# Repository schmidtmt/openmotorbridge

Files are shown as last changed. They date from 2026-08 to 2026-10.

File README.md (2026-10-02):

# OpenMotorBridge (v8.0) - Universal Motorcycle Intercom & Telemetry Bridge

<p align="center">
  OpenMotorBridge Logo
  &nbsp;&nbsp;&nbsp;&nbsp;&nbsp;&nbsp;&nbsp;&nbsp;
  OpenMotorMesh Logo
</p>

<p align="center">
  
  
  
  
  
</p>

**OpenMotorBridge (OMB)** is an open-source, cross-vendor communication and telemetry bridge for motorcycles. It seamlessly interconnects proprietary wireless intercom systems (**Sena Mesh 3.0** and **Cardo DMC Gen2**) with an open **2.4 GHz / 868 MHz OpenMotorMesh (OMM)**, high-precision **GNSS Tour Logging (Automotive Dead Reckoning)**, and a **wireless WebBLE PWA cockpit dashboard**.

---

## 📚 Technical Documentation

The comprehensive technical specification is split into 18 logically organized chapters:

1. [**01 - System Architecture & Satellite Topology**](docs/en/01_system_architecture.md)  
   *The 5 standardized functional nodes, de-sensing philosophy, RF diversity, whitepaper engineering decisions, and cockpit integration.*

2. [**02 - Intercom Matrix, Hardware Profiles & Routing**](docs/en/02_intercom_matrix_profiles.md)  
   *The 5 OEM adapter classes A-E, LittleFS profile engine, zero-latency PTT (< 1.8 ms), and audio cross-matrix.*

3. [**03 - Audio DSP, Acoustics & Knowles MEMS Wind Tracking**](docs/en/03_audio_dsp_acoustics.md)  
   *1500V Bourns isolation, ES8388 Codec, Knowles MEMS acoustic wind sampling, and Raised-Cosine Ducking.*

4. [**04 - Mesh Network, LoRa & GNSS Navigation**](docs/en/04_mesh_lora_navigation.md)  
   *OpenMotorMesh (OMM), Dynamic Leader Election (DLE), 868 MHz LoRa fallback, and 10 Hz Multi-GNSS.*

5. [**05 - Power Management, UPS Battery & Power Gate**](docs/en/05_power_management_ups.md)  
   *LM5164-Q1 72V buck, BQ24075 UPS, Front Node LMR36015 / TPS2051B power gate & 1-click CarPlay hard reboot.*

6. [**06 - Telemetry Blackbox, SDIO Ringbuffer & WebDAV Sync**](docs/en/06_telemetry_blackbox_webdav.md)  
   *4-bit high-speed SDIO, GDPR/court-compliant ringbuffer, ECDSA SHA-256, and automated private cloud sync.*

7. [**07 - Hardware Architecture & Board Pinouts (All 8 PCBAs)**](docs/en/07_pcba_hardware_pinouts.md)  
   *All 8 circuit boards: layer stackup, controlled impedance, net classes, functional zoning, and pinout tables (PCBA 01 to 08 including ESP32-C5 V2X Radar Sub-MCU).*

8. [**08 - Mechanical Enclosures, CAD & Reference Mounting Kits**](docs/en/08_enclosures_mechanics_cad.md)  
   *Universal pods & cartridges, 4-in-1 Front Node, Radar 2.0 Winged Housing with Garmin Bayonet, Through-Fairing 15W Qi Cam Dock, Car Sun Visor Clip for convoys, and zero-drill side-wall MagSafe saddlebag integration.*

9. [**09 - Firmware Architecture, FreeRTOS & Rollback-OTA**](docs/en/09_firmware_architecture.md)  
   *Multi-core ESP32-S3 (Main & Front), Rear Co-Processor, ESP-NOW low-latency protocol (< 1.8 ms), and dual-bank rollback OTA.*

10. [**10 - WebApp PWA & Dashboard Operation**](docs/en/10_webapp_pwa_dashboard.md)  
    *Zero-cloud PWA web app, Web Bluetooth API (WebBLE), vehicle dynamics HUD, Front Node controls, Support-Van / Convoy profile modes, and 4-tier GPX export.*

11. [**11 - Smart-Managed CarPlay & Android Auto Bridge Architecture (PCBA 05)**](docs/en/11_carplay_android_auto_bridge_architecture.md)  
    *Harley Skyline OS / Boom! Box integration, CP2AA protocol bridge, Virtual WHIM bypass, source-gated handlebar controls & headless dongle management.*

12. [**12 - Vehicle CAN-Bus Profiles, DBC JSON Schema & Universal Telemetry Engine**](docs/en/12_can_bus_vehicle_profiles.md)  
    *Data-driven LittleFS profiles for Harley-Davidson, BMW Motorrad, KTM, and OBD2, passive listen-only protection, and EKF tunnel dead reckoning.*

13. [**13 - Digital Simulation & Multi-Physics Master Testbench**](docs/en/13_simulation_testbench.md)  
    *9 modular Python testbenches and 10 HIL scenarios verifying SPICE, thermal, transients, RF, and acoustics.*

14. [**14 - EMC Hardening, RF Shielding & Environmental Protection**](docs/en/14_emv_rf_hardening.md)  
    *Automotive transient immunity (ISO 7637-2), 2.4 GHz vs 868 MHz isolation, IPC-CC-830B coating, and shock damping.*

15. [**15 - Bill of Materials (BOM) & SMT Manufacturing (All 8 PCBAs)**](docs/en/15_bom_manufacturing.md)  
    *Complete 8-board BOM for JLCPCB SMT production, ordering checklist, wiring harness pigtail, and COTS items.*

16. [**16 - Build Instructions, Wiring & Vehicle Installation**](docs/en/16_build_instructions_assembly.md)  
    *Step-by-step assembly guide, 3D printing parameters (FDM vs. MJF), Front Node mounting, Harley side-wall pass-through (puddle-proof floor), Support-Van visor mounting, Smart-Keyfob build, and commissioning.*

17. [**17 - Automotive Standards & Technical References**](docs/en/17_standards_references.md)  
    *Index for ISO 7637-2, ISO 16750, ECE R10, RED 2014/53/EU, IEC 61672-1 Class 1, and Bluetooth SIG.*

18. [**18 - Legal Compliance, Privacy (GDPR) & Licensing**](docs/en/18_legal_compliance_dsgvo.md)  
    *Open-source licenses (GPL-3.0, CERN-OHL-S v2, CC BY-SA 4.0), GDPR compliance, and liability disclaimer.*

---

## 🛠️ Repository Layout

* **`docs/de/`**: Complete technical specifications in German.
* **`docs/en/`**: Complete technical specifications in English.
* **`firmware/main_controller/`**: ESP-IDF / C++ source code for the central main box (ESP32-S3, PCBA 01).
* **`firmware/front_node/`**: ESP-IDF / C++ source code for the Universal Front Node (ESP32-S3, PCBA 05).
* **`firmware/smart_cartridge/`**: ESP-IDF / C++ source code for Smart Cartridges Bay 1 & 2 (ESP32-C6, PCBA 03).
* **`firmware/radar_submcu/`**: ESP-IDF / C++ source code for Heck-Radar 2.0 Sub-MCU & Wings (ESP32-C5/C6, PCBA 08).
* **`webapp_pwa/`**: Zero-cloud offline WebBLE dashboard (HTML5, Vanilla JS, CSS3, Service Worker, i18n).
* **`hardware/`**: KiCad schematics, Gerber files, and 3D enclosure CAD models.
* **`tools/audio_testbench/`**: **Interactive Live Audio DSP Studio & Real-Time Testbench** (`python3 tools/audio_testbench/server.py` $\rightarrow$ Web Audio testbench with live mic, Spacebar PTT, speedometer & ducking).
* **`tools/simulators/`**: 9 modular Python simulation testbenches (`python3 tools/run_all_simulations.py`).

---

## 📜 Licenses

* **Hardware & PCB Layouts:** [CERN-OHL-S v2](https://ohwr.org/project/cernohl/wikis/Documents/CERN-OHL-version-2) (Strongly Reciprocal)
* **Firmware & Web Dashboard:** [GNU General Public License v3.0 (GPL-3.0)](https://www.gnu.org/licenses/gpl-3.0.html)
* **Documentation & 3D Models:** [Creative Commons Attribution-ShareAlike 4.0 International (CC BY-SA 4.0)](https://creativecommons.org/licenses/by-sa/4.0/)

---

## ⚠️ Liability Disclaimer

All information, schematics, board layouts, 3D printing files, and software published in this project are provided free of charge on an "AS IS" basis. Assembly, installation, and operation occur entirely at the user's own risk. All mentioned brand names (Harley-Davidson®, BMW®, Garmin®, Sena®, Cardo®, Apple CarPlay®) are registered trademarks of their respective owners.

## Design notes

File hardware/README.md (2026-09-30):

# OpenMotorBridge v8.5 / v9.0 - KiCad Hardware-Baukasten (Clean All-UWB Architecture)

Dieses Verzeichnis enthält die vollständigen **KiCad 10 Schaltplan-, PCB- und Produktionsdateien** für die drahtlose **All-UWB & Pure-DC Architektur** von OpenMotorBridge.

---

## 📂 Das bereinigte 6-Platinen-Lineup

Durch den konsequenten Einsatz von Ultra-Wideband (Qorvo DW3110 6.5 GHz Ch. 5, $< 0{,}4\,\text{ms}$) und Bluetooth entfällt jegliche Signal- und NF-Audioverdrahtung über den Rahmen. Der Kabelbaum besteht ausschließlich aus robusten **2-Draht-DC-Power-Peitschen** (+5V/GND bzw. +12V/GND). 

Die Pod-Platine (`PCBA 02`) und der Heck-Pod (`PCBA 04`) sind ersatzlos entfallen - der Baukasten besteht aus **exakt 6 aktiven PCBAs**:

| PCBA | Baugruppe & Funktion | Maße / Lagen | Kern-Komponenten / RF |
| :--- | :--- | :--- | :--- |
| **PCBA 01** | **Zentralbox Main Controller**<br>*(Unter Sitzbank, Audio-DSP, USV)* | 85 x 55 mm<br>4 Lagen (ENIG) | ESP32-S3, ES8388 24-Bit Codec, TCAN334G CAN-FD, LM5164-Q1, SX1262 LoRa (Top), DW3110 UWB (Bottom), SW1 Taster |
| **PCBA 03** | **Universal Smart Cartridge Rev 3.0**<br>*(Autarker UWB-Funkschlitten)* | 35 x 25 mm<br>2 Lagen (ENIG, 2-seitig SMT) | Qorvo DW3110 UWB, SPI Host-MCU, 4x AO3400A MOSFETs, 2P Frontkontakt (+5V/GND), DNP-Codec |
| **PCBA 05** | **Universal Front-Knoten**<br>*(Cockpit Hub, Sensorik, Audio, USB-PD)* | 82 x 50 mm<br>4 Lagen (ENIG) | ESP32-S3, DW3110 UWB, SAM-M10Q, USB2514B Hub, Dual SW3526 PD20W, Qi 12V, BSD LEDs |
| **PCBA 06** | **MagSafe Frame Dock Adapter**<br>*(Rahmendock M8 auf 2-Pin MagSafe)* | 28 x 11.5 mm<br>2 Lagen (1 oz) | 2 Pogo-Pins (+5V / GND), TVS Diode, 16V PPTC Polyfuse |
| **PCBA 07** | **2-in-1 LoRa Smart-Keyfob & Pager**<br>*(Taschen-Pager, N52 Key & Qi)* | 38 x 19 mm<br>2 Lagen (ENIG) | Nordic nRF52840 SoC, Semtech SX1262 LoRa, DRV2605L Haptik, BQ51003 Qi RX |
| **PCBA 08** | **Radar 2.0 Sub-MCU & Wings**<br>*(Wheeltec 77GHz MR20 + Halo LED)* | 115 x 65 mm<br>2 Lagen (ENIG) | ESP32 Sub-MCU (UWB DW3110), 36x WS2812B LEDs, 2-Pin 12V Power |

---

## 🔌 Zentraler Bordnetz-Stecker (Deutsch DTM-12 Automotive)

Die Zentralbox nutzt einen robusten, wasserdichten **Deutsch DTM-12 Industriestecker** (11 aktive Kontakte):

| Pin | Signalname | Funktion | Querschnitt / Ziel |
| :---: | :--- | :--- | :--- |
| **1** | `KL30_IN` | 12V Dauerplus | AWG20 (0.50 mm²) / Bordnetz |
| **2** | `KL15_IGN` | 12V Zündungsplus | AWG22 (0.34 mm²) / Zündung |
| **3** | `VEHICLE_GND`| Hauptmasse (KL31) | AWG20 (0.50 mm²) / Rahmen |
| **4** | `CAN_H` | Fahrzeug-CAN High | AWG24 (0.22 mm²) / Twisted Pair |
| **5** | `CAN_L` | Fahrzeug-CAN Low | AWG24 (0.22 mm²) / Twisted Pair |
| **6** | `POD1_VCC` | 5V Switched Power Bucht 1 (Links) | AWG22 (0.34 mm²) / JWPF 2P |
| **7** | `POD1_GND` | Masse Bucht 1 (Links) | AWG22 (0.34 mm²) / JWPF 2P |
| **8** | `POD2_VCC` | 5V Switched Power Bucht 2 (Rechts) | AWG22 (0.34 mm²) / JWPF 2P |
| **9** | `POD2_GND` | Masse Bucht 2 (Rechts) | AWG22 (0.34 mm²) / JWPF 2P |
| **10**| `RADAR_PWR` | 12V Switched Power Radar Heck | AWG22 (0.34 mm²) / JWPF 2P |
| **11**| `RADAR_GND` | Masse Radar | AWG22 (0.34 mm²) / JWPF 2P |
| **12**| `CHASSIS_EARTH` | Gehäuseschirm / Rahmenerde | AWG20 (0.50 mm²) |

---

## 🛠️ Fertigung & Validierung (JLCPCB / Eurocircuits)

* **Produktionspakete generieren:**
  ```bash
  python3 hardware/scripts/export_manufacturing_packages.py
  ```
* **JLCPCB DFM & Netlist-Verifikation:**
  ```bash
  /Applications/KiCad/KiCad.app/Contents/Frameworks/Python.framework/Versions/3.9/bin/python3 hardware/scripts/verify_pcb_designs_jlcpcb.py
  ```

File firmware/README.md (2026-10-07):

# OpenMotorBridge - Firmware Developer & Build Guide (ESP-IDF v5.2 / v5.3)

Dieses Dokument ist die verbindliche Schritt-für-Schritt-Anleitung für Software-Entwickler und Nachbauer zum Einrichten der Build-Umgebung, Kompilieren, Partitionieren und Flashen der drei Firmware-Ziele von OpenMotorBridge.

---

## 1. Übersicht der Firmware-Ziele (Targets)

Das OpenMotorBridge-Gesamtsystem verteilt die Aufgaben auf drei dedizierte Mikrocontroller-Baugruppen:

```
+---------------------------------------------------------------------------------------------------+
| OPENMOTORBRIDGE FIRMWARE TARGET MATRIX                                                            |
+-------------------+---------+-----------------------+-------------+-------------------------------+
| Target-Verzeichnis| MCU     | Hardware-Baugruppe    | Takt / RAM  | Hauptaufgaben                 |
+-------------------+---------+-----------------------+-------------+-------------------------------+
| `main_controller` | ESP32-S3| Zentralbox (PCBA 01)  | 240 MHz     | * Audio-DSP Matrix & EKF      |
|                   | N16R8   | Batteriefach          | 8 MB OPI RAM| * CAN-Bus & Fahrzeugprofile   |
|                   |         |                       | 16 MB Flash | * UWB Backbone Hub & LoRa SX  |
+-------------------+---------+-----------------------+-------------+-------------------------------+
| `front_node`      | ESP32-S3| Front-Knoten (PCBA 05)| 240 MHz     | * GNSS SAM-M10Q & Sensorik    |
|                   | N16R8   | Cockpit / Verkleidung | 8 MB OPI RAM| * Knowles I2S Wind-AGC        |
|                   |         |                       | 16 MB Flash | * USB-PD / Ottocast Steuerung |
+-------------------+---------+-----------------------+-------------+-------------------------------+
| `smart_cartridge` | ESP32-C6| Smart Cartridge (03)  | 160 MHz     | * 4x AO3400A Mechatronik Gate |
|                   | RISC-V  | Bucht 1 & Bucht 2     | 512 KB SRAM | * ES8388 I2S Codec Streaming  |
|                   |         |                       | 4 MB Flash  | * All-UWB Backbone Node       |
+-------------------+---------+-----------------------+-------------+-------------------------------+
| `radar_submcu`    | ESP32-C5| Heck-Radar (PCBA 08)  | 160 MHz     | * Wheeltec MR20 mmWave Parser |
|                   | / C6    | Kennzeichenträger     | 512 KB SRAM | * 36x Halo RGB LED Animation  |
|                   |         |                       | 4 MB Flash  | * UWB Ziel-Telemetrie Stream  |
+-------------------+---------+-----------------------+-------------+-------------------------------+
| `omm_module`      | ESP32-C6| OMM 2.4 GHz (PCBA 09) | 160 MHz     | * ESP-NOW Mesh Intercom       |
|                   | RISC-V  | Helm / UCS Cartridge  | 512 KB SRAM | * Opus / ES8388 48 kHz Audio  |
|                   |         |                       | 4 MB Flash  | * BLE CarPlay & Keypad State  |
+-------------------+---------+-----------------------+-------------+-------------------------------+
| `omm446_module`   | ESP32-C6| OMM 446 MHz (PCBA 10) | 160 MHz     | * NiceRF SA818-DMR UART/DSP   |
|                   | RISC-V  | PMR446 / DMR Tier I/II| 512 KB SRAM | * ES8388 16 kHz Voice Stream  |
|                   |         | Helm / UCS Cartridge  | 4 MB Flash  | * 0.2W/0.5W ERP & CTCSS Engine|
+-------------------+---------+-----------------------+-------------+-------------------------------+
```

---

## 2. Voraussetzungen & Toolchain-Installation

### 2.1 Systemanforderungen
* **Betriebssystem:** Linux (Ubuntu 22.04 / 24.04), macOS (Apple Silicon / Intel) oder Windows 11 (WSL2 empfohlen).
* **Python:** Python 3.10 oder neuer mit `pip` und `virtualenv`.
* **Build-Tools:** CMake >= 3.16, Ninja-Build, Git.

### 2.2 ESP-IDF v5.2 / v5.3 installieren

```bash
# 1. Arbeitsverzeichnis für ESP-IDF anlegen
mkdir -p ~/esp && cd ~/esp

# 2. ESP-IDF Repository klonen (Release v5.2 oder v5.3 LTS)
git clone -b v5.2.2 --recursive https://github.com/espressif/esp-idf.git esp-idf-v5.2

# 3. Toolchains für ESP32-S3 und ESP32-C6 / ESP32-C5 installieren
cd ~/esp/esp-idf-v5.2
./install.sh esp32s3,esp32c6,esp32c5

# 4. Umgebungsvariablen in die aktuelle Shell laden
. ./export.sh
```

> [!TIP]
> Um ESP-IDF dauerhaft bequem verfügbar zu machen, empfiehlt sich ein Alias in `~/.zshrc` oder `~/.bashrc`:
> ```bash
> alias get_idf='. $HOME/esp/esp-idf-v5.2/export.sh'
> ```

---

## 3. Kompilieren der 3 Targets

Klonen Sie das OpenMotorBridge-Repository oder wechseln Sie in das Hauptverzeichnis:

```bash
cd /path/to/openMotorBridge/firmware
```

### 3.1 Target 1: Hauptcontroller (`main_controller`)

```bash
cd main_controller

# Ziel-Architektur festlegen
idf.py set-target esp32s3

# (Optional) Menü-Konfiguration inspizieren
idf.py menuconfig

# Kompilieren
idf.py build
```

Das erzeugt:
* `build/bootloader/bootloader.bin`
* `build/partition_table/partition-table.bin`
* `build/openmotorbridge_main.bin`

### 3.2 Target 2: Front-Knoten (`front_node`)

```bash
cd ../front_node

# Ziel-Architektur festlegen
idf.py set-target esp32s3

# Kompilieren
idf.py build
```

Das erzeugt:
* `build/bootloader/bootloader.bin`
* `build/partition_table/partition-table.bin`
* `build/openmotorbridge_front_node.bin`

### 3.3 Target 3: Smart Cartridge (`smart_cartridge`)

```bash
cd ../smart_cartridge

# Ziel-Architektur festlegen (ESP32-C6 RISC-V)
idf.py set-target esp32c6

# Kompilieren
idf.py build
```

Das erzeugt:
* `build/openmotorbridge_smart_cartridge.bin`

### 3.4 Target 4: Radar Sub-MCU (`radar_submcu`)

```bash
cd ../radar_submcu

# Ziel-Architektur festlegen (ESP32-C6 oder ESP32-C5)
idf.py set-target esp32c6

# Kompilieren
idf.py build
```

Das erzeugt:
* `build/openmotorbridge_radar2_submcu.bin`

### 3.5 Target 5: OMM 2.4 GHz Intercom-Modul (`omm_module`)

```bash
cd ../omm_module

# Ziel-Architektur festlegen (ESP32-C6 RISC-V)
idf.py set-target esp32c6

# Kompilieren
idf.py build
```

Das erzeugt:
* `build/openmotorbridge_omm_module.bin`

### 3.6 Target 6: OMM 446 MHz PMR/DMR Transceiver (`omm446_module`)

```bash
cd ../omm446_module

# Ziel-Architektur festlegen (ESP32-C6 RISC-V)
idf.py set-target esp32c6

# Kompilieren
idf.py build
```

Das erzeugt:
* `build/openmotorbridge_omm446_module.bin`

---

## 4. Partition Table & Storage-Architektur

Alle Targets nutzen eine fehlertolerante Dual-Bank A/B OTA-Partitionierung mit automatischem Rollback-Schutz.

### 4.1 Partitions-Layout (`partitions.csv`)

```csv
# Name,   Type, SubType, Offset,   Size,     Flags
nvs,      data, nvs,     0x9000,   0x4000,
otadata,  data, ota,     0xd000,   0x2000,
phy_init, data, phy,     0xf000,   0x1000,
ota_0,    app,  ota_0,   0x10000,  0x300000,
ota_1,    app,  ota_1,   0x310000, 0x300000,
storage,  data, spiffs,  0x610000, 0x1E0000,
```

* **`nvs` (16 KB):** Speichert kryptografische Schlüssel (AES-128-GCM Gruppen-Session-Keys), Kalibrierdaten der IMU und das zuletzt aktive CAN-Fahrzeugprofil.
* **`otadata` (8 KB):** Verwaltet die aktive Boot-Partition und Rollback-Zähler (anti-bricking).
* **`ota_0` / `ota_1` (je 3 MB):** Dual-Bank Firmware-Partitionen. Updates werden in die inaktive Bank geflasht; bootet diese nicht erfolgreich innerhalb von 30 s, schlägt der Bootloader automatisch auf die vorherige Version zurück.
* **`storage` (LittleFS / SPIFFS):** Enthält CAN-Bus DBC/JSON-Fahrzeugprofile (`/can_profiles/bmw_k24.json`, `/can_profiles/harley_hdcan.json`) sowie Offline-Assets des PWA-Dashboards.

### 4.2 Dateisystem-Image erstellen und flashen

```bash
# LittleFS / SPIFFS Partition für Fahrzeugprofile erzeugen und flashen:
esptool.py --chip esp32s3 -p /dev/tty.usbmodem* write_flash 0x610000 data_image.bin
```

---

## 5. Flashen & Serieller Monitor

### 5.1 Direktes Flashen via USB-C

1. Verbinden Sie den USB-C Service-Port der Baugruppe mit dem PC.
2. Identifizieren Sie den seriellen Port:
   * **macOS:** `/dev/tty.usbmodem*`
   * **Linux:** `/dev/ttyACM0` oder `/dev/ttyUSB0`
   * **Windows:** `COM3`, `COM4`, etc.

```bash
# Flash und automatischer Start des seriellen Monitors
idf.py -p /dev/tty.usbmodem1101 flash monitor
```

### 5.2 Manuelles Bootstrapping (Bootloader-Recovery)
Sollte ein Modul nicht automatisch in den Bootloader wechseln:
1. Taste `BOOT` (oder `SW_PAIR_RESET`) gedrückt halten.
2. Taste `RESET` kurz drücken (oder Versorgungsspannung kurz trennen).
3. Taste `BOOT` loslassen.
4. Das Modul meldet sich im ROM-Bootloader-Modus (`waiting for download`).

### 5.3 Monitor beenden & Filter
* **Monitor beenden:** Tastenkombination `Ctrl + ]`.
* **Logging-Level zur Laufzeit filtern:**
  ```bash
  idf.py monitor --print-filter="*:I UWB:D CAN:D"
  ```

---

## 6. Häufige Fehler & Troubleshooting

1. **`PSRAM not detected` / Boot-Loop:**
   * Ursache: Falscher Octal-/Quad-SPI Modus in `sdkconfig`.
   * Lösung: `CONFIG_SPIRAM_MODE_OCT=y` für WROOM-1-N16R8 sicherstellen.
2. **`Flash size mismatch` (16 MB vs. 4 MB / 8 MB):**
   * Lösung: In `idf.py menuconfig` unter `Serial flasher config` -> `Flash size` exakt auf `16 MB` stellen.
3. **UWB SPI Transceiver Timeout:**
   * Prüfen, ob der SPI-Bus auf 20 MHz konfiguriert ist und der DW3110 Interrupt-Pin (`DW_IRQ`) GPIO-Konflikte aufweist.

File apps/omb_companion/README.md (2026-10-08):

# OpenMotorBridge Companion App (`bar.f0o.omb`)

Offizielle plattformübergreifende Begleit-App für das OpenMotorBridge Motorrad-Ökosystem, entwickelt mit **Flutter (Dart)** und nativen **Android-Plattform-Services (Kotlin)**.

---

## 🚀 Kernfunktionen

### 1. In-App OTA Self-Updater (Homesphere-Prinzip)
* **Keine Wartezeiten im Google Play Store:** Aktualisiert sich direkt in der App.
* **Flexible Update-Quellen:**
  * **Lokaler Homeserver:** URL zu `version.json` oder direktem APK-Link (z. B. `http://192.168.1.100:8080/omb-update.apk`).
  * **GitHub Releases:** Automatischer Abruf des neuesten APKs aus den Releases von `schmidtmt/openmotorbridge`.
* **Download-Fortschritt & 1-Klick Installation:** Lädt die APK in den App-Cache und startet über Androids `FileProvider` (`ACTION_VIEW`) den nativen Installationsdialog.

### 2. Layer-5 SOCKS5 & HTTP Mobilfunk-Proxy (`TRANSPORT_CELLULAR`)
* **Zero Wi-Fi Konflikt:** Bypasst das 5 GHz WLAN des Smartphones, das exklusiv durch Wireless CarPlay / Android Auto belegt ist.
* **Zero VPN Konflikt:** Läuft rein im User-Space als L5-Stream-Relay auf `127.0.0.1:8080` und belegt **keinen** Android `VpnService`-Slot. Dauerhaft aktive VPNs wie **Tailscale** oder WireGuard (für Home Assistant / Homesphere) bleiben 100 % ungestört parallel aktiv!
* **Automatisches Mobilfunk-Binding:** Nutzt Androids `ConnectivityManager.requestNetwork()` mit `TRANSPORT_CELLULAR`, um alle ausgehenden Proxy-Sockets fest an 4G/5G zu binden.

### 3. Cross-Platform BLE-Brücke (Native CoreBluetooth auf iOS)
* Basiert auf `flutter_blue_plus` und spricht auf iOS direkt mit Apples nativem `CoreBluetooth` C-Stack (keine WebBLE-/Bluefy-Einschränkungen!).
* Automatischer Reconnect zum ESP32-S3 (`OMB-CENTRAL-*`).
* Live-Telemetrie im Glassmorphism Dashboard: Bordnetzspannung, IMU-Schräglage, Zündungsstatus (KL15) und 77-GHz-Heckradar-Warnungen.

### 4. u-blox AssistNow Online A-GPS Injection
* Lädt beim Start der Zündung ein kompaktes MGA-Ephemeridenpaket (~3–8 kB) über die Mobilfunkverbindung herunter.
* Speist die Binärframes via BLE in den SAM-M10Q GNSS-Chip auf Front-Node PCBA 05 ein.
* **Ergebnis:** Kaltstart-TTFF sinkt von ~30 s auf unter **1.5 Sekunden** (Instant-3D-Fix)!

### 5. Nativer Smart Firmware & Node-OTA Hub
* **Keine WebBLE-Abbrüche:** Im Gegensatz zur PWA kein Verbindungsabriss bei gesperrtem Bildschirm oder Ruhezustand (Foreground-Service mit WakeLock).
* **Multi-Node Unterstützung:**
  * **Central Controller (ESP32-S3):** `openmotorbridge_central.bin`
  * **OMM UCS Intercom (PCBA 09 / ESP32-C3):** High-Speed UART Push (460.800 Baud SLIP)
  * **Front-Node Cockpit (PCBA 05):** ESP-NOW & Ottocast Flasher
  * **Radar Sub-MCU (PCBA 02):** 77 GHz Transceiver-Coprozessor
* **Offline-Caching für die Garage:** Binärdateien können vorab im heimischen WLAN auf das Smartphone geladen werden – das Motorrad kann draußen in der Tiefgarage völlig offline geflasht werden.
* **Eigene Test-Firmware:** Beliebige `.bin`-Dateien können direkt über den nativen Dateimanager ausgewählt und geflasht werden.
* **Live-Diagnoselog:** Scrollbare Terminalkonsole mit detailliertem Übertragungsprotokoll und Fehlerüberwachung.

---

## 🛠️ Entwicklung & Build

### App lokal starten
```bash
cd apps/omb_companion
flutter run
```

### Automatisiertes Build- & Deployment-Skript (Homesphere-Pattern)

Vor jedem Build wird automatisch die Versionsnummer und der Build-Code in `pubspec.yaml` erhöht, das Release-APK gebaut, die Metadaten (`version.json`, `apps.json`) generiert und auf alle konfigurierten Ziele (lokales Staging, Google Drive, Homeserver/Pi) verteilt:

```bash
# Aus dem Repository-Root:
./tools/build_and_deploy_companion.sh

# Oder aus apps/omb_companion/:
./scripts/build_and_deploy.sh
```

#### Nützliche CLI-Optionen:
* `--no-bump` – Behält die aktuelle Version bei ohne sie zu erhöhen.
* `--patch` – Erhöht explizit den SemVer-Patch (z. B. `1.0.1` ➔ `1.0.2`).
* `--minor` – Erhöht die Minor-Version (z. B. `1.0.x` ➔ `1.1.0`).
* `--major` – Erhöht die Major-Version (z. B. `1.x.x` ➔ `2.0.0`).
* `--ios` – Kompiliert zusätzlich auf macOS die iOS-App und schnürt eine unsignierte IPA für SideStore / AltStore.
* `--remote` – Erzwingt den SCP-Upload auf den lokalen Server / Raspberry Pi (`homesphere.f0o.bar`).
* `--tag` – Erstellt automatisch ein signiertes Git-Release-Tag `vX.Y.Z-B` und pusht es zu GitHub.

#### Bereitstellungs-Ziele (Automatisch erkannt):
1. **Lokales Staging (`apps/omb_companion/dist/`):**
   * `openmotorbridge-release.apk` & `openmotorbridge-X.Y.Z-B.apk`
   * `version.json` (für In-App OTA Self-Update)
   * `apps.json` (für SideStore / AltStore)
   * `logo.jpg`
2. **Google Drive Sync:**
   * Wird automatisch in `/Meine Ablage/OpenMotorBridge/app/` abgelegt, sofern Google Drive auf dem Mac eingebunden ist.
3. **Lokaler Homeserver / Raspberry Pi:**
   * Übertragung per `scp` auf `homesphere.f0o.bar` nach `/home/schmidtm/homesphere/api-service/data/static/` für sofortige Verfügbarkeit im lokalen Netzwerk.

### Eigene Update-Konfiguration (`version.json` auf deinem lokalen Server)
```json
{
  "version": "1.0.1",
  "url": "http://192.168.1.100:8080/app-release.apk",
  "notes": "Neu: Optimierte SOCKS5-Verbindungsüberwachung und Radar-Alarmfilter."
}
```
In der App unter **Self-Update** einfach `http://192.168.1.100:8080/version.json` eintragen – die App erkennt neue Versionen sofort und installiert sie per Fingertipp!

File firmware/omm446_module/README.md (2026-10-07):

# OpenMotorMesh (OMM) 446 MHz PMR/DMR Transceiver Module Firmware

Dieses Verzeichnis enthält die native ESP-IDF C++ Firmware für das **OMM 446 MHz Analog & Digital PMR/DMR Transceiver Modul (`PCBA 10`)**.

---

## 1. Systemübersicht & Hardware-Architektur

* **Host-MCU:** Espressif ESP32-C6-MINI-1U (RISC-V 32-Bit @ 160 MHz)
* **Funk-Transceiver:** NiceRF SA818-DMR (CMX7141 DSP + 0.2W/0.5W PA)
* **Audio-Codec:** Everest Semi ES8388 (24-Bit / 16 kHz Schmalband-optimiert)
* **Lade- & Power-Management:** Texas Instruments BQ24075 PMIC
* **Formfaktor:** ECE 22.06 UCS ($60{,}0 \times 30{,}0 \times 1{,}0\,\text{mm}$ PCBA)

---

## 2. Vollständiges Hardware-Pinout (`PCBA 10`)

| GPIO / Pin | Signalname | Richtung | Funktion |
| :---: | :--- | :---: | :--- |
| **`GPIO 2`** | `BTN_PTT` | Input | SW1: Push-To-Talk / MFB (Low-aktiv) |
| **`GPIO 3`** | `BTN_MODE` | Input | SW2: Mode Switch (Analog PMR446 <-> Digital DMR Tier I) |
| **`GPIO 4`** | `BTN_CH_UP` | Input | SW3: Kanalwahl Aufwärts (CH 1–16) |
| **`GPIO 5`** | `BTN_CH_DOWN` | Input | SW4: Kanalwahl Abwärts (CH 16–1) |
| **`GPIO 6`** | `WS2812_DATA` | Output | D1: WS2812B-2020 RGB Statusanzeige |
| **`GPIO 7`** | `CHG_STAT` | Input | BQ24075 /STAT Ladeanzeige |
| **`GPIO 8`** | `I2C_SDA` | I/O | ES8388 Audio-Codec I2C Control SDA |
| **`GPIO 9`** | `I2C_SCL` | Output | ES8388 Audio-Codec I2C Control SCL |
| **`GPIO 12`** | `USB_DN` | I/O | USB-C D- Datenleitung (DFU Flashing) |
| **`GPIO 13`** | `USB_DP` | I/O | USB-C D+ Datenleitung (DFU Flashing) |
| **`GPIO 14`** | `SA818_TXD` | Output | UART TX -> SA818 RXD (AT-Befehle, 9600 Baud) |
| **`GPIO 15`** | `SA818_RXD` | Input | UART RX <- SA818 TXD (Telemetrie/Status) |
| **`GPIO 16`** | `SA818_PTT` | Output | SA818 Sende-Aktivierung (**Low = Senden**, High = Empfang) |
| **`GPIO 17`** | `SA818_SQL` | Input | SA818 Rauschsperren-Status (**Low = Träger erkannt**) |
| **`GPIO 18`** | `SA818_PWR_HL` | Output | SA818 Power Umschaltung (**Low = 0.2W Helm**, High = 0.5W Bike) |
| **`GPIO 19`** | `I2S_MCLK` | Output | ES8388 Master Clock |
| **`GPIO 20`** | `I2S_BCLK` | Output | ES8388 Bit Clock |
| **`GPIO 21`** | `I2S_WS` | Output | ES8388 Word Select |
| **`GPIO 22`** | `I2S_DOUT` | Output | ES8388 DAC Audio Stream (Sprachausgabe) |
| **`GPIO 23`** | `I2S_DIN` | Input | ES8388 ADC Audio Stream (Mikrofonaufnahme) |

---

## 3. Betriebsmodi & LED-Farbkodierung

| Zustand | LED-Modus | Farbe / Animation | Bedeutung |
| :--- | :--- | :--- | :--- |
| **Analog Standby** | `LED_MODE_RX_STANDBY_ANALOG` | Grün atmend | Analog PMR446 aktiv, Rauschsperre geschlossen |
| **Digital Standby** | `LED_MODE_RX_STANDBY_DMR` | Cyan atmend | Digital DMR Tier I aktiv, Standby |
| **Analog RX** | `LED_MODE_RX_ACTIVE_ANALOG` | Grün dauerhaft | Funkspruch auf analogem Kanal wird empfangen |
| **Digital RX** | `LED_MODE_RX_ACTIVE_DMR` | Cyan dauerhaft | Glasklarer digitaler DMR-Sprachstrom aktiv |
| **Analog TX** | `LED_MODE_TX_ANALOG` | Rot dauerhaft | Sendet analog mit PTT |
| **Digital TX** | `LED_MODE_TX_DMR` | Blau dauerhaft | Sendet DMR 4FSK digital mit PTT |
| **Kanalwechsel** | `LED_MODE_CHANNEL_CHANGE` | Bernstein aufblitzend | Neuer Kanal eingestellt |
| **Moduswechsel** | `LED_MODE_MODE_SWITCH` | Lila aufblitzend | Wechsel zwischen Analog und Digital |
| **Akku schwach** | `LED_MODE_BATTERY_LOW` | Rot blinkend schnell | Akkuspannung $< 3{,}4\,\text{V}$ |

---

## 4. BLE GATT Fernsteuerung (Cockpit / CarPlay / PWA Dashboard)

* **Service UUID:** `0xFE46` (`OMM-446-Radio`)
* **Char `0x0001` (PTT):** `1` = Senden starten, `0` = Senden beenden.
* **Char `0x0002` (Mode):** `0` = Analog PMR446, `1` = Digital DMR Tier I.
* **Char `0x0003` (Channel):** Kanal `1` bis `16`.
* **Char `0x0004` (CTCSS):** Subton-Index `0` bis `38`.
* **Char `0x0005` (Color Code):** DMR Color Code `1` bis `16`.
* **Char `0x0006` (Squelch):** Rauschsperren-Empfindlichkeit `1` bis `8`.
* **Char `0x0007` (Power):** `0` = 0.2W (Helm), `1` = 0.5W (Bike).
* **Char `0x0008` (Telemetrie):** Akkustand, S-Meter (RSSI in dBm), RX/TX Status.

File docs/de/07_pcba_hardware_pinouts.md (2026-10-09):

# 07 - Hardware-Architektur & Platinen-Pinouts (Das bereinigte 7-PCBA-Lineup)

Dieses Dokument bildet die **zentrale, autoritative Hardware-Spezifikation aller 7 aktiven Platinen-Baugruppen (`PCBA 01`, `03`, `05`, `07`, `08`, `09`, `10`)** des OpenMotorBridge Gesamtsystems (v9.6 Clean All-UWB Architecture), einschließlich Lagenaufbau, Impedanzkontrolle, Net-Klassen, Funktionszonen und vollständigen Pinout-Tabellen.

---

## 1. Systemübersicht des 5-Platinen-Lineups

Das Hardwaredesign von OpenMotorBridge folgt dem Grundsatz der radikalen Entflechtung: Daten- und Audioströme werden zu 100 % drahtlos über ein synchrones Ultra-Wideband-Backbone (UWB 6.5 GHz) geführt, während der fahrzeuggebundene Kabelbaum auf reine 2-Draht-Gleichspannung (12V DC) und CAN-Bus reduziert ist.

```
+----------------------------------------------------------------------------------------+
|                   DAS 7-PLATINEN-LINEUP DER OPENMOTORBRIDGE v9.6                       |
+-------+-------------------------------+---------------+---------+----------------------+
| Baugruppe | Name & Funktion           | Platinenmaße  | Lagen   | Kern-ICs / Bauteile  |
+-------+-------------------------------+---------------+---------+----------------------+
| **PCBA 01**| **Zentralbox Main Controller** | 85 x 55 mm    | 4 Lagen | ESP32-S3, QCC3084 BT,|
|       | (Unter der Sitzbank, Audio/USV)| (77x47 mm M3) | (ENIG)  | LM5164, BQ24075,     |
|       |                                |               |         | ES8388, SX1262 LoRa, |
|       |                                |               |         | DW3110 UWB, DTM-12   |
+-------+-------------------------------+---------------+---------+----------------------+
| **PCBA 03**| **Universal Smart Cartridge** | 35 x 25 mm    | 2 Lagen | Qorvo DW3110 UWB,    |
|       | (Kassettenträger Bucht 1 & 2) | (29x19 mm M2) | (ENIG)  | ESP32-C6, ES8388,    |
|       |                                | 2-seitig SMT  |         | 4x AO3400A, J_ACT    |
+-------+-------------------------------+---------------+---------+----------------------+
| **PCBA 05**| **Universal Front-Knoten**    | 82 x 50 mm    | 4 Lagen | ESP32-S3, DW3110 UWB,|
|       | (Cockpit, GNSS, Sensoren, UWB)| (4x M2.5)     | (ENIG)  | SAM-M10Q, USB2514B,  |
|       |                               |               |         | SC8102 PD20W, TPS2051|
+-------+-------------------------------+---------------+---------+----------------------+
| **PCBA 07**| **2-in-1 LoRa Smart-Keyfob**  | 38 x 19 mm    | 2 Lagen | Nordic nRF52840 SoC, |
|       | (Silent Pager, N52 Key & Qi)  | (Tasche M2)   | (ENIG)  | SX1262 LoRa, DRV2605L|
|       |                               |               |         | BQ51003 Qi, JST-ACH  |
+-------+-------------------------------+---------------+---------+----------------------+
| **PCBA 08**| **Radar 2.0 Sub-MCU & Wings** | 115 x 65 mm   | 2 Lagen | ESP32-C5, DW3110 UWB,|
|       | (Wheeltec 77GHz & V2X Patch)  | (Flügel M2.5) | (ENIG)  | Wheeltec MR20 (AoP),  |
|       |                               |               |         | 36x WS2812B, JWPF 12V |
+-------+-------------------------------+---------------+---------+----------------------+
| **PCBA 09**| **OMM 2.4 GHz UCS Intercom**  | 60 x 30 mm    | 2 Lagen | ESP32-C6 RISC-V,     |
|       | (ECE 22.06 Autonom & Pod)     | (UCS M2)      | (ENIG)  | TI BQ24075, ES8388,  |
|       |                               |               |         | 600mAh LiPo, FXP73   |
+-------+-------------------------------+---------------+---------+----------------------+
| **PCBA 10**| **OMM 446 MHz UCS Intercom**  | 60 x 30 mm    | 4 Lagen | NiceRF SA818-DMR,    |
|       | (DMR Tier I & Analog PMR446)  | (UCS M2)      | (ENIG)  | ESP32-C6, BQ24075,   |
|       |                               |               |         | ES8388, Helix-Antenne|
+-------+-------------------------------+---------------+---------+----------------------+
```

### 1.1 Gliederung nach Systemkomponenten
1. **Kern-Baugruppen (Standard-Ausstattung jedes Bikes):**
   * **`PCBA 01` (Zentralbox Main Controller):** Zentrale Recheneinheit unter der Sitzbank für Energie-Management, USV, DSP-Mischung, Dual-Bluetooth-Headsets, LoRa-Schwarm und UWB-Koordination.
   * **`PCBA 03` (Universal Smart Cartridge):** Universelle Trägerplatine für Bucht 1 und Bucht 2. Beherbergt wahlweise Sena SPIDER X Slim, Cardo Packtalk Edge, das OMM 2.4 GHz Modul (`PCBA 09`) oder das OMM 446 MHz Funkmodul (`PCBA 10`).
   * **`PCBA 05` (Universal Front-Knoten):** Cockpit-Einheit für Multi-GNSS (SAM-M10Q), Kaltluft-Sensorik, Ambient-Mikrofon, USB-Hub und Headless CarPlay/Android Auto Bridge.
2. **Empfohlene Erweiterungen & Peripherie:**
   * **`PCBA 07` (2-in-1 LoRa Smart-Keyfob & Silent Pager):** Tragbarer Schlüsselanhänger für 4,5 km Weitbereichs-Alarmierung, N52-Magnetschlüssel und induktive Qi-Ladung.
   * **`PCBA 08` (Radar 2.0 Sub-MCU & Warnflügel):** Heckmodul mit 77-GHz-mmWave-Sensorik (AoP), autonomem Brems- und Kollisionsstrobe sowie 5.9 GHz V2X-Uplink.
   * **`PCBA 09` (OMM 2.4 GHz Autonomes Intercom-Modul):** Quelloffenes, autarkes ECE 22.06 UCS-Intercom-Modul für den Helm und als High-Speed Mesh-Einsatz im Kassetten-Schlitten (`PCBA 03`).
   * **`PCBA 10` (OMM 446 MHz Autonomes Funkmodul):** Quelloffenes ECE 22.06 UCS-Funkmodul (Dual-Mode: Analog PMR446 + Digital DMR Tier I), voll kompatibel zu Midland G-Serie und D-10, mit Power-Path USV-Laden und 0.2W/0.5W Umschaltung.
3. **Ersatzlos entfallene Baugruppen (Architektur-Bereinigung v9.6):**
   * **`PCBA 02` (Pod-Basisplatine):** Ersatzlos gestrichen. Die Zuleitung führt direkt auf zwei vergoldete Federkontakte im Schachtboden.
   * **`PCBA 04` (Heck-Pod 3):** Ersatzlos gestrichen. Heck-Pod 3 entfällt vollständig; LoRa sitzt auf `PCBA 01`, GNSS auf `PCBA 05`.
   * **`PCBA 06` (MagSafe Frame Dock Platine):** Ersatzlos gestrichen. Die elektrische Verbindung bei Koffer-Pods erfolgt über einen handelsüblichen industriellen 2-Pin Magnet-Pogo-Steckverbinder (IP68 COTS).

---

## 2. Fertigungsstandard & JLCPCB 4-Lagen Stackup (JLC04161H-7628)

Für alle 4-Lagen-Platinen (`PCBA 01` und `PCBA 05`) wird der identische, streng impedanzkontrollierte Lagenaufbau verwendet:

```
+-------------------------------------------------------------+
| Layer 1 (F.Cu - Top): High-Speed Signale, USB-Diff, Bauteile|  (35 µm / 1 oz Cu)
+-------------------------------------------------------------+
| -- Prepreg 7628 (Dielektrikum, Er = 4.4, Dicke 0.2 mm) --   |
+-------------------------------------------------------------+
| Layer 2 (In1.Cu): Durchgängige Massefläche (GND_PWR / AGND) |  (17.5 µm Standard)
+-------------------------------------------------------------+
| -- FR4 Core (Isolationskern, Dicke 1.0 mm) --------------   |
+-------------------------------------------------------------+
| Layer 3 (In2.Cu): Power-Planes (VCC_3V3, VCC_5V Polygone)   |  (17.5 µm Standard)
+-------------------------------------------------------------+
| -- Prepreg 7628 (Dielektrikum, Er = 4.4, Dicke 0.2 mm) --   |
+-------------------------------------------------------------+
| Layer 4 (B.Cu - Bottom): Sekundär-Routing, DW3110 UWB       |  (35 µm / 1 oz Cu)
+-------------------------------------------------------------+
```

### 2.1 Standardisierte Net-Klassen & Leiterbahn-Geometrien
* **`Default`:** Leiterbahnbreite $0{,}20\,\text{mm}$, Mindestabstand $0{,}20\,\text{mm}$ (Logiksignale, GPIOs).
* **`Power_5V_12V`:** Leiterbahnbreite $0{,}60\,\text{mm}$ (Stromtragfähigkeit bis $2{,}2\,\text{A}$ bei $\Delta T < 10\,^\circ\text{C}$).
* **`RF_50R`:** Leiterbahnbreite $0{,}35\,\text{mm}$, Koplanarabstand $0{,}20\,\text{mm}$ zur Massefläche (50 Ohm Wellenwiderstand für 868 MHz LoRa und DW3110 UWB 6.5 GHz).
* **`USB_90R_DIFF`:** Leiterbahnbreite $0{,}20\,\text{mm}$, differentieller Leiterbahnabstand $0{,}15\,\text{mm}$ ($90\,\Omega \pm 10\,\%$ Differenzimpedanz für USB 2.0 High-Speed 480 Mbps).
* **`Audio_Sensitive`:** Leiterbahnbreite $0{,}25\,\text{mm}$, Abstand $0{,}30\,\text{mm}$ (abgeschirmt durch flankierende GND-Leiterbahnen).

---

## 3. PCBA 01: Zentralbox Main Controller (`openmotorbridge_central_box`)

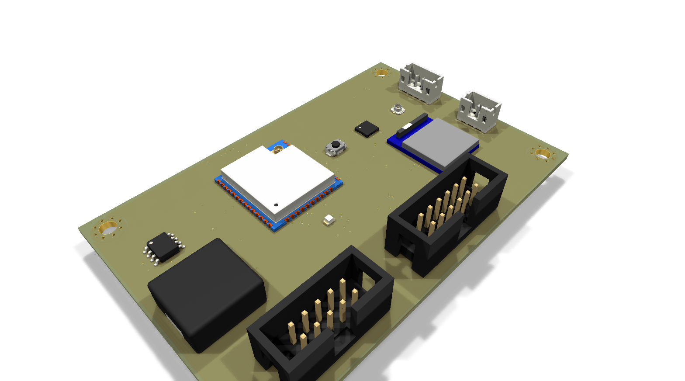
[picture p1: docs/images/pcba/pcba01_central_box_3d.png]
PCBA 01 Zentralbox Main Controller Top 3D

*Abbildung 7.1a: KiCad 3D-Render der Zentralbox-Hauptplatine Top (PCBA 01, 85 x 55 mm, 4 Lagen) mit ESP32-S3 WROOM-1, Qualcomm QCC3084 BT 5.4 Audio SoC, LM5164-Q1 72V Buck, BQ24075 USV, ES8388 DSP-Codec, Semtech SX1262 LoRa und Deutsch DTM-12 Header.*

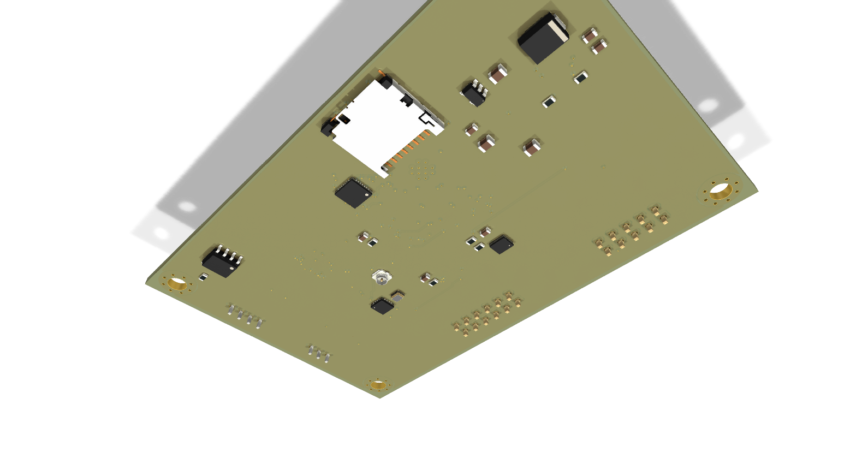
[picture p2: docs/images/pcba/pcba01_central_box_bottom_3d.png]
PCBA 01 Zentralbox Main Controller Bottom 3D

*Abbildung 7.1b: KiCad 3D-Render der Zentralbox-Hauptplatine Bottom mit DM3D MicroSD-Push-Pull-Slot, Qorvo DW3110 UWB Transceiver, BMI270 6-Achs-IMU und TCAN334G CAN-Transceiver.*

### 3.1 Technische Platinen-Kenndaten & Top/Bottom-Aufteilung
* **Abmessungen:** $85{,}0 \times 55{,}0\,\text{mm}$ (Außenkontur mit 4x M2.5 Montagebohrungen, $77{,}0 \times 47{,}0\,\text{mm}$ Lochabstand).
* **Lagenaufbau:** 4 Lagen FR-4 High-TG150 ($1{,}6\,\text{mm}$ Gesamtdicke, ENIG-Goldfinish).
* **Bestückung Top-Layer (F.Cu):**
  * **Hauptcontroller (`U2`):** Espressif `ESP32-S3-WROOM-1U` (Dual-Core @ 240 MHz, 16 MB Flash, 8 MB Octal-PSRAM) für Systemsteuerung, CAN-Bus, FreeRTOS DSP-Pipeline und PWA-Webserver.
  * **Dedizierter Helm-Audio-SoC (`U9`):** **Qualcomm QCC3084** Bluetooth 5.4 Audio-SoC ($13 \times 18\,\text{mm}$) für Dual-A2DP (aptX HD, Low Latency), LE Audio Auracast Broadcast und kristallklare Hands-Free Telefonie (HFP 1.8 mit Wideband Speech) mit integrierter Keramik-Chipantenne.  
    *(Wichtige Entkopplung: Der interne BLE-Stack des ESP32-S3 dient rein dem WebApp-Dashboard und Sensordaten, während der QCC3084 das Helm-Audio völlig unbeeinflusst von CPU-Spitzen abwickelt).*
  * **Weitbereichsfunk (`U10`):** Semtech `SX1262` LoRa Transceiver (+22 dBm PA) mit U.FL-Buchse `ANT1` zur Taoglas FXP895 Antenne in der Gehäusedeckeltasche.
  * **Bordnetz-Speisung (`U1`):** Texas Instruments `LM5164-Q1` synchroner 72V-Buck-Converter und TI `BQ24075` Power-Path-Controller mit Ladeschaltung für die interne 2.200-mAh-USV-Zelle.
  * **Status-Anzeige (`D1`):** WS2812B RGB Smart-LED zur optischen Status- und Pairing-Signalisierung.
  * **Bedienelemente & Interface:** Hardware-Taster `SW1` (Pairing / Werkseinstellung / ESP32 Bootloader) und automotiver Deutsch DTM-12 Shrouded Header `J1` sowie Box-Header `J3` und JST-Header `J4`/`J5`.
* **Bestückung Bottom-Layer (B.Cu):**
  * **MicroSD-Kartenslot (`J2`):** Hirose `DM3D-SF` Push-Pull MicroSD-Kartenhalter, montiert an der oberen Platinenkante ($X=146{,}0, Y=79{,}0$, $180^\circ$ gedreht) mit Karteneinschub bündig zur Gehäusekante für werkzeugfreie Zugänglichkeit (0 mm Überlappung, >2.4 mm Sicherheitsabstand zu allen Nachbarbauteilen).
  * **UWB-Funkknoten (`U8`):** Qorvo `DW3110` Ultra-Wideband IEEE 802.15.4z Transceiver (Kanal 5 @ 6.489 GHz) mit $38{,}4\,\text{MHz}$ Quarz `Y1_UWB` und U.FL-Buchse `ANT2` zur Taoglas FXUWB10 Antenne in der Gehäusebodentasche.
  * **Audio-Codec (`U3`):** Everest Semi `ES8388` 24-Bit / 48 kHz Low-Power Stereo-Audio-Codec.
  * **Sensoren (`U5`):** Bosch `BMI270` 6-Achs-IMU (I2C) zur Wake-on-Motion Diebstahlüberwachung und Sturzerkennung.
  * **CAN-Transceiver (`U6`):** Texas Instruments `TCAN334G` / `TCAN1042V` 5 Mbps CAN-FD Bus-Transceiver.
  * **Low-Noise LDO (`U11`):** Texas Instruments `TPS7A0533` 3.3V Ultra-Low-Noise LDO für saubere Analog- und Sensor-Spannungsversorgung.
  * Durchgehende thermische Massevias zur Wärmeabfuhr des LM5164 und der eFuses.

### 3.2 Pinbelegung des 12-poligen Deutsch DTM-12 Steckverbinders (`J1`)

```
+---------------------------------------------------------------------------------------------------------------+
| DEUTSCH DTM-12 PINBELEGUNG (ZENTRALBOX POWER, CAN & DC-PEITSCHEN 1 BIS 4)                                     |
+-----+----------------+--------------------------+-------------+---------------------+-------------------------+
| Pin | Signalname     | Signalart / Pegel        | Querschnitt | Kabelbaum-Zweig     | Funktion & Schutz       |
+-----+----------------+--------------------------+-------------+---------------------+-------------------------+
|  1  | KL30_IN        | +9V...+72V DC Dauerplus  | AWG20 0.50² | Peitsche 4 (Bordnetz)| Bordnetz Dauerplus     |
|  2  | KL15_IGN       | +9V...+72V DC Zündungspl.| AWG22 0.34² | Peitsche 4 (Bordnetz)| Zündungssignal (KL15)   |
|  3  | VEHICLE_GND    | Power-Masse (0V)         | AWG20 0.50² | Peitsche 4 (Bordnetz)| Zentrale Bordnetzmasse  |
|  4  | CAN_H          | CAN-FD High (ISO 11898-2)| AWG24 0.22² | Peitsche 4 (Bordnetz)| Fahrzeug-CAN Bus High   |
|  5  | CAN_L          | CAN-FD Low (ISO 11898-2) | AWG24 0.22² | Peitsche 4 (Bordnetz)| Fahrzeug-CAN Bus Low    |
|  6  | POD1_VCC       | +12V geschaltet (0,5A)   | AWG22 0.34² | Peitsche 1 (Pod 1)  | DC-Power Bucht 1 (eFuse)|
|  7  | POD1_GND       | Power-Masse (0V)         | AWG22 0.34² | Peitsche 1 (Pod 1)  | Masse Bucht 1 (Links)   |
|  8  | POD2_VCC       | +12V geschaltet (0,5A)   | AWG22 0.34² | Peitsche 2 (Pod 2)  | DC-Power Bucht 2 (eFuse)|
|  9  | POD2_GND       | Power-Masse (0V)         | AWG22 0.34² | Peitsche 2 (Pod 2)  | Masse Bucht 2 (Rechts)  |
| 10  | RADAR_PWR_12V  | +12V geschaltet (1,0A)   | AWG22 0.34² | Peitsche 3 (Radar)  | DC-Power Heck-Radar     |
| 11  | RADAR_GND      | Power-Masse (0V)         | AWG22 0.34² | Peitsche 3 (Radar)  | Masse Heck-Radar        |
| 12  | CHASSIS_EARTH  | Schirmmasse              | AWG20 0.50² | Peitsche 4 (Bordnetz)| Gehäuse- & Schirmschutz |
+-----+----------------+--------------------------+-------------+---------------------+-------------------------+
```

### 3.3 Pinbelegung & Systemanbindung: Qualcomm QCC3084 BT 5.4 Audio SoC (`U9`)

Der auf der Oberseite (`F.Cu` bei $X=175{,}0, Y=106{,}0$) platzierte **Qualcomm QCC3084** ($13 \times 18\,\text{mm}$ Modul mit integrierter Keramik-Chipantenne) verbindet die Helme drahtlos über hardware-beschleunigtes Dual-A2DP (aptX HD / Adaptive) und HFP 1.8:

```
+----------------------------------------------------------------------------------------+
| QUALCOMM QCC3084 PINBELEGUNG & SCHNITTSTELLEN ZUM ESP32-S3 / ES8388                    |
+-----+----------------+--------------------+-------------------+------------------------+
| Pin | Signalname     | Signalart          | Verbunden mit     | Funktion & Protokoll   |
+-----+----------------+--------------------+-------------------+------------------------+
|  1  | VCC_3V3        | Power In (+3.3V)   | LM5164 3.3V Bus   | Modul-Betriebsspannung |
|  2  | GND            | Masse (0V)         | GND_PWR Plane     | HF- und Systemmasse    |
|  3  | I2S_MCLK       | Digital In (Clock) | ESP32-S3 (GPIO 9) | Master-Clock (12.288M) |
|  4  | I2S_BCLK       | Digital In (BitClk)| ESP32-S3 (GPIO 10)| Bit-Clock (3.072 MHz)  |
|  5  | I2S_WS         | Digital In (LRCK)  | ESP32-S3 (GPIO 11)| Word-Select (48 kHz)   |
|  6  | I2S_DOUT       | Digital In (Audio) | ESP32-S3 (GPIO 12)| Stereo-PCM zum QCC3084 |
|  7  | I2S_DIN        | Digital Out (Mic)  | ESP32-S3 (GPIO 13)| HFP-Mikrofon zum DSP   |
|  8  | GND            | Masse (0V)         | GND_PWR Plane     | HF-Schirmmasse         |
|  9  | BT_UART_TX     | Digital Out (UART) | ESP32-S3 (GPIO 18)| QCC3084 Telemetrie/AT  |
| 10  | BT_UART_RX     | Digital In (UART)  | ESP32-S3 (GPIO 17)| ESP32 AT-Steuerbefehle |
| 11  | BT_EN          | Digital In (Reset) | ESP32-S3 (GPIO 16)| Kaltstart & Power-Down |
| 12  | GND            | Masse (0V)         | GND_PWR Plane     | HF-Schirmmasse         |
+-----+----------------+--------------------+-------------------+------------------------+
```

* **Integrierte Keramik-Chipantenne:** 2.402–2.480 GHz, Gewinn $+2{,}0\,\text{dBi}$, omnidirektionale Charakteristik nach oben/vorn zum Cockpit und Fahrer-/Sozius-Helm.
* **Keine Koax-Zuleitung:** Durch die direkte Abstrahlung vom Modulsubstrat bleibt das Innere der Zentralbox aufgeräumt und störungsarm.

---

## 4. Satelliten Pod-Gehäuse & Entfall von PCBA 02 (Monolithisches Gehäuse)

Die frühere Pod-Basisplatine (`PCBA 02`) ist in v9.6 **vollständig und ersatzlos entfallen**:
1. **Monolithischer Gehäusekörper:** Das Pod-Gehäuse (`pod_base_housing.stl`) ist ein 100 % passives 3D-Druck-Präzisionsteil (MJF PA12).
2. **Direkte 2-Draht DC-Federkontaktierung:** Die 2-adrige DC-Leitung vom Deutsch DTM-12 Stecker führt über eine rückseitige Formdichtung direkt in den Schacht und endet an zwei massiven, vergoldeten Federkontakten (Mill-Max).
3. **Null Ausfallrisiko:** Keine Schalter, keine aktiven ICs und keine empfindlichen Buchsen im Spritzwasserbereich der Kofferträger.

---

## 5. PCBA 03: Universal Smart Cartridge (`openmotorbridge_pod_cartridge` Rev 3.0)

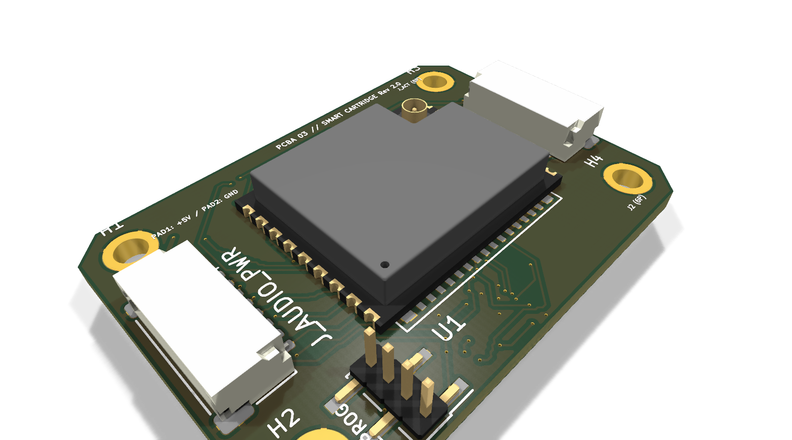
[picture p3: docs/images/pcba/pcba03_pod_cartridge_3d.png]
PCBA 03 Universalschlitten Cartridge Top 3D

*Abbildung 7.3a: KiCad 3D-Render der Universal Smart Cartridge Top (PCBA 03 Rev 3.0, 35 x 25 mm) mit ESP32-C6 Host-MCU, 4x AO3400A MOSFETs und J_ACT Mechatronik-Header.*

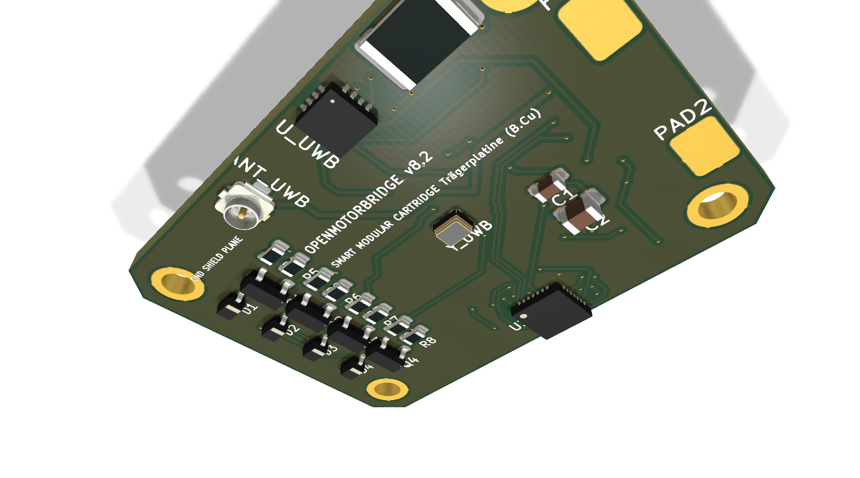
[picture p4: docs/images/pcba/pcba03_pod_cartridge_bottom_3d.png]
PCBA 03 Universalschlitten Cartridge Bottom 3D

*Abbildung 7.3b: KiCad 3D-Render der Universal Smart Cartridge Bottom mit Qorvo DW3110 UWB Transceiver, ES8388 Stereo-Codec und Audio-Power-Header J_AUDIO_PWR.*

### 5.1 Technische Platinen-Kenndaten & Funktionale Lagen-Aufteilung
* **Abmessungen:** $35{,}0 \times 25{,}0\,\text{mm}$ (Raster $29{,}0 \times 19{,}0\,\text{mm}$ mit 4x M2 Befestigungsbohrungen).
* **Lagenaufbau:** 2 Lagen FR-4 High-TG150 ($1{,}2\,\text{mm}$ Dicke, $35\,\mu\text{m}$ Cu beidseitig, ENIG-Goldfinish).
* **Bestückung Top-Layer (F.Cu - Mechatronik & Steuerung):**
  * `U2`: Espressif `ESP32-C6` RISC-V Host-MCU (verwaltet Kassetten-Profile, UWB-Kommunikation und Aktuator-Timings).
  * `Q1` - `Q4`: 4x N-Kanal MOSFETs (`AO3400A`, SOT-23, $30\,\text{V} / 5{,}7\,\text{A}$) samt Freilaufdioden `D1`-`D4`. Platziert unmittelbar neben dem Header `J_ACT` für kürzeste Leiterbahnwege zu den Taster-Aktuatoren.
  * `J_ACT`: 8-poliger $1{,}0\,\text{mm}$ JST-SH Header zur Ansteuerung der 4 Miniatur-Hubmagnete.
  * `J_AUDIO_PWR`: **8-poliger $1{,}0\,\text{mm}$ JST-SH Header** (baugleich zu `J_ACT`) zur galvanisch getrennten Stern-Masseanbindung des Adapterkabelstrangs an das jeweilige OEM-Headset.
* **Bestückung Bottom-Layer (B.Cu - HF, Audio-Codec & Stromaufnahme):**
  * `U1`: Qorvo `DW3110` Ultra-Wideband Transceiver (6.489 GHz Ch. 5) mit integrierter PCB-Antenne. Strahlungsrichtung zeigt nach unten durch den Kunststoffboden der Kassette für optimale Funkverbindung zur Zentralbox.
  * `U3`: Everest Semi `ES8388` 24-Bit / 48 kHz Low-Noise Audio-Codec. Bewusst auf der **Unterseite (`B.Cu`)** platziert: Dadurch sind die empfindlichen analogen Mikrofon- und Kopfhörerleitungen durch die interne Kupfer-Massefläche hermetisch von den steilen Schaltflanken der Top-Layer-MOSFETs (`Q1`–`Q4`) und Aktuatorströmen entkoppelt. Wandelt das analoge Mikrofon- und Lautsprechersignal von Sena, Cardo oder Midland direkt auf der Kassette und streamt es jitterfrei digital via I2S/UWB.
  * `PAD1` & `PAD2`: Stirnseitige, massive vergoldete Kontaktflächen (ENIG) für die 2-Draht DC-Federkontakte des Pods.
  * `F1`: Selbstrückstellende 500mA PPTC-Sicherung.

### 5.2 Pinbelegung des Audio-Power-Headers (`J_AUDIO_PWR` / 8-Pin JST-SH 1.0mm)

Um das gefürchtete **Übersprechen von Lade- und Sendeströmen in das Audiosignal (Common-Impedance Coupling)** physikalisch auszuschließen, ist der Header `J_AUDIO_PWR` als **8-Pin JST-SH** mit strikter Trennung von Leistungs- und Audio-Massen ausgelegt:

| Pin | Signalname | Richtung | Funktion & OEM-Verbindung |
| :---: | :--- | :---: | :--- |
| **1** | **`PGND`** | Power Return | **Leistungs-Masse:** Führt den gesamten Rückstrom des Laders / DC-DC-Wandlers ($0{,}2\dots 0{,}6\,\text{A}$) |
| **2** | **`VCC_HEADSET`** | Power Out (+5V / +3.85V) | Geregelte Betriebsspannung für das Intercom-Modul (Lade- oder Dauerstrom) |
| **3** | **`AGND_SPK`** | Audio-Massebezug | **Saubere Kopfhörermasse:** Führt zum 3,5-mm-Klinkenhülsen-Kontakt (Sleeve) – **stromlos ($I = 0\,\text{mA}$)!** |
| **4** | **`AUDIO_L_IN`** | Audio In $\leftarrow$ OEM | Line-Out Lautsprecher Links vom Headset zum ES8388 ADC (Kanal 1) |
| **5** | **`AUDIO_R_IN`** | Audio In $\leftarrow$ OEM | Line-Out Lautsprecher Rechts vom Headset zum ES8388 ADC (Kanal 2) |
| **6** | **`AGND_MIC`** | Audio-Massebezug | **Saubere Mikrofonmasse:** Eigener Rückleiter für den Mikrofoneingang – **stromlos ($I = 0\,\text{mA}$)!** |
| **7** | **`MIC_OUT`** | Audio Out $\rightarrow$ OEM | Mikrofonsignal vom ES8388 DAC in das Headset ($< 1\,\text{ms}$ Latenz) |
| **8** | **`PTT_IO`** | Bidir / Open-Drain | PTT-Tastung gegen Masse (Midland PMR446) oder DMR/Mode-Select |

> [!IMPORTANT]
> **Warum 8 Pins die Strombrumm-Problematik („Lade- & Mesh-Surren“) zu 100 % lösen:**
> 1. **Das Problem geteilter Massen:** Zieht ein Headset z. B. $300\,\text{mA}$ Lade- oder HF-Sendestrom über eine gemeinsame Masseleitung mit $80\,\text{m}\Omega$ Gesamtwiderstand (Steckkontakt + Litze), schwankt das Massepotential um $\Delta V = 300\,\text{mA} \times 0{,}08\,\Omega = 24\,\text{mV}$. Da Mikrofon-Signale typisch nur $5\dots 15\,\text{mV}$ betragen, würde der Mikrofoneingang des Headsets dieses $24\,\text{mV}$ Spannungsbrummen (Mesh-TDMA-Knattern, Schaltregler-Pfeifen) um $+30\,\text{dB}$ vorverstärken!
> 2. **Die OpenMotorBridge-Lösung (Kelvin-Grounding):** Durch die getrennten Pins `AGND_SPK` (Pin 3) und `AGND_MIC` (Pin 6) fließt **kein einziger Milliampere Betriebsstrom** ($I_{\text{Audio}} = 0\,\text{A}$). Der ohmsche Spannungsabfall ist physikalisch **exakt $\Delta V = 0\,\text{mV}$**. Der hohe Laststrom fließt isoliert über Pin 1 (`PGND`) direkt zum DC-DC-Filter auf `PCBA 03` ab.
> 3. **BOM-Vorteil:** Durch den Wechsel auf 8 Pins nutzt `J_AUDIO_PWR` exakt dieselbe LCSC-Teilenummer (`JST_SH_SM08B-SRSS-TB`) wie der Mechatronik-Header `J_ACT`. Das spart einen Feeder-Slot bei JLCPCB und eliminiert Bestückungsfehler.

### 5.3 Pinbelegung des Aktuator-Headers (`J_ACT` / 8-Pin JST-SH 1.0mm)
| Pin | Signalname | Ansteuerung | Mapping: Sena SPIDER X Slim | Mapping: Cardo Packtalk Edge |
| :---: | :--- | :---: | :--- | :--- |
| **1 & 2** | `VCC_5V` | Dauer-5V | Gemeinsame Versorgungs-Schiene für alle 4 Aktuatoren |
| **3** | `ACT1_OUT` | MOSFET `Q1` | **Plus (+)** (Lauter / Menü vor) | **Media Button** (Front/Top) |
| **4** | `ACT2_OUT` | MOSFET `Q2` | **Minus (-)** (Leiser / Menü zurück)| **Mobile Button** (Phone/Pairing) |
| **5** | `ACT3_OUT` | MOSFET `Q3` | **Center / Phone** (Bestätigen) | **Intercom Button** (DMC Grouping) |
| **6** | `ACT4_OUT` | MOSFET `Q4` | **Mesh Button** (45° seitlich) | **Control Wheel Center-Press** |
| **7 & 8** | `GND` | Power-Masse | Massebezug für Rückstrom | Massebezug für Rückstrom |

---

## 6. PCBA 04: Heck-Pod 3 (Ersatzlos entfallen)

Die Heckplatine `PCBA 04` und das zugehörige Heckgehäuse Pod 3 sind **vollständig gestrichen**:
* Der Semtech SX1262 LoRa-Transceiver arbeitet direkt auf der Zentralbox (`PCBA 01`).
* Das u-blox SAM-M10Q GNSS-Modul arbeitet im Fahrtwindeinlass des Front-Knotens (`PCBA 05`).

---

## 7. PCBA 05: Universal Front-Knoten (`openmotorbridge_front_node`)

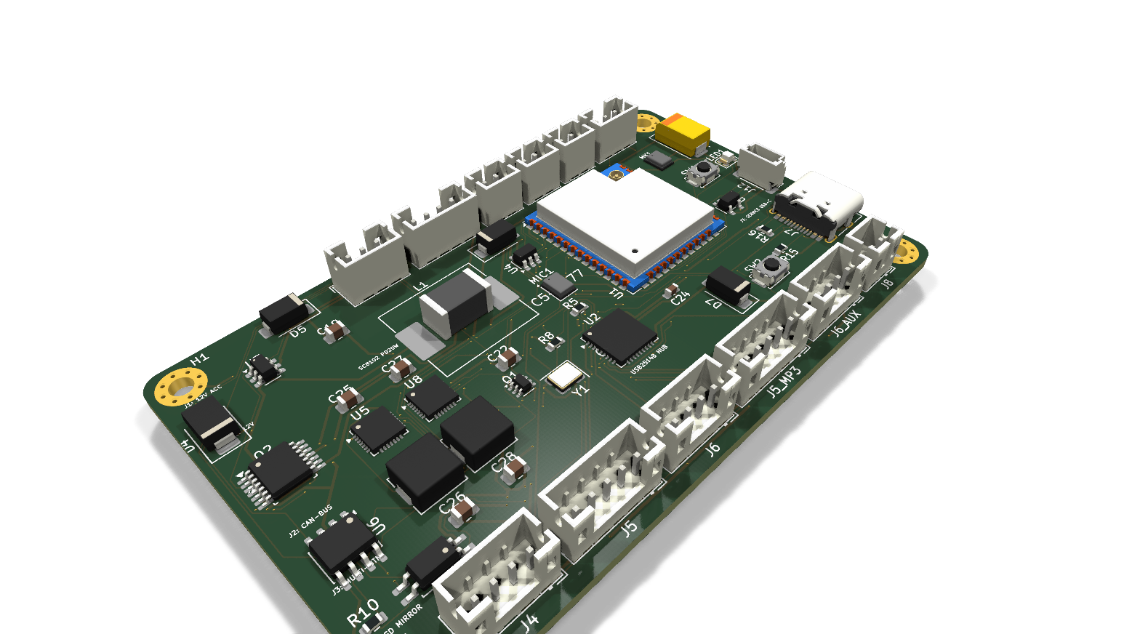
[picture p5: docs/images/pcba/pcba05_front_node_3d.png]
PCBA 05 Universal Front-Knoten Top 3D

*Abbildung 7.5a: KiCad 3D-Render des Universal Front-Knotens Top (PCBA 05, 82 x 50 mm) mit ESP32-S3-WROOM-1U, u-blox SAM-M10Q GNSS, Microchip USB2514B Hub und Southchip SC8102 USB-PD 20W Fast-Charge.*

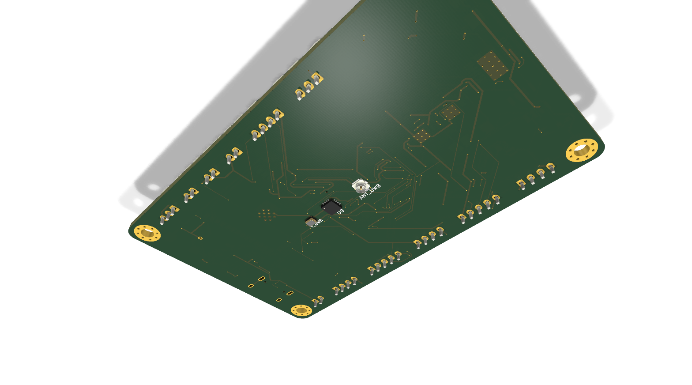
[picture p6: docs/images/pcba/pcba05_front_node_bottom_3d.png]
PCBA 05 Universal Front-Knoten Bottom 3D

*Abbildung 7.5b: KiCad 3D-Render des Universal Front-Knotens Bottom mit Qorvo DW3110 UWB Transceiver und U.FL-HF-Verbindung.*

### 7.1 Technische Platinen-Kenndaten
* **Abmessungen:** $82{,}0 \times 50{,}0\,\text{mm}$ (Gehäuseaußenmaß $98 \times 68 \times 25\,\text{mm}$ mit 4-in-1 Halterung).
* **Lagenaufbau:** 4 Lagen FR-4 High-TG150 ($1{,}6\,\text{mm}$, ENIG-Goldfinish).
* **Top-Layer:** ESP32-S3 Controller, USB2514B USB-Hub, u-blox SAM-M10Q Multi-GNSS mit integrierter Patchantenne, Knowles SPH0645LM4H I2S MEMS Akustiksensor, WS2812B-2020 RGB-LED und 5 GHz Wi-Fi Anbindung für Headless CarPlay / Android Auto.
* **Bottom-Layer:** Qorvo DW3110 UWB Transceiver (6.489 GHz Ch. 5), TI LMR36015 Buck, SC8102 USB-PD 20W Fast-Charger, TI TPS2051B Lastschalter für automatischen Dongle-Kaltstart und Auto-Café-Modus.

### 7.2 Vollständige Pinbelegung der Front-Node Steckverbinder (`J1` bis `J12`)

Alle internen Cockpit-, Lade- und Sensoranschlüsse sind auf vibrationsfeste **JST-PH Steckverbinder (2,0 mm Raster)** sowie **JST-SH / Qwiic (1,0 mm Raster)** geführt. Handelsübliche, vorkonfektionierte COTS-Pigtail-Kabel werden werkzeuglos angesteckt:

| Header | Typ / Raster | Pin | Signalname | Signalpegel / Richtung | Funktion & angeschlossene Cockpit-Peripherie |
| :--- | :--- | :---: | :--- | :--- | :--- |
| **`J1`** | **JST-PH 2-Pin**<br>(2.0 mm) | 1<br>2 | `KL15_12V_SW`<br>`GND` | +9V...+16V In<br>Power-Masse | **12V Bordnetzspeisung:** Zündungsplus (Standlicht / Cartool-Stecker / Y-Kabel Abzweig A) |
| **`J2`** | **JST-PH 3-Pin**<br>(2.0 mm) | 1<br>2<br>3 | `CAN_H`<br>`CAN_L`<br>`GND` | CAN-FD High<br>CAN-FD Low<br>Massebezug | **Fahrzeug-CAN-Bus:** Direkter Abgriff im Cockpit / Diagnosestecker mit TCAN334G & CPC1017N Busabschluss |
| **`J3`** | **JST-PH 4-Pin**<br>(2.0 mm) | 1<br>2<br>3<br>4 | `GND`<br>`PTT_IN1_N`<br>`PTT_IN2_N`<br>`PTT_IN3_N` | Masse (0V)<br>Digital In (Pull-Up)<br>Digital In (Pull-Up)<br>Digital In (Pull-Up) | **Lenkerarmatur / Multifunktionstaster:**<br>Taste 1: PTT Intercom Funk / Voice<br>Taste 2: Action-Cam Bookmark / Highlight<br>Taste 3: Quick-Action / Navigationsmenü |
| **`J4`** | **JST-PH 4-Pin**<br>(2.0 mm) | 1<br>2<br>3<br>4 | `USB_UP_VBUS`<br>`USB_UP_DM`<br>`USB_UP_DP`<br>`GND` | +5V VBUS In<br>USB 2.0 D-<br>USB 2.0 D+<br>Masse (0V) | **USB Upstream Host:** Verbindung zum OEM-Motorrad-Infotainment (Harley Boom! Box / Skyline OS) |
| **`J5`** | **JST-PH 5-Pin**<br>(2.0 mm) | 1<br>2<br>3<br>4<br>5 | `VBUS_PD1_OUT`<br>`USB_DN1_DM`<br>`USB_DN1_DP`<br>`USB_DN1_CC`<br>`GND` | +5V / +9V / +12V Out<br>USB 2.0 D-<br>USB 2.0 D+<br>Configuration Channel<br>Power-Masse | **Smartphone Fast-Charge PD 20W:** Pigtail auf wetterfeste USB-C Buchse am Lenker (SW3526 Regler `U5`, USB-PD 3.0, QC4+) |
| **`J5_MP3`** | **JST-PH 5-Pin**<br>(2.0 mm) | 1<br>2<br>3<br>4<br>5 | `VBUS_PD3_OUT`<br>`USB_DN3_DM`<br>`USB_DN3_DP`<br>`USB_DN3_CC`<br>`GND` | +5V / +9V / +12V Out<br>USB 2.0 D-<br>USB 2.0 D+<br>Configuration Channel<br>Power-Masse | **Glovebox / Media-Bay PD 20W + MP3:** Pigtail ins Handschuhfach für Musik-USB-Sticks, Powerbanks und Zweithandy (SW3526 `U8`) |
| **`J6`** | **JST-PH 4-Pin**<br>(2.0 mm) | 1<br>2<br>3<br>4 | `VCC_5V_OTTOCAST`<br>`USB_DN2_DM`<br>`USB_DN2_DP`<br>`GND` | +5V geschaltet (1.5A)<br>USB 2.0 D-<br>USB 2.0 D+<br>Masse (0V) | **CP2AA Wireless Dongle Pigtail:** USB-A Buchsenkabel für Ottocast / Carlinkit Adapter mit automatischem Kaltstart via TPS2051B |
| **`J6_AUX`** | **JST-PH 4-Pin**<br>(2.0 mm) | 1<br>2<br>3<br>4 | `VCC_5V`<br>`USB_DN4_DM`<br>`USB_DN4_DP`<br>`GND` | +5V Out (1.0A)<br>USB 2.0 D-<br>USB 2.0 D+<br>Masse (0V) | **Cockpit Aux USB:** Freier Port für Dashcam, Chigee AIO-5 Display, Garmin Zūmo oder Reifendruck-Empfänger |
| **`J7`** | **USB-C SMD**<br>(16-Pin) | All | `USB-C Standard` | USB 2.0 + VBUS | **Wasserdichter Service-Port:** Bündig in der rechten Gehäuseflanke mit TPU-Stopfen (Flashen & WebSerial Diagnose) |
| **`J8`** | **JST-PH 2-Pin**<br>(2.0 mm) | 1<br>2 | `VCC_5V`<br>`GND` | +5V geschaltet (1.5A)<br>Power-Masse | **Action-Cam Power:** 5V-Speisung für Helm- oder Verkleidungskamera (GoPro / Insta360), schaltet mit Zündung |
| **`J9`** | **JST-PH 3-Pin**<br>(2.0 mm) | 1<br>2<br>3 | `+12V_PROT`<br>`BSD_LEFT_N`<br>`BSD_RIGHT_N` | +12V Daueranode<br>Kathode Links (Low-Side)<br>Kathode Rechts (Low-Side) | **Spiegel-Warn-LEDs (Totwinkel-Radar):** Y-Kabel zu den Rückspiegel-LEDs, geschaltet via Dual-MOSFET `Q1` |
| **`J10`** | **JST-PH 2-Pin**<br>(2.0 mm) | 1<br>2 | `+12V_PROT`<br>`GND` | +12V geschaltet (1.5A)<br>Power-Masse | **Qi Wireless Charging Head:** Speist SP Connect / Quad Lock Induktivlader (0.0 µA Ruhestrom bei Zündung AUS) |
| **`J11`** | **JST-PH 2-Pin**<br>(2.0 mm) | 1<br>2 | `+12V_AUX`<br>`GND` | +12V geschaltet (2.0A)<br>Power-Masse | **Zusatzscheinwerfer / Strobe:** Schaltstufe für Nebelscheinwerfer oder High-Beam Signal |
| **`J12`** | **JST-SH 4-Pin**<br>(1.0 mm) | 1<br>2<br>3<br>4 | `GND`<br>`VCC_3V3`<br>`I2C_SDA`<br>`I2C_SCL` | Masse (0V)<br>+3.3V Power Out<br>I2C Datenleitung<br>I2C Taktleitung | **Qwiic / STEMMA QT Sensor-Bus:** Steckverbindung zum SAM-M10Q GNSS-Modul sowie TMP117 / OPT3001 Sensoren |
| **`ANT_UWB`**| **U.FL Hirose** | 1<br>2 | `UWB_RF_CH5`<br>`GND` | 6.5 GHz RF (50 Ohm)<br>Schirmmasse | **UWB Flex-Antenne:** 20 mm U.FL Kabel zur Taoglas FXUWB10 Antenne in der Gehäuseboden-Bucht |

---

## 8. PCBA 06: MagSafe Frame Dock (Ersatzlos entfallen)

Die separate Platine `PCBA 06` ist in v9.6 **vollständig und ersatzlos entfallen**:
* Da über die fahrzeugseitige Koffer-Trennstelle ausschließlich 2-Draht DC-Gleichspannung geführt wird, kommt anstelle einer proprietären Leiterplatte ein **industrieller 2-Pin Magnet-Pogo-Steckverbinder (IP68 COTS)** zum Einsatz.
* Kurzschlussschutz und Überlastbegrenzung erfolgen zentral auf `PCBA 01` durch die jeweiligen **TI TPS25921 eFuses**.

---

## 9. PCBA 07: 2-in-1 LoRa Smart-Keyfob (`openmotorbridge_smart_keyfob`)

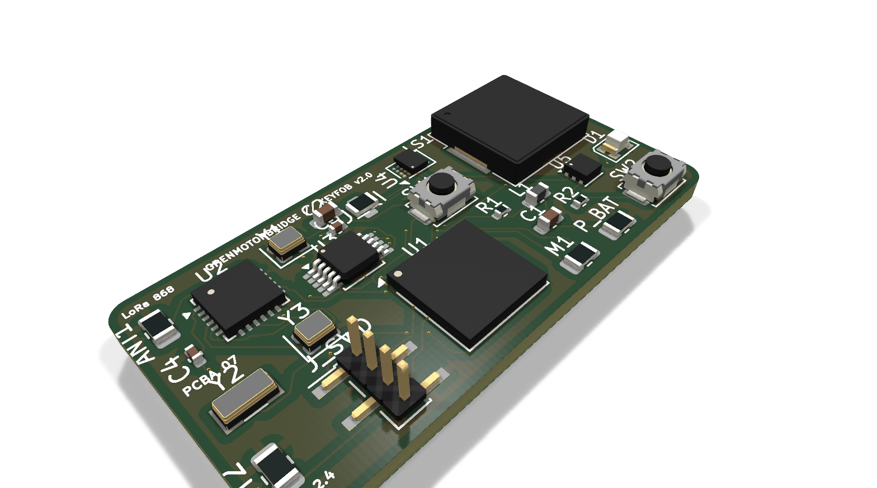
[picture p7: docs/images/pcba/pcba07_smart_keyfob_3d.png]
PCBA 07 2-in-1 LoRa Smart-Keyfob


*Abbildung 7.7: 3D-Render der ultrakompakten PCBA 07 Trägerplatine (38,0 x 19,0 mm, 2 Lagen) mit Nordic nRF52840 SoC, Semtech SX1262 LoRa Transceiver, TI DRV2605L Haptik-Treiber, BQ51003 Qi-Ladecontroller und 2-Pin JST-ACH Induktions-Spulenanschluss.*

### 9.1 Technische Platinen-Kenndaten & Lötfreie Qi-Montage
* **Abmessungen:** $38{,}0 \times 19{,}0 \times 1{,}0\,\text{mm}$ (2-Lagen FR-4, ENIG-Goldfinish).
* **Kern-Chips:**
  * Nordic `nRF52840` SoC (Bluetooth Low Energy 5.4, ARM Cortex-M4F @ 64 MHz, Hardware-Crypto).  
    *(BLE gewährleistet einen extrem sparsamen Ruhestrom von $< 25\,\mu\text{A}$, sodass die 200-mAh-Zelle monatelang betriebsbereit bleibt).*
  * Semtech `SX1262` LoRa Transceiver (868.5 MHz Kanal 3, empfängt Alarme bis zu 4,5 km Reichweite).
  * Texas Instruments `DRV2605L` Haptiktreiber für Vybronics 10x3.6mm LRA Linearmotor.
  * Texas Instruments `BQ51003` Qi Wireless Power Receiver Controller.
* **100 % Lötfreie Induktionsspulen-Montage (`J_QI`):**
  * Die 28-mm-Qi-Empfängerspule wird über einen ultrakompakten **2-poligen JST-ACH SMD-Header (`J_QI`)** vibrationsfest angesteckt.
  * Beim Zusammenbau sind keinerlei manuelle Lötarbeiten erforderlich.

---

## 10. PCBA 08: 77 GHz mmWave Radar Sub-MCU & Warnflügel (`openmotorbridge_radar_submcu`)

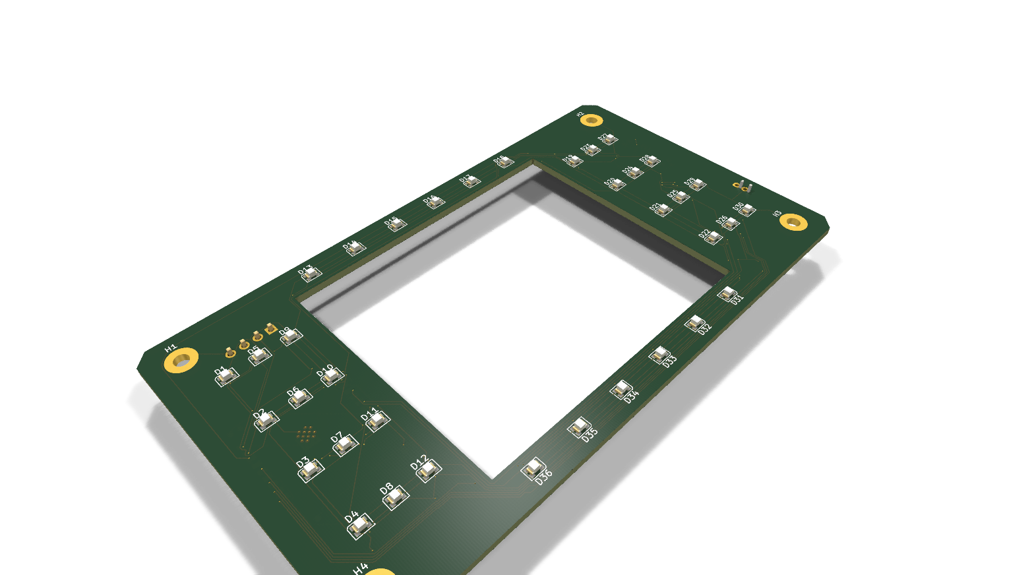
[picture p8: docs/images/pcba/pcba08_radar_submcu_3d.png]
PCBA 08 Radar 2.0 Sub-MCU & Warnflügel 3D


*Abbildung 7.8: 3D-CAD-Ansicht der PCBA 08 mit symmetrischem 115 x 65 mm Flügelkörper, zentralem 61 x 51 mm Radardurchbruch für das Wheeltec MR20 mmWave Radar, 36x WS2812B-2020 LEDs, ESP32-C5 Sub-MCU und integriertem Qorvo DW3110 UWB Transceiver.*

### 10.1 Technische Platinen-Kenndaten & All-UWB Backbone
* **Abmessungen:** $115{,}0 \times 65{,}0 \times 1{,}6\,\text{mm}$ (2 Lagen FR-4 High-TG150, ENIG-Goldfinish).
* **Zentraler Radardurchbruch:** $61{,}0 \times 51{,}0\,\text{mm}$ rechteckiges Sichtfenster für das Wheeltec MR20 77-GHz-Sensormodul.
* **Bestückung & HF-Architektur (Strikt 2x U.FL, kein 2.4 GHz am Heck):**
  * Espressif `ESP32-C5` Dual-Band RISC-V SoC: Dient als Sub-MCU und 5.9 GHz V2X-Uplink (C-V2X / ITS-G5 802.11p) über dedizierte U.FL-Buchse `U.FL_5G9_V2X` an Taoglas FXP524 Flexantenne.
  * **WICHTIGER HF-GRUNDSATZ:** Das 2.4-GHz-HF-Frontend des ESP32-C5 (Wi-Fi/BLE) ist am Heck **strikt deaktiviert bzw. unbeschaltet**. Am Heck existiert **keine 2.4 GHz Antenne**, um HF-Kollisionen und Intermodulationsprodukte mit OMM 2.4 GHz und Cardo/Sena-Pods am Bike vollständig zu eliminieren.
  * Qorvo `DW3110` Ultra-Wideband Transceiver (`U3`) mit U.FL-Buchse `J4` für eine Taoglas FXUWB10 Flexantenne (6.5 GHz UWB Kanal 5/9). Sämtliche Radar-Rohdatenvektoren werden drahtlos über UWB an die Zentralbox gestreamt (**Null Kupfer-Datenleitungen zum Fahrzeug**).
  * **HF-Gesamtübersicht PCBA 08:** Genau **2x U.FL HF-Buchsen** (`J4` für 6.5 GHz UWB, `U.FL_5G9_V2X` für 5.9 GHz V2X). Das Wheeltec MR20 77-GHz-Radar verfügt über integrierte Antenna-on-Package (AoP) Patch-Antennen auf der Sensor-Frontseite und benötigt keine externen HF-Koaxialleitungen.
  * 36x SMD `WS2812B-2020` RGB-LEDs auf den symmetrischen Warnflügeln (18 links / 18 rechts).
* **Steckverbinder & Wartung:**
  * `J1`: Wasserdichter 2-poliger 12V Automotive-Stecker (JST JWPF) für Zuleitung (`RADAR_PWR_12V` / `RADAR_GND`). Der frühere Binder M5 Stecker entfällt ersatzlos.
  * `J2`: 4-Pin JST-SH Header zum Wheeltec MR20 mmWave Radar (UART1 @ 115.200 Baud).
  * `J3`: **90° gewinkelte 4-Pin Stiftleiste (`3V3`, `TX`, `RX`, `GND`)** bündig an der seitlichen Gehäusekante für bequemes Flashen und Firmware-Debugging des ESP32-C5 ohne Ausbau der Platine.
* **Autonome Notfall-Strobe-Steuerung:**
  * Erkennt der lokale ESP32-C5 einen herannahenden Auffahrunfall (Time-to-Collision $\text{TTC} < 1{,}5\,\text{s}$), löst er den hochfrequenten Notfall-Strobe der 36 LEDs **lokal in $< 1\,\text{ms}$** aus - völlig unabhängig vom Funkverkehr zur Zentralbox.

---

## 11. PCBA 09: OMM 2.4 GHz Autonomes Intercom-Modul (`openmotorbridge_omm_ucs`)

Die Platine **`PCBA 09`** ist die universelle Open-Source-Hardware für das OpenMotorMesh (OMM) 2.4 GHz Intercom-System. Sie erfüllt die mechanischen und elektrischen Spezifikationen für den autonomen Betrieb in standardisierten ECE 22.06 UCS-Helmmulden sowie als HF-Einsatz im Kassetten-Schlitten (`PCBA 03`).

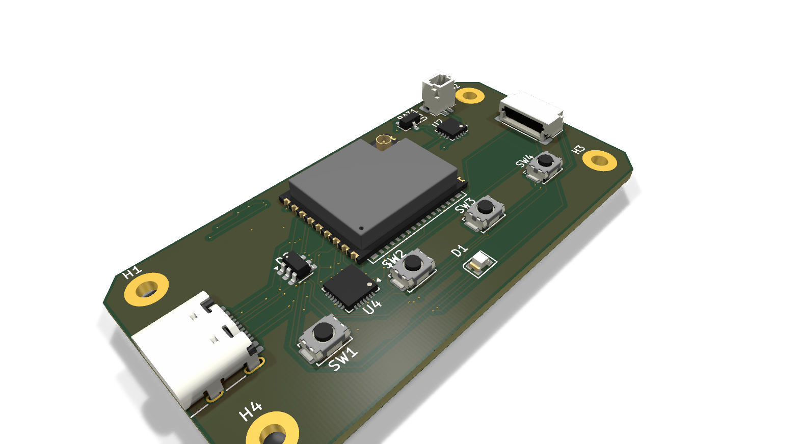
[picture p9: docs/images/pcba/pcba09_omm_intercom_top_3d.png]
PCBA 09 OMM 2.4 GHz Intercom & UCS Modul Top 3D

*Abbildung 7.9a: PCBA 09 Top 3D (Aktuelles Routing & Placement) – ESP32-C6 Host-MCU (U1), ES8388 Audio-Codec (U4), BQ24075 PMIC (U2), ME6211 3.3V LDO (U3), IP67 USB-C (J1) und 4-Tasten-Reihe.*

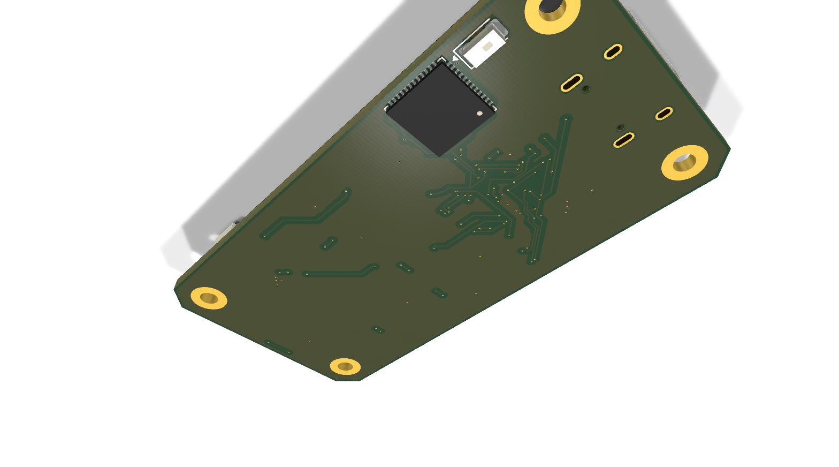
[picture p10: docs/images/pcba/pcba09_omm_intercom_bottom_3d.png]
PCBA 09 OMM 2.4 GHz Intercom & UCS Modul Bottom 3D (Dual-Engine)

*Abbildung 7.9b: PCBA 09 Bottom 3D (Dual-Engine OMB Lite) – Dedizierter ESP32-PICO-V3-02 Bluetooth Classic/BLE Co-Prozessor (U5) und Johanson 2450AT Chipantenne (ANT1) zur CoEx-freien Funkentkopplung.*

### 11.1 Technische Platinen-Kenndaten & Lagenaufbau
* **Abmessungen:** $60{,}0 \times 30{,}0 \times 1{,}0\,\text{mm}$ ($R = 2{,}5\,\text{mm}$ Kantenradius).
* **Lagenaufbau:** 2-Lagen FR-4 High-TG150, $1{,}0\,\text{mm}$ Materialstärke, $35\,\mu\text{m}$ Cu (1 oz), ENIG-Goldfinish (Electroless Nickel Immersion Gold).
* **Befestigung:** 4x M2-Montagelöcher ($\varnothing 2{,}2\,\text{mm}$) mit $52{,}0 \times 22{,}0\,\text{mm}$ Rastermaß für formschlüssige DIN 934 M2 Mutterntaschen im Gehäuse.

### 11.2 Bestückung & Schaltkreis-Architektur

1. **Host-Mikrocontroller (`U1`):**
   * **Espressif ESP32-C6-MINI-1U** (32-Bit RISC-V Single-Core @ 160 MHz, 512 kB SRAM, 4 MB Quad-SPI Flash, integrierte U.FL-Goldbuchse).
   * Unterstützt 2.4 GHz Wi-Fi 6 ($802.11\text{ax}$), IEEE 802.15.4 (deterministischer TDMA Mesh-Stack) und Bluetooth 5.3 LE / LE Audio LC3.
2. **Power-Management & Lade-IC (`U2`):**
   * **Texas Instruments BQ24075RGTR** (QFN-16 3x3mm) mit Dynamic Power Path Management (DPPM).
   * Unterbrechungsfreie Umschaltung zwischen USB-C 5V-Speisung (Bordnetz über Kassetten-Schlitten oder Powerbank) und dem internen 600-mAh-LiPo-Akku in $< 10\,\mu\text{s}$ ohne MCU-Reboot. Der interne Akku dient im Kassettenbetrieb als unterbrechungsfreie Stromversorgung (USV).
   * Einstellbarer Ladestrom ($500\,\text{mA}$), JEITA-konforme Temperaturüberwachung über NTC-Thermistor ($10\,\text{k}\Omega$).
3. **Audio-Frontend Stereo Codec (`U4`):**
   * **Everest Semi ES8388** (QFN-28 4x4mm): Ultra-Low-Power Stereo Audio Codec mit 24-Bit / 96 kHz I2S-Interface.
   * Getrennte linke und rechte Kopfhörer-Treiber ($2\times 45\,\text{mW}$ @ $16\,\Omega$ / $25\,\text{mW}$ @ $32\,\Omega$) für echten Stereo-Klang (A2DP-Musik, räumliche Navigationshinweise, LE Audio).
   * Rauscharmer Differenz-Mikrofon-Vorverstärker ($+0\dots +30\,\text{dB}$ Gain) mit programmierbarer interner `MICBIAS`-Erzeugung ($2{,}0\dots 2{,}8\,\text{V}$) für Schwanenhals- und Klebemikrofone.
4. **2.4-GHz-HF-Antennensystem & Dual-Engine:**
   * **Host MCU (`U1`):** Nutzt direkt den werkseitig integrierten U.FL-Goldport auf dem `ESP32-C6-MINI-1U` Modul. Über ein kurzes $50\,\text{mm}$ RG-178/1.13mm Mikro-Koaxialpigtail wird das Signal zur wasserdichten IP67 SMA-Bulkhead-Durchführung an der Gehäusestirnseite geführt. (Die frühere redundante Zweitbuchse auf der Leiterplatte wurde ersatzlos gelöscht).
   * **Helm-Default:** Im Helmbetrieb wird direkt die ultrakompakte $38\,\text{mm}$ kurze 2.4 GHz Rubber-Duck Stummelantenne aufgeschraubt (Rundstrahl-Helix, $+2{,}0\dots +2{,}5\,\text{dBi}$, null Helmbüffeln). Im Kassetten-Betrieb am Motorrad verbindet ein Koaxialkabel die SMA-Buchse mit einer fahrzeugfesten Außenantenne.
   * **Bluetooth Co-Prozessor (`U5`):** Der `ESP32-PICO-V3-02` arbeitet auf eine eigene Johanson 2450AT Keramik-Chipantenne (`ANT1`, SMD 3216) für Nahfeld-Kopplungen zum Smartphone oder Cockpit-Display.
5. **Bedienung & Sensorik:**
   * 4x taktile IP67-Mikrotaster (`SW1` bis `SW4`, C&K KMT0 / Alps SKRK) auf `F.Cu`.
   * 1x RGB Status-LED (`D1`, WS2812B-2020) zur Einkopplung in den Gehäuse-Lichtleiter.
6. **Schnittstellen & Steckverbinder:**
   * `J1`: Wasserdichte IP67 USB-C Buchse (16-Pin) bündig an der Stirnkante mit USBLC6-2SC6 TVS-ESD-Schutzarray (Laden unterwegs via Powerbank/Front-Node, WebUSB DFU Flashing, Kassetten-Einschubkontakt).
   * `J_HELMET`: 6-Pin JST-SH 1.0mm SMD Horizontal-Header (`SM06B-SRSS-TB`) auf `B.Cu` ($X=126{,}5, Y=99{,}75\,\text{mm}$ in KiCad bzw. $X_{\text{mod}} = 60{,}5\,\text{mm}$, Stecköffnung nach innen / $-X$) im hinteren Gehäuseabteil gegenüber USB-C. Führt reines, brummfreies Audio ins Helminnere.
   * `BAT1`: 2-polige JST-SH Micro-Buchse (`BM02B-SRSS-TB`) zum 1S LiPo Pouch-Akku (600 mAh mit integriertem PCM).

### 11.3 Vollständige GPIO-Pinbelegung (ESP32-C6-MINI-1U)

| Modul-Pad | ESP32-C6 GPIO | Netzname | Signal-Typ | Funktion / Hardware-Verbindung |
| :---: | :---: | :--- | :--- | :--- |
| **Pad 8** | **`GPIO 2`** | `BTN_PWR` | Digital In (Pullup) | SW1 (Power / MFB Taster, Low-aktiv, Boot-Pin) |
| **Pad 9** | **`GPIO 3`** | `BTN_MESH` | Digital In (Pullup) | SW2 (Mesh / Group Umschaltung, Low-aktiv) |
| **Pad 4** | **`GPIO 4`** | `BTN_VOL_UP` | Digital In (Pullup) | SW3 (Lautstärke +, Kanalwahl +, Low-aktiv) |
| **Pad 5** | **`GPIO 5`** | `BTN_VOL_DOWN` | Digital In (Pullup) | SW4 (Lautstärke -, Kanalwahl -, Low-aktiv) |
| **Pad 6** | **`GPIO 6`** | `WS2812_DATA` | Digital Out | D1 (WS2812B-2020 RGB Statusanzeige & Lichtleiter) |
| **Pad 7** | **`GPIO 7`** | `CHG_STAT` | Digital In (Pullup) | BQ24075 /STAT Ladezustandsanzeige (Low-aktiv) |
| **Pad 10** | **`GPIO 8`** | `I2C_SDA` | Open-Drain | ES8388 Register Control SDA (4.7k Pullup) |
| **Pad 11** | **`GPIO 9`** | `I2C_SCL` | Open-Drain | ES8388 Register Control SCL (4.7k Pullup) |
| **Pad 3** | **`GPIO 2 / PTT`**| `PTT_IO` | Digital In (Pullup) | Hardware-PTT-Eingang von J_HELMET Pin 6 / Lenkertaster |
| **Pad 21** | **`GPIO 19`** | `I2S_MCLK` | Digital Out | ES8388 Master Clock (12.288 MHz) |
| **Pad 22** | **`GPIO 20`** | `I2S_BCLK` | Digital Out | ES8388 Bit Clock (1.536 MHz) |
| **Pad 23** | **`GPIO 21`** | `I2S_WS` | Digital Out | ES8388 Frame Sync / Word Select (48 kHz) |
| **Pad 24** | **`GPIO 22`** | `I2S_DOUT` | Digital Out | ES8388 DAC Data Out (Stereo-Lautsprecher L/R) |
| **Pad 25** | **`GPIO 23`** | `I2S_DIN` | Digital In | ES8388 ADC Data In (Mikrofon) |
| **U.FL** | **RF 2.4G** | `RF_ANT` | 50 Ohm Koaxial | ESP32-C6 integrierte U.FL-Buchse -> Koax-Pigtail -> SMA-Durchführung |

### 11.4 Belegung des 16-Pin Multi-Use USB-C Steckverbinders (`J1`)

Der stirnseitige USB-C Port `J1` (`TYPE-C-31-M-12_IP67`) dient als universelle Schnittstelle für **Laden**, **WebUSB/DFU-Flashing** und den **Kassetten-Einschubkontakt**:

| USB-C Pins | Netzname | Signal-Typ | Funktion / Adapter-Verbindung |
| :---: | :--- | :--- | :--- |
| **A1, B12, A12, B1, SH** | `GND` / `PGND` | Power Ground | Pin 1 Kassetten-Header `J_AUDIO_PWR` & Schirmung: Führt Lade- & Betriebs-Rückstrom |
| **A4, B9, A9, B4** | `VBUS_5V` | Power In (+5V) | Pin 2 Kassetten-Header & USB-Ladekabel: 5V Speisung & BQ24075 USV-Akkuladung |
| **A6, B6 (`DP1`, `DP2`)** | `USB_DP` | USB 2.0 PHY | ESP32-C6 GPIO 13 (via TVS `D2`): **Nativer USB D+ für WebUSB / DFU Firmware-Flashing** |
| **A7, B7 (`DN1`, `DN2`)** | `USB_DN` | USB 2.0 PHY | ESP32-C6 GPIO 12 (via TVS `D2`): **Nativer USB D- für WebUSB / DFU Firmware-Flashing** |
| **A5 (`CC1`)** | `HP_OUT_L` | Audio Out | Pin 4 Kassetten-Header: Stereo Audio Links vom ES8388 `LOUT1` im Kassetten-Betrieb |
| **B5 (`CC2`)** | `HP_OUT_R` | Audio Out | Pin 5 Kassetten-Header: Stereo Audio Rechts vom ES8388 `ROUT1` im Kassetten-Betrieb |
| **A8 (`SBU1`)** | `MIC_IN+` | Audio In | Pin 7 Kassetten-Header: Mikrofonsignal zum ES8388 `MIC1P` im Kassetten-Betrieb |
| **B8 (`SBU2`)** | `AGND_SPK` | Analog Ground | Pin 3 & 6 Kassetten-Header: Stromloser Audio-Massebezug ($I = 0\,\text{mA}$) |

### 11.5 Belegung des 6-Pin Internen Helm-Audio & PTT Steckverbinders (`J_HELMET`)

Der auf der Platinenunterseite (`B.Cu`) platzierte 6-polige Header `J_HELMET` (JST-SH 1.0 mm, LCSC `C136657`) führt alle analogen Audio- und Steuersignale für den Helmeinsatz heraus. Durch die strikte Trennung von 5V Ladespannung (verbleibt ausschließlich auf USB-C `J1`) ist die Verbindung zu 100 % brumm- und störungsfrei:

| Pin # | Netzname | Signal-Typ | Ziel / Helm-Headset Peripherie | Elektrische Spezifikation |
| :---: | :--- | :--- | :--- | :--- |
| **1** | `HP_OUT_L` | Audio Out | Linker Helmlautsprecher (Tip 3.5mm Klinke) | ES8388 `LOUT1`, $45\,\text{mW}$ @ $16\,\Omega$, AC-gekoppelt |
| **2** | `HP_OUT_R` | Audio Out | Rechter Helmlautsprecher (Ring 3.5mm Klinke) | ES8388 `ROUT1`, $45\,\text{mW}$ @ $16\,\Omega$, AC-gekoppelt |
| **3** | `AGND_SPK` | Audio Ground | Lautsprecher-Masse (Sleeve 3.5mm Klinke) | Stromlose Analogmasse ($I = 0\,\text{mA}$), kein Ladestrom |
| **4** | `MIC_IN+` | Audio In | Mikrofon-Kapsel (2-Pin Micro-JST Pin 1) | ES8388 `MIC1P` mit programmierbarem `MICBIAS` (2.2V) |
| **5** | `AGND_MIC` | Mic Ground | Mikrofon-Rückleitung (2-Pin Micro-JST Pin 2) | Getrennte, rauscharme Vorverstärker-Masse |
| **6** | `BTN_PTT` | Digital In | Helm-PTT-Taster / Kinn-Klicker | ESP32-C6 GPIO 2, interner $45\,\text{k}\Omega$ Pullup, schaltet gegen GND |

---

## 12. PCBA 10: OMM 446 Analog & Digital PMR446 Intercom-Modul (`openmotorbridge_omm446_ucs`)

Die Platine **`PCBA 10`** ist das universelle Open-Source-Hardwaremodul für den lizenzfreien Jedermannfunk im 446-MHz-Band. Es löst das Dilemma unhandlicher Handfunkgeräte (Midland G9 Pro etc. passen physisch in keine $100 \times 50 \times 30\,\text{mm}$ Kassette) und teurer, unwirtschaftlicher Teardowns (z. B. Midland D-10 DMR) vollständig:
* **Formfaktor-Gleichheit:** Exakt identische Außenmaße ($60{,}0 \times 30{,}0 \times 1{,}0\,\text{mm}$) und Montagepunkte wie das 2.4-GHz-Modul `PCBA 09`.
* **Universal-Einsatz:** Passt mechanisch und elektrisch sowohl in standardisierte ECE 22.06 UCS-Helmmulden als auch in den Kassetten-Schlitten (`PCBA 03`) am Motorrad.
* **Dual-Mode HF-Funk:** Vollwertiges Analog-FM (16 PMR446 Kanäle, CTCSS/DCS) und Digital-DMR Tier I (16 digitale Kanäle, TDMA 4FSK, glasklare Sprache ohne Rauschen).

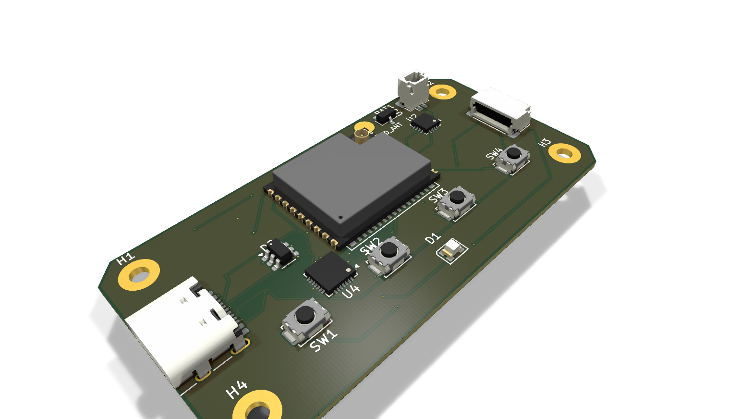
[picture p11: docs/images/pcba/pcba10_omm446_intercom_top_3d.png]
PCBA 10 OMM 446 PMR446 Intercom Modul Top 3D

*Abbildung 7.10a: PCBA 10 Top 3D (Aktuelles Routing & Placement) – ESP32-C6 Host-MCU (U1), ES8388 Audio-Codec (U4), BQ24075 PMIC (U2), ME6211 3.3V LDO (U5), IP67 USB-C (J1) und 4-Tasten-Reihe.*

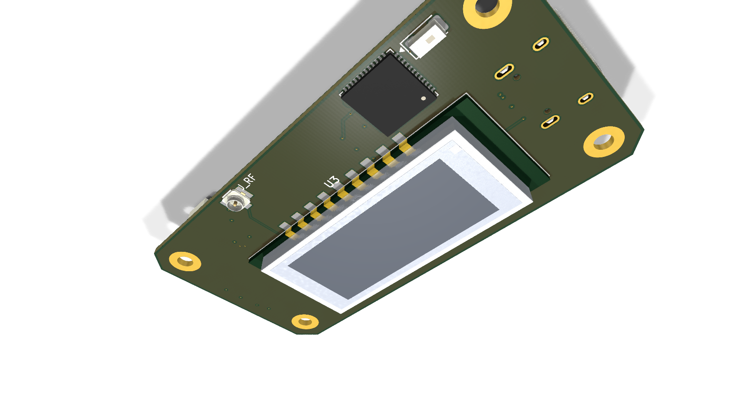
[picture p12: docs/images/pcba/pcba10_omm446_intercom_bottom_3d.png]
PCBA 10 OMM 446 PMR446 Intercom Modul Bottom 3D

*Abbildung 7.10b: PCBA 10 Bottom 3D (NiceRF SA818 & Dual-Engine) – NiceRF SA818-DMR Transceiver (U3), ESP32-PICO-V3-02 Bluetooth Co-Prozessor (U6) und Johanson 2450AT Chipantenne (ANT1).*

### 12.1 Technische Platinen-Kenndaten & Lagenaufbau
* **Abmessungen:** $60{,}0 \times 30{,}0 \times 1{,}0\,\text{mm}$ ($R = 2{,}5\,\text{mm}$ Kantenradius).
* **Lagenaufbau:** 4-Lagen FR-4 High-TG150, $1{,}0\,\text{mm}$ Materialstärke, $35\,\mu\text{m}$ Cu (Außenlagen) / $17{,}5\,\mu\text{m}$ Cu (Innenlagen für GND-Shielding und Power-Planes), ENIG-Goldfinish.
* **Befestigung:** 4x M2-Montagelöcher ($\varnothing 2{,}2\,\text{mm}$) mit $52{,}0 \times 22{,}0\,\text{mm}$ Rastermaß für formschlüssige DIN 934 M2 Mutterntaschen im 3D-Druck-Gehäuse.

### 12.2 Bestückung & Schaltkreis-Architektur

1. **Dual-Mode Funktransceiver-Modul (`U3`):**
   * **NiceRF SA818-DMR** (Ultrakompaktes $446\,\text{MHz}$ Transceiver-Modul mit integriertem DSP, CMX7141 Baseband und PA):
     * **Analog PMR446:** 16 Kanäle ($446{,}00625\dots 446{,}19375\,\text{MHz}$), $12{,}5\,\text{kHz}$ Kanalraster, 38 CTCSS-Subtöne und 83 DCS-Digitalcodes.
     * **Digital DMR Tier I:** ETSI TS 102 361-1 konform, 2-Slot TDMA 4FSK Modulation, Color Code 1–16, Direktmodus (DMO) ohne Repeater.
   * **Dual-Power Umschaltung (Software- & Hardware-gesteuert):**
     * **0,2 W ERP (Helm-Modus / SAR-Safe):** Aktiv bei Standalone-Betrieb in der Helmmulde. Minimiert HF-Absorption am Kopf und thermische Verlustleistung (Reichweite ca. 1,5–2,5 km).
     * **0,5 W ERP (Bike-Modus / High-Power):** Aktiv bei Erkennung des Kassetten-Schlittens via I2C/GPIO. Schöpft das gesetzliche PMR446-Limit voll aus (Reichweite ca. 3–6 km im Freifeld).
2. **Host-Mikrocontroller & Steuer-MCU (`U1`):**
   * **Espressif ESP32-C6-MINI-1U** (32-Bit RISC-V Single-Core @ 160 MHz):
     * Steuert das SA818-DMR per High-Speed UART über AT-Kommandos (Frequenz, CTCSS, DMR Color Code, Squelch, RF Power).
     * Stellt Bluetooth 5.3 LE zur Verfügung für drahtlose Konfiguration via Smartphone-App und WebBluetooth.
     * Unterstützt WebUSB DFU Flashing über den USB-C Port.
3. **Power-Management mit unterbrechungsfreier USV (`U2`):**
   * **Texas Instruments BQ24075RGTR** mit Dynamic Power Path Management (DPPM).
   * Ermöglicht das **Laden während des Betriebs** über USB-C (5V Bordnetz / Powerbank) bei gleichzeitig stabiler 3.3V- und PA-Speisung.
   * Fällt die externe 5V-Versorgung ab (z. B. Zündung aus oder Kassettenwechsel), übernimmt der interne 600-mAh-LiPo-Akku unterbrechungsfrei in $< 10\,\mu\text{s}$ als USV (Pufferzeit ca. 6–8 Stunden reiner Funkempfang).
4. **Audio-Frontend Stereo Codec (`U4`):**
   * **Everest Semi ES8388**: Verarbeitet das Audio-Signal des SA818-DMR analog und digital.
   * Stereo Headphone-Verstärker für Helm-Lautsprecher.
   * Differenzieller Mikrofon-Eingang mit zuschaltbarem Windgeräuschfilter und integriertem Noise-Gate.
5. **Antennensystem (Kompakte Wendel-Stummelantenne & externer Koax):**
   * **Dual-Engine HF-Entkopplung:**
     - **PMR/DMR HF-Pfad:** Der HF-Ausgang des NiceRF SA818-DMR speist über ein Tiefpass-/Bandpassfilter die U.FL-Buchse `J_RF` (`B.Cu`) sowie das parallele Lötpad `PAD_ANT` (`F.Cu`) am oberen Platinenrand ($X = 110{,}5, Y = 87{,}0\,\text{mm}$).
     - Ein kurzes $50\,\text{mm}$ Mikro-Koaxialpigtail (RG-178 / 1.13mm) führt von `J_RF` zur wasserdichten SMA-Bulkhead-Buchse (IP67 mit EPDM O-Ring) an der Gehäusestirnseite.
     - **Helm-Default:** Im Helmbetrieb wird die $48\,\text{mm}$ kurze 446 MHz Wendel-Stummelantenne aufgeschraubt (ca. $0\dots +1{,}5\,\text{dBi}$, $1{,}5\dots 2{,}5\,\text{km}$ Reichweite). Im Kassettenbetrieb im Pod führt ein Koaxialkabel zur Außenantenne am Motorrad ($3\dots 6\,\text{km}$).
     - **Bluetooth Co-Prozessor (`U6`):** Der `ESP32-PICO-V3-02` arbeitet auf seine eigene Johanson 2450AT Keramik-Chipantenne (`ANT1`) für Nahfeld-Kopplungen.
6. **Bedienelemente & Steckverbinder:**
   * 4x taktile Mikrotaster (`SW1` bis `SW4`): PTT (Push-to-Talk / MFB), Mode (Analog/DMR Toggle), Ch+, Ch-.
   * 1x WS2812B-2020 RGB Status-LED (`D1`, RX Grün, TX Rot, DMR Blau, Chg Gelb).
   * `J1`: Wasserdichte IP67 USB-C Buchse (16-Pin) für 5V Laden, WebUSB DFU und Kassetten-Einschub.
   * `J_HELMET`: 6-Pin JST-SH 1.0mm SMD Horizontal-Header (`SM06B-SRSS-TB`) auf `B.Cu` ($X=126{,}5, Y=99{,}75\,\text{mm}$ in KiCad, Stecköffnung nach innen / $-X$) – identische Belegung und Platzierung wie PCBA 09.
   * `BAT1`: 2-polige JST-SH Micro-Buchse (`BM02B-SRSS-TB`) zum 1S LiPo Pouch-Akku (600 mAh mit integriertem PCM).

### 12.3 Vollständige GPIO-Pinbelegung (ESP32-C6 zu SA818-DMR & Peripherie)

| Modul-Pad | ESP32-C6 GPIO | Netzname | Signal-Typ | Funktion / Hardware-Verbindung |
| :---: | :---: | :--- | :--- | :--- |
| **Pad 8** | **`GPIO 2`** | `BTN_PTT` | Digital In (Pullup) | Taster SW1: Push-To-Talk / MFB (Low-aktiv, Boot-Pin) |
| **Pad 9** | **`GPIO 3`** | `BTN_MODE` | Digital In (Pullup) | Taster SW2: Analog FM / Digital DMR Toggle |
| **Pad 4** | **`GPIO 4`** | `BTN_CH_UP` | Digital In (Pullup) | Taster SW3: Kanalwahl Aufwärts (CH 1–16) |
| **Pad 5** | **`GPIO 5`** | `BTN_CH_DOWN` | Digital In (Pullup) | Taster SW4: Kanalwahl Abwärts (CH 16–1) |
| **Pad 6** | **`GPIO 6`** | `WS2812_DATA` | Digital Out | D1 (WS2812B RGB Statusanzeige RX/TX/DMR) |
| **Pad 7** | **`GPIO 7`** | `CHG_STAT` | Digital In (Pullup) | BQ24075 /STAT Ladezustand (Low-aktiv) |
| **Pad 10** | **`GPIO 8`** | `I2C_SDA` | Open-Drain | ES8388 Register SDA (4.7k Pullup) |
| **Pad 11** | **`GPIO 9`** | `I2C_SCL` | Open-Drain | ES8388 Register SCL (4.7k Pullup) |
| **Pad 14** | **`GPIO 12`** | `USB_DN` | USB 2.0 PHY | USB-C D- (WebUSB Firmware-Flashing & DFU via D2) |
| **Pad 15** | **`GPIO 13`** | `USB_DP` | USB 2.0 PHY | USB-C D+ (WebUSB Firmware-Flashing & DFU via D2) |
| **Pad 16** | **`GPIO 14`** | `SA818_TXD` | Digital Out (UART) | ESP32 TX -> SA818-DMR RXD (AT-Steuerbefehle @ 9600 Bd) |
| **Pad 17** | **`GPIO 15`** | `SA818_RXD` | Digital In (UART) | ESP32 RX <- SA818-DMR TXD (Status & Telemetrie) |
| **Pad 18** | **`GPIO 16`** | `SA818_PTT` | Digital Out | SA818 PTT Steuerung (Low = Sendebetrieb aktiv) |
| **Pad 19** | **`GPIO 17`** | `SA818_SQL` | Digital In | SA818 Squelch-Ausgang (Low = Träger erkannt / Empfang) |
| **Pad 20** | **`GPIO 18`** | `SA818_PWR_HL` | Digital Out | SA818 RF Power Select: Low = 0.2W (Helm), High = 0.5W (Bike) |
| **Pad 21** | **`GPIO 19`** | `I2S_MCLK` | Digital Out | ES8388 Master Clock (12.288 MHz) |
| **Pad 22** | **`GPIO 20`** | `I2S_BCLK` | Digital Out | ES8388 Bit Clock (1.536 MHz) |
| **Pad 23** | **`GPIO 21`** | `I2S_WS` | Digital Out | ES8388 Frame Sync (48 kHz) |
| **Pad 24** | **`GPIO 22`** | `I2S_DOUT` | Digital Out | ES8388 DAC Out (Lautsprecher / Audio zu Zentralbox) |
| **Pad 25** | **`GPIO 23`** | `I2S_DIN` | Digital In | ES8388 ADC In (Mikrofon von Helm / Central DSP) |
| **J_RF** | **RF 446M** | `RF_ANT` | 50 Ohm Koaxial | U.FL Buchse (`B.Cu`) -> Koax-Pigtail -> IP67 SMA-Durchführung |

### 12.4 Belegung des 16-Pin Multi-Use USB-C Steckverbinders (`J1`)

Identisch beschaltet wie bei PCBA 09: Dient als universelle Schnittstelle für **Laden (5V Bordnetz / Powerbank)**, **WebUSB/DFU-Flashing** und den **Kassetten-Einschubkontakt** im Smart Cartridge (`PCBA 03`).

### 12.5 Belegung des 6-Pin Internen Helm-Audio & PTT Steckverbinders (`J_HELMET`)

Der Header `J_HELMET` auf `B.Cu` ist **100 % anschlusskompatibel zu PCBA 09**:

| Pin # | Netzname | Signal-Typ | Ziel / Helm-Headset Peripherie | Elektrische Spezifikation |
| :---: | :--- | :--- | :--- | :--- |
| **1** | `HP_OUT_L` | Audio Out | Linker Helmlautsprecher (Tip 3.5mm Klinke) | ES8388 `LOUT1`, $45\,\text{mW}$ @ $16\,\Omega$, AC-gekoppelt |
| **2** | `HP_OUT_R` | Audio Out | Rechter Helmlautsprecher (Ring 3.5mm Klinke) | ES8388 `ROUT1`, $45\,\text{mW}$ @ $16\,\Omega$, AC-gekoppelt |
| **3** | `AGND_SPK` | Audio Ground | Lautsprecher-Masse (Sleeve 3.5mm Klinke) | Stromlose Analogmasse ($I = 0\,\text{mA}$), kein Ladestrom |
| **4** | `MIC_IN+` | Audio In | Mikrofon-Kapsel (2-Pin Micro-JST Pin 1) | ES8388 `MIC1P` mit programmierbarem `MICBIAS` (2.2V) |
| **5** | `AGND_MIC` | Mic Ground | Mikrofon-Rückleitung (2-Pin Micro-JST Pin 2) | Getrennte, rauscharme Vorverstärker-Masse |
| **6** | `BTN_PTT` | Digital In | Helm-PTT-Taster / Kinn-Klicker | ESP32-C6 GPIO 2, interner $45\,\text{k}\Omega$ Pullup, schaltet gegen GND |

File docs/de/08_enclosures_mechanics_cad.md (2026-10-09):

# 08 - Mechanische Gehäuse, CAD-Konstruktion & Dichtungssystem (Alle Baugruppen)

*(Hinweis: Sämtliche CAD- und 3D-Baugruppenansichten werden im Zuge der finalen Render-Phase aktualisiert).*

Dieses Dokument spezifiziert die mechanische Konstruktion, das Thermomanagement, das IP67/IP69K-Gehäusedesign, die Kinematik des Auto-Eject-Schnellwechselsystems sowie alle CAD- und STL-Modelle aller Gehäuse-Baugruppen der OpenMotorBridge v9.6:
1. **Zentrale Steuerbox (Typ A):** 3-teiliges Sandwich-Gehäuse mit Zwischenboden, integrierter Akku-Wanne, stirnseitiger Schnittstellenleiste (Deutsch DTM-12 Flansch, Taster SW1, USB-C, RGB-LED), integrierter Deckeltasche ($85{,}0 \times 18{,}0 \times 1{,}2\,\text{mm}$) für LoRa-868-Flexantenne (Taoglas FXP895), Unterwannen-Bodenkammer ($12{,}0 \times 12{,}0 \times 0{,}8\,\text{mm}$) für UWB-Flexantenne (Taoglas FXUWB10), optionalem rückseitigen SMA-Antennendurchgang und planarem 4-Layer Kupfer-Wärmespreader.
2. **Modulares Satelliten-Pod- & Wechselsystem (Typ B):** Baugleiches 5-seitiges Monocoque-Schachtgehäuse für beide Satelliten-Pods (Pod 1 & 2 Audio/Intercom, 2x symmetrisch) mit modularen Wechselkassetten (Sena SPIDER X Slim, Cardo Packtalk Edge, OMM 2.4 GHz Swap Cartridge, Midland, Dry Box), glatter geschlossener IP67-Außenhaut (ohne störende Antennen-Radomlöcher), $120^\circ$-V-Nut Rohrbett, Dual-Port M8/USB-C, Poka-Yoke Nut-und-Feder-Führung, federbelastetem Auto-Eject und unsichtbarem Neodym-Magnet-Diebstahlschutz.
3. **Universal Front-Knoten (Typ C):** Ultrakompakter Cockpit- & Sensor-Hub ($98{,}0 \times 68{,}0 \times 25{,}0\,\text{mm}$) für die vergrößerte $82 \times 50\,\text{mm}$ 4-Lagen PCBA 05 mit **4-in-1 Universal-Befestigungssystem** (AMPS, Rohrbügel-Prisma, Silentblöcke, 3M Dual-Lock), integrierter Bodenkammer für UWB-Backbone (FXUWB10), J12 Qwiic Sensor-Hub (u-blox SAM-M10Q GNSS-Patch, TI TMP117 Präzisionsthermometer, TI OPT3001 Lichtsensor) im Fahrtwindeinlass, getrennten EPDM-Kabelkämmen für USB (Süd) und Fahrzeugleitungen (Nord), Dual-SW3526 20W USB-PD und Knowles MEMS Akustikkanal.
4. **2-in-1 LoRa Smart-Keyfob & Pager (Typ D):** Ultrakompakter Taschenbegleiter ($58{,}0 \times 34{,}0 \times 13{,}0\,\text{mm}$) aus PA12-MJF mit umlaufendem TPU-Kantenschutz, integriertem N52-Neodym-Auswerferschlüssel, $0{,}5\,\text{mm}$ Mu-Metall-Flussschirmung, MagSafe/Qi-Induktionsladeaufnahme, LRA-Haptikmotor und drahtlosem SX1262 LoRa/BLE Alarm-Pager.
5. **Fahrzeugspezifische Referenz-Montagekits (Zero-Drill):** Vollständig konstruierte, zerstörungsfreie Bolt-On Montagekits für CVO Road Glide ST (Kit 1), Road King Special (Kit 2), Classic Bagger & Cruiser (Kit 3) sowie Adventure & Touring Enduros (BMW GS, KTM Adventure, Africa Twin - Kit 4 mit minimalem Unterbrücken-Radarträger).

---

## 1. Gehäuse Typ A: Zentrale Steuerbox (3-Teiliges Sandwich-Design)

Das Basisgehäuse der Zentralbox ist als modulares, 3-teiliges IP67/IP69K-Sandwichgehäuse aus **PA12 (MJF-Verfahren)** oder **Aluminium-Druckguss** konzipiert, das speziell für raue Motorrad-Bedingungen (Vibrationen bis $20\,\text{g}$, Spritzwasser, Hitzestau unter der Sitzbank) ausgelegt ist:

- **Außenabmessungen:** $110{,}0 \times 74{,}0 \times 38{,}0\,\text{mm}$ (L x B x H; Unterwanne $17{,}0\,\text{mm}$, Oberwanne $15{,}0\,\text{mm}$, Deckel $6{,}0\,\text{mm}$).
- **Befestigung:** 4x integrierte Ecklaschen an der Unterwanne mit **Lochabstand $128{,}0 \times 56{,}0\,\text{mm}$** für schwingungsdämpfende **M4 Silentblöcke (Shore 50A EPDM)** zur Entkopplung hochfrequenter Motorvibrationen.
- **Lichte Innenmaße:** $105{,}0 \times 69{,}0 \times 32{,}0\,\text{mm}$ (optimiert für die $85{,}0 \times 55{,}0\,\text{mm}$ 4-Layer Hauptplatine PCBA 01 mit symmetrischem Randabstand von $10{,}0\,\text{mm}$ in X und $7{,}0\,\text{mm}$ in Y).
- **Material & Fertigung:** PA12 im HP Multi Jet Fusion (MJF) 3D-Druck (min. $2{,}5\dots 3{,}0\,\text{mm}$ Wandstärke), kugelgestrahlt, im Heißbad chemisch geglättet und hydrophob versiegelt.
- **Schutzart:** IP67 / IP69K (strahlwasser- und tauchdicht bis $1\,\text{m}$ Wassertiefe sowie dampfstrahlbeständig).
- **100% Lötkolben-Freie Montage & Beliebig Oft Verschraubbar:** Alle Schraubverbindungen nutzen ausnahmslos formschlüssig ins PA12 eingedruckte **DIN 934 Sechskantmutter-Taschen** (M2, M2.5, M3, M4, M5). Selbstschneidende Gewinde in Kunststoff sind vollständig eliminiert: Gehäuse können beliebig oft geöffnet und wieder verschraubt werden, ohne dass Gewinde ausleiern oder Gehäuseteile nach einmaliger Demontage unbrauchbar werden. Messing-Gewindeeinsätze sind vollständig eliminiert.

### 1.1 3D-CAD-Modell & 3-Schichten-Sandwichaufbau

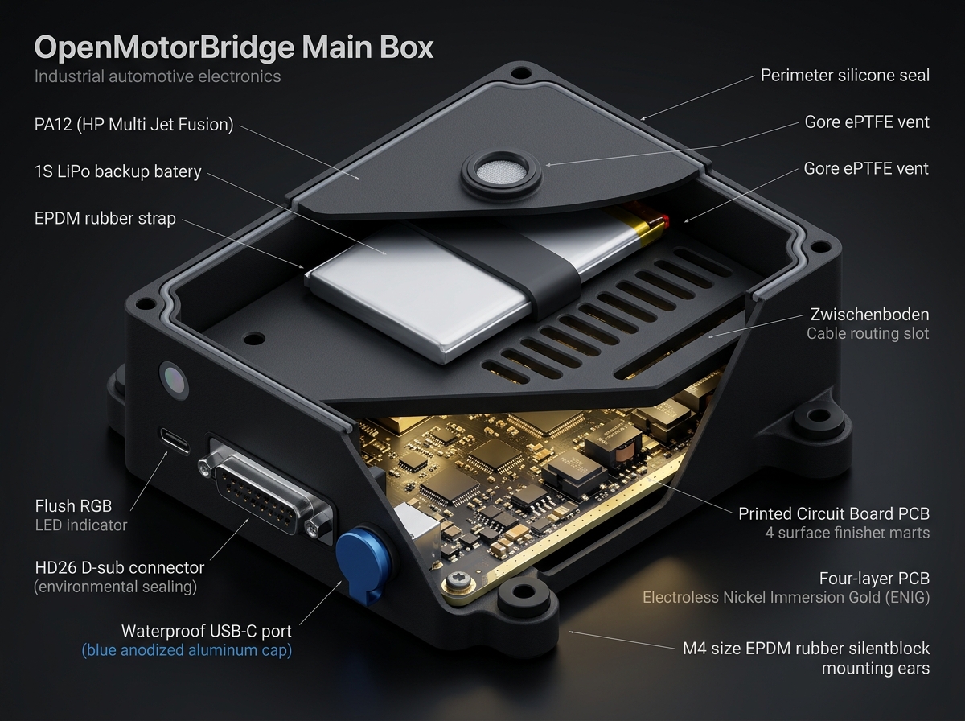
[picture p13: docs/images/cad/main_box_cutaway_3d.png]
OpenMotorBridge Zentralbox 3D Anschnitt CAD


*Abbildung 8.1: Photorealistischer 3D-CAD-Schräganschnitt der zentralen Steuerbox. Sichtbar sind die 3 Schichten im geschlossenen Verbund: Unterwanne mit 4-Layer-Platine (ENIG) auf M2.5 Dämpfern, Zwischenboden mit 11 Konvektionsschlitzen, oberes Akku-Fach mit 1S LiPo-USV-Batterie und EPDM-Spannband, Deutsch DTM-12 Flansch, Taster SW1, USB-C Servicekappe sowie Deckel mit Gore-Membran.*

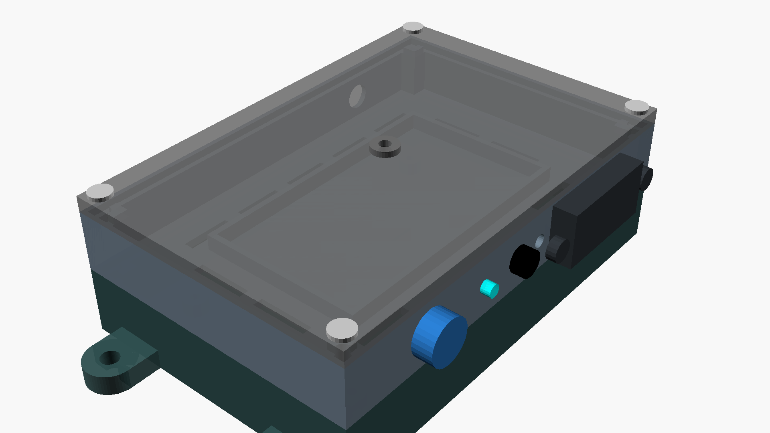
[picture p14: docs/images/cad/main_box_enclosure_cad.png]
OpenMotorBridge Zentralbox 3-Teiliges Sandwich-Gehäuse IP67


*Abbildung 8.2: 3D-CAD-Konstruktionsübersicht der zentralen Steuerbox (Typ A).*

```
+------------------------------------------------------------+  ^
| 1. GEHÄUSEDECKEL (6,0 mm Höhe / 3,0 mm Wandstärke)         |  |
|    * Gore ePTFE Druckausgleichsmembran (Ø 7,0 mm)          |  | 38,0 mm
|    * Umlaufende Nut mit Shore 40A Silikon-Profildichtung   |  | Gesamt-
|    * Integrierte Deckeltasche (85 x 18 x 1,2 mm) für       |  | höhe
|      Taoglas FXP895 LoRa 868 MHz Flexantenne & U.FL-Nut   |  |
|    * 100% geschlossener Deckel (>1,8 mm Wandung zum Äußern)|  |
+------------------------------------------------------------+  |
| 2. OBERWANNE MIT ZWISCHENBODEN (15,0 mm Höhe)              |  |
|    * Vordere Stirnwand (Alle Anschlüsse & Anzeige):        |  |
|      - Deutsch DTM-12 Flansch (Automotive Haupt-Kabelbaum) |  |
|      - Taster SW1 (Silikon-Dichtkappe, Pairing & Reset)    |  |
|      - Wasserdichter USB-C Service-Port (Alu-Schraubkappe) |  |
|      - Diffuser PMMA-Lichtleiter (Ø 3,2 mm) für WS2812B RGB|  |
|    * Hintere Stirnwand:                                    |  |
|      - Optionaler SMA-Antennenport (Ø 6,5 mm, Ø 9,5 mm Nut)|  |
|    * Oberes Fach (auf dem Zwischenboden):                  |  |
|      - 1S LiPo-Pufferakku (68x39x5.0mm, 2.200 mAh)         |  |
|      - EPDM-Gummispannband zur vibrationsfesten Fixierung  |  |
|    * Zwischenboden (Optimierte Zirkulationsebene):         |  |
|      - 25,0 x 4,0 mm Kabeldurchbruchsschlitz               |  |
|      - 11x Konvektions- & Druckausgleichsschlitze          |  |
+------------------------------------------------------------+  |
| 3. UNTERWANNE (17,0 mm Höhe - Geschlossene Monocoque-Wanne)|  |
|    * 4-Layer Hauptplatine (85 x 55 mm) auf M2.5 Standdomen |  |
|      (77 x 47 mm Lochabstand, DIN 934 M2.5 Mutterntaschen) |  |
|    * Integrierte Antennentasche (12 x 12 x 0,8 mm) im Boden|  |
|      mit U.FL-Kabelführung für Taoglas FXUWB10 UWB Ch. 5   |  |
|    * Formschlüssige DIN 934 M3 Sechskant-Nut-Pockets       |  |
|    * 4x M4 Silentblock-Befestigungsohren (vibrationsfest)  |  |
|    * 100% geschlossener PA12-Wannenboden (>2,2 mm Wandung) |  |
+------------------------------------------------------------+  v
```

### 1.2 3D-Explosionsdarstellung & Schichtaufbau (1:1:1 CAD Fitting)

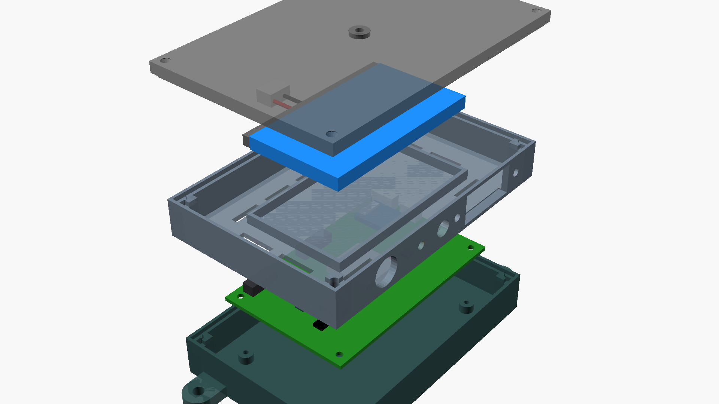
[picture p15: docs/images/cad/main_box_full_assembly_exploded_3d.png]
OpenMotorBridge Zentralbox Exploded 3D CAD Fitting


*Abbildung 8.3: 1:1:1 euklidische CAD-Explosionsdarstellung der Zentralbox entlang der vertikalen Z-Achse.*

### 1.3 3D-Röntgenansicht & Zusammenbau-Fitting

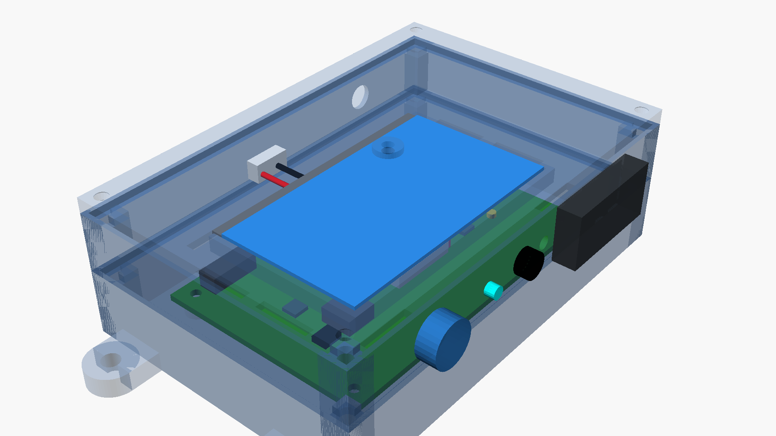
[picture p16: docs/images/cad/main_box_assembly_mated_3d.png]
OpenMotorBridge Zentralbox Mated 3D X-Ray CAD Fitting


*Abbildung 8.4: Transparente 3D-Röntgenansicht der vollständig geschlossenen Zentralbox. Erkennbar sind die spielfreien Bauteilfreiräume, die geschützte Akku-Lagerung auf dem Zwischenboden, die durchgängige Konvektion über die 11 Zwischenbodenschlitze und der scheuerfreie Kabelverlauf zum Deutsch DTM-12 Flansch.*

### 1.4 Maßstabsgetreuer Längs- & Querschnitt (X-Z Thermik & Y-Z Kabelführung)

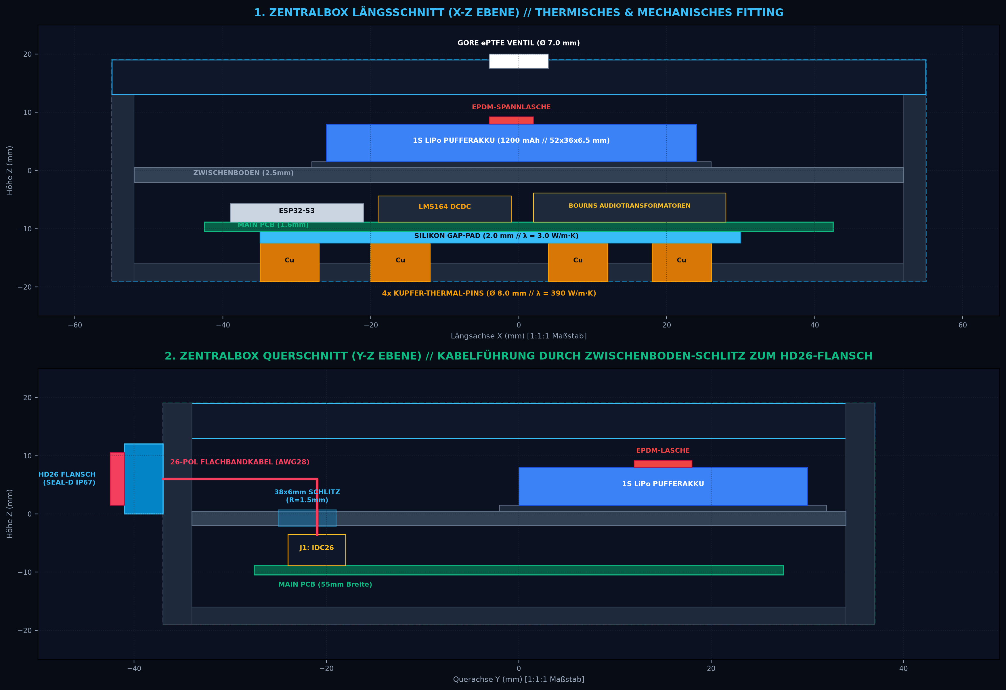
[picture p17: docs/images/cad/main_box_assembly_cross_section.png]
OpenMotorBridge Zentralbox Cross Sections


*Abbildung 8.5: Exakte 2D-Schnittansichten der Zentralbox (X-Z und Y-Z Ebenen).*

---

## 2. Thermomanagement & Planare PCB-Entwärmung (Kupferbolzenfrei)

Die Gesamtabwärme der Zentralbox liegt im normalen Fahrbetrieb bei lediglich **$\approx 1{,}5\,\text{W}$** (Peak bei maximaler Schnellladung: $2{,}45\,\text{W}$).

```
       4-LAYER LEITERPLATTE (PLANARER KUPFER-WÄRMESPREADER)
+--------------------------------------------------------+
| [ LM5164 Buck ]     [ BQ24075 UPS ]     [ ESP32-S3 ]   | <-- Bauelemente (SMD)
|   (100V DCDC)       (Power-Path)        (Dual-Core)    |
+--------------------------------------------------------+
| ####################################################### | <-- Layer 2: Durchgehende Solid GND Plane
+--------------------------------------------------------+
| ####################################################### | <-- Layer 3: Split Power / GND Planes
+--------------------------+-----------------------------+     (JLC04161H-7628 Standard, 93.5 cm² Fläche)
                           |
 +-------------------------v-----------------------------+
 | 11x ZWISCHENBODEN-KONVEKTIONSSCHLITZE & INNENLUFT     | <-- Freie Zirkulation in 210 cm³
 | (Wärme verteilt sich homogen im gesamten Gehäuse)     |     Luftvolumen & Gore ePTFE-Vent
 +-------------------------+-----------------------------+
                           v
          Abgabe über PA12-Gehäuseoberfläche (300 cm²) an Fahrtwind
```

1. **Planare 4-Layer PCB-Entwärmung ($85 \times 55\,\text{mm}$):** Die durchgehenden Kupfer-Innenlagen der FR4-Platine (JLC04161H-7628 Standard mit $17{,}5\,\mu\text{m}$ bzw. optional $35\,\mu\text{m}$) leiten die geringe Abwärme von $\approx 1{,}5\,\text{W}$ blitzschnell ab ($\lambda = 390\,\text{W/(m}\cdot\text{K)}$) und verteilen sie homogen über die gesamte Platinenfläche - ganz ohne mechanische Kühlkörper oder Kupferbolzen.
2. **11x Optimierte Konvektionsschlitze im Zwischenboden:** 5 Schlitze an der Rückkante ($Y = 58\,\text{mm}$), 4 an den Flanken und 2 an der Front lassen die Luft ungehindert in die Deckelkammer aufsteigen.
3. **Thermische Sicherheitsmargen im Extrem-Stresstest (Stau bei $45\,^\circ\text{C}$ Hitze + $13\,^\circ\text{C}$ Motorwärme = $58\,^\circ\text{C}$ unter Sitz):**
   * **LM5164-Q1:** $T_j = 93{,}8\,^\circ\text{C}$ (Zulässig bis $+150\,^\circ\text{C}$ $\rightarrow$ $+56{,}2\,^\circ\text{C}$ Reserve).
   * **ESP32-S3:** $T_j = 90{,}2\,^\circ\text{C}$ (Zulässig bis $+105\,^\circ\text{C}$ $\rightarrow$ $+14{,}8\,^\circ\text{C}$ Reserve).
   * **3.3V LDO:** $T_j = 110{,}4\,^\circ\text{C}$ (Zulässig bis $+125\,^\circ\text{C}$).
   * **1S LiPo Akku:** Verbleibt in der oberen Kammer sicher unter $60\,^\circ\text{C}$ (JEITA-NTC pausiert Ladevorgang bei $> 45\,^\circ\text{C}$).

### 2.2 Oberwanne: 1S LiPo-Akkuaufnahme & Zwischenboden-Durchführungen
* **Integrierte LiPo-Akkutasche:** Auf der Oberseite des Zwischenbodens sitzt eine formschlüssige Aussparung ($68{,}0 \times 39{,}0 \times 5{,}0\,\text{mm}$) für eine ultra-flache **2.200 mAh 1S LiPo-Pufferzelle** (Typ 504068 oder 503870). Durch die gezielte Vergrößerung der horizontalen Grundfläche statt der Bauhöhe bleibt die gesamte Gehäusehöhe der Zentralbox strikt bei **$38{,}0\,\text{mm}$**, sodass unter der Motorradsitzbank kein einziger Millimeter Freigang verloren geht.
* **100 % freier Querschnitt aller 11 Konvektionsschlitze:** Das Akkubett ist zentral bei $X = 17{,}0\dots 88{,}0\,\text{mm}$ und $Y = 13{,}0\dots 55{,}0\,\text{mm}$ platziert. Dadurch halten alle 11 Lüftungsschlitze (5 an der Rückwand, 4 an den Flanken, 2 an der Front) mindestens $2{,}5\dots 4{,}5\,\text{mm}$ Randabstand ein. Die Kaminwirkung und Innenluft-Zirkulation für die Abwärme von LM5164-Q1 und BQ24075 im Unterdeck bleibt uneingeschränkt erhalten.
* **Vibrationssicherung:** Eine $1{,}0\,\text{mm}$ dämpfende EPDM-Schaumstoffmatte an der Unterseite und ein quer verlaufendes EPDM-Gummispannband ($40 \times 12\,\text{mm}$) über seitliche Einhängenocken halten die Zelle auch bei $20\,\text{g}$ Stößen absolut spielfrei.
* **Molex Micro-Fit 3.0 Akkuanschluss (`J_BAT`):**
  * Pin 1: `VBAT+` ($+3{,}7\,\text{V}$ LiPo Pluspol über BQ24075)
  * Pin 2: `GND` (LiPo Masse mit integriertem Murata 10k NTC Temperaturfühler für JEITA-Ladeüberwachung)
* **Kabeldurchbruch & Zwischenboden-Führung:**
  * Großzügiger Front-Kabeldurchbruch ($25{,}0 \times 4{,}0\,\text{mm}$ bei $Y = 4\dots 8\,\text{mm}$) mit beidseitig verrundeten Kanten ($R = 1{,}5\,\text{mm}$) liegt $5{,}0\,\text{mm}$ vor der Akkutasche.
  * Führt die Akku-Silikonleitungen knickfrei nach unten auf den `J_BAT`-Header sowie die Leitungen von der Hauptplatine zum DTM-12-Flansch und Taster SW1 in der Stirnwand.

---

## 3. Stirnseitige Anschlüsse, Antennen-Aufnahmen & Rückwand-Option

```
                  VORDERE STIRNWAND DER OBERWANNE
+-------------------------------------------------------------+
| +------------+  +--------+  +----------+  +---------------+ |
| | 1. USB-C   |  | 2. RGB |  | 3. SW1   |  | 4. Deutsch    | |
| |    Service |  |    LED |  |    Pair/ |  |    DTM-12     | |
| |    Alukappe|  |  Ø3.2mm|  |    Reset |  |    Flansch    | |
| +------------+  +--------+  +----------+  +---------------+ |
+-------------------------------------------------------------+
```

1. **Deutsch DTM-12 Flansch (Haupt-Kabelbaum):** Automotive-Flansch (Deutsch DTM13-12PA) mit integrierter Silikondichtung und 2x M3-Verschraubung ($28{,}0\,\text{mm}$ Lochabstand). Verbindet intern über `J1` (2x06 Box-Header, 2,54 mm Raster) die 12 zentralen Fahrzeugadern für die Peitschen 1 bis 4: Peitsche 1 (Pod 1: +12V geschaltet, GND), Peitsche 2 (Pod 2: +12V geschaltet, GND), Peitsche 3 (Heck-Radar: +12V geschaltet, GND; Telemetrie 100% drahtlos via UWB) und Peitsche 4 (Bordnetz & CAN: KL30, KL15, GND, CAN-H, CAN-L, CHASSIS_EARTH).
2. **Taster SW1 (`SW_PAIR_RESET`):** Wasserdichter IP67-Minitaster mit Silikon-Dichtkappe und M7-Gewindehülse. Dient dem drahtlosen UWB-Pairing neuer Wechselkassetten (3s Betätigung) sowie dem vollständigen Werksreset & NVS Key Purge (10s Betätigung).
3. **USB-C Service-Port:** Wasserdichte Rundflansch-Buchse mit unverlierbarer blau eloxierter Aluminium-Schraubkappe und EPDM-O-Ring für Firmware-Updates, ESP-IDF Telemetrie und Notfall-Diagnose.
4. **RGB-Status-LED Sichtfenster:** Diffuser PMMA-Linsenkörper ($\varnothing\,3{,}2\,\text{mm}$) mit umlaufendem O-Ring, der das Licht der onboard WS2812B RGB-LED direkt auf die Frontblende spiegelt (Zustandsanzeige: Grün = Betrieb/Mesh OK, Blau = BT Audio Stream, Orange = Warnung/Radar aktiv, Rot = Sabotage/Alarm).

### 3.1 Integrierte Antennen-Aufnahmen & HF-Transparenz

OpenMotorBridge nutzt ein duales, vollständig gehäuseintegriertes Antennenkonzept ohne störende äußere Antennenstummel bei maximaler Reichweite:
1. **LoRa 868 MHz Primärantenne (Taoglas FXP895):**
   * Formschlüssig in die Unterseite des Gehäusedeckels (`020_lid_plate.scad`) eingelassene Antennentasche ($85{,}0 \times 18{,}0 \times 1{,}2\,\text{mm}$) mit integrierter $2{,}5\,\text{mm}$ Kabelführungsnut für das U.FL-Koaxialkabel zu `ANT1`.
   * Die Antenne strahlt horizontal polarisiert nach oben durch den $1{,}8\,\text{mm}$ dünnen, HF-neutralen PA12-Deckel ($\varepsilon_r \approx 2{,}3\dots 2{,}7$, $\tan\delta \approx 0{,}015$). Dies garantiert eine maximale Rundum-Reichweite von bis zu $15\,\text{km}$ im OMM-Mesh.
2. **LoRa 868 MHz Sekundäroption (SMA-Bulkhead für Carbon-Bikes & Rallye):**
   * In der hinteren Stirnwand der Oberwanne ist ein Durchbruch ($\varnothing\,6{,}5\,\text{mm}$) mit einer $\varnothing\,9{,}5 \times 1{,}2\,\text{mm}$ O-Ring-Senkung für eine IP67-SMA-Einbaubuchse vorgesehen.
   * Ermöglicht das Anschließen externer Whip-Antennen, falls die Zentralbox in voll geschirmten Carbon-Heckbürzeln montiert wird.
3. **UWB 6.5 GHz Kanal 5 Flexantenne (Taoglas FXUWB10):**
   * Im Boden der Unterwanne (`00_lower_deck.scad`) exakt bei $X=66{,}5\,\text{mm}, Y=37{,}4\,\text{mm}$ eingelassene Tasche ($12{,}0 \times 12{,}0 \times 0{,}8\,\text{mm}$) mit $2{,}0\,\text{mm}$ Koaxialkabel-Führungsnut.
   * Liegt unmittelbar senkrecht unter dem DW3110 / `ANT2` U.FL-Connector der Platinen-Unterseite (`B.Cu`), wodurch die HF-Kabellänge auf ultrakurze $25\,\text{mm}$ minimiert wird (Einfügedämpfung $< 0{,}15\,\text{dB}$).
   * Der Wannenboden bleibt nach unten mit $>2{,}2\,\text{mm}$ PA12-Wandung 100% hermetisch geschlossen und spritzwasserdicht.
4. **Bluetooth 5.4 / LE Audio (Qualcomm QCC3084):**
   * Nutzt die onboard 2.4-GHz-Keramik-Chipantenne mit optimiertem Keepout-Bereich auf `PCBA 01`. Die Abstrahlung erfolgt verlustfrei durch die PA12-Wandungen und den Zwischenboden zu den Helm-Headsets und Smartphone-Docks.

---

## 4. Gehäusesystem Typ B: Universeller Satelliten-Pod & Modulare Wechselkassetten

OpenMotorBridge trennt das mechanische Gehäuse der Satelliten in zwei untrennbar aufeinander abgestimmte Systemkomponenten:
1. **Typ B (Pod-Basisschacht):** Ein zu 100 % baugleiches 5-seitiges Monocoque-Gehäuse ($135{,}0 \times 70{,}0 \times 38{,}0\,\text{mm}$), das dauerhaft am Motorrad verbleibt (an Rahmenrohren, im Kofferdeckel oder am Heckbürzel).
2. **Typ C (Modulare Wechselkassette):** Ein universeller 2-teiliger Basisschlitten ($116{,}0 \times 58{,}0 \times 28{,}0\,\text{mm}$), der systemspezifische OEM-Funkgeräte (Sena 50S/60S, Cardo Packtalk Edge, Midland, PMR446) oder eine wasserdichte Dry Box aufnimmt und werkzeuglos eingeschoben wird.

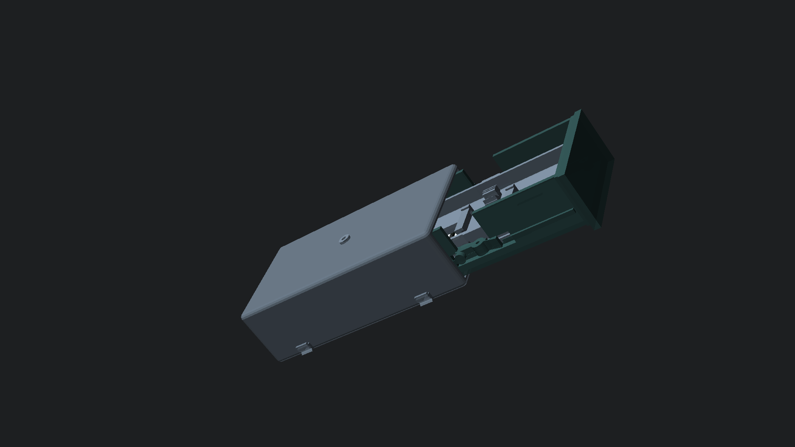
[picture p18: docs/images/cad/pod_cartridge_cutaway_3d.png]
OpenMotorBridge Satelliten-Pod & Kassetten 3D Anschnitt CAD


*Abbildung 8.6: Photorealistischer 3D-CAD-Schräganschnitt des Satelliten-Pods mit eingeschobener Wechselkassette. Gut zu erkennen sind die 120°-V-Nut mit EPDM-Spannringen um das Motorrad-Rahmenrohr, die monolithisch im 1-Teil-Monocoque integrierte Schottwand mit den beiden V4A-Auswerferfedern, die asymmetrischen Poka-Yoke Gleitschienen mit 8 mm Höhenversatz, die 2 massiven Mill-Max DC-Federkontakte (10 mm Raster) auf die ENIG-Pads von PCBA 03 und die formbündige Dichtung an der Frontblende.*

#### Verdeckte Innenverschraubung & Sabotageschutz des Pod-Gehäuses
Da die frühere äußere M8-Verschraubung durch das All-UWB-Backbone und die direkte 2-Draht DC-Zuleitung entfallen ist, erfolgt die mechanische Befestigung des Pod-Basisschachts am Motorradrahmen, Sturzbügel oder Kofferhalter über **verdeckte M4/M5-Edelstahlschrauben**:
* **Zugangssperre durch Kassettenverriegelung:** Die Montagebohrungen im Gehäuseboden sind **ausschließlich aus dem inneren Kassetten-Schachtraum zugänglich**, wenn die Wechselkassette herausgezogen wurde.
* Solange die Wechselkassette eingeschoben und durch die interne N52-Magnetwippe formschlüssig verriegelt ist, sind die Befestigungsschrauben mechanisch vollständig verdeckt und gegen Werkzeugeangriffe von außen geschützt.
* Das Entriegeln der Kassette erfordert das Vorhalten des codierten 2-in-1 Smart-Keyfobs (`PCBA 07`). Ein unbefugtes Abschrauben des Pod-Gehäuses im abgestellten Zustand ist somit physisch blockiert.
* **Aktive Sabotage-Erkennung:** Jeder Versuch, das Gehäuse mit einem Hebelwerkzeug gewaltsam aufzubiegen oder abzureißen, wird von der hochempfindlichen 6-Achs-IMU der Zentralbox registriert und löst in $< 50\,\text{ms}$ einen Prioritäts-Diebstahlalarm (`0xFE`) über LoRa Kanal 3 direkt auf den Taschen-Pager des Fahrers aus.

---

### 4.1 Gesamtsystem-Kinematik: Poka-Yoke, Auto-Eject & Unsichtbarer Magnet-Diebstahlschutz

Das Zusammenspiel von Pod-Schacht (Typ B) und Wechselkassette (Typ C) wird durch ein vollkommen gekapseltes, werkzeugloses und diebstahlgeschütztes Führungs- und Verriegelungssystem bestimmt:

#### 4.1.1 Asymmetrisches Poka-Yoke Nut-und-Feder Führungskonzept

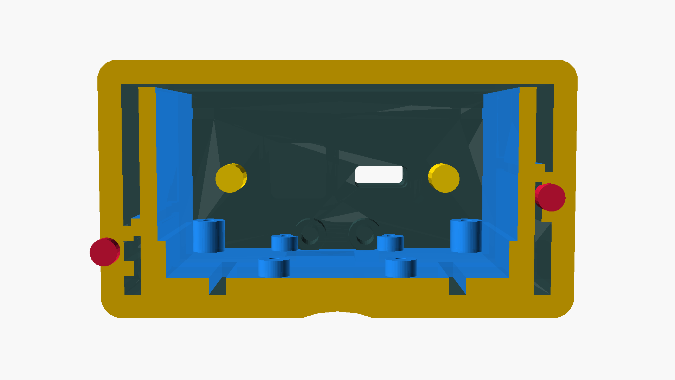
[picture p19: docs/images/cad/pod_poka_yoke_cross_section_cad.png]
OpenMotorBridge Pod Poka-Yoke Cross Section


*Abbildung 8.7: 3D-CAD-Querschnitt (Y-Z Ebene) durch das Satelliten-Pod-Gehäuse und den Kassetten-Grundschlitten. Sichtbar ist der $8{,}0\,\text{mm}$ Höhenversatz der Führungsnuten (Links: $Z=10{,}0\,\text{mm}$, Rechts: $Z=18{,}0\,\text{mm}$). Ein $180^\circ$-Falscheinbau ist mechanisch ausgeschlossen.*

* **Führungsgeometrie:** Die Führungsnuten an den Innenwänden des Pods und die Gegenfedern am Kassetten-Schlitten sind um $8{,}0\,\text{mm}$ vertikal versetzt. Ein versehentliches Einschieben auf dem Kopf ($180^\circ$-Verdrehung) ist physisch blockiert, bevor elektrische Kontakte berührt werden können.
* **Vorzentrierungs-Fase:** $30^\circ$-Einlaufschrägen verengen das seitliche Führungsspiel auf den ersten $80\,\text{mm}$ auf präzise $\pm 0{,}2\,\text{mm}$.
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

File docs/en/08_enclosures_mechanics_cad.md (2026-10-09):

# 08 - Mechanical Enclosures, CAD Models & Sealing System (All Units)

This document specifies the mechanical engineering, thermal dissipation, IP67/IP69K sealing concepts, kinematics of the quick-change auto-eject system, and all CAD and STL assets of OpenMotorBridge v8.0:
1. **Central Control Box (Type A):** 3-piece sandwich enclosure with intermediate tray, battery cradle, front interface panel (Deutsch DTM-12 flange, SW1 button, USB-C, RGB-LED), integrated lid pocket ($85.0 \times 18.0 \times 1.2\,\text{mm}$) for Taoglas FXP895 LoRa 868 MHz flex antenna, bottom tub pocket ($12.0 \times 12.0 \times 0.8\,\text{mm}$) for Taoglas FXUWB10 UWB flex antenna, optional rear SMA bulkhead port, and planar 4-layer copper heat spreader.
2. **Modular Satellite Pod & Cartridge System (Type B):** Mechanically identical 5-sided monocoque enclosure for both satellite pods (Pods 1 & 2 Audio/Intercom, 2x symmetric) with modular swap cartridges (Sena SPIDER X Slim, Cardo Packtalk Edge, OMM 2.4 GHz Swap Cartridge, Midland, Dry Box), smooth closed IP67 outer shell (zero antenna radome penetrations), $120^\circ$ V-groove pipe saddle, Dual-Port M8/USB-C, Poka-Yoke tongue-and-groove guidance, spring-loaded auto-eject, and invisible neodymium magnetic anti-theft locking.
3. **Universal Front Node (Type C):** Ultra-compact Cockpit & Sensor Hub ($98.0 \times 68.0 \times 25.0\,\text{mm}$) tailored for the enlarged $82 \times 50\,\text{mm}$ 4-layer PCBA 05, featuring a **4-in-1 universal mounting system** (AMPS, pipe saddle, silentblocks, 3M Dual-Lock), integrated bottom tub pocket for UWB backbone (FXUWB10), J12 Qwiic Sensor Hub (u-blox SAM-M10Q GNSS patch, TI TMP117 precision thermometer, TI OPT3001 light sensor) in laminar airflow scoop, dedicated EPDM cable combs for USB (South) and vehicle wiring (North), Dual SW3526 20W USB-PD, and Knowles MEMS acoustic channel.
4. **2-in-1 LoRa Smart-Keyfob & Pager (Type D):** Ultra-compact pocket companion ($58.0 \times 34.0 \times 13.0\,\text{mm}$) molded in PA12-MJF with perimeter TPU shock bumper, integrated N52 neodymium ejection key, $0.5\,\text{mm}$ Mu-metal magnetic flux shield, MagSafe/Qi inductive charging receiver, LRA haptic motor, and wireless SX1262 LoRa/BLE alert pager.
5. **Vehicle-Specific Reference Mounting Kits (Zero-Drill):** Fully engineered, non-destructive bolt-on mounting kits for CVO Road Glide ST (Kit 1), Road King Special (Kit 2), Classic Bagger & Cruiser (Kit 3), and Adventure & Touring Enduros (BMW GS, KTM Adventure, Africa Twin - Kit 4 with minimal under-rack radar bracket).

---

## 1. Type A: Central Control Box (3-Piece Sandwich Architecture)

The Central Box enclosure is engineered in **PA12 (HP Multi Jet Fusion)** for harsh motorcycle environments (up to 20 g vibration, direct spray, under-seat heat soak):

- **External Dimensions:** $110.0 \times 74.0 \times 38.0\,\text{mm}$ (L x W x H; lower case $17.0\,\text{mm}$, upper case $15.0\,\text{mm}$, lid $6.0\,\text{mm}$).
- **Mounting:** 4x corner ears on lower case with **hole spacing $128.0 \times 56.0\,\text{mm}$** for M4 EPDM silentblocks (Shore 50A).
- **Internal Clearance:** $105.0 \times 69.0 \times 32.0\,\text{mm}$ (optimized for the $85.0 \times 55.0\,\text{mm}$ 4-layer main PCBA 01 with symmetric margins of $10.0\,\text{mm}$ in X and $7.0\,\text{mm}$ in Y).
- **Ingress Protection:** IP67 / IP69K (dust-tight, submersible to 1 m, steam-jet resistant).
- **100% Soldering-Iron Free Assembly:** Direct PA12-molded pilot holes ($\varnothing\,2.1\,\text{mm}$ for M2.5 plastic-forming screws) and form-fitting DIN 934 M3 hex nut pockets eliminate all brass heat-set threaded inserts.

OpenMotorBridge Central Box 3D Cutaway CAD

*Figure 8.1: Photorealistic 3D CAD diagonal cutaway render of the Central Control Box. The 3-tier sandwich is exposed: bottom tub with 4-layer PCB (ENIG) on M2.5 standoffs, intermediate tray with 11 convection cooling slots, upper LiPo UPS battery cradle with EPDM strap, Deutsch DTM-12 automotive flange, SW1 button, USB-C service port, and lid with Gore ePTFE vent.*
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

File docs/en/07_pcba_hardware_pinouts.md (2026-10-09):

# 07 - Hardware Architecture & Board Pinouts (The Streamlined Lineup)

This document serves as the **authoritative hardware specification for all active board assemblies (`PCBA 01`, `03`, `05`, `07`, `08`, `09`, `10`)** of the OpenMotorBridge system (v9.6 Clean All-UWB Architecture), detailing layer stackups, controlled impedance classes, zoning concepts, and complete pinout tables.

---

## 1. Overview of the Hardware Assemblies

OpenMotorBridge hardware follows the principle of radical signal decoupling: Data and audio streams are routed 100% wirelessly over a synchronous Ultra-Wideband backbone (UWB 6.5 GHz), while the physical vehicle wiring harness is reduced to pure 2-wire DC power (12V) and CAN bus.
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

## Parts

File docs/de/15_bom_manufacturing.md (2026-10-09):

# 15 - Stücklisten (BOM), COTS-Kaufteile & SMT-Fertigungsdaten (Das bereinigte PCBA-Lineup v9.6)

Dieses Dokument ist die zentrale Referenz (Single Source of Truth) für die vollständige Bauteilliste (Bill of Materials), die Fertigungsspezifikationen aller Leiterplatten (`PCBA 01`, `03`, `05`, `07`, `08` sowie optionales Passiv-Dock `06`) bei JLCPCB / Eurocircuits (`PCBA 02` und `PCBA 04` sind durch die All-UWB-Architektur ersatzlos entfallen), alle mechanischen 3D-Druck-Komponenten (MJF PA12), die COTS-Einkaufslisten sowie eine detaillierte Kosten- und Bestellkalkulation (Solo-Aufbau vs. Sammelbestellung).

> [!NOTE]
> **v9.6 Stücklisten-Harmonisierung & Konsolidierung:**  
> Alle Bauteile, LCSC-Teilenummern und Steckverbinder wurden mit den finalen Schaltplänen und Layouts in [Spezifikation 07 (PCBA Hardware & Pinouts)](07_pcba_hardware_pinouts.md) abgeglichen. Die frühere Pod-Bodenplatine `PCBA 02` und das Lenker-Interface `PCBA 04` sind vollständig entfallen. Kassetten (`PCBA 03`) arbeiten 100 % drahtlos über Qorvo DW3110 UWB und werden über direkte 2-Draht-DC-Bodenfederkontakte versorgt. Die mechanischen Kassetten-Inlays unterstützen das standardisierte 4-Klassen-Portfolio inklusive UCS (Universal Communication Solution) und OMM 2.4 GHz.

---

## 1. PCBA 01: Zentralbox Hauptplatine (`openmotorbridge_central_box`, 4-Layer FR4 TG150)

| Designator | Bauteil / MPN | Hersteller | Gehäuse | LCSC / JLCPCB Part # | Funktion |
| :--- | :--- | :--- | :--- | :--- | :--- |
| **U1** | ESP32-S3-WROOM-1-N16R8 | Espressif Systems | SMD Modul | C2913200 | Haupt-MCU (Dual-Core, 16 MB Flash, 8 MB PSRAM) |
| **U2** | LM5164-Q1 | Texas Instruments | SOIC-8-EP | C2843477 | Automotive 65V Synchronous Buck Converter |
| **U3** | BQ24075RGTR | Texas Instruments | VQFN-16 | C15464 | Dynamisches Power-Path Management & LiPo-Lader mit TS |
| **U4** | BMI270 | Bosch Sensortec | LGA-14 | C2836813 | 6-Achsen IMU für Schräglagen- & Bewegungserkennung |
| **U5** | ES8388 | Everest Semi | QFN-28 | C365736 | 24-Bit Stereo Audio Codec (I2S ADC/DAC) |
| **U6** | TCAN334GDCNR | Texas Instruments | SOT-23-8 | C842340 | 3.3V Automotive CAN-FD Transceiver (±58V Fault) |
| **U7** | SX1262IMLTRT | Semtech | QFN-24 | C190184 | Onboard 868 MHz LoRa Transceiver (+22 dBm, 24/7 USV-gepuffert) |
| **U8** | DW3110 | Qorvo | QFN-16 (B.Cu) | C2934600 | IEEE 802.15.4z UWB Transceiver (6.5 GHz Ch. 5 Backbone) |
| **SW1** | TS-1187A-C-A-B | C&K / Omron | SMD Taster | C318884 | Hardware Pairing- & Reset-Taster (3s Pair, 10s Purge) |
| **D1** | SMBJ33CA | Littelfuse | DO-214AA (SMB) | C87848 | TVS-Diode (33 V Standoff, 53.3 V max Clamping) |
| **F1** | MF-MSMF050-2 | Bourns | 1812 SMD | C22668 | Rückstellbare PPTC-Sicherung (500 mA Hold / 1.0 A Trip) |
| **LED1** | WS2812B-B | Worldsemi | 5050 SMD | C114586 | RGB Status-LED für optische Betriebsmodusanzeige |
| **J1** | DTM13-12PA Header | TE Connectivity | Automotive 12P | Kundenteil | Automotive Deutsch DTM-12 Schnittstelle (11 Pins aktiv) |
| **J2** | MicroSD Slot Push-Push | Molex / Korean Hro | SMD Push-Push | C266624 | 4-Bit SDIO Speicherkarte für Tour-Logging |
| **J_BAT** | Molex Micro-Fit 3.0 2P | Molex | SMD Header | C289110 | Steckverbindung zum 2.200 mAh LiPo Pufferakku |
| **ANT1** | U.FL-R-SMT-1 | Hirose / Murata | SMD HF | C2834595 | LoRa 868 MHz U.FL Buchse zu Taoglas FXP895 im Deckel |
| **ANT2** | U.FL-R-SMT-1 | Hirose / Murata | SMD HF (B.Cu) | C2834595 | UWB 6.5 GHz U.FL Buchse zu Taoglas FXUWB10 im Boden |

*(Hinweis: Durch den Wechsel auf All-UWB entfallen die früheren Audio-Übertrager T1, T2 und Optokoppler OC1, OC2 ersatzlos).*

---

## 2. Satelliten Pod-Gehäuse (Entfall von PCBA 02)
> **Architektur-Hinweis (v8.5 / v9.0):**  
> Die frühere Pod-Bodenplatine `PCBA 02` ist **vollständig und ersatzlos entfallen**.  
> Das Pod-Gehäuse (`pod_base_housing.stl`) ist ein monolithisches 3D-Druckteil ohne interne Platine. Die 2-adrige Gleichstrompeitsche (+5V und GND) führt von hinten direkt in das Gehäuse und endet an zwei vergoldeten Federkontakten (Keystone / Mill-Max), die formschlüssig auf die Stirnflächen-Pads von `PCBA 03` greifen.

---

## 3. PCBA 03: Universal Smart Cartridge Rev 3.0 (`openmotorbridge_pod_cartridge`, 2-Layer FR4 TG150, 2-seitig SMT)
> **Hinweis zur Stückzahl:** Die Kassette ist universell und wird **2x pro Motorrad** verbaut (Bucht 1 links, Bucht 2 rechts).

| Designator | Bauteil / MPN | Hersteller | Gehäuse | LCSC / JLCPCB Part # | Funktion |
| :--- | :--- | :--- | :--- | :--- | :--- |
| **U1** | DW3110 | Qorvo | QFN-16 (Bottom) | C2934600 | IEEE 802.15.4z UWB Transceiver (6.5 GHz Ch. 5 All-UWB Link) |
| **U2** | ESP32-C6-MINI-1U | Espressif | SMD Modul (Top) | C5267233 | 32-Bit RISC-V Host-MCU (verwaltet Kassetten-Profile, UWB & Mechatronik) |
| **U3** | ES8388 | Everest Semi | QFN-28 (Bottom) | C2845349 | 24-Bit / 48 kHz Stereo Audio Codec (getrennte L/R ADC & DAC Kanäle) |
| **Q1 - Q4**| AO3400A | Alpha & Omega | SOT-23 (Top) | C20917 | 4x N-Kanal MOSFETs ($30\,\text{V} / 5{,}7\,\text{A}$) für Mechatronik-Aktuatoren |
| **D1 - D4**| 1N4148WS | Diodes Inc. | SOD-323 (Top) | C2128 | 4x Freilaufdioden für Miniatur-Hubmagnete |
| **F1** | MF-MSMF050-2 | Bourns | 1812 SMD | C22668 | PPTC 500mA Schutzsicherung |
| **J_ACT** | SM08B-SRSS-TB | JST | 8-Pin 1.0mm SMD | C160404 | Mechatronik-Header für 4 Hubmagnete (Top) |
| **J_AUDIO_PWR**| SM08B-SRSS-TB | JST | 8-Pin 1.0mm SMD | C160404 | Audio- & Power-Header (Top, getrennte PGND / AGND Sternmassen) |
| **ANT1** | U.FL-R-SMT-1 | Hirose | SMD Micro-Coax | C14894 | UWB-Antennenport (Taoglas FXUWB10 oder SMD-Patch) |

---

## 4. Baugruppe PCBA 04 (Heck-Pod 3): Ersatzlos entfallen (Clean Architecture v8.0)

> [!NOTE]
> **Architektur-Bereinigung v8.0:** Die Leiterplatte `PCBA 04` und das dritte Satellitengehäuse (Heck-Pod 3) wurden **vollständig und ersatzlos gestrichen**:
> 1. **LoRa 868 MHz (SX1262):** Sitzt nun direkt auf der Zentralbox (`PCBA 01`), gepuffert durch den USV-Akku (24/7 Diebstahl-Sentry).
> 2. **Multi-GNSS (SAM-M10Q):** Sitzt im kühlen Fahrtwindbereich am Front-Knoten (`PCBA 05`), angebunden über Qwiic I2C (`J12`).
> 3. **Fahrzeug-Backbone:** Erfolgt drahtlos über Ultra-Wideband (Qorvo DW3110 / 6.5 GHz Ch. 5, $< 0{,}4\,\text{ms}$ Latenz) zwischen Front-Knoten und Zentralbox.
> 4. **Heck-Radar:** Schließt direkt über Peitsche 3 des Deutsch DTM-12 Kabelbaums an die Zentralbox an (2-Draht 12V DC); Telemetrie läuft 100 % drahtlos via UWB.

---

## 5. PCBA 05: Universal Front-Knoten (`openmotorbridge_front_node`, 4-Layer FR4 TG150, 82 x 50 mm)

| Designator | Bauteil / MPN | Hersteller | Gehäuse | LCSC / JLCPCB Part # | Funktion |
| :--- | :--- | :--- | :--- | :--- | :--- |
| **U1** | ESP32-S3-WROOM-1U-N8R8 | Espressif Systems | SMD Modul | `C2913200` | Dual-Core 32-Bit Xtensa LX7 (240 MHz, Vektor-DSP, 8MB PSRAM, ext. U.FL) |
| **U2** | USB2514Bi-AEZG / USB2514B | Microchip | QFN-36 | `C16251` | Automotive/Industrial USB 2.0 High-Speed 480 Mbps 4-Port Hub Controller |
| **U3** | LMR36015FSCQRNXRQ1 | Texas Instruments | VQFN-12 | `C2843480` | Automotive 36V Synchronous Buck (5V / 2.0A, 91.8%) für Hub & Peripherie |
| **U4** | TPS2051BDBVR | Texas Instruments | SOT-23-5 | `C7818` | High-Side USB VBUS Power Switch (1.05A Clamp) für Port 2 Kaltstart-Reset |
| **U5** | SC8102QDER | Southchip | QFN-32 | `C2843510` | Automotive Synchronous Buck mit USB-PD 20W (9V/2.2A & QC3.0) für Smartphone Port 1 |
| **U6** | TCAN334GDCNT | Texas Instruments | SOT-23-8 | `C2843515` | 3.3V CAN-Transceiver (5 Mbps CAN-FD fähig, mit Pin 8 Silent-Listen-Only Mode) |
| **U7** | DW3110 | Qorvo | QFN-16 (B.Cu) | `C2934600` | IEEE 802.15.4z UWB Transceiver (6.5 GHz Ch. 5 Backbone) |
| **K1** | CPC1017NTR | IXYS / Littelfuse | SOP-4 | `C26789` | 60V / 100mA 1-Form-A Solid-State Relais für schaltbaren 120R CAN-Abschluss (Auto-Sensing) |
| **Q1** | DMN63D8LDW-7 | Diodes Incorporated| SOT-363 | `C283890` | Dual N-Kanal MOSFET (30V / 260mA) für richtungsgetrennte Spiegel-Totwinkel-LEDs (J9) |
| **Q2** | TPS1H100BQPWPRQ1 | Texas Instruments | HTSSOP-14 | `C2843520` | Automotive Smart High-Side Power Switch (bis 3.5A / 40W) für 12V Aux Light (J11) |
| **LED1**| WS2812B-2020 | Worldsemi | SMD 2020 | `C2843530` | Digital steuerbare RGB-Status-LED für Gehäusedeckel-Lichtleiter |
| **MIC1**| MSM261S4030H0R / SPH0645 | Sipeed / Knowles | 3.5x2.65 mm SMD | `C544577` | Digitales I2S-MEMS Akustik-Mikrofon (Standard-I2S, hohe Verfügbarkeit) |
| **L1** | 4.7 µH Automotive Inductor | Sunlord / Wurth | SMD 5x5 mm | `C2843490` | Speicherdrossel für LMR36015 5V-Hauptregler |
| **L2** | 10 µH Automotive Inductor | Coilcraft / Wurth | SMD 7x7 mm | `C2843525` | Speicherdrossel für SC8102 USB-PD Fast-Charge Buck (Port 1) |
| **J1** | JST-PH 2-Pin Header | JST | 2.00mm SMD | `C289115` | 12V Bordnetz-Einspeisung (KL15 & GND) |
| **J2** | JST-PH 3-Pin Header | JST | 2.00mm SMD | `C289116` | Cockpit CAN-Bus (CAN_H, CAN_L, GND mit Auto-Sensing Relais) |
| **J3** | JST-PH 4-Pin Header | JST | 2.00mm SMD | `C289117` | Lenker Multi-Button Interface (PTT, Cam-Action, Media-Voice, GND) |
| **J4** | JST-PH 4-Pin Header | JST | 2.00mm SMD | `C289117` | Upstream USB-Port zum Motorrad-Infotainment (Skyline OS / Boom! Box) |
| **J5** | JST-PH 4-Pin Header | JST | 2.00mm SMD | `C289117` | Port 1: Lenker-Smartphone (USB-PD 20W + High-Speed Data) |
| **J6** | JST-PH 4-Pin Header | JST | 2.00mm SMD | `C289117` | Port 2: Fairing Pigtail (geschirmt, 30 cm) zum CP2AA CarPlay/AA Dongle |
| **J5_MP3**| JST-PH 4-Pin Header | JST | 2.00mm SMD | `C289117` | Port 3: Handschuhfach-Kabel für USB-Sticks (MP3s & Firmware-Updates) |
| **J6_AUX**| JST-PH 4-Pin Header | JST | 2.00mm SMD | `C289117` | Port 4: Cockpit-Zubehör / Dashcam-Massenspeicher / Zūmo-Navi |
| **J7** | USB-C 16-Pin Receptacle IP67| GCT / Korean Hro | SMD Hybrid | `C2765186` | ESP32-S3 Service- & Flash-Port (Flanke) mit TPU-Dichtstopfen |
| **J8** | JST-PH 2-Pin Header | JST | 2.00mm SMD | `C289115` | Action-Cam 5V Charge-Only Power-Port (bis 2.0A) |
| **J9** | JST-PH 3-Pin Header | JST | 2.00mm SMD | `C289116` | Spiegel-Totwinkel-LEDs (12V_PROT, BSD_LEFT_N, BSD_RIGHT_N) |
| **J10** | JST-PH 2-Pin Header | JST | 2.00mm SMD | `C289115` | 12V Qi-Smartphone-Power (SP Connect / QuadLock Ladekopf) |
| **J11** | JST-PH 2-Pin Header | JST | 2.00mm SMD | `C289115` | 12V Aux Light (Adventure Zusatzscheinwerfer / Notbrems-Strobe) |
| **J12** | JST-SH 4-Pin Header | JST | 1.00mm SMD | `C289118` | Qwiic / STEMMA QT I2C Sensorport (SAM-M10Q GNSS, TMP117, OPT3001) |
| **ANT1**| U.FL-R-SMT-1 | Hirose / Murata | SMD HF (B.Cu) | `C2834595` | UWB 6.5 GHz U.FL Buchse zu Taoglas FXUWB10 im Boden |

---

## 6. PCBA 06: MagSafe Rahmendock-Adapter (`openmotorbridge_magsafe_dock`, 2-Layer FR4, 28 x 11.5 mm) [Optional / Legacy]

> [!NOTE]
> **Status:** In der aktuellen **All-UWB v9.6 Architektur** entfällt PCBA 06 im regulären Betrieb, da die Koffer-Trennstelle als reines 2-Draht DC-System ausgeführt wird und direkt über einen industriellen 2-Pin Magnet-Pogo-Steckverbinder (COTS) verbunden wird. Diese BOM dient als Referenz für Legacy-Aufbauten mit starrer Rahmenverschraubung.

| Ref | Bauteil / Typ | Gehäuse | Spezifikation & Funktion | LCSC Part |
| :--- | :--- | :--- | :--- | :--- |
| **`F1`** | 0ZCG0050FF2C | SMD 1206 | 500 mA Hold / 1000 mA Trip, 16V PPTC Selbstrückstellende Sicherung | `C207936` |
| **`D1`** | ESD5Z5.0T1G | SOD-323 | 5,0V Unidirektionale TVS-Diode (Transient-Schutz) | `C2834585` |
| **`U1`** | USBLC6-4SC6 | SOT-23-6 | 4-Kanal ESD-Schutzarray ($<0{,}8\,\text{pF}$, $\pm 15\,\text{kV}$ ESD) | `C7519` |
| **`C1`** | 100nF 50V X7R | SMD 0603 | Keramischer Entkoppelkondensator auf VCC_PROT | `C14663` |
| **`J1`** | M8 Wire Pads | SMD/THT 1x07 | 7-poliges Lötpad-Array mit 0,6mm Durchkontaktierung für M8-Kabeladern | Custom |
| **`J2`** | MagSafe 6P Pads | SMD 1x06 | 6-polige vergoldete Kontaktflächen für MagSafe Magnet-Pogo-Kupplung | `C224376` |
| **`H1`** | MountingHole_Pad | M2.5 (Ø 2.7 mm) | Bohrung Ø 2.7 mm, Pad Ø 4.5 mm, geerdet an System-GND | Hardware |

---

## 7. PCBA 07: 2-in-1 LoRa Smart-Keyfob (`openmotorbridge_smart_keyfob`, 2-Layer FR4, 38 x 19 mm)

| Ref | Bauteil / Typ | Gehäuse | Spezifikation & Funktion | LCSC Part |
| :--- | :--- | :--- | :--- | :--- |
| **`U1`** | nRF52840-QIAA-R | aQFN-73 | 32-Bit ARM Cortex-M4F SoC mit Bluetooth 5.4, NFC & Crypto | `C190767` |
| **`U2`** | SX1262IMLTRT | QFN-24 | Semtech 868 MHz LoRa Transceiver (+22 dBm, TCXO) | `C90039` |
| **`U3`** | DRV2605LDGSR | VSSOP-10 | TI ERM/LRA Haptic Driver mit integrierter Effekt-Bibliothek | `C61633` |
| **`U4`** | BQ51003YFPR | DSBGA-28 | TI 2.5W Qi Wireless Power Receiver Controller | `C144862` |
| **`U5`** | BQ25100YFPR | DSBGA-6 | TI Linearer LiPo-Ladecontroller mit 50 nA Ruhestrom | `C144857` |
| **`M1`** | VG1036001D | Coin 10x3.6mm | Vybronics LRA Linearmotor (235 Hz Resonanzfrequenz) | Custom / Distrelec |
| **`BZ1`**| PKLCS1212E4001 | SMD 12x12mm | Murata SMD-Piezo-Schallwandler (85 dB @ 10 cm, 4 kHz) | `C94511` |

---

## 8. PCBA 08: Radar 2.0 Sub-MCU & 36-LED Flügel-Träger (`openmotorbridge_radar_submcu`, 2-Lagen FR4 TG150, 115 x 65 mm)

| Ref | Bauteil / Typ | Gehäuse | Spezifikation & Funktion | LCSC Part |
| :--- | :--- | :--- | :--- | :--- |
| **`U1`** | ESP32-C5-WROOM-1-N8 | SMD Modul | 32-Bit RISC-V Dual-Band Sub-MCU (2.4 GHz + 5.9 GHz V2X, 4MB Flash) | `C2843550` |
| **`U2`** | LDO 3.3V 500mA | SOT-23-5 | TI TLV75533P / Richtek RT9013 LDO Spannungsregler | `C505293` |
| **`U3`** | Qorvo DW3110 | QFN-16 | Ultra-Wideband (UWB) Transceiver (6.5 GHz Ch. 5, All-UWB Backbone) | `C2934500` |
| **`Y1_UWB`**| 38.4 MHz Crystal | SMD 2016-4P | Präzisionsquarz für DW3110 UWB Transceiver | `C384351` |
| **`D1..36`**| WS2812B-2020 | SMD 2020 | 36x Digital RGB-LEDs in Doppel-Warnflügeln (18 links, 18 rechts) | `C2843530` |
| **`J1`** | JST-JWPF 2-Pin | THT/SMD 2.0mm | Wasserdichter 12V DC Kfz-Bordnetzeingang (`B02B-JWPF-SK-R`) | `C2843555` |
| **`J2`** | JST-SH 1.0mm 4-Pin | SMD Liegend | UART-Verbindung zum Wheeltec MR20 Transceiver (RX/TX/5V/GND) | `C136657` |
| **`J3`** | Hirose U.FL | SMT Vertical | 5.9 GHz V2X HF-Antennenanschluss | `C14894` |
| **`J4`** | Hirose U.FL | SMT Vertical | 6.5 GHz UWB HF-Antennenanschluss (Taoglas FXUWB10 Flexantenne) | `C14894` |
| **`SW1..2`**| Alps SKRK SMD | SMD 3.9x2.9mm | Lokale Boot- und Reset-Taster | `C115358` |

---

## 8b. PCBA 09: OMM 2.4 GHz Autonomes Intercom-Modul (`openmotorbridge_omm_ucs`, 2-Layer FR4 TG150, 60 x 30 mm)

| Designator | Bauteil / Wert | Hersteller / Typ | Gehäuse / Footprint | JLCPCB Part # | Funktion / Beschreibung |
| :--- | :--- | :--- | :--- | :---: | :--- |
| **`U1`** | ESP32-C6-MINI-1U | Espressif | SMD Modul (13.2x16.6mm) mit U.FL | `C5267233` | 32-Bit RISC-V 160MHz Host MCU, Wi-Fi 6, 802.15.4 TDMA, BLE 5.3, 4MB Flash, integrierter U.FL HF-Port für Koax-Pigtail / Stummelantenne |
| **`U2`** | BQ24075RGTR | Texas Instruments | QFN-16 (3x3mm) | `C96825` | 1.5A LiPo PMIC mit Dynamic Power Path Management (Zero-Reboot Umschaltung & USV) |
| **`U3`** | XC6206P332MR | Torex Semi | SOT-23-3 | `C5446` | 3.3V / 250mA Low-Iq LDO Spannungsregler |
| **`U4`** | ES8388 | Everest Semi | QFN-28 (4x4mm) | `C365736` | 24-Bit / 96kHz Stereo Audio Codec mit getrenntem L/R Kopfhörertreiber & Differenz-Mic-Preamp |
| **`U5`** | ESP32-PICO-V3-02 | Espressif | QFN-48 (7x7mm) | `C2686884` | Bluetooth Classic / BLE Co-Prozessor (Dual-Engine OMB Lite: HFP HD Voice, A2DP, Cardo/Sena Cross-Bridge, BLE GATT) |
| **`ANT1`** | 2450AT18x100 | Johanson Tech | SMD 3216 (1.2x3.2mm) | `C2909988` | 2.45 GHz Keramik-Chipantenne für ESP32-PICO-V3-02 Bluetooth Co-Prozessor (Nahfeld-Kopplung Smartphone/Display) |
| **`J1`** | TYPE-C-31-M-12 | Korean HRO | SMT/THT IP67 | `C2765186` | Wasserdichte 16-Pin USB-C Buchse (5V Unterwegs-Laden via Powerbank/Front-Node, WebUSB DFU Flashing, Kassetten-Einschubkontakt) |
| **`J_HELMET`**| SM06B-SRSS-TB | JST | 6-Pin JST-SH 1.0mm SMD Horiz. | `C136657` | Interner Helm-Audio & PTT-Port auf B.Cu (HP_OUT_L, HP_OUT_R, AGND_SPK, MIC_IN+, AGND_MIC, BTN_PTT; 0V DC) |
| **`BAT1`** | BM02B-SRSS-TB | JST | SMD 1.0mm pitch | `C2902341` | Steckverbindung zum internen 600-mAh-LiPo Pouch-Akku (mit PCM) |
| **`D1`** | WS2812B-2020 | Worldsemi | SMD 2020 | `C2843785` | RGB-Status-LED (Ladezustand, Mesh-Kanal, Pairing-Indikator) |
| **`D2`** | USBLC6-2SC6 | STMicroelectronics | SOT-23-6 | `C7519` | High-Speed TVS-Diodenarray für USB D+/D- und VBUS ESD-Schutz |
| **`SW1..4`** | EVQ-P2 / KMT0 | Panasonic / C&K | SMD 3.5x2.8mm | `C318884` | 4x taktile IP67 Mikrotaster (Power, Mesh, Vol+, Vol-) |
| **`R_NTC`** | 10k NTC 1% | Murata | 0402 | `C25804` | Akku-Temperaturüberwachung nach JEITA-Norm |

---

## 8c. PCBA 10: OMM 446 Analog & Digital PMR446 Intercom-Modul (`openmotorbridge_omm446_ucs`, 4-Layer FR4 TG150, 60 x 30 mm)

| Designator | Bauteil / Wert | Hersteller / Typ | Gehäuse / Footprint | JLCPCB Part # | Funktion / Beschreibung |
| :--- | :--- | :--- | :--- | :---: | :--- |
| **`U1`** | ESP32-C6-MINI-1U | Espressif | SMD Modul (13.2x16.6mm) mit U.FL | `C5267233` | 32-Bit RISC-V Host MCU, BLE 5.3 Smartphone-Setup, WebUSB DFU, AT-Command Control für SA818-DMR |
| **`U2`** | BQ24075RGTR | Texas Instruments | QFN-16 (3x3mm) | `C96825` | 1.5A LiPo PMIC mit DPPM (Laden im Betrieb via USB-C, Akku dient als USV) |
| **`U3`** | SA818-DMR | NiceRF | SMD Modul (16x38mm) | `C2839211` | 446 MHz Analog FM & Digital DMR Tier I Transceiver Modul (0.2W Helm / 0.5W Bike) |
| **`U4`** | ES8388 | Everest Semi | QFN-28 (4x4mm) | `C365736` | 24-Bit Stereo Audio Codec für Funk-Audio Ein-/Ausgabe und Helm-Lautsprecher |
| **`U5`** | ME6211C33M5G | MicrOne | SOT-23-5 | `C82942` | 3.3V / 500mA High-Speed Low-Dropout Spannungsregler |
| **`U6`** | ESP32-PICO-V3-02 | Espressif | QFN-48 (7x7mm) | `C2686884` | Bluetooth Classic / BLE Co-Prozessor (Dual-Engine OMB Lite: HFP HD Voice, A2DP, Cardo/Sena Cross-Bridge, BLE GATT) |
| **`ANT1`** | 2450AT18x100 | Johanson Tech | SMD 3216 (1.2x3.2mm) | `C2909988` | 2.45 GHz Keramik-Chipantenne für ESP32-PICO-V3-02 Bluetooth Co-Prozessor |
| **`J1`** | TYPE-C-31-M-12 | Korean HRO | SMT/THT IP67 | `C2765186` | Wasserdichte 16-Pin USB-C Buchse (5V Unterwegs-Laden, WebUSB DFU, Kassetten-Einschubkontakt) |
| **`J_HELMET`**| SM06B-SRSS-TB | JST | 6-Pin JST-SH 1.0mm SMD Horiz. | `C136657` | Interner Helm-Audio & PTT-Port auf B.Cu (HP_OUT_L, HP_OUT_R, AGND_SPK, MIC_IN+, AGND_MIC, BTN_PTT; 0V DC) |
| **`J_RF`** | U.FL-R-SMT-1 | Hirose | SMD U.FL Buchse (B.Cu) | `C14899` | 50 Ohm U.FL Buchse für Koax-Pigtail zur wasserdichten SMA-Durchführung oder Bike-Außenantenne |
| **`PAD_ANT`**| SMD Testpad D3.0mm| Custom | Kupfer-Pad (F.Cu) | - | Alternativer HF-Lötanschluss für interne Wendelantenne oder Direktverbindung |
| **`BAT1`** | BM02B-SRSS-TB | JST | SMD 1.0mm pitch | `C2902341` | Steckverbindung zum internen 600-mAh-LiPo Pouch-Akku (mit PCM) |
| **`D1`** | WS2812B-2020 | Worldsemi | SMD 2020 | `C2843785` | RGB-Status-LED (RX Grün, TX Rot, DMR Blau, Chg Gelb) |
| **`D2`** | USBLC6-2SC6 | STMicroelectronics | SOT-23-6 | `C7519` | High-Speed TVS-Diodenarray für USB D+/D- und VBUS ESD-Schutz |
| **`SW1..4`** | EVQ-P2 / KMT0 | Panasonic / C&K | SMD 3.5x2.8mm | `C318884` | 4x taktile IP67 Mikrotaster (PTT, Mode, Ch+, Ch-) |

---

## 9. 1-Click Bestellleitfaden für JLCPCB (Alle Leiterplatten fertig bestückt)

Alle Fertigungsdaten liegen im Repository unter `hardware/production_packages/` als fertige ZIP- und CSV-Pakete vor:

| Baugruppe / PCBA | Gerber-ZIP Datei | BOM CSV Datei | CPL (Pick & Place) CSV | Lagen | Fertigungs-Hinweis |
| :--- | :--- | :--- | :--- | :---: | :--- |
| **PCBA 01: Zentralbox** | `01_main_box_pcba_gerbers_jlcpcb.zip` | `01_main_box_pcba_bom_jlcpcb.csv` | `01_main_box_pcba_cpl_jlcpcb.csv` | **4 Lagen** | ENIG (Gold), 1.6 mm, TG150, SMT beidseitig (DW3110 auf B.Cu) |
| **PCBA 03: Universal-Kassette**| `03_pod_cartridge_pcba_gerbers_jlcpcb.zip` | `03_pod_cartridge_pcba_bom_jlcpcb.csv` | `03_pod_cartridge_pcba_cpl_jlcpcb.csv` | **2 Lagen** | ENIG (Gold), 1.2 mm, SMT beidseitig (2x pro Fahrzeug bestellen) |
| **PCBA 05: Front-Knoten** | `05_front_node_pcba_gerbers_jlcpcb.zip` | `05_front_node_pcba_bom_jlcpcb.csv` | `05_front_node_pcba_cpl_jlcpcb.csv` | **4 Lagen** | ENIG (Gold), 1.6 mm, TG150, SMT beidseitig (DW3110 auf B.Cu) |
| **PCBA 06: MagSafe Dock** | `06_magsafe_dock_pcba_gerbers_jlcpcb.zip` | `06_magsafe_dock_pcba_bom_jlcpcb.csv` | `06_magsafe_dock_pcba_cpl_jlcpcb.csv` | **2 Lagen** | *Optional / Legacy* (bei All-UWB durch COTS 2-Pin Magnetkupplung ersetzt) |
| **PCBA 07: Smart-Keyfob** | `07_smart_keyfob_pcba_gerbers_jlcpcb.zip` | `07_smart_keyfob_pcba_bom_jlcpcb.csv` | `07_smart_keyfob_pcba_cpl_jlcpcb.csv` | **2 Lagen** | ENIG (Gold), 1.0 mm, SMT beidseitig |
| **PCBA 08: Radar 2.0 Sub-MCU** | `08_radar_submcu_pcba_gerbers_jlcpcb.zip` | `08_radar_submcu_pcba_bom_jlcpcb.csv` | `08_radar_submcu_pcba_cpl_jlcpcb.csv` | **2 Lagen** | ENIG (Gold), 1.2 mm, TG150, SMT Top (2x U.FL, 90° Stiftleiste) |
| **PCBA 09: OMM UCS Modul** | `09_omm_ucs_pcba_gerbers_jlcpcb.zip` | `09_omm_ucs_pcba_bom_jlcpcb.csv` | `09_omm_ucs_pcba_cpl_jlcpcb.csv` | **2 Lagen** | ENIG (Gold), 1.0 mm, TG150, SMT beidseitig (ECE 22.06 & Pod) |
| **PCBA 10: OMM 446 UCS** | `10_omm446_ucs_pcba_gerbers_jlcpcb.zip` | `10_omm446_ucs_pcba_bom_jlcpcb.csv` | `10_omm446_ucs_pcba_cpl_jlcpcb.csv` | **4 Lagen** | ENIG (Gold), 1.0 mm, TG150, SMT beidseitig (ECE 22.06 & Pod) |

Alle Fertigungsdaten liegen im Repository unter `hardware/production_packages/` als fertige ZIP- und CSV-Pakete vor:

| Baugruppe / PCBA | Gerber-ZIP Datei | BOM CSV Datei | CPL (Pick & Place) CSV | Lagen | Fertigungs-Hinweis |
| :--- | :--- | :--- | :--- | :---: | :--- |
| **PCBA 01: Zentralbox** | `01_main_box_pcba_gerbers_jlcpcb.zip` | `01_main_box_pcba_bom_jlcpcb.csv` | `01_main_box_pcba_cpl_jlcpcb.csv` | **4 Lagen** | ENIG (Gold), 1.6 mm, TG150, SMT beidseitig (DW3110 auf B.Cu) |
| **PCBA 03: Universal-Kassette**| `03_pod_cartridge_pcba_gerbers_jlcpcb.zip` | `03_pod_cartridge_pcba_bom_jlcpcb.csv` | `03_pod_cartridge_pcba_cpl_jlcpcb.csv` | **2 Lagen** | ENIG (Gold), 1.2 mm, SMT beidseitig (2x pro Fahrzeug bestellen) |
| **PCBA 05: Front-Knoten** | `05_front_node_pcba_gerbers_jlcpcb.zip` | `05_front_node_pcba_bom_jlcpcb.csv` | `05_front_node_pcba_cpl_jlcpcb.csv` | **4 Lagen** | ENIG (Gold), 1.6 mm, TG150, SMT beidseitig (DW3110 auf B.Cu) |
| **PCBA 06: MagSafe Dock** | `06_magsafe_dock_pcba_gerbers_jlcpcb.zip` | `06_magsafe_dock_pcba_bom_jlcpcb.csv` | `06_magsafe_dock_pcba_cpl_jlcpcb.csv` | **2 Lagen** | *Optional / Legacy* (bei All-UWB durch COTS 2-Pin Magnetkupplung ersetzt) |
| **PCBA 07: Smart-Keyfob** | `07_smart_keyfob_pcba_gerbers_jlcpcb.zip` | `07_smart_keyfob_pcba_bom_jlcpcb.csv` | `07_smart_keyfob_pcba_cpl_jlcpcb.csv` | **2 Lagen** | ENIG (Gold), 1.0 mm, SMT beidseitig |
| **PCBA 08: Radar 2.0 Sub-MCU** | `08_radar_submcu_pcba_gerbers_jlcpcb.zip` | `08_radar_submcu_pcba_bom_jlcpcb.csv` | `08_radar_submcu_pcba_cpl_jlcpcb.csv` | **2 Lagen** | ENIG (Gold), 1.2 mm, TG150, SMT Top |

---

## 10. Mechanik- & Gehäuse-BOM (3D-Druck MJF PA12 & Normteile)

Alle Gehäuseteile sind konsequent für das **IKEA-Prinzip** konstruiert: **Kein Einschmelzen von Gewindeeinsätzen mit dem Lötkolben und absolut kein Gewindeschneiden in Kunststoff erforderlich!** Die Gehäuse verfügen ausnahmslos über formschlüssig integrierte Sechskant-Mutterntaschen (Nut Pockets für Standard DIN 934 V4A-Edelstahlmuttern M2, M2.5, M3, M4, M5). Sämtliche Schraubverbindungen sind unendlich oft zerstörungsfrei demontierbar und wieder verschraubbar.

### 10.1 Basis-System (Universal für jedes Motorrad)
| Baugruppe | STL-Dateiname | Stück | Material & Fertigung | Funktion & Beschreibung |
| :--- | :--- | :---: | :--- | :--- |
| **Main Box Unterteil** | [`main_box_lower_case.stl`](../../hardware/cad/stl/01_main_box/main_box_lower_case.stl) | **1** | MJF PA12 / ASA | Monocoque-Unterwanne mit UWB-Bodentasche ($11 \times 11 \times 0{,}6\,\text{mm}$), 4x M4 Silentblock-Ohren & Dichtnut |
| **Main Box Zwischenboden** | [`main_box_mid_tray.stl`](../../hardware/cad/stl/01_main_box/main_box_mid_tray.stl) | **1** | MJF PA12 / ASA | Akku-Wanne für 2.200 mAh Flat-LiPo ($68 \times 39 \times 5{,}0\,\text{mm}$), 11x Konvektionsschlitze & Dichtfeder |
| **Main Box Deckel** | [`main_box_lid.stl`](../../hardware/cad/stl/01_main_box/main_box_lid.stl) | **1** | MJF PA12 / ASA | Gehäusedeckel mit LoRa FXP895 Tasche ($110 \times 20 \times 0{,}8\,\text{mm}$), Gore ePTFE-Ventilsitz & Schraubensenkungen |
| **Pod-Basisgehäuse** | [`pod_base_housing.stl`](../../hardware/cad/stl/02_pod_base/pod_base_housing.stl) | **2** | MJF PA12 / ASA | Monolithisches 1-Teil-Schachtgehäuse mit integrierter Schottwand, Kontaktführungen & Federdomen |
| **Pod-Schottwand (integriert)** | [`03_pod_bulkhead_partition.stl`](../../hardware/cad/stl/02_pod_base/components/03_pod_bulkhead_partition.stl) | *(integr.)* | MJF PA12 / ASA | Zu 100 % nahtlos im Monocoque integriert (0 lose Teile, 0 Montageschrauben) |
| **Kassetten-Basisschlitten**| [`cartridge_base_sled.stl`](../../hardware/cad/stl/03_pod_cartridges/cartridge_base_sled.stl) | **2** | MJF PA12 / ASA | Universalschlitten für Gateway 1 (Pod 1) und Gateway 2 (Pod 2) |
| **Kassetten-Riegel / Wippe**| [`cartridge_magnetic_lock_latch.stl`](../../hardware/cad/stl/03_pod_cartridges/cartridge_magnetic_lock_latch.stl) | **2** | MJF PA12 / ASA | Magnetische Diebstahlschutz-Rastwippen für Kassetten-Slots 1 & 2 |
| **Front-Knoten Unterwanne** | [`front_node_lower_tub.stl`](../../hardware/cad/stl/04_front_node/front_node_lower_tub.stl) | **1** | MJF PA12 / ASA | Cockpit-Wanne mit UWB-Bodentasche ($11 \times 11 \times 0{,}6\,\text{mm}$), AMPS-Bohrbild & Rohrbett |
| **Front-Knoten Deckel** | [`front_node_upper_lid.stl`](../../hardware/cad/stl/04_front_node/front_node_upper_lid.stl) | **1** | MJF PA12 / ASA | Deckel mit Knowles MEMS Schalleintritt & O-Ring-Dichtnut |
| **Front-Knoten Dichtkämme** | [`front_node_cable_glands_tpu.stl`](../../hardware/cad/stl/04_front_node/front_node_cable_glands_tpu.stl) | **1 Paar**| TPU 95A / 85A | Elastische Dichtkämme für Front-USB & Signale |
| **Front-Knoten USB-C Kappe**| [`front_node_usbc_cap_tpu.stl`](../../hardware/cad/stl/04_front_node/front_node_usbc_cap_tpu.stl) | **1** | TPU 95A / 85A | Elastische Staubschutzkappe mit Haltekollier für Service-Port |
| **Verkleidungs-Rohrschelle**| [`front_node_fairing_tube_clamp.stl`](../../hardware/cad/stl/04_front_node/front_node_fairing_tube_clamp.stl) | *Opt. (1)* | MJF PA12 / ASA | 2-teilige Rohrschelle (Ø 12–22 mm) für Verkleidungsgeweih & Streben unterm Fairing |

### 10.2 Gateway-Kassetten-Inlays (Passend zur gewünschten Intercom-Ausstattung)
> **Hinweis zur Architektur:** Slot 1 und Slot 2 sind **Multi-Protokoll Gateway-Transceiver**, keine Fahrer/Beifahrer-Kopfhörer! Sie verbinden das Motorrad gleichzeitig mit Sena Mesh und Cardo DMC. Fahrer und Sozius funken drahtlos mit ihren normalen Helmen.

| Baugruppe | STL-Dateiname | Stück | Material | Funktion & Beschreibung |
| :--- | :--- | :---: | :--- | :--- |
| **Gateway-Inlay Sena** | [`cartridge_insert_sena.stl`](../../hardware/cad/stl/03_pod_cartridges/cartridge_insert_sena.stl) | *Opt. (1)* | MJF PA12 / ASA | Formschlüssiges Inlay für Sena SPIDER X Slim (Mesh 3.0 / 2.0, Direkt-Micro-Kabelpeitsche) |
| **Gateway-Inlay Cardo** | [`cartridge_insert_cardo.stl`](../../hardware/cad/stl/03_pod_cartridges/cartridge_insert_cardo.stl) | *Opt. (1)* | MJF PA12 / ASA | Inlay für Cardo Packtalk Edge / Pro (DMC Gen2) mit Air-Mount |
| **Gateway-Inlay OMM UCS**| [`cartridge_insert_omm_ucs.stl`](../../hardware/cad/stl/03_pod_cartridges/cartridge_insert_omm_ucs.stl) | *Opt. (1..2)*| MJF PA12 / ASA | Formschlüssiges Inlay & Ladebucht für OMM 2.4 GHz UCS Modul im Pod |
| **OMM UCS Gehäuse-Oberschale**| [`omm_ucs_top_shell.stl`](../../hardware/cad/stl/03_pod_cartridges/omm_ucs_top_shell.stl) | *Opt. (1..2)*| MJF PA12 / ABS | Autonome OMM UCS Oberschale mit 4x DIN 934 M2 Mutterntaschen & Dichtnut |
| **OMM UCS Gehäuse-Unterschale**| [`omm_ucs_bottom_shell.stl`](../../hardware/cad/stl/03_pod_cartridges/omm_ucs_bottom_shell.stl) | *Opt. (1..2)*| MJF PA12 / ABS | Autonome OMM UCS Unterschale mit ECE 22.06 Schnapprasten & M2 Senkungen |
| **OMM UCS Silikon-Tastmatte**| [`omm_ucs_silicone_keypad.stl`](../../hardware/cad/stl/03_pod_cartridges/omm_ucs_silicone_keypad.stl) | *Opt. (1..2)*| Shore 50A Silikon| Nahtlose, 100% wasserdichte 4-Tasten-Schaltmatte mit diffusem LED-Dom |
| **Blindkassette / Dry Box** | [`cartridge_insert_blindkassette.stl`](../../hardware/cad/stl/03_pod_cartridges/cartridge_insert_blindkassette.stl) | *Opt. (1)* | MJF PA12 / ASA | Hermetischer Schutzschlitten für ungenutzten Slot oder regendichte Dry Box |
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

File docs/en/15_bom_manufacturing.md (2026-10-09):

# 15 - Bill of Materials (BOM), COTS Sourcing & SMT Manufacturing (All 7 PCBAs)

This document serves as the master reference (Single Source of Truth) for the complete Bill of Materials (BOM), manufacturing specifications for all 7 printed circuit board assemblies (PCBA 01 to PCBA 03, PCBA 05 to PCBA 08 - PCBA 04 is retired without replacement in v8.0) at JLCPCB / Eurocircuits, all mechanical 3D printed components, COTS procurement lists, and a comprehensive cost and ordering strategy (Solo builder vs. Community group buy).

---

## 1. PCBA 01: Central Box Main Controller (`openmotorbridge_central_box`, 4-Layer FR4 TG150)

| Designator | Component / MPN | Manufacturer | Package | LCSC / JLCPCB Part # | Function |
| :--- | :--- | :--- | :--- | :--- | :--- |
| **U1** | ESP32-S3-WROOM-1-N16R8 | Espressif Systems | SMD Module | C2913200 | Host MCU (Dual-Core, 16 MB Flash, 8 MB PSRAM) |
| **U2** | LM5164-Q1 | Texas Instruments | SOIC-8-EP | C2843477 | Automotive 65V Synchronous Buck Converter |
| **U3** | BQ24075RGTR | Texas Instruments | VQFN-16 | C15464 | Dynamic Power-Path Controller & LiPo Charger with TS |
| **U4** | BMI270 | Bosch Sensortec | LGA-14 | C2836813 | 6-Axis IMU for Lean Angle & Dynamics |
| **U5** | ES8388 | Everest Semi | QFN-28 | C365736 | 24-Bit Stereo Audio Codec (I2S ADC/DAC) |
| **U6** | TCAN334GDCNR | Texas Instruments | SOT-23-8 | C842340 | 3.3V Automotive CAN-FD Transceiver (±58V Fault) |
| **U7** | SX1262IMLTRT | Semtech | QFN-24 | C190184 | Onboard 868 MHz LoRa Transceiver (+22 dBm, 24/7 UPS buffered) |
| **U8** | DW3110 | Qorvo | QFN-16 (B.Cu) | C2934600 | IEEE 802.15.4z UWB Transceiver (6.5 GHz Ch. 5 Backbone) |
| **SW1** | TS-1187A-C-A-B | C&K / Omron | SMD Push-Button | C318884 | Hardware Pairing & Reset Button (3s Pair, 10s Purge) |
| **D1** | SMBJ33CA | Littelfuse | DO-214AA (SMB) | C87848 | TVS Diode (33 V Standoff, 53.3 V max Clamping) |
| **F1** | MF-MSMF050-2 | Bourns | 1812 SMD | C22668 | Resettable PPTC Fuse (500 mA Hold / 1.0 A Trip) |
| **LED1** | WS2812B-B | Worldsemi | 5050 SMD | C114586 | RGB Status LED for Visual Mode Diagnostics |
| **J1** | DTM13-12PA Header | TE Connectivity | Automotive 12P | Custom Part | Automotive Deutsch DTM-12 Interface (11 active pins) |
| **J2** | MicroSD Slot Push-Push | Molex / Korean Hro | SMD Push-Push | C266624 | 4-Bit SDIO Flash Card for Tour Logging |
| **J_BAT** | Molex Micro-Fit 3.0 2P | Molex | SMD Header | C289110 | Header for 2,200 mAh LiPo Backup Battery |
| **ANT1** | U.FL-R-SMT-1 | Hirose / Murata | SMD RF | C2834595 | LoRa 868 MHz U.FL socket to Taoglas FXP895 in lid |
| **ANT2** | U.FL-R-SMT-1 | Hirose / Murata | SMD RF (B.Cu) | C2834595 | UWB 6.5 GHz U.FL socket to Taoglas FXUWB10 in tub floor |

*(Note: Migration to All-UWB completely eliminates previous audio transformers T1, T2 and optocouplers OC1, OC2).*

---

## 2. Satellite Pod Enclosure (Elimination of PCBA 02)
> **Architecture Note (v8.5 / v9.0 Clean Architecture):**  
> The previous pod base carrier PCB `PCBA 02` has been **completely eliminated without replacement**.  
> The pod enclosure (`pod_base_housing.stl`) is a seamless, monolithic 1-piece 3D printed monocoque with zero internal active electronics. The 2-wire DC harness (+12V/5V and GND) feeds directly through the rear gland/M8 port and terminates at two gold-plated Mill-Max heavy-duty spring contact sleeves, mating directly with the rear gold pads `PAD1` and `PAD2` on `B.Cu` of `PCBA 03`.

---

## 3. PCBA 03: Universal Smart Cartridge Rev 3.0 (`openmotorbridge_pod_cartridge`, 2-Layer FR4 TG150, 2-Sided SMT)
> **Quantity Note:** Fitted **2x per motorcycle** (Slot 1 for Sena SPIDER X Slim, Slot 2 for Cardo Packtalk Edge or optional OMM 2.4 GHz Swap Cartridge).

| Designator | Component / MPN | Manufacturer | Package | LCSC / JLCPCB Part # | Function |
| :--- | :--- | :--- | :--- | :--- | :--- |
| **U1** | DW3110 | Qorvo | QFN-16 (B.Cu) | C2934600 | IEEE 802.15.4z UWB Transceiver (6.5 GHz Ch. 5 All-UWB Link) |
| **U2** | ES8388 / MCU | Everest / WCH | QFN-28 (F.Cu) | C2943200 | Low-Power Stereo Audio Codec & Host Controller |
| **Q1 - Q4** | AO3400A | Alpha & Omega | SOT-23 (B.Cu) | C20917 | 4x N-Channel Power MOSFETs ($30\,\text{V} / 5.7\,\text{A}$) for Solenoid Actuators |
| **D1 - D4** | 1N4148WS | Diodes Inc. | SOD-323 (B.Cu)| C2128 | 4x Flyback Suppression Diodes for Solenoid Coils |
| **F1** | MF-MSMF050-2 | Bourns | 1812 SMD | C22668 | Resettable PPTC Fuse for 5V Cartridge Rail |
| **J_ACT** | SM08B-SRSS-TB | JST | 8-Pin 1.0mm SMD | C160404 | Mechatronics Header for 4 Miniature Solenoids |
| **J_AUDIO_PWR**| SM08B-SRSS-TB | JST | 8-Pin 1.0mm SMD | C160404 | Audio & Power Header (Top, Isolated PGND / AGND Kelvin Grounds) |
| **ANT_UWB** | U.FL-R-SMT-1 | Hirose / Murata | SMD RF (B.Cu) | C2834595 | UWB Antenna Port to Taoglas FXUWB10 in Sled Floor Pocket |
| **PAD1, PAD2**| Mill-Max Contact Pads | Mill-Max / PCB | Gold Pad (B.Cu)| ENIG Surface | Rear DC Power Contact Pads (+12V/5V and GND) |

---

## 4. Assembly PCBA 04 (Rear Pod 3): Retired Without Replacement (Clean Architecture v8.0)

> [!NOTE]
> **Architecture Streamlining v8.0:** Circuit board `PCBA 04` and the 3rd satellite enclosure (Rear Pod 3) have been **completely eliminated without replacement**:
> 1. **LoRa 868 MHz (SX1262):** Sits directly on the Central Box (`PCBA 01`), backed up 24/7 by the UPS battery for continuous anti-theft sentry.
> 2. **Multi-GNSS (SAM-M10Q):** Sits in the cool ram-air intake zone on Front Node (`PCBA 05`), interfaced via Qwiic I2C (`J12`).
> 3. **Vehicle Wireless Backbone:** Transmitted via Ultra-Wideband (Qorvo DW3110 / 6.5 GHz Ch. 5, $< 0.4\,\text{ms}$ latency) between Front Node and Central Box.
> 4. **Rear Radar:** Connects directly to the Central Box via Whip 5 of the Deutsch DTM-12 automotive harness.

---

## 5. PCBA 05: Universal Front Node (`openmotorbridge_front_node`, 4-Layer FR4 TG150, 82 x 50 mm)

| Designator | Component / MPN | Manufacturer | Package | LCSC / JLCPCB Part # | Function |
| :--- | :--- | :--- | :--- | :--- | :--- |
| **U1** | ESP32-S3-WROOM-1U-N8R8 | Espressif Systems | SMD Module | `C2913200` | Dual-Core 32-Bit Xtensa LX7 (240 MHz, Vector-DSP, 8MB PSRAM, ext. U.FL) |
| **U2** | USB2514Bi-AEZG / USB2514B | Microchip | QFN-36 | `C16251` | Automotive/Industrial USB 2.0 High-Speed 480 Mbps 4-Port Hub Controller |
| **U3** | LMR36015FSCQRNXRQ1 | Texas Instruments | VQFN-12 | `C2843480` | Automotive 36V Synchronous Buck (5V / 2.0A, 91.8%) for Hub & Peripherals |
| **U4** | TPS2051BDBVR | Texas Instruments | SOT-23-5 | `C7818` | High-Side USB VBUS Power Switch (1.05A Clamp) for Port 2 Cold-Reboot Reset |
| **U5** | SC8102QDER | Southchip | QFN-32 | `C2843510` | Automotive Synchronous Buck with USB-PD 20W (9V/2.2A & QC3.0) for Smartphone Port 1 |
| **U6** | TCAN334GDCNT | Texas Instruments | SOT-23-8 | `C2843515` | 3.3V CAN Transceiver (5 Mbps CAN-FD capable, with Pin 8 Silent-Listen-Only Mode) |
| **U7** | DW3110 | Qorvo | QFN-16 (B.Cu) | `C2934600` | IEEE 802.15.4z UWB Transceiver (6.5 GHz Ch. 5 Backbone) |
| **K1** | CPC1017NTR | IXYS / Littelfuse | SOP-4 | `C26789` | 60V / 100mA 1-Form-A Solid-State Relay for switchable 120R CAN Termination (Auto-Sensing) |
| **Q1** | DMN63D8LDW-7 | Diodes Incorporated| SOT-363 | `C283890` | Dual N-Channel MOSFET (30V / 260mA) for directional mirror blind-spot LEDs (J9) |
| **Q2** | TPS1H100BQPWPRQ1 | Texas Instruments | HTSSOP-14 | `C2843520` | Automotive Smart High-Side Power Switch (up to 3.5A / 40W) for 12V Aux Light (J11) |
| **LED1**| WS2812B-2020 | Worldsemi | SMD 2020 | `C2843530` | Digitally controllable RGB status LED for enclosure lid light pipe |
| **MIC1**| MSM261S4030H0R / SPH0645 | Sipeed / Knowles | 3.5x2.65 mm SMD | `C544577` | Digital I2S MEMS Acoustic Microphone (Standard I2S, high availability) |
| **L1** | 4.7 µH Automotive Inductor | Sunlord / Wurth | SMD 5x5 mm | `C2843490` | Storage Inductor for LMR36015 5V Main Regulator |
| **L2** | 10 µH Automotive Inductor | Coilcraft / Wurth | SMD 7x7 mm | `C2843525` | Storage Inductor for SC8102 USB-PD Fast-Charge Buck (Port 1) |
| **J1** | JST-PH 2-Pin Header | JST | 2.00mm SMD | `C289115` | 12V Vehicle Power Input (KL15 & GND) |
| **J2** | JST-PH 3-Pin Header | JST | 2.00mm SMD | `C289116` | Cockpit CAN-Bus (CAN_H, CAN_L, GND with Auto-Sensing Relay) |
| **J3** | JST-PH 4-Pin Header | JST | 2.00mm SMD | `C289117` | Handlebar Multi-Button Interface (PTT, Cam-Action, Media-Voice, GND) |
| **J4** | JST-PH 4-Pin Header | JST | 2.00mm SMD | `C289117` | Upstream USB Port to Motorcycle Infotainment (Skyline OS / Boom! Box) |
| **J5** | JST-PH 4-Pin Header | JST | 2.00mm SMD | `C289117` | Port 1: Handlebar Smartphone (USB-PD 20W + High-Speed Data) |
| **J6** | JST-PH 4-Pin Header | JST | 2.00mm SMD | `C289117` | Port 2: Fairing Pigtail (shielded, 30 cm) to CP2AA CarPlay/AA Dongle |
| **J5_MP3**| JST-PH 4-Pin Header | JST | 2.00mm SMD | `C289117` | Port 3: Glovebox Cable for USB Drives (MP3s & Firmware Updates) |
| **J6_AUX**| JST-PH 4-Pin Header | JST | 2.00mm SMD | `C289117` | Port 4: Cockpit Accessories / Dashcam Storage / Zūmo Navi |
| **J7** | USB-C 16-Pin Receptacle IP67| GCT / Korean Hro | SMD Hybrid | `C2765186` | ESP32-S3 Service & Flash Port (Flank) with TPU Sealing Plug |
| **J8** | JST-PH 2-Pin Header | JST | 2.00mm SMD | `C289115` | Action-Cam 5V Charge-Only Power Port (up to 2.0A) |
| **J9** | JST-PH 3-Pin Header | JST | 2.00mm SMD | `C289116` | Mirror Blind-Spot Warning LEDs (12V_PROT, BSD_LEFT_N, BSD_RIGHT_N) |
| **J10** | JST-PH 2-Pin Header | JST | 2.00mm SMD | `C289115` | 12V Qi Wireless Charger Power (SP Connect / QuadLock Head) |
| **J11** | JST-PH 2-Pin Header | JST | 2.00mm SMD | `C289115` | 12V Aux Light (Adventure Driving Lights / Brake Flash Strobe) |
| **J12** | JST-SH 4-Pin Header | JST | 1.00mm SMD | `C289118` | Qwiic / STEMMA QT I2C Sensor Port (SAM-M10Q GNSS, TMP117, OPT3001) |
| **ANT1**| U.FL-R-SMT-1 | Hirose / Murata | SMD RF (B.Cu) | `C2834595` | UWB 6.5 GHz U.FL socket to Taoglas FXUWB10 in tub floor |

---

## 6. PCBA 06: MagSafe Framework Dock Adapter (`openmotorbridge_magsafe_dock`, 2-Layer FR4, 28 x 11.5 mm)

| Ref | Component / Type | Package | Specification & Function | LCSC Part |
| :--- | :--- | :--- | :--- | :--- |
| **`F1`** | 0ZCG0050FF2C | SMD 1206 | 500 mA Hold / 1000 mA Trip, 16V PPTC Resettable Fuse | `C207936` |
| **`D1`** | ESD5Z5.0T1G | SOD-323 | 5.0V Unidirectional TVS Diode (Transient Protection) | `C2834585` |
| **`U1`** | USBLC6-4SC6 | SOT-23-6 | 4-Channel ESD Protection Array ($<0.8\,\text{pF}$, $\pm 15\,\text{kV}$ ESD) | `C7519` |
| **`C1`** | 100nF 50V X7R | SMD 0603 | Ceramic Decoupling Capacitor on VCC_PROT | `C14663` |
| **`J1`** | M8 Wire Pads | SMD/THT 1x07 | 7-Pin Solder Pad Array with 0.6 mm Vias for M8 Harness Conductors | Custom |
| **`J2`** | MagSafe 6P Pads | SMD 1x06 | 6-Pin Gold-Plated Landing Pads for MagSafe Magnetic Pogo Coupler | `C224376` |
| **`H1`** | MountingHole_Pad | M2.5 (Ø 2.7 mm) | Hole Ø 2.7 mm, Pad Ø 4.5 mm, tied to System GND | Hardware |

---

## 7. PCBA 07: 2-in-1 LoRa Smart-Keyfob (`openmotorbridge_smart_keyfob`, 2-Layer FR4, 38 x 19 mm)

| Ref | Component / Type | Package | Specification & Function | LCSC Part |
| :--- | :--- | :--- | :--- | :--- |
| **`U1`** | nRF52840-QIAA-R | aQFN-73 | 32-Bit ARM Cortex-M4F SoC with Bluetooth 5.4, NFC & Crypto | `C190767` |
| **`U2`** | SX1262IMLTRT | QFN-24 | Semtech 868 MHz LoRa Transceiver (+22 dBm, TCXO) | `C90039` |
| **`U3`** | DRV2605LDGSR | VSSOP-10 | TI ERM/LRA Haptic Driver with Integrated Effect Library | `C61633` |
| **`U4`** | BQ51003YFPR | DSBGA-28 | TI 2.5W Qi Wireless Power Receiver Controller | `C144862` |
| **`U5`** | BQ25100YFPR | DSBGA-6 | TI Linear LiPo Charge Controller with 50 nA Quiescent Current | `C144857` |
| **`M1`** | VG1036001D | Coin 10x3.6mm | Vybronics LRA Linear Resonant Actuator (235 Hz Resonant Frequency) | Custom / Distrelec |
| **`BZ1`**| PKLCS1212E4001 | SMD 12x12mm | Murata SMD Piezo Sounder (85 dB @ 10 cm, 4 kHz) | `C94511` |

---

## 8. PCBA 08: Radar 2.0 Sub-MCU & 36-LED Wing Carrier (`openmotorbridge_radar_submcu`, 2-Layer FR4 TG150, 115 x 65 mm)

| Ref | Component / Type | Package | Specification & Function | LCSC Part |
| :--- | :--- | :--- | :--- | :--- |
| **`U1`** | ESP32-C5-WROOM-1-N8 | SMD Module | 32-Bit RISC-V Sub-MCU & 5.9 GHz V2X Uplink (2.4 GHz strictly disabled at rear) | `C2843550` |
| **`U2`** | LDO 3.3V 500mA | SOT-23-5 | TI TPS7A0533 / Richtek RT9013 LDO Voltage Regulator | `C505293` |
| **`U3`** | DW3110 | QFN-24 (4x4mm) | Qorvo Ultra-Wideband Transceiver (6.5 GHz Ch. 5/9, All-UWB backbone) | `C2834570` |
| **`D1..36`**| WS2812B-2020 | SMD 2020 | 36x Digital RGB LEDs in Dual Warning Wings (18 left, 18 right, autonomous strobe) | `C2843530` |
| **`J1`** | JST-JWPF 2-Pin | Automotive IP67 | 12V Power Supply Input (`RADAR_PWR_12V` / `RADAR_GND`) | `C2834590` |
| **`J2`** | JST-SH 1.0mm 4-Pin | SMD Right-Angle| UART Interface to Wheeltec MR20 mmWave Radar (AoP patch array on front) | `C136657` |
| **`J3`** | 4-Pin 2.54mm Header| 90° Right-Angle | Flashing & Debug Header (`3V3`, `TX`, `RX`, `GND`) at housing edge | `C12437` |
| **`J4`** | Hirose U.FL | SMT Vertical | 6.5 GHz UWB Antenna Port to Taoglas FXUWB10 Flex Antenna | `C14894` |
| **`U.FL_5G9`**| Hirose U.FL | SMT Vertical | 5.9 GHz V2X Antenna Port to Taoglas FXP524 Flex Antenna | `C14894` |

---

## 8b. PCBA 09: OMM 2.4 GHz Autonomous Intercom Module (`openmotorbridge_omm_ucs`, 2-Layer FR4 TG150, 60 x 30 mm)

## 8b. PCBA 09: OMM 2.4 GHz Autonomous Intercom Module (`openmotorbridge_omm_ucs`, 2-Layer FR4 TG150, 60 x 30 mm)

| Ref | Component / Type | Package | Specification & Function | LCSC Part |
| :--- | :--- | :--- | :--- | :---: |
| **`U1`** | ESP32-C6-MINI-1U | SMD Module w/ U.FL| 32-Bit RISC-V 160MHz Host MCU, Wi-Fi 6, 802.15.4 TDMA, BLE 5.3, 4MB Flash, integrated U.FL port for coax pigtail / stubby antenna | `C5267233` |
| **`U2`** | BQ24075RGTR | QFN-16 (3x3mm) | 1.5A LiPo PMIC with Dynamic Power Path Management (Zero-reboot UPS operation) | `C96825` |
| **`U3`** | XC6206P332MR | SOT-23-3 | 3.3V / 250mA Low-Iq LDO Voltage Regulator | `C5446` |
| **`U4`** | ES8388 | QFN-28 (4x4mm) | 24-Bit / 96kHz Stereo Audio Codec with separate L/R HP amps & differential mic preamp | `C365736` |
| **`U5`** | ESP32-PICO-V3-02 | QFN-48 (7x7mm) | Bluetooth Classic / BLE Co-Processor (Dual-Engine OMB Lite: HFP HD Voice, A2DP, Cross-Bridge, BLE GATT) | `C2686884` |
| **`ANT1`** | 2450AT18x100 | SMD 3216 (1.2x3.2mm) | 2.45 GHz Ceramic Chip Antenna for ESP32-PICO-V3-02 Bluetooth Co-Processor (Phone / Display link) | `C2909988` |
| **`J1`** | TYPE-C-31-M-12 | SMT/THT IP67 | Waterproof 16-Pin USB-C Receptacle (5V charging on the go via powerbank/bike, WebUSB DFU, cartridge dock) | `C2765186` |
| **`J_HELMET`**| SM06B-SRSS-TB | 6-Pin JST-SH 1.0mm Horiz.| Internal Helmet Audio & PTT port on B.Cu (HP_OUT_L, HP_OUT_R, AGND_SPK, MIC_IN+, AGND_MIC, BTN_PTT; 0V DC) | `C136657` |
| **`BAT1`** | BM02B-SRSS-TB | SMD 1.0mm pitch | Connection to internal 600-mAh LiPo pouch cell (with PCM) | `C2902341` |
| **`D1`** | WS2812B-2020 | SMD 2020 | RGB Status LED (Charge, Mesh channel, pairing indicator) | `C2843785` |
| **`D2`** | USBLC6-2SC6 | SOT-23-6 | High-speed TVS diode array for USB D+/D- and VBUS ESD protection | `C7519` |
| **`SW1..4`** | EVQ-P2 / KMT0 | SMD 3.5x2.8mm | 4x Tactile IP67 micro-switches (Power, Mesh, Vol+, Vol-) | `C318884` |
| **`R_NTC`** | 10k NTC 1% | 0402 | Battery temperature monitoring according to JEITA standard | `C25804` |

---

## 8c. PCBA 10: OMM 446 Analog & Digital PMR446 Module (`openmotorbridge_omm446_ucs`, 4-Layer FR4 TG150, 60 x 30 mm)

| Ref | Component / Type | Package | Specification & Function | LCSC Part |
| :--- | :--- | :--- | :--- | :---: |
| **`U1`** | ESP32-C6-MINI-1U | SMD Module w/ U.FL| 32-Bit RISC-V Host MCU, BLE 5.3 Setup, WebUSB DFU, AT-Command Engine for SA818-DMR | `C5267233` |
| **`U2`** | BQ24075RGTR | QFN-16 (3x3mm) | 1.5A LiPo PMIC with DPPM (In-operation USB charging, internal battery as UPS) | `C96825` |
| **`U3`** | SA818-DMR | SMD Module (16x38mm)| 446 MHz Analog FM & Digital DMR Tier I Transceiver (0.2W Helmet / 0.5W Bike) | `C2839211` |
| **`U4`** | ES8388 | QFN-28 (4x4mm) | 24-Bit Stereo Audio Codec for radio audio processing & helmet speakers | `C365736` |
| **`U5`** | ME6211C33M5G | SOT-23-5 | 3.3V / 500mA High-Speed Low-Dropout Voltage Regulator | `C82942` |
| **`U6`** | ESP32-PICO-V3-02 | QFN-48 (7x7mm) | Bluetooth Classic / BLE Co-Processor (Dual-Engine OMB Lite: HFP HD Voice, A2DP, Cross-Bridge, BLE GATT) | `C2686884` |
| **`ANT1`** | 2450AT18x100 | SMD 3216 (1.2x3.2mm) | 2.45 GHz Ceramic Chip Antenna for ESP32-PICO-V3-02 Bluetooth Co-Processor | `C2909988` |
| **`J1`** | TYPE-C-31-M-12 | SMT/THT IP67 | Waterproof 16-Pin USB-C Receptacle (5V DC power, charging on the go, WebUSB DFU, cartridge dock) | `C2765186` |
| **`J_HELMET`**| SM06B-SRSS-TB | 6-Pin JST-SH 1.0mm Horiz.| Internal Helmet Audio & PTT port on B.Cu (HP_OUT_L, HP_OUT_R, AGND_SPK, MIC_IN+, AGND_MIC, BTN_PTT; 0V DC) | `C136657` |
| **`J_RF`** | U.FL-R-SMT-1 | SMD U.FL Socket (B.Cu)| 50 Ohm U.FL RF connector for coax pigtail to waterproof SMA bulkhead or bike antenna | `C14899` |
| **`PAD_ANT`**| SMD Testpad D3.0mm| Copper Pad (F.Cu) | Alternate RF solder connection for internal helical antenna | - |
| **`BAT1`** | BM02B-SRSS-TB | SMD 1.0mm pitch | Connection to internal 600-mAh LiPo pouch cell (with PCM) | `C2902341` |
| **`D1`** | WS2812B-2020 | SMD 2020 | RGB Status LED (RX Green, TX Red, DMR Blue, Charging Yellow) | `C2843785` |
| **`D2`** | USBLC6-2SC6 | SOT-23-6 | High-speed TVS diode array for USB D+/D- and VBUS ESD protection | `C7519` |
| **`SW1..4`** | EVQ-P2 / KMT0 | SMD 3.5x2.8mm | 4x Tactile IP67 micro-switches (PTT, Mode, Ch+, Ch-) | `C318884` |

---
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

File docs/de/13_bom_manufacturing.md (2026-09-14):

# 13 - Stücklisten (BOM) & SMT-Fertigungsdaten (Alle 5 PCBAs)

Dieses Dokument enthält die vollständige Bauteilliste (Bill of Materials) und Fertigungsspezifikation für alle 5 Leiterplatten (PCBA 01 bis PCBA 05) bei JLCPCB / Eurocircuits, alle mechanischen 3D-Druck-Komponenten, das Inbetriebnahmeprotokoll, den JLCPCB SMT-Bestellleitfaden sowie die COTS-Einkaufsliste.

---

## 1. PCBA 01: Zentralbox Hauptplatine (`kicad_main_box`, 4-Layer FR4 TG150)

| Designator | Bauteil / MPN | Hersteller | Gehäuse | LCSC / JLCPCB Part # | Funktion |
| :--- | :--- | :--- | :--- | :--- | :--- |
| **U1** | ESP32-S3-WROOM-1-N16R8 | Espressif Systems | SMD Modul | C2913200 | Haupt-MCU (Dual-Core, 16 MB Flash, 8 MB PSRAM) |
| **U2** | LM5164-Q1 | Texas Instruments | SOIC-8-EP | C2843477 | Automotive 65V Synchronous Buck Converter |
| **U3** | BQ24075RGTR | Texas Instruments | VQFN-16 | C128509 | Dynamisches Power-Path Management & LiPo-Lader mit TS |
| **U4** | BMI270 | Bosch Sensortec | LGA-14 | C2838380 | 6-Achsen IMU für Schräglagen- & Bewegungserkennung |
| **U5** | ES8388 | Everest Semi | QFN-28 | C144547 | 24-Bit Stereo Audio Codec (I2S ADC/DAC) |
| **U6** | TCAN334GDCNR | Texas Instruments | SOT-23-8 | C842340 | 3.3V Automotive CAN-FD Transceiver (±58V Fault) |
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

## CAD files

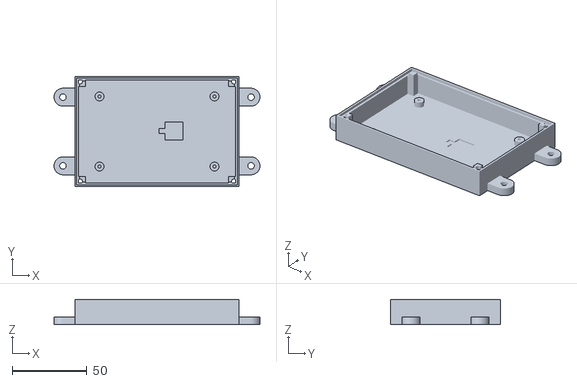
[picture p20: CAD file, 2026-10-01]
hardware/cad/stl/01_main_box/main_box_lower_case.stl
138.0 x 74.0 x 17.0

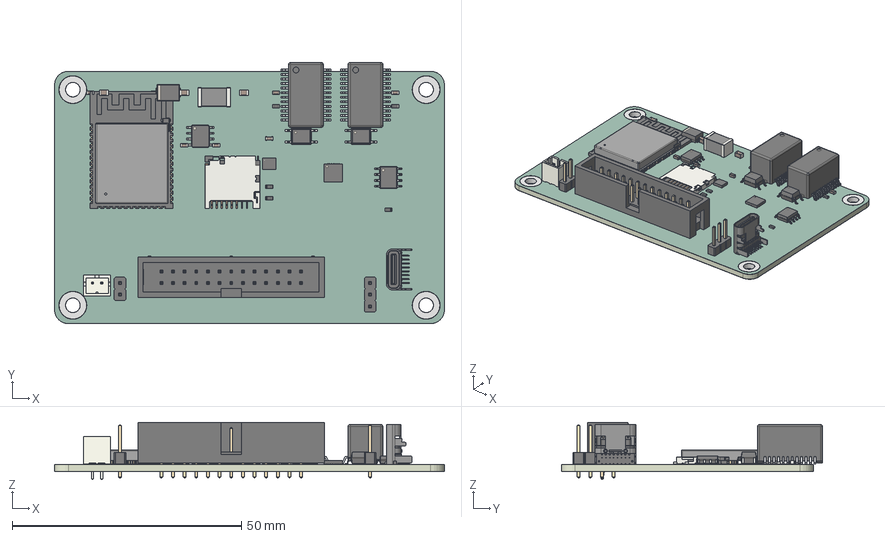
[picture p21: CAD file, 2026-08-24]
hardware/kicad_main_box/openmotorbridge_main_board.step
85.0 x 56.9 x 12.5 mm
C_0603_1608Metric x 6
R_0603_1608Metric x 7
PinHeader_1x02_P254mm_Vertical
D_SMB
SOIC-8_3.9x4.9mm_P1.27mm
ESP32-S3-WROOM-1
C_0805_2012Metric x 3
L_2816_7142Metric
USB_C_Receptacle_GCT_USB4085
Transformer_Ethernet_HALO_TG111-MSC13 x 2
Toshiba_SOIC-4-6_4.4x3.6mm_P1.27mm x 2
Bosch_LGA_14_3x25mm_P05mm
microSD_HC_Hirose_DM3D-SF
IDC_Header_2x13_P254mm_Vertical
PinHeader_1x03_P254mm_Vertical
SOIC-8-1EP_3.9x4.9mm_P1.27mm_EP2.41x3.81mm
JST_B2B_PH_K
SOT-23-5
QFN-28-1EP_4x4mm_Pitch0.4mm
openmotorbridge_main_pad
openmotorbridge_main_soldermask x 2
openmotorbridge_main_PCB

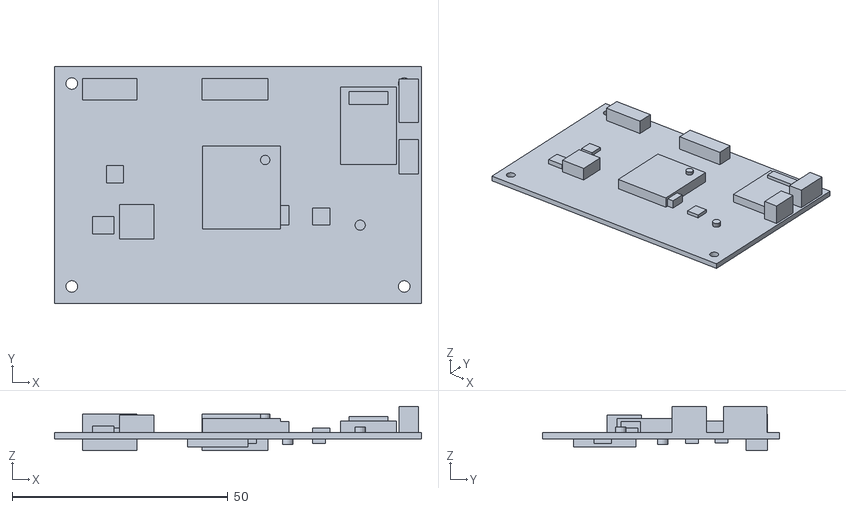
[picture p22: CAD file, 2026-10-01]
hardware/cad/stl/01_main_box/components/dummy_main_pcb.stl
85.0 x 55.0 x 10.2

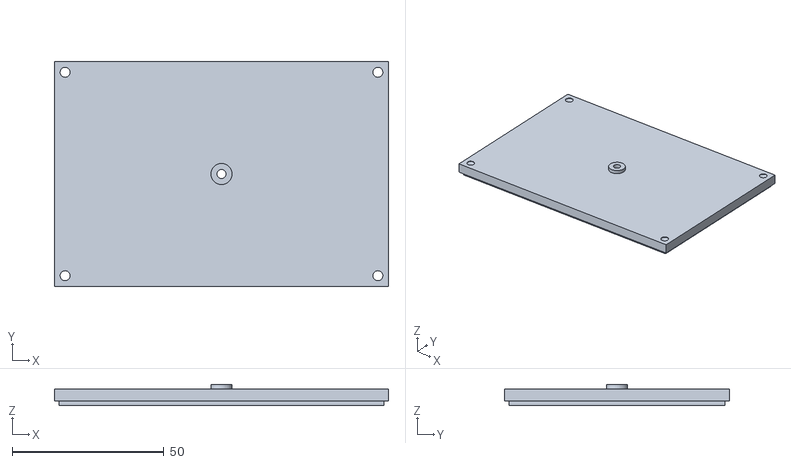
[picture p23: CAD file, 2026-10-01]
hardware/cad/stl/01_main_box/main_box_lid.stl
110.0 x 74.0 x 7.00

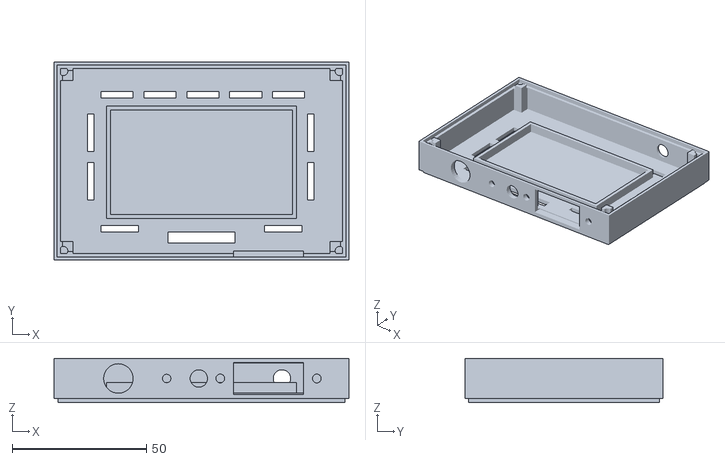
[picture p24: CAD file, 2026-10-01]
hardware/cad/stl/01_main_box/main_box_mid_tray.stl
110.0 x 74.0 x 16.5

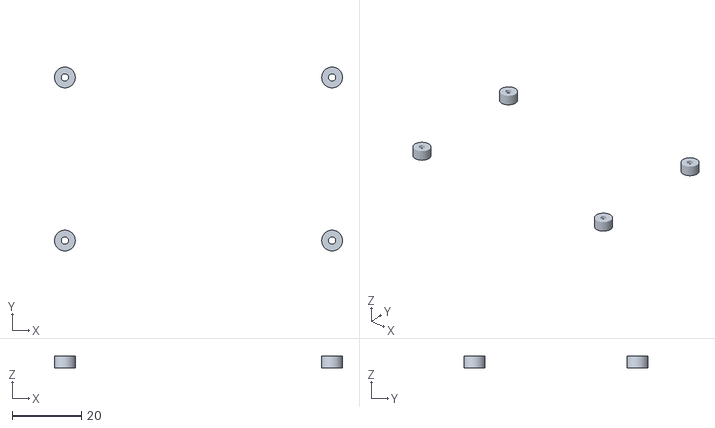
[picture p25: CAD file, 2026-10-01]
hardware/cad/stl/01_main_box/components/03_pcb_standoffs.stl
83.0 x 53.0 x 3.50

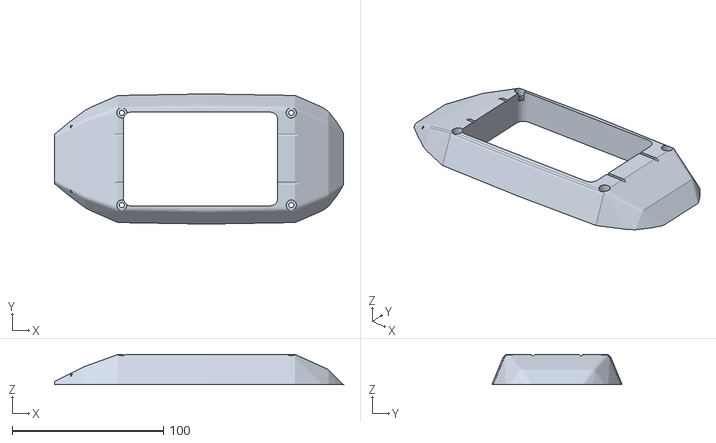
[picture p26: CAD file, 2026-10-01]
hardware/cad/stl/02_pod_base/adventure_transition_dock_lid.stl
191.0 x 86.0 x 20.0

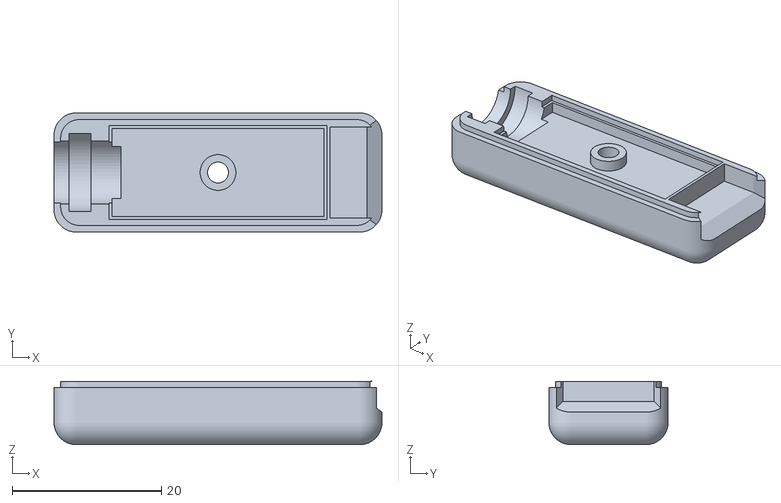
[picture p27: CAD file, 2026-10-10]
hardware/cad/stl/02_pod_base/components/009_magsafe_frame_lid.stl
44.0 x 16.0 x 8.50

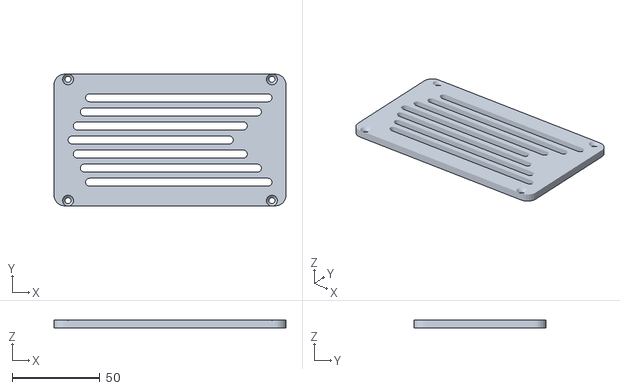
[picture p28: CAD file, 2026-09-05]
hardware/cad/stl/02_pod_base/design_studies/pod3_st_performance_hybrid_lid.stl
132.0 x 75.0 x 4.50

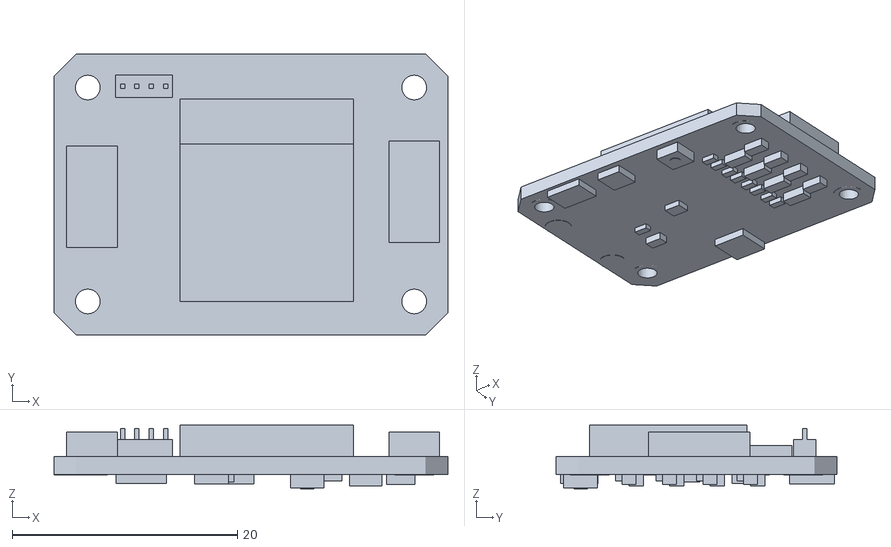
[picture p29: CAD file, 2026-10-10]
hardware/cad/stl/03_pod_cartridges/components/dummy_adapter_pcb.stl
35.0 x 25.0 x 5.67

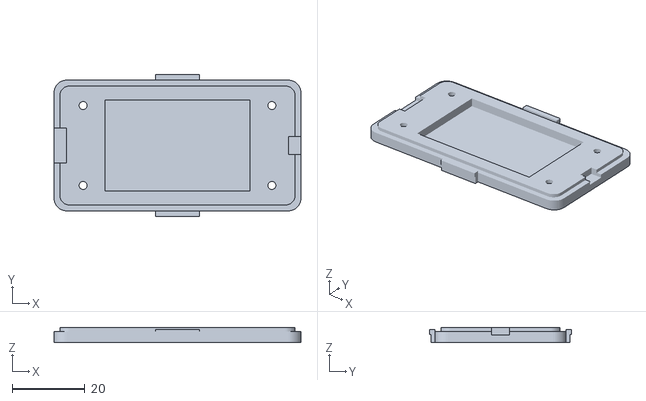
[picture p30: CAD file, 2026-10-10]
hardware/cad/stl/03_pod_cartridges/omm_ucs_bottom_shell.stl
68.0 x 39.2 x 4.00

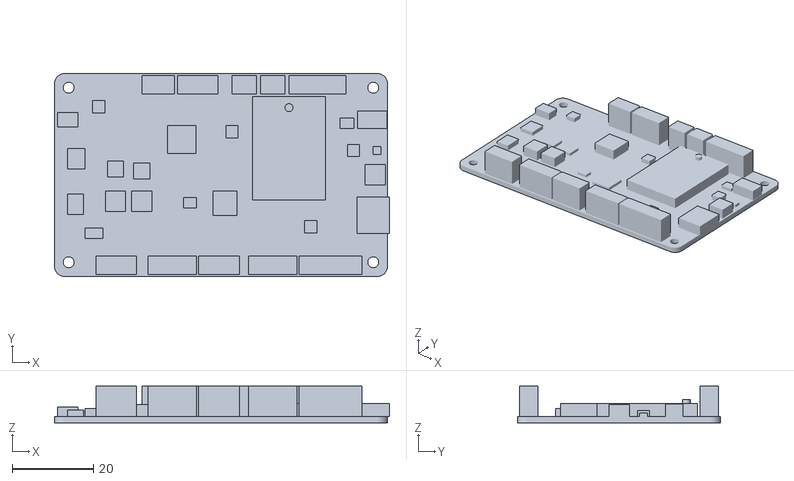
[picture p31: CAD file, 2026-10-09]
hardware/cad/stl/04_front_node/components/dummy_front_node_pcb.stl
82.5 x 50.0 x 9.10

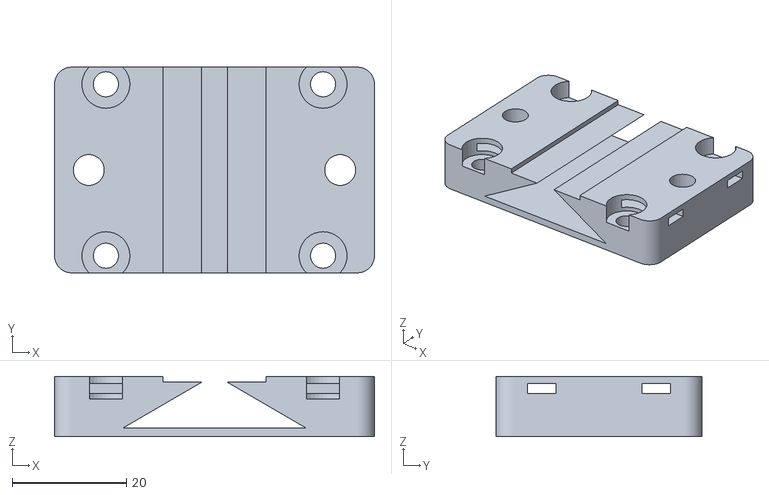
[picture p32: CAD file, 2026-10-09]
hardware/cad/stl/04_front_node/front_node_fairing_tube_clamp_base.stl
56.0 x 36.0 x 10.5

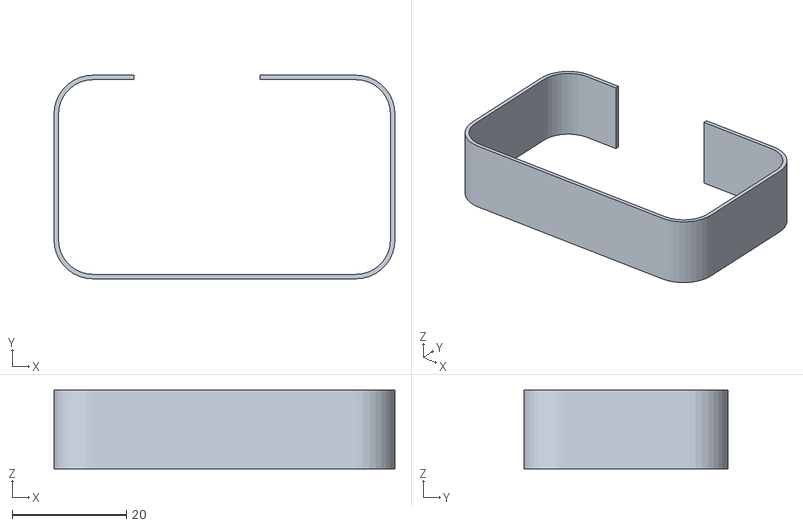
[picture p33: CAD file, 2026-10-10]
hardware/cad/stl/05_accessories/smart_keyfob_tpu_rim.stl
59.6 x 35.6 x 13.8

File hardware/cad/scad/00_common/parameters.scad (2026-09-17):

// =============================================================================
// OpenMotorBridge - Global CAD Parameters & Settings
// =============================================================================
// File: hardware/cad/scad/00_common/parameters.scad
// Description: Global dimensional constants, manufacturing clearances and
//              circle resolution ($fn) for all OpenSCAD modules.
// =============================================================================

// --- 1. Circle & Curve Resolution ---
$fn = 60; // Smooth cylinders and holes for high-quality MJF 3D printing

// --- 2. Central Main Box Dimensions (3-Tier Sandwich) ---
MAIN_BOX_OUTER_L      = 110.0; // Outer length in X (mm)
MAIN_BOX_OUTER_W      = 74.0;  // Outer width in Y (mm)
MAIN_BOX_LOWER_H      = 17.0;  // Lower case height in Z (mm)
MAIN_BOX_MID_H        = 15.0;  // Mid tray height in Z (mm)
MAIN_BOX_LID_H        = 4.0;   // Lid plate thickness in Z (mm)
MAIN_BOX_WALL         = 2.5;   // Nominal wall thickness (mm)
MAIN_BOX_CORNER_POST  = 7.0;   // Corner clamping screw post size (mm, for M3 hex nut pockets)

// --- 3. Satellite Pod Dimensions (Universal Enlarged Envelope) ---
POD_OUTER_L           = 135.0; // Outer length in X (mm)
POD_OUTER_W           = 70.0;  // Outer width in Y (mm)
POD_OUTER_H           = 38.0;  // Outer height in Z (mm)
POD_WALL              = 3.5;   // Nominal wall thickness (mm)
POD_BULKHEAD_X        = 18.0;  // Partition bulkhead position in X (mm)
POD_CHAMBER_L         = 117.0; // Sliding chamber length in X (mm)
POD_CHAMBER_W         = 63.0;  // Sliding chamber width in Y (mm)
POD_CHAMBER_H         = 31.0;  // Sliding chamber height in Z (mm)

// --- 4. Pod Linear Guide Rails (Poka-Yoke Tongue & Groove) ---
POD_GROOVE_W          = 3.0;   // Internal guide groove width in Z (mm)
POD_GROOVE_DEPTH      = 1.5;   // Internal guide groove depth in Y (mm)
POD_GROOVE_LEFT_Z     = 10.0;  // Center height of left groove (mm)
POD_GROOVE_RIGHT_Z    = 18.0;  // Center height of right groove (mm, asym offset)

CARTRIDGE_TONGUE_W    = 2.6;   // Cartridge tongue rail height in Z (mm, 0.2mm clearance)
CARTRIDGE_TONGUE_PROT = 1.4;   // Cartridge tongue protrusion in Y (mm, 0.1mm clearance)
CARTRIDGE_CHAMFER_L   = 4.0;   // 30° lead-in chamfer nose length (mm)

// --- 5. Cartridge Dimensions (Enlarged Universal Sled) ---
CARTRIDGE_BASE_L      = 116.0; // Sled length in X (mm)
CARTRIDGE_BASE_W      = 58.0;  // Sled width in Y (mm)
CARTRIDGE_BASE_H      = 28.0;  // Sled height in Z (mm)
CARTRIDGE_FACE_L      = 4.0;   // Front faceplate thickness in X (mm)
CARTRIDGE_FACE_W      = 64.0;  // Front faceplate width in Y (mm)
CARTRIDGE_FACE_H      = 34.0;  // Front faceplate height in Z (mm)

// --- 5a. RF Interface & Sealing Dimensions ---
SMA_BORE_R            = 3.25;  // Ø 6.5 mm through-hole for standard SMA bulkhead
SMA_ORECESS_R         = 4.75;  // Ø 9.5 mm recess for waterproof silicone O-ring
SMA_ORECESS_DEPTH     = 1.2;   // 1.2 mm deep O-ring compression pocket

// --- 5b. Magnetic Anti-Theft Lock System ---
LATCH_PIVOT_X         = 58.0;  // Center pivot position along sled X (mm)
LATCH_MAGNET_X        = 46.0;  // Ferromagnetic anchor position along sled X (mm)
LATCH_TOOTH_X         = 70.0;  // Locking sawtooth pawl position along sled X (mm)
LATCH_ARM_H           = 6.0;   // Rocker lever height in Z (mm)
LATCH_ARM_THICK       = 2.6;   // Rocker beam thickness in Y (mm)
LATCH_MAGNET_PIN_DIA  = 6.2;   // Bore for Ø 6.0 mm steel dowel pin (mm)
LATCH_SPRING_DIA      = 3.8;   // Bore for Ø 3.5 mm return compression spring (mm)

// --- 6. Standard Captive Hex Nut Pockets (DIN 934 / DIN 985 with +0.2 mm MJF/FDM clearance) ---
NUT_M2_SW             = 4.2;   // M2 across flats (nominal 4.0 mm)
NUT_M2_H              = 1.8;   // M2 thickness (nominal 1.6 mm)
NUT_M2_5_SW           = 5.2;   // M2.5 across flats (nominal 5.0 mm)
NUT_M2_5_H            = 2.2;   // M2.5 thickness (nominal 2.0 mm)
NUT_M3_SW             = 5.7;   // M3 across flats (nominal 5.5 mm)
NUT_M3_H              = 2.6;   // M3 thickness (nominal 2.4 mm)
NUT_M4_SW             = 7.2;   // M4 across flats (nominal 7.0 mm)
NUT_M4_H              = 3.4;   // M4 thickness (nominal 3.2 mm)
NUT_M5_SW             = 8.2;   // M5 across flats (nominal 8.0 mm)
NUT_M5_H              = 4.2;   // M5 thickness (nominal 4.0 mm)

// Direct Plastic Thread-Forming / Self-Tapping Pilot Holes in PA12 (100% Soldering-Iron Free)
M2_PILOT_HOLE_R       = 0.85;  // Core hole for M2 screws in PA12 (Ø 1.7 mm)
M2_5_PILOT_HOLE_R     = 1.05;  // Core hole for M2.5 screws in PA12 (Ø 2.1 mm)
M3_PILOT_HOLE_R       = 1.25;  // Core hole for M3 screws in PA12 (Ø 2.5 mm)

// --- 7. Screw & Clearance Dimensions ---
M2_SCREW_HOLE_R       = 1.1;   // M2 clearance hole (r = 1.1 mm -> Ø 2.2 mm)
M2_5_SCREW_HOLE_R     = 1.4;   // M2.5 clearance hole (r = 1.4 mm -> Ø 2.8 mm)
M3_SCREW_HOLE_R       = 1.65;  // M3 clearance hole (r = 1.65 mm -> Ø 3.3 mm)
M4_SCREW_HOLE_R       = 2.2;   // M4 clearance hole (r = 2.2 mm -> Ø 4.4 mm)
M8_BORE_R             = 4.0;   // M8 cable through-bore (r = 4.0 mm -> Ø 8.0 mm)
M8_STUDS_OUTER_R      = 6.0;   // M8 neck outer radius (Ø 12.0 mm)

// --- 8. Universal Front Node Enclosure Dimensions (Type E: 98 x 68 x 25 mm) ---
FRONT_NODE_PCB_L      = 82.0;  // PCB length in X (mm, PCBA 05)
FRONT_NODE_PCB_W      = 50.0;  // PCB width in Y (mm, PCBA 05)
FRONT_NODE_PCB_H      = 1.6;   // PCB thickness in Z (mm)
FRONT_NODE_PCB_R      = 2.5;   // PCB corner radius (mm)

FRONT_NODE_CHAMBER_L  = 86.0;  // Internal chamber length in X (mm, 2mm margin per side)
FRONT_NODE_CHAMBER_W  = 56.0;  // Internal chamber width in Y (mm, 3mm margin per side)
FRONT_NODE_TUB_H      = 17.5;  // Lower tub depth in Z (mm)
FRONT_NODE_LID_H      = 7.5;   // Upper lid height in Z (mm)
FRONT_NODE_WALL       = 2.5;   // Wall thickness in HP MJF PA12 (mm)
FRONT_NODE_CORNER_R   = 4.0;   // Outer enclosure corner radius (mm)

FRONT_NODE_OUTER_L    = FRONT_NODE_CHAMBER_L + 2 * FRONT_NODE_WALL + 7.0; // 98.0 mm
FRONT_NODE_OUTER_W    = FRONT_NODE_CHAMBER_W + 2 * FRONT_NODE_WALL + 7.0; // 68.0 mm
FRONT_NODE_OUTER_H    = FRONT_NODE_TUB_H + FRONT_NODE_LID_H;              // 25.0 mm

// PCB Standoff Heights & Radii (100% Soldering-Iron Free)
FRONT_NODE_STANDOFF_H = 3.0;   // Height of PCB standoffs from floor (mm)
FRONT_NODE_STANDOFF_R = 3.0;   // Outer radius of M2.5 screw bosses (mm)
FRONT_NODE_CORE_HOLE_R= M2_5_PILOT_HOLE_R; // Core hole for direct M2.5 screw engagement (Ø 2.1 mm)

// AMPS 4-Hole Mounting Pattern (38 x 30 mm with DIN 934 M4 Captive Nut Pockets)
AMPS_SPACING_X        = 38.0;  // AMPS hole distance in X (mm)
AMPS_SPACING_Y        = 30.0;  // AMPS hole distance in Y (mm)
AMPS_NUT_SW           = NUT_M4_SW; // Captive M4 hex nut pocket across flats (7.2 mm)
AMPS_NUT_H            = NUT_M4_H;  // Captive M4 hex nut pocket depth (3.4 mm)

// Acoustic Vent for Knowles SPH0645 MEMS
FRONT_NODE_MIC_HOLE_R = 1.25;  // Sound canal radius (Ø 2.5 mm)
FRONT_NODE_MIC_MEMB_R = 3.0;   // Gore ePTFE membrane pocket radius (Ø 6.0 mm)
FRONT_NODE_MIC_MEMB_D = 0.8;   // Membrane pocket depth (mm)

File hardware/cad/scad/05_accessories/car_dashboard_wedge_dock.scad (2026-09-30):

// =============================================================================
// OpenMotorBridge - Dual-Stack Dashboard Wedge Dock (Central Box + Front Node)
// =============================================================================
// File: hardware/cad/scad/05_accessories/car_dashboard_wedge_dock.scad
// Description: Two-tier vibration-damped automotive dashboard dock for support cars:
//              1. Lower Chamber (Tier 1, horizontal base):
//                 Slide-in pocket for the Front Node (PCBA 05, 98 x 68 x 25 mm).
//                 Front aperture provides direct sky/windshield view for the SAM-M10Q
//                 GNSS and Knowles MEMS microphone, with side access for Dual USB-PD.
//              2. Upper Deck (Tier 2, 15° forward tilt):
//                 Form-fit pocket for Central Control Box (PCBA 01, 110 x 74 x 32 mm).
//                 Ergonomically tilted at 15° for glare-free visibility of status LEDs.
//              3. Internal Vertical Passthrough Duct:
//                 Concealed cable channel connecting lower Front Node J1 (JWPF 2-pin)
//                 and upper Central Box J1 (Deutsch DTM-12) to the 12V Y-adapter harness.
//              4. Dual lateral finger release notches for 1-second insertion & removal.
//              5. 4x underside recesses for anti-slip silicone feet (Ø 12 x 1.5 mm).
// =============================================================================

include <../00_common/parameters.scad>;

// --- Parametric Dual-Stack Dock Dimensions ---
DOCK_TILT_ANGLE      = 15.0; // Ergonomic viewing angle for top deck (degrees)
DOCK_WALL            = 3.2;  // Wall thickness (mm)
DOCK_BASE_L          = MAIN_BOX_OUTER_L + 18.0; // 128.0 mm in X
DOCK_BASE_W          = MAIN_BOX_OUTER_W + 16.0; // 90.0 mm in Y

// Lower Tier (Front Node Chamber)
LOWER_POCKET_L       = FRONT_NODE_OUTER_L + 2.0; // 100.0 mm
LOWER_POCKET_W       = FRONT_NODE_OUTER_W + 2.0; // 70.0 mm
LOWER_POCKET_H       = FRONT_NODE_OUTER_H + 1.5; // 26.5 mm
LOWER_FLOOR_Z        = 2.5;                      // Floor thickness (mm)

// Upper Tier (Central Box Deck)
UPPER_POCKET_L       = MAIN_BOX_OUTER_L + 1.5;   // 111.5 mm
UPPER_POCKET_W       = MAIN_BOX_OUTER_W + 1.5;   // 75.5 mm
UPPER_POCKET_DEPTH   = 18.0;                     // Depth of upper pocket (mm)
UPPER_DECK_Z         = LOWER_FLOOR_Z + LOWER_POCKET_H + 3.0; // 32.0 mm base height of upper wedge

module car_dashboard_wedge_dock() {
    difference() {
        // --- 1. SOLID MULTI-TIER WEDGE BODY ---
        hull() {
            // Flat base footprint on dashboard
            translate([-DOCK_BASE_L/2.0, -DOCK_BASE_W/2.0, 0])
                cube([DOCK_BASE_L, DOCK_BASE_W, 2.0], center=false);

            // Intermediate body height for lower tier
            translate([-DOCK_BASE_L/2.0, -DOCK_BASE_W/2.0, UPPER_DECK_Z - 4.0])
                cube([DOCK_BASE_L, DOCK_BASE_W, 2.0], center=false);

            // Tilted upper rim
            translate([0, 0, UPPER_DECK_Z]) {
                rotate([0, -DOCK_TILT_ANGLE, 0]) {
                    translate([-DOCK_BASE_L/2.0, -DOCK_BASE_W/2.0, UPPER_POCKET_DEPTH + 2.0])
                        cube([DOCK_BASE_L, DOCK_BASE_W, 2.0], center=false);
                }
            }
        }

        // --- 2. LOWER TIER: FRONT NODE CAVITY (PCBA 05) ---
        translate([-LOWER_POCKET_L/2.0, -LOWER_POCKET_W/2.0, LOWER_FLOOR_Z]) {
            cube([LOWER_POCKET_L, LOWER_POCKET_W, LOWER_POCKET_H], center=false);
        }

        // Front Node front opening (slide-in & acoustic/GNSS aperture towards windshield)
        translate([-DOCK_BASE_L/2.0 - 5.0, -(LOWER_POCKET_W - 12.0)/2.0, LOWER_FLOOR_Z]) {
            cube([15.0, LOWER_POCKET_W - 12.0, LOWER_POCKET_H + 2.0], center=false);
        }

        // Lateral access cutouts for Front Node USB-PD ports (left & right)
        for (side = [-DOCK_BASE_W/2.0 - 2.0, DOCK_BASE_W/2.0 - 10.0]) {
            translate([-25.0, side, LOWER_FLOOR_Z + 4.0])
                cube([50.0, 12.0, LOWER_POCKET_H - 6.0], center=false);
        }

        // --- 3. UPPER TIER: TILTED CENTRAL BOX INSERTION POCKET ---
        translate([0, 0, UPPER_DECK_Z]) {
            rotate([0, -DOCK_TILT_ANGLE, 0]) {
                // Main Central Box cavity
                translate([-UPPER_POCKET_L/2.0, -UPPER_POCKET_W/2.0, 0])
                    cube([UPPER_POCKET_L, UPPER_POCKET_W, 40.0], center=false);

                // Front status LED viewing window
                translate([-DOCK_BASE_L/2.0 - 5.0, -(MAIN_BOX_OUTER_W - 12.0)/2.0, 5.0])
                    cube([15.0, MAIN_BOX_OUTER_W - 12.0, 35.0], center=false);

                // Rear cable passthrough (for Deutsch DTM-12 harness & USB-C media cable)
                translate([MAIN_BOX_OUTER_L/2.0 - 5.0, -22.0, 4.0])
                    cube([25.0, 44.0, 35.0], center=false);

                // Lateral finger extraction notches (left & right)
                for (side = [-DOCK_BASE_W/2.0 - 2.0, DOCK_BASE_W/2.0 - 10.0]) {
                    translate([-20.0, side, 8.0])
                        cube([40.0, 12.0, 30.0], center=false);
                }
            }
        }

        // --- 4. INTERNAL VERTICAL PASSTHROUGH DUCT ---
        // Connects lower tier (Front Node J1 JWPF) and upper tier (Central Box J1 DTM-12)
        translate([MAIN_BOX_OUTER_L/2.0 - 20.0, -18.0, LOWER_FLOOR_Z + 5.0]) {
            cube([22.0, 36.0, UPPER_DECK_Z + 15.0], center=false);
        }

        // --- 5. BASELINE CUTOUT (Ensure perfectly flat bottom at Z = 0) ---
        translate([-DOCK_BASE_L, -DOCK_BASE_W, -20.0])
            cube([DOCK_BASE_L * 2.0, DOCK_BASE_W * 2.0, 20.0], center=false);

        // --- 6. UNDERSIDE RUBBER FEET RECESSES (4x Ø 12 mm x 1.5 mm deep) ---
        for (dx = [-DOCK_BASE_L/2.0 + 16.0, DOCK_BASE_L/2.0 - 16.0]) {
            for (dy = [-DOCK_BASE_W/2.0 + 14.0, DOCK_BASE_W/2.0 - 14.0]) {
                translate([dx, dy, -0.1])
                    cylinder(r=6.0, h=1.6, center=false, $fn=32);
            }
        }
    }
}

car_dashboard_wedge_dock();

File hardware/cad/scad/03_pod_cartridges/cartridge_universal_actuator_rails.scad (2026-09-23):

// =============================================================================
// OpenMotorBridge - Smart Cartridge: Universal Actuator Rails & 2D Raster Plate
// =============================================================================
// File: hardware/cad/scad/03_pod_cartridges/cartridge_universal_actuator_rails.scad
// Description: Universal button actuation system for any third-party intercom,
//              pager, or radio transceiver placed inside the Smart Cartridge:
//              1. 2D Slotted Raster Lid (3mm pitch matrix & slotted guide rails)
//                 for pressing top-face buttons with Ø 6mm micro-solenoids.
//              2. Independent Left & Right Lateral Bracket Arms that slide along
//                 the sled flanks to actuate side rocker/volume keys at any position.
//              3. Eliminates custom CAD redesigns for future intercom generations.
// =============================================================================

include <../00_common/parameters.scad>;
include <../00_common/screw_bosses.scad>;
use <00_base_sled.scad>;

RASTER_L        = 110.0;  // Length in X matching standard cartridge bay (mm)
RASTER_W        = 53.0;   // Width in Y (mm)
RASTER_THICK    = 3.2;    // Rigid plate thickness (mm)
ACTUATOR_BORE   = 6.2;    // Ø for standard 6mm miniature push-pull micro-solenoid
RASTER_PITCH_X  = 6.0;    // Grid pitch along X (mm)
RASTER_PITCH_Y  = 6.0;    // Grid pitch along Y (mm)

// 1. 2D Slotted Raster Plate (Top-Face Button Actuator Carrier)
module universal_actuator_raster_lid() {
    difference() {
        union() {
            // Main rigid partition deck
            cube([RASTER_L, RASTER_W, RASTER_THICK], center=false);

            // Perimeter reinforcement rim
            difference() {
                translate([0, 0, RASTER_THICK])
                    cube([RASTER_L, RASTER_W, 2.5], center=false);
                translate([2.5, 2.5, RASTER_THICK - 0.1])
                    cube([RASTER_L - 5.0, RASTER_W - 5.0, 3.0], center=false);
            }

            // Lateral slide dovetail tabs for left/right bracket clamping
            for (dx = [25.0, 55.0, 85.0]) {
                translate([dx - 5.0, -1.8, 0])
                    cube([10.0, 1.8, RASTER_THICK + 1.0], center=false);
                translate([dx - 5.0, RASTER_W, 0])
                    cube([10.0, 1.8, RASTER_THICK + 1.0], center=false);
            }
        }

        // --- SUBTRACTIONS ---

        // 4x Corner Screwdriver / M2 Mount Clearances
        translate([3.5, 3.5, -1.0]) cylinder(r=1.6, h=8.0, center=false, $fn=16);
        translate([RASTER_L - 3.5, 3.5, -1.0]) cylinder(r=1.6, h=8.0, center=false, $fn=16);
        translate([3.5, RASTER_W - 3.5, -1.0]) cylinder(r=1.6, h=8.0, center=false, $fn=16);
        translate([RASTER_L - 3.5, RASTER_W - 3.5, -1.0]) cylinder(r=1.6, h=8.0, center=false, $fn=16);

        // 2D Matrix of Actuator Mounting Holes & Slots (X = 15 .. 95, Y = 10 .. 43)
        for (x = [18.0 : RASTER_PITCH_X : RASTER_L - 18.0]) {
            for (y = [12.0 : RASTER_PITCH_Y : RASTER_W - 12.0]) {
                // Actuator bore
                translate([x, y, -0.5])
                    cylinder(r=ACTUATOR_BORE/2.0, h=RASTER_THICK + 1.0, center=false, $fn=24);
                // Dual M2 counter-clamp screw holes flanking each solenoid bore
                translate([x, y - 4.5, -0.5])
                    cylinder(r=1.1, h=RASTER_THICK + 1.0, center=false, $fn=16);
                translate([x, y + 4.5, -0.5])
                    cylinder(r=1.1, h=RASTER_THICK + 1.0, center=false, $fn=16);
            }
        }

        // Central Wiring & Visual Inspection Slot (along centerline X = 35 .. 75)
        translate([35.0, RASTER_W/2.0 - 4.0, -1.0])
            cube([40.0, 8.0, RASTER_THICK + 2.0], center=false);
    }
}

// 2. Modular Lateral Actuator Bracket Arm (Left or Right Flank)
module lateral_actuator_bracket_arm(side = "left") {
    y_sign = (side == "left") ? -1 : 1;

    difference() {
        union() {
            // Dovetail Slider Shoe (snaps onto sled top/flank rim)
            translate([-7.5, 0, 0])
                cube([15.0, 4.0, 16.0], center=false);

            // Cantilever Outrigger Arm extending downwards over intercom flank
            translate([-6.0, y_sign * 2.0, -12.0])
                cube([12.0, 6.0, 14.0], center=false);

            // Actuator Clamp Head (Holds horizontal Ø 6mm micro-solenoid facing inward)
            translate([0, y_sign * 9.0, -8.0]) {
                rotate([90, 0, 0])
                    cylinder(r=5.5, h=8.0, center=true, $fn=32);
            }
        }

        // Horizontal Actuator Bore (Ø 6.2 mm) facing inwards into intercom button
        translate([0, y_sign * 9.0, -8.0]) {
            rotate([90, 0, 0])
                cylinder(r=ACTUATOR_BORE/2.0, h=14.0, center=true, $fn=24);
        }

        // Pinch Clamping Slot (1.2 mm split to clamp solenoid with M2 bolt)
        translate([-0.6, y_sign * 3.0, -14.0])
            cube([1.2, 12.0, 12.0], center=false);

        // Clamping screw bore (M2 across split)
        translate([-8.0, y_sign * 9.0, -8.0])
            rotate([0, 90, 0])
                cylinder(r=1.2, h=16.0, center=false, $fn=16);

        // Dovetail rail engagement slot
        translate([-8.0, -0.5, 1.0])
            cube([16.0, 2.5, 5.0], center=false);
    }
}

// 3. Full 3D Assembly Preview
module universal_actuator_assembly() {
    // A. Cartridge Base Sled
    color("darkslategray", 0.9)
        cartridge_base_sled(show_latch = true);

    // B. 2D Slotted Raster Lid
    color("steelblue", 0.92)
        translate([2.5, 2.5, 8.5])
            universal_actuator_raster_lid();

    // C. Sample Top-Face 6mm Micro-Solenoid (Centered on intercom key)
    color("gold")
        translate([55.0, RASTER_W/2.0 + 2.5, 12.0])
            cylinder(r=3.0, h=12.0, center=false, $fn=24);

    // D. Left Lateral Actuator Bracket
    color("crimson", 0.95)
        translate([42.0, 2.5, 10.0])
            lateral_actuator_bracket_arm(side = "left");

    // E. Right Lateral Actuator Bracket
    color("forestgreen", 0.95)
        translate([68.0, RASTER_W + 2.5, 10.0])
            lateral_actuator_bracket_arm(side = "right");
}

universal_actuator_assembly();

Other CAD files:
hardware/kicad_pod_base/openmotorbridge_pod_base.step
hardware/kicad_pod_cartridge/openmotorbridge_pod_cartridge.step
hardware/kicad_rear_pod3/openmotorbridge_rear_pod3.step
hardware/cad/stl/02_pod_base/components/cots_magnetic_frame_dock_body.stl
hardware/cad/scad/00_common/screw_bosses.scad
hardware/archive/kicad_pod_base/openmotorbridge_pod_base.step
hardware/archive/kicad_rear_pod3/openmotorbridge_rear_pod3.step
hardware/archive/kicad_rear_pod3/openmotorbridge_rear_pod3_board.step
hardware/cad/scad/00_common/dummies/dummy_adapter_pcb.scad
hardware/cad/scad/00_common/dummies/dummy_lipo_battery.scad
hardware/cad/scad/00_common/dummies/dummy_m8_connector.scad
hardware/cad/scad/00_common/dummies/dummy_main_pcb.scad
hardware/cad/scad/00_common/dummies/dummy_omm446_ucs_pcb.scad
hardware/cad/scad/00_common/dummies/dummy_omm_transceiver_pcb.scad
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

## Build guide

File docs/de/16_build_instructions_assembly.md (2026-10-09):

# 16 - Bauanleitung, Verkabelung & Fahrzeug-Installation

Dieses Dokument ist die vollständige, praxisorientierte Schritt-für-Schritt-Bauanleitung für den Zusammenbau und die fahrzeugspezifische Montage eines kompletten **OpenMotorBridge (v8.0 Clean Architecture)** Gesamtsystems.

---

## 1. Übersicht des Gesamtkits (Was wird gebaut?)

Ein vollständiges OpenMotorBridge-Fahrzeugkit besteht aus folgenden Kern-Baugruppen:

```text
                      +-----------------------------------------+
                      |    1x ZENTRALE MAIN BOX (IP67)          |
                      |    (Unter der Sitzbank / im Heck)       |
                      |    * Unterwanne + Zwischenboden + Deckel|
                      |    * Hauptplatine PCBA 01 (ESP32-S3)    |
                      |    * Onboard SX1262 LoRa 868 MHz        |
                                     +--------------------+--------------------+
                                           |
                          1x ZENTRALER KABELBAUM (DEUTSCH DTM-12 IP67/IP69K)
                                           |
          +--------------------------------+--------------------------------+
          |                                |                                |
          v Peitsche 1 (2-Draht DC 12V)    v Peitsche 2 (2-Draht DC 12V)    v Peitsche 3 (2-Draht DC 12V)
+------------------+             +------------------+             +------------------+
| 1x BUCHT 1 LINKS |             | 1x BUCHT 2 RECHTS|             | 1x HECK-RADAR 2.0|
| (Rahmen / Koffer)|             | (Rahmen / Koffer)|             | (Kennzeichen/Heck)
| * Universal-Pod  |             | * Universal-Pod  |             | * Wheeltec MR20  |
|   (Monocoque PA12|             |   (Monocoque PA12|             |   77GHz (PCBA 08)|
|    kein PCB 02!) |             |    kein PCB 02!) |             | * 36x Warn-LEDs  |
| * 2 Federkontakte|             | * 2 Federkontakte|             | * UWB Telemetrie |
| * KASSETTE 1     |             | * KASSETTE 2     |             |   & LED-Makros   |
|   (Sena / Cardo /|             |   (Sena / Cardo /|             +--------+---------+
|    OMM / Midland)|             |    OMM / Midland)|                      |
+--------+---------+             +--------+---------+                      |
         |                                |                                |
         | UWB Steuer- & Telemetrielink   | UWB Steuer- & Telemetrielink   | UWB Radar-Link
         +----------------+---------------+--------------------------------+
                          | Deterministischer All-UWB Fahrzeug-Backbone
                          | (Qorvo DW3110 / 6.5 GHz Ch. 5, < 0.4 ms)
                          v
                 +----------------------------------+
                 | 1x UNIVERSAL FRONT-KNOTEN (IP67) |
                 | (Cockpit- & Sensor-Hub, PCBA 05) |
                 | * u-blox SAM-M10Q Multi-GNSS     |
                 | * TI TMP117 & OPT3001 Sensoren   |
                 | * Knowles MEMS Fahrtwind-Sensor  |
                 | * 4-Port USB-Hub & Dual USB-PD   |
                 | * Batteriefreier Lenker-PTT      |
                 +----------------------------------+
```

---

## 2. Bereitstellung vor Montagebeginn (Pre-Assembly Checklist)

> [!TIP]
> **Geprüfte Passungsmaße & 100 % lötkolbenfreie Montage (IKEA-Prinzip):**  
> Alle 3D-Druckteile (`.scad` / `.stl`) wurden mit definierten Toleranzen ($+0{,}15\,\text{mm}$ für HP MJF PA12 bzw. ASA/PET-CF) konstruiert. Auf das fehleranfällige Einschmelzen von Gewindebuchsen (Ruthex) wurde im gesamten System konsequent verzichtet: Alle Verschraubungen nutzen ausnahmslos formschlüssige **DIN 934 Sechskant-Mutterntaschen** (einfach von Hand einlegen). Selbstschneidende Gewinde in Kunststoff sind im gesamten System verboten, sodass jedes Gehäuse beliebig oft geöffnet und gewartet werden kann, ohne dass Gewindegänge ausleiern oder Gehäuse nach einmaliger Demontage unbrauchbar werden.

Alle Einzelteile, Platinen-Bestelldaten und COTS-Zukauflisten sind detailliert in **[Kapitel 15: Stücklisten & SMT-Fertigungsdaten](15_bom_manufacturing.md)** aufgeführt. Vor Montagebeginn sicherstellen, dass folgende Baugruppen bereitliegen:

* [ ] **3D-Druckteile (MJF PA12 schwarz oder FDM ASA/PET-CF):**
  * 1x Main Box (Unterwanne mit UWB-Bodentasche $11 \times 11 \times 0{,}6\,\text{mm}$, Zwischenboden mit LiPo-Wanne, Deckel mit LoRa FXP895 Tasche $110 \times 20 \times 0{,}8\,\text{mm}$)
  * 2x Pod-Basisgehäuse (nahtlose 1-Teil-Monocoques mit integrierter monolithischer Schottwand, Mill-Max Federaufnahmen & Federdomen; 0 Schrauben, 0 lose Teile)
  * 2x Kassetten-Basisschlitten (mit UWB-Antennentasche & M2 Mutterntaschen), Inlays (Sena SPIDER X Slim, Cardo Packtalk Edge, Swap OMM oder Blindkassette) & 2x Rastwippen
  * 1x Front-Knoten (Unterwanne mit UWB-Bodentasche und AMPS-Nut-Pockets, Deckel, TPU-Dichtkämme & USB-C Kappe)
  * 1x Fahrzeugspezifisches Montage-Kit (BMW GS Klemmen & `adventure_rack_radar_mount.stl` / Harley Kofferdeckel-Docks & Kennzeichen-Radarhalter / Support-Car `car_sun_visor_pod_clip.stl`)
  * *(Optional für Helmeinsatz / OMM):* 1-2x OMM UCS Gehäuse-Oberschalen ([`omm_ucs_top_shell.stl`](../../hardware/cad/stl/03_pod_cartridges/omm_ucs_top_shell.stl)), Unterschalen ([`omm_ucs_bottom_shell.stl`](../../hardware/cad/stl/03_pod_cartridges/omm_ucs_bottom_shell.stl)) & Silikon-Tastmatten ([`omm_ucs_silicone_keypad.stl`](../../hardware/cad/stl/03_pod_cartridges/omm_ucs_silicone_keypad.stl))
* [ ] **Vollautomatisch bestückte Platinen (von JLCPCB / Eurocircuits - bis zu 8 PCBAs):**
  * 1x PCBA 01 (Zentralbox mit LoRa SX1262, DW3110 UWB, SW1 Taster und DTM-12 Header)
  * 2x PCBA 03 (Universal Smart Cartridge Rev 3.0 All-UWB mit DW3110 UWB, MCU und 4x AO3400A MOSFETs, 2-seitig SMT)
  * 1x PCBA 05 (Front-Knoten mit DW3110 UWB)
  * *(Optional: 1x PCBA 08 Radar 2.0 Sub-MCU mit DW3110 UWB, PCBA 06 MagSafe Dock, PCBA 07 Smart-Keyfob)*
  * *(Optional für Helm / OpenMotorMesh):* 1x **PCBA 09 (OMM 2.4 GHz HD-Mesh)** und/oder 1x **PCBA 10 (OMM 446 PMR/DMR Funk)**
  * *(Hinweis: PCBA 02 und PCBA 04 sind ersatzlos entfallen).*
* [ ] **V4A Edelstahl-Normteile & Federn (IKEA-Prinzip - 100 % lötfrei):**
  * 8x DIN 934 / DIN 985 M3 Edelstahlmuttern (für Gehäuse-Nut-Pockets)
  * 6x DIN 934 M4 Muttern (4x AMPS-Nut-Pockets in Front-Node Wanne, 2x Radar 2.0 Heck-Mutterntaschen)
  * 4x M3 x 40 mm Schrauben (Zentralbox), 4x M3 x 20 mm Schrauben (Front-Node)
  * 8x M2.5 x 6 mm Platinenschrauben (Zentralbox & Front-Node), 8x M2 x 6 mm Platinenschrauben (Kassetten PCBA 03; Schottwandschrauben entfallen komplett)
  * 4-8x DIN 934 M2 Muttern & 4-8x DIN 912 M2 x 8 mm Schrauben (für OMM UCS Modul-Verschraubung)
  * 2x DIN 7 M2 x 8 mm Zylinderstifte (Wippenachsen), 2x DIN 6325 Ø 6 x 8 mm gehärtete Stahlanker
  * 2x Wippen-Rückstellfedern, 4x Auto-Eject Druckfedern, 1x N52 Neodym-Entriegelungsschlüssel
  * 4x Vergoldete Mill-Max Hochstrom-Federkontakt-Hülsen für Pod 1 & 2 Stromzuführung
* [ ] **Dichtungen, Pufferakku & Antennen:**
  * Silikon-Rundschnur Ø 1,5 mm Shore 40A ($40\,\text{cm}$ Main Box, $30\,\text{cm}$ Front-Knoten)
  * Silikon-Rundschnur Ø 0,8 mm Shore 40A ($25\,\text{cm}$ pro OMM UCS Modul)
  * 2x Silikon-Flanschdichtungen für Pod 1 & 2 Mundlöcher, Gore ePTFE Membranpads
  * **1x 1S LiPo Flat-Pack 2.200 mAh** ($68 \times 39 \times 5{,}0\,\text{mm}$) mit Molex Micro-Fit 3.0 Stecker (Zentralbox USV)
  * **1-2x 1S LiPo Pouch-Akkus 600 mAh** ($38 \times 24 \times 4{,}5\,\text{mm}$) mit JST 2-Pin Stecker (OMM UCS Module)
  * **Taoglas FXUWB10 UWB Flex-Antennen** mit 20 mm U.FL Kabel (Zentralbox, Front-Node, Kassetten)
  * **1x Taoglas FXP895 LoRa 868 MHz Flex-Antenne** mit 50 $\Omega$ U.FL Kabel
  * **1x u-blox SAM-M10Q Multi-GNSS Modul** mit integrierter Patchantenne (Qwiic I2C)
  * **1x TI TMP117 & 1x TI OPT3001 Sensoren** (Qwiic I2C)
  * **1-2x HF-Koaxialpigtails U.FL auf SMA-Bulkhead** (RG-178 / 1.13mm, 50 mm) mit IP67 EPDM O-Ring und M6 V4A Mutter
  * **1x OMM 2.4 GHz Stummelantenne** (SMA-Male, $38\,\text{mm}$ Rubber-Duck Helix)
  * **1x OMM 446 MHz Stummelantenne** (SMA-Male, $48\,\text{mm}$ Helical Stubby)
* [ ] **Vorkonfektionierte COTS-Kabel (kein Crimpen nötig):**
  * 1x Deutsch DTM-12 IP67/IP69K Zentral-Kabelbaum (reine 2-Draht DC-Peitschen 1 bis 3 für Pod 1, Pod 2, Heck-Radar sowie Peitsche 4 für 12V Bordnetz & CAN)
  * 2-Pin JWPF / Superseal Steckverbinder für Pod- und Radar-Zuleitungen
  * JST-SH Kassetten-Kabelbäume (8-Pin `J_ACT` für Hubmagnete)
  * 1-2x OMM Helm-Audio & PTT-Kabelbäume (6-Pin JST-SH 1.0mm Buchse auf 3.5mm Klinke + Mic + PTT, AWG30/32 Silikon, $12\dots 15\,\text{cm}$)
* [ ] **Werkzeuge:**
  * Innensechskantschlüsselsatz (1.5 / 2.0 / 2.5 / 3.0 mm), Torx TX10 / PH1 Schraubendreher, Gabelschlüssel SW 7 / 8 / 10 mm, Cuttermesser, dielektrisches Silikonfett

---

## 3. Montage der Baugruppen (Schritt-für-Schritt)

### Schritt 1: Zentralbox (Main Box) montieren
1. **Muttern einlegen:** 4x DIN 934 / DIN 985 M3 Edelstahlmuttern von unten in die Sechskant-Mutternaschen der Unterwanne ([`main_box_lower_case.stl`](../../hardware/cad/stl/01_main_box/main_box_lower_case.stl)) eindrücken.
2. **UWB-Antenne im Boden installieren:**
   * Die flexible UWB-Antenne (Taoglas FXUWB10, $11 \times 11 \times 0{,}6\,\text{mm}$) in die Bodentasche der Unterwanne einlegen und mit der rückseitigen 3M-Klebeschicht fixieren.
   * Das 20 mm kurze U.FL Mikro-Koaxialkabel senkrecht nach oben führen. Da der DW3110 UWB-Transceiver und die Buchse `ANT2` direkt auf der Platinenunterseite (`B.Cu`) liegen, verbindet das Kabel die Antenne unmittelbar und ohne Querung der Leiterplatte.
3. **Hauptplatine einsetzen:**
   * Fertig bestückte PCBA 01 auf die Dämpferdome setzen.
   * U.FL-Stecker des UWB-Kabels senkrecht auf die Buchse `ANT2` auf der Platinenunterseite (`B.Cu`) aufklicken.
   * Platine mit 4x M2.5 $\times 6\,\text{mm}$ Schrauben handfest fixieren.
4. **LoRa-Antenne im Deckel installieren:**
   * Die flexible LoRa-Antenne (Taoglas FXP895, $110 \times 20 \times 0{,}8\,\text{mm}$) in die Deckeltasche des Gehäusedeckels ([`main_box_lid.stl`](../../hardware/cad/stl/01_main_box/main_box_lid.stl)) einkleben.
   * U.FL-Koaxialkabel an die Buchse `ANT1` auf der Oberseite der PCBA 01 anstecken.
5. **Zwischenboden & 2.200 mAh LiPo-Akku:** Den Zwischenboden ([`main_box_mid_tray.stl`](../../hardware/cad/stl/01_main_box/main_box_mid_tray.stl)) aufsetzen. Den **2.200 mAh Flat-LiPo-Akku** in die Wanne einlegen, das Molex Micro-Fit Kabel an `J_BAT` anstecken und mit EPDM-Band sichern.
6. **Dichtung & Deckel:** Silikon-Rundschnur (Ø 1,5 mm, $40\,\text{cm}$) dünn mit Silikonfett einreiben und in die Deckelnut einlegen. Gore-Membran auf den Belüftungssitz kleben. Den Deckel vorerst nur lose aufsetzen.

---

### Schritt 2: Satelliten-Pods 1 & 2 montieren (2x identisch, 100 % schraubenloses Monocoque)
1. **2-Draht-DC-Zuleitung einführen:** Die 2-adrige Gleichstromleitung (+12V/5V und GND) durch die rückseitige Kabeldurchführung oder M8-Verschraubung des monolithischen Pod-Basisgehäuses ([`pod_base_housing.stl`](../../hardware/cad/stl/02_pod_base/pod_base_housing.stl)) führen.
2. **Mill-Max Federkontakte einsetzen:** Die beiden vergoldeten Mill-Max Hochstrom-Federkontakt-Hülsen von hinten in die beiden Führungsbohrungen der integrierten Trennwand eindrücken und mit den Zuleitungsadern verbinden/verpressen.
3. **Auto-Eject Schnappfedern aufstecken:** Von vorne in den Kassetten-Schacht die beiden V4A-Druckfedern ($\varnothing 4{,}5 \times 15\,\text{mm}$) direkt auf die beiden integrierten Führungsdome der monolithischen Trennwand aufschieben.
4. **Schraubenlose Fertigstellung:** Da die Trennwand 100 % materialhomogen im 1-Teil-Monocoque integriert ist, entfällt jede Montage- und Senkkopfverschraubung (0 Schrauben). Die beiden vergoldeten Federkontakte ragen federnd in den Aufnahmeschacht. Wiederholen für Pod 2.

---

### Schritt 3: Multi-Protokoll Gateway-Kassetten 1 & 2 montieren
1. **UWB-Antenne & Platine im Schlitten montieren:**
   * Die flexible UWB-Antenne (Taoglas FXUWB10, $12 \times 12 \times 0{,}8\,\text{mm}$) in die Bodentasche des Kassetten-Schlittens ([`cartridge_base_sled.stl`](../../hardware/cad/stl/03_pod_cartridges/cartridge_base_sled.stl)) einlegen und das U.FL-Kabel in der Nut verlegen.
   * Kassettenplatine PCBA 03 Rev 3.0 auf die vier M2-Dome setzen, U.FL-Stecker auf `ANT_UWB` (`B.Cu`) aufklicken und Platine mit 4x M2 $\times 6\,\text{mm}$ Schrauben handfest fixieren. Die beiden vergoldeten Kontaktpads `PAD1` (+12V/5V) und `PAD2` (GND) auf der Platinenunterseite liegen durch das rückseitige Kontaktfenster frei zugänglich für die Mill-Max Stifte der Pod-Trennwand.
2. **Mechatronik-Aktuatoren & Niederhalteplatte montieren:**
   * 4x Miniatur-Hubmagnete ($\varnothing 6{,}5 \times 12\,\text{mm}$) mit dämpfenden TPU-Tastspitzen (`actuator_silicone_tip.stl`) in die vier Passbohrungen der Führungsbrücke des Inlays ([`cartridge_insert_sena.stl`](../../hardware/cad/stl/03_pod_cartridges/cartridge_insert_sena.stl) bzw. [`cartridge_insert_cardo.stl`](../../hardware/cad/stl/03_pod_cartridges/cartridge_insert_cardo.stl)) einstecken.
   * **Aktuator-Verkabelung an `J_ACT` (8-Pin JST-SH 1.0 mm):**
     * Das vorkonfektionierte 8-Pin Kabel auf den Header `J_ACT` aufstecken.
     * Die vier verdrillten Adernpaare (AWG30 Silikon) an die vier Hubmagnete führen (Paar 1 = Taste +, Paar 2 = Taste -, Paar 3 = Center/Phone, Paar 4 = Mesh/Pairing).
   * **Niederhalteplatte verschrauben:** Die PA12-Niederhalteplatte ([`cartridge_retainer_plate.stl`](../../hardware/cad/stl/03_pod_cartridges/cartridge_retainer_plate.stl)) plan über die Hubmagnete legen und mit **4x M2 $\times 6\,\text{mm}$ Senkkopfschrauben (DIN 7991)** fest anziehen. Die Aktuatoren sitzen nun absolut spielfrei und rüttelfest im Schlitten.
3. **Gateway-Inlay & OEM-Adapterkabel anschließen (`J_AUDIO_PWR` / 8-Pin JST-SH):**
   * **Bucht 1 (Sena SPIDER X Slim Inlay - OMB Referenz K2a):**
     * Vorkonfektioniertes 8-Pin JST-SH Adapterkabel auf Header `J_AUDIO_PWR` stecken (Pin 1: `PGND`, Pin 2: `VCC`, Pin 3: `AGND_SPK`, Pin 4/5: Stereo Spk In, Pin 6: `AGND_MIC`, Pin 7: Mic Out).
     * 2-Pin Micro-JST Stecker an die externe Akkuzuleitung des SPIDER X Slim anstecken (liefert permanente 3.85V Direct-DC Speisung ohne Akku im Pod!).
     * 2.5 mm Klinkenstecker an den Mikrofoneingang und 3.5 mm Klinkenstecker an den Lautsprecherausgang der Sena-Kabelpeitsche anstecken.
     * SPIDER X Slim formschlüssig in das PA12-Nest einlegen. *(Zero Pogo-Pins, Laststrom fließt isoliert über `PGND`, Audio über stromlose `AGND`-Pins 3 und 6 zu 100 % brummfrei).*
   * **Alternative Option: Universelle OEM-Upcycling-Kassette (Schuberth SC2, Shoei SRL-Mesh/SRL3, HJC Smart 50B - 0 € Budget-Option):**
     * *Vorbereitung (Battery Eliminator):* Gehäuse des ausgemusterten OEM-Intercoms (SC2, Shoei SRL oder Smart HJC) öffnen, LiPo-Pouch-Akku ablöten. Miniatur Step-Down-Wandler (z. B. MP2315) von `VCC` (5V von `J_AUDIO_PWR` Pin 2) auf $3{,}75\dots 3{,}85\,\text{V}$ einstellen und an `BAT+` / `BAT-` anlöten. Einen $10\,\text{k}\Omega$-Widerstand zwischen NTC-Pad und Masse (`GND`) anlöten (simuliert 22 °C Akkutemperatur gegen Sensor-Fehler). Litzen zugentlastet mit Silikon/B-7000 vergießen.
     * *Audio- & Antennen-Adaption:* 8-Pin JST-SH Kabelpeitsche mit den OEM-Lautsprecher- und Mikrofonleitungen verbinden (`AGND`-Massen getrennt!). Internes U.FL/Micro-Koaxialkabel auf ein kurzes RG-178 Pigtail zur SMA-Flanschbuchse der Kassettenstirnseite adaptieren.
     * *Montage im Schlitten:* Hauptmodul ($75 \times 40 \times 12\,\text{mm}$ oder flaches Nackenmodul) und Step-Down-Regler im Basisschlitten platzieren. Steuerung drahtlos über BLE-Lenkerfernbedienung (SC2 Remote oder Sena RC4) oder mechatronisch. Mit Blindkassettendeckel (`03_insert_blindkassette.scad`) und 4x M2-Schrauben wetterfest verschließen.
   * **Bucht 2 (Cardo Packtalk Edge / Pro Inlay - Klasse 1d DMC Gen2):**
     * 8-Pin JST-SH Adapterkabel auf Header `J_AUDIO_PWR` stecken.
     * 3.5 mm Stereo-Klinkenstecker (Lautsprecherausgang ins OMB-Audioboard) und Cardo 2-Pin Micro-Stecker mit Rastnase (Mikrofoneingang vom ES8388 DAC) an die Cardo Air-Mount Kabelpeitsche anstecken.
     * Rechtwinkligen USB-C Ladestecker an den Ladeport des Packtalk Edge anstecken.
     * Cardo Packtalk Edge in das Air-Mount Bett einklicken (Dauerladung während aktivem Mesh-Betrieb voll unterstützt; Laderückstrom fließt getrennt über `PGND` ab).
   * **Alternative Option: Midland PMR446 Funk-Kassette (Klasse 3a Analogfunk):**
     * 8-Pin JST-SH Adapterkabel auf Doppel-Klinke (2.5 mm Mic / 3.5 mm Spk) und 5V DC-Batteriedummy anstecken; PTT-Tastung erfolgt über Pin 8 (`PTT_IO` via MOSFET `Q4`).
   * **Alternative Option: OpenMotorMesh (OMM) 2.4 GHz / 446 Funk-Kassette (Klasse 4 / 3b UCS):**
     * 8-Pin JST-SH zu 90° USB-C Adapterkabel anstecken.
     * Nativ gefertigt im standardisierten **UCS-Formfaktor** (Universal Communication Solution), reines Digital-Audio über UWB mit getrennten Kelvin-Massen.
4. **Integrierte UWB-Antenne & Flanschdichtung:**
   * Auf `PCBA 03` arbeitet eine verlustarme SMD-Keramikantenne für 6.5 GHz UWB. Die Funkwellen durchdringen das dielektrische PA12-Gehäuse dämpfungsfrei; es sind keine externen Antennenradome erforderlich.
   * Silikon-Formdichtung auf den Kassettenkragen aufziehen und dünn mit Silikonfett benetzen.

---

### Schritt 3.1: Montage des magnetischen Diebstahlschutzes (Wippen-Mechanismus)
1. **Stahlanker einpressen:** Gehärteten Stahlstift ($\varnothing 6 \times 8\,\text{mm}$, DIN 6325) in die Querbohrung der Wippe ([`cartridge_magnetic_lock_latch.stl`](../../hardware/cad/stl/03_pod_cartridges/cartridge_magnetic_lock_latch.stl)) bündig einpressen.
2. **Rückstellfeder einsetzen:** Die kleine $\varnothing 3{,}5 \times 10\,\text{mm}$ Druckfeder in die innenseitige Federtasche stecken.
3. **Wippe im Schlitten montieren:** Vormontierte Wippe in die linke Führungswange des Kassetten-Schlittens einsetzen und mit dem $\varnothing 2{,}0 \times 8\,\text{mm}$ Edelstahl-Zylinderstift (DIN 7) lagern.
4. **Funktionsprüfung:** Sägezahn ragt $2{,}5\,\text{mm}$ heraus; bei Annäherung des N52 Neodym-Magneten schwenkt die Wippe bündig ein.

---

### Schritt 3.2: OMM UCS Intercom-Module (PCBA 09 & PCBA 10) zusammenbauen & für Helmmontage vorbereiten

Die beiden autarken Module (**PCBA 09: OMM 2.4 GHz HD-Mesh** und **PCBA 10: OMM 446 PMR/DMR**) teilen sich ein 100 % identisches ECE 22.06 UCS-Gehäuse ($68 \times 36 \times 9{,}5\,\text{mm}$) und werden nach folgendem Ablauf montiert:

1. **Muttern & Dichtungen in OMM-Gehäuse einlegen:**
   * 4x DIN 934 M2 Edelstahlmuttern von innen in die formschlüssigen Mutterntaschen der Oberschale ([`omm_ucs_top_shell.stl`](../../hardware/cad/stl/03_pod_cartridges/omm_ucs_top_shell.stl)) eindrücken.
   * Shore 50A Silikon-Tastmatte ([`omm_ucs_silicone_keypad.stl`](../../hardware/cad/stl/03_pod_cartridges/omm_ucs_silicone_keypad.stl)) formschlüssig in die Oberschale einpassen (Tastenknöpfe ragen durch die 4 Bohrungen, diffuser LED-Dom sitzt über der Aussparung für `D1`).
   * Silikon-Rundschnur ($\varnothing 0{,}8\,\text{mm}$, ca. $22\,\text{cm}$) dünn mit Silikonfett benetzen und in die umlaufende Dichtnut der Oberschale einlegen.
2. **HF-Koaxialpigtail & wasserdichte SMA-Durchführung montieren:**
   * Das $50\,\text{mm}$ kurze HF-Koaxialkabel (U.FL auf SMA-Bulkhead) an der Platine anschließen:
     * Bei `PCBA 09`: U.FL-Stecker senkrecht auf die integrierte U.FL-Buchse des `ESP32-C6-MINI-1U` (`U1`) aufklicken.
     * Bei `PCBA 10`: U.FL-Stecker auf die Buchse `J_RF` auf der Platinenunterseite (`B.Cu`) aufklicken.
   * Den EPDM/Silikon O-Ring ($\varnothing 6{,}0 \times 1{,}0\,\text{mm}$) auf das Gewinde der SMA-Bulkhead-Buchse schieben.
   * Die Buchse mit der D-Cut Abflachung in die $5{,}0 \times 4{,}0\,\text{mm}$ stirnseitige Aussparung an der $+X$-Flanke der Unterschale ([`omm_ucs_bottom_shell.stl`](../../hardware/cad/stl/03_pod_cartridges/omm_ucs_bottom_shell.stl)) einsetzen und von außen mit der V4A Edelstahlmutter und Fächerscheibe festziehen (IP67 Dichtsitz).
3. **Akku & Platinenmontage:**
   * Den 600 mAh LiPo Pouch-Akku in die zentrale Akkutasche ($X = 14\dots 54\,\text{mm}$) der Unterschale einlegen.
   * Den 2-Pin JST-Stecker des Akkus an `BAT1` anstecken.
   * Platine mit der Bestückungsseite nach oben in die Gehäuseführung einsetzen, sodass der USB-C Port `J1` exakt in der frontalen Dichtungsmanschette sitzt.
4. **Helm-Audio- & PTT-Kabelbaum anschließen (`J_HELMET`):**
   * Den 6-Pin JST-SH Stecker des Helm-Audio-Kabelbaums in den Header `J_HELMET` auf `B.Cu` ($X=126{,}5, Y=99{,}75\,\text{mm}$ in KiCad bzw. $X_{\text{mod}} = 60{,}5\,\text{mm}$, Buchsenöffnung zeigt nach innen) einstecken.
   * Das hochflexible AWG30/32 Silikonkabel in sanftem Bogen durch den rückseitigen Bodendurchbruch ($9{,}0 \times 9{,}0\,\text{mm}$ bei $X = 55\dots 64\,\text{mm}$) der Unterschale lastfrei nach unten herausführen.
5. **Gehäuse verschrauben (100 % lötkolbenfrei):**
   * Oberschale aufsetzen, umlaufende Dichtungsnaht kontrollieren.
   * 4x M2 $\times 8\,\text{mm}$ Zylinderkopfschrauben (DIN 912) von der Unterseite durch die Senkungen in die eingelegten DIN 934 M2 Muttern handfest über Kreuz anziehen.
6. **Stummelantenne aufschrauben:**
   * Für OMM 2.4 GHz (`PCBA 09`): Die $38\,\text{mm}$ kurze 2.4 GHz Rubber-Duck Stummelantenne auf die SMA-Buchse schrauben.
   * Für OMM 446 (`PCBA 10`): Die $48\,\text{mm}$ kurze 446 MHz Wendel-Stummelantenne auf die SMA-Buchse schrauben.
7. **Helmmontage (ECE 22.06 UCS-Schacht):**
   * Das fertige Modul in die herstellerseitige UCS-Helmmulde (z. B. HJC, Shoei, Schuberth) einschieben und formschlüssig einrasten.
   * Das aus dem Gehäuseboden austretende Audiokabel direkt und unsichtbar unter das Wangenpolster verlegen:
     - 3.5 mm Klinkenbuchse mit den Helmlautsprechern koppeln.
     - 2-Pin Mikrofonbuchse mit dem Schwanenhals- oder Klebemikrofon verbinden.
     - PTT-Leitung zum gewünschten Taster am Kinnteil oder Finger führen.
   * Der stirnseitige USB-C Port bleibt außen am Helm für Unterwegs-Laden per Powerbank oder WebUSB-Flashing zugänglich.

---

### Schritt 4: Universal Front-Knoten (PCBA 05) zusammenbauen
1. **Muttern einlegen (100 % lötkolbenfrei & dauerfest):**
   * **4x M3 Edelstahlmuttern (DIN 934 / DIN 985)** von unten in die formschlüssigen Sechskanttaschen der 4 Gehäuse-Ecken der Unterwanne ([`front_node_lower_tub.stl`](../../hardware/cad/stl/04_front_node/front_node_lower_tub.stl)) eindrücken (vollkommen analog zur Zentralbox).
   * **4x M4 Edelstahlmuttern (DIN 934)** in die formschlüssigen Sechskanttaschen des AMPS-Bohrbilds auf der Gehäuseunterseite einlegen.
   * *Ergebnis:* Reine Stahl-in-Stahl-Verschraubung. Das Gehäuse kann beliebig oft für Kabel-Upgrades oder Wartung geöffnet und mit vollem Anzugsmoment wieder rüttelfest verschraubt werden – kein Ausleiern von Kunststoffgewinden!
2. **UWB-Antenne im Boden installieren:**
   * Taoglas FXUWB10 Flex-Antenne in die Bodentasche der Unterwanne einkleben.
   * U.FL-Kabel nach oben führen.
3. **Platine montieren:**
   * Fertig bestückte PCBA 05 auf die Dämpferdome setzen.
   * UWB-Kabel an die U.FL-Buchse auf `B.Cu` aufklicken.
   * Platine mit 4x M2.5 Schrauben fixieren.
4. **Cockpit-Sensoren anschließen (J12 Qwiic):**
   * u-blox SAM-M10Q Multi-GNSS Modul (mit integrierter $15 \times 15\,\text{mm}$ Patchantenne) per Qwiic-Kabel an `J12` anstecken.
   * TI TMP117 Temperatursensor und TI OPT3001 Lichtsensor per Daisy-Chain am Qwiic-Bus im Kaltluft-Staudruckbereich platzieren.
5. **Akustik-Membran:** Hydrophobe Gore ePTFE-Membran über die Schalleintrittsöffnung des Sipeed/Knowles MEMS Mikrofons (`MIC1`) kleben.
6. **Kabel einlegen & Gehäuse vorbereiten:**
   * 12V KL15 & GND an `J1`, CAN-Bus an `J2`, PTT-Taster an `J3`, CP2AA Dongle an `J6`, Smartphone Fast-Charge an `J5`.
   * TPU-Dichtkämme einsetzen, Silikon-Rundschnur (Ø 1,5 mm, $30\,\text{cm}$) in Deckelnut einlegen und Deckel vorerst lose auflegen.

---

## 4. Tisch-Testaufbau & Dry-Run (Werkstatt / Schreibtisch) VOR der Bike-Montage

> [!NOTE]
> **Radikal vereinfachter Prüfaufbau (Zero USB-C an Pods):**  
> Durch die v9.6 All-UWB Clean Architecture besitzen die Pods keine externen USB-C-Buchsen mehr. Für den Tischaufbau und das Begleitfahrzeug speist ein kompaktes **12V Werkstatt- & Car-Y-Adapterkabel** parallel den **Front-Knoten (`J1` JST-JWPF)** und die **Zentralbox (`J1` DTM-12)**. Dadurch bleibt der USB-C Port der Zentralbox vollkommen frei für CarPlay/Android Auto oder PWA-Diagnose! Die beiden Kassetten werden über die 2-Draht-DC-Federkontakte der Zentralbox mitversorgt. Alle Audio-, Steuer- und Telemetriedaten funken drahtlos über UWB.

Das Gesamtsystem lässt sich auf der Werkbank mit minimalem Verkabelungsaufwand zu 100 % testen, flashen und koppeln:

```text
+-------------------------------------------------------------------------------------------------+
|                 OPENMOTORBRIDGE TISCH-TESTAUFBAU & DRY-RUN (BENCH-LABOR SETUP)                  |
+-------------------------------------------------------------------------------------------------+
|                                                                                                 |
|   [ 12V DC Labornetzteil / 12V Kfz-Zigarettenanzünder / LiFePO4 Akku ]                          |
|        |                                                                                        |
|        | 12V DC Haupt-Zuleitung (FLRY 2x 0.75 mm² / AWG18)                                      |
|        |                                                                                        |
|        +--- 12V Y-ADAPTERKABEL ("Bench & Support-Car Harness") -----------------------+         |
|        |                                                                              |         |
|        | Abzweig A: 12V DC (JST-JWPF 2P)            Abzweig B: 12V DC (Deutsch DTM-12)|         |
|        v                                            v                                 |         |
|   +---------------+                            +---------------+                      |         |
|   |  FRONT-NODE   |  (Cockpit Hub PCBA 05)     |  ZENTRALBOX   |  (PCBA 01)           |         |
|   |  Port J1 12V  |  Dual SW3526 USB-PD        |  Port J1 DTM12|  LM5164 Buck, BQ USV |         |
|   |  Qwiic SAM-M10|  Knowles I2S MEMS          |  LoRa SX1262  |  Qualcomm QCC3084    |         |
|   +-------+-------+                            +-------+-------+                      |         |
|           |                                            |                              |         |
|           |                                            | 2-Draht 5V DC                |         |
|           |                                            v                              |         |
|           |                                   +-----------------+                     |         |
|           |                                   | SATELLITEN-PODS |                     |         |
|           |                                   | (Pod 1 & Pod 2) |                     |         |
|           |                                   | Pure DC Federn  |                     |         |
|           |                                   +--------+--------+                     |         |
|           |                                            |                              |         |
|           |                                            v                              |         |
|           |                                   +-----------------+                     |         |
|           |                                   | SMART KASSETTEN |                     |         |
|           |                                   | (Sena / Cardo / |                     |         |
|           |                                   |  OMM / Midland) |                     |         |
|           |                                   +--------+--------+                     |         |
|           |                                            |                              |         |
|           |          All-UWB Wireless Backbone         |                              |         |
|           |<==========================================>|                              |         |
|           |            (6.5 GHz, < 0.4 ms)             |                              |         |
|           |                                            v                              |         |
|           |                                   +-----------------+                     |         |
|           |                                   |   HECK-RADAR    |<--------------------+         |
|           |<=================================>|    (PCBA 08)    |  Opt. Abzweig C       |
|           |                                   | 36x Strobe-LEDs |  (12V DC JST-JWPF)    |
|           |                                   +-----------------+                       |
|           |                                            |                                |
|           v WebBLE / WebSerial                         v Bluetooth                      |
|     [ SMARTPHONE / LAPTOP MIT PWA ]             [ FAHRER-HELM ]                         |
|     (Dashboard & Flashing via USB-C / WebBLE)   (Dual-A2DP aptX HD)                     |
|                                                                                         |
+-------------------------------------------------------------------------------------------------+
```

### 4.0 Das universelle 12V Werkstatt- & Begleitfahrzeug-Y-Adapterkabel ("Bench & Support-Car Harness")

Um sowohl für den Prüfstandsbetrieb im Labor als auch für Begleitfahrzeuge (Support-Van, Mietwagen, Pkw-Rennleitung) eine absolut saubere, verwechslungsfreie und zerstörungsfreie Stromversorgung zu garantieren, wird das **12V-Y-Adapterkabel** verwendet. Es versorgt Front-Node und Zentralbox parallel aus einer 12V-Gleichspannungsquelle, wodurch der USB-C Port der Zentralbox für Apple CarPlay / Android Auto frei bleibt:

| Abschnitt / Ende | Steckverbinder & Typ | Pinbelegung | Kabelspezifikation | Funktion |
| :--- | :--- | :--- | :--- | :--- |
| **Eingang** | **Kfz-Zigarettenanzünderstecker** (mit 5A Glas-Sicherung) *oder* **4mm Labor-Bananenstecker** | Spitze / Rot: `+12V DC`<br>Flanken / Schwarz: `GND` | Stammkabel: $2 \times 0{,}75\,\text{mm}^2$ (AWG18) FLRY / Silikon, Länge $1{,}0\,\text{m}$ | Zentrale 12V DC Einspeisung aus Bordnetz oder Labornetzteil |
| **Abzweig A**<br>*(Front-Node)* | **JST JWPF 2-Pin Buchse**<br>Gehäuse: `02R-JWPF-VSLE-S`<br>Kontakte: `SWPR-001T-P025` | **Pin 1:** `+12V` (Rot, KL15)<br>**Pin 2:** `GND` (Schwarz) | $2 \times 0{,}5\,\text{mm}^2$ (AWG20), Länge $1{,}5\,\text{m}$ (flexibel bis zur Windschutzscheibe) | Speist den Cockpit-Hub PCBA 05 samt USB-PD Lader und GNSS |
| **Abzweig B**<br>*(Zentralbox)* | **Deutsch DTM-12 Buchsenstecker**<br>Gehäuse: `DTM-06-12S`<br>Keil: `WM-12S`, Pins: `0462-201-20141` | **Pin 1:** `KL30` (+12V)<br>**Pin 2:** `KL15` (+12V, gebrückt)<br>**Pin 3:** `GND` (Schwarz)<br>Pins 4–12: Blindstopfen `0413-204-2005` | $2 \times 0{,}75\,\text{mm}^2$ (AWG18), Länge $0{,}5\,\text{m}$ | Speist die Zentralbox direkt in den LM5164-Q1 72V Buck & BQ24075 USV |
| **Abzweig C**<br>*(Opt. Radar)* | **JST JWPF 2-Pin Buchse**<br>Gehäuse: `02R-JWPF-VSLE-S` | **Pin 1:** `+12V` (Rot)<br>**Pin 2:** `GND` (Schwarz) | $2 \times 0{,}35\,\text{mm}^2$ (AWG22), Länge $0{,}5\,\text{m}$ | Für Tisch-Prüfungen des Heckradars PCBA 08 auf der Werkbank |

> [!TIP]
> **Warum kein USB-C für die Stromversorgung der Zentralbox?**  
> 1. **CarPlay & Infotainment:** Im Begleitfahrzeug wird der USB-C Port der Zentralbox direkt mit der USB-Media-Buchse des Fahrzeugs verbunden, um kabelgebundenes Apple CarPlay / Android Auto auf das Auto-Display zu spiegeln. Wäre dieser Port durch ein Stromkabel vom Front-Node belegt, entfiele die Head-Unit-Integration!  
> 2. **Voller USV-Ladestrom:** Über den DTM-12-Eingang arbeitet der interne 72V-Buck-Converter (LM5164-Q1) im optimalen Wirkungsgradbereich und lädt die 2.200-mAh-USV zügig mit vollen $1{,}0\,\text{A}$, während beide Kassetten-Pods stabil mit 5V versorgt werden.

### 4.1 Der geführte 4-Punkte IKEA Smoke-Test
In der PWA (über WebSerial oder WebBLE) den Diagnosetest ausführen:
1. [x] **Bordnetz & USV (Check 1):** LM5164 Buck-Schiene aktiv (5.04 V), USV-LiPo (2.200 mAh) lädt mit 4.18 V.
2. [x] **Kassetten & Aktuatoren (Check 2):** UWB Handshake (`UWB_PKT_CARTRIDGE_ANNOUNCE`), Modell-Erkennung (Sena / Cardo / OMM / Midland) und mechatronischer Klicktest der 4 Aktuatoren ("Klack-Klack-Klack-Klack").
3. [x] **Front-Knoten & UWB Backbone (Check 3):** UWB-Link aktiv ($< 0{,}4\,\text{ms}$ Latenz), SAM-M10Q 3D-Fix, TMP117 Temperatur, Knowles MEMS Pegel & PTT-Tastendruck.
4. [x] **LoRa 868 MHz & Radar 2.0 (Check 4):** SX1262 LoRa Ping-Echo und drahtloser UWB-Telemetrie-Link zum Heckradar 2.0 (`PCBA 08`) inklusive 36-LED Flügel-Makrotest.
Erst wenn alle 4 Checks grün leuchten, die Gehäusedeckel mit den M3-Schrauben über Kreuz festziehen.

---

## 5. Fahrzeugspezifische Montage & Verkabelung am Motorrad

### 5.1 Montage Harley-Davidson Plattform (Touring, CVO ST, Road King)
* **Zentralbox:** Unter der Fahrersitzbank auf der Rahmenbrücke vor der Batterie auf 4x M4 Silentblöcken verschrauben.
* **Pod 1 & Pod 2:** Auf den Hartschalenkoffern mittels Kofferdeckel-Docks ([`saddlebag_lid_dock.stl`](../../hardware/cad/stl/02_pod_base/saddlebag_lid_dock.stl)) montieren.
* **Koffer-Trennstelle (2-Pin Magnet-Pogo "MagSafe-Ersatz"):**
  * **Rahmenseitiges Dock (bei Festmontage):** Das 3D-Druck COTS-Rahmendock ([`cots_magnetic_frame_dock_body.stl`](../../hardware/cad/stl/02_pod_base/components/cots_magnetic_frame_dock_body.stl)) mit Klemmschelle ([`cots_magnetic_frame_clamp.stl`](../../hardware/cad/stl/02_pod_base/components/cots_magnetic_frame_clamp.stl)) am Ø 26 mm Rahmenrohr unter dem Sitzüberhang mit 4x M3 $\times 16\,\text{mm}$ Schrauben verschrauben (DIN 934 Nut-Pockets). Die 2-Pin Magnet-Pogo Buchse (HytePro M411) formschlüssig einlegen (der integrierte Haltekragen verhindert jedes Herausziehen beim Abreißen) und an Peitsche 1 bzw. 2 des DTM-12 Kabelbaums anschließen. *(Alternativ: Reiner elastischer Inline-Breakaway-Kabelstrang ohne festes Gehäuse).*
  * **Koffer-Vorderwand & Dichtung:** Ein einzelnes $\varnothing 12\,\text{mm}$ Loch seitlich-innen an der Koffer-Vorderwand oberhalb des Schwingenlagers bohren (im Wind- und Spritzwasserschatten; der **Kofferboden bleibt zu 100 % lochfrei**). Die geteilte EPDM/TPU-Dichtung ([`010_saddlebag_hole_grommet_split.stl`](../../hardware/cad/stl/02_pod_base/parts/010_saddlebag_hole_grommet_split.stl)) einsetzen, das 2-adrige Flachbandkabel der Magnetstecker-Kupplung hindurchführen und am integrierten Klemmturm per Mini-Kabelbinder zugentlasten. Im Kofferinneren das Kabel parallel zum Deckel-Fangband lastfrei zum Kofferdeckel-Dock führen.
* **Heck-Radar (Schwerlast-Neigegelenk & Spritzwasserschutz):**
  * **Vormontage auf der Werkbank (100 % lötkolbenfrei):** Das versiegelte Radar 2.0 Gehäuse ([`radar_mr20_housing.stl`](../../hardware/cad/stl/05_accessories/radar_mr20_housing.stl)) mit seinen zwei innenliegenden DIN 934 M4-Muttern wird über zwei DIN 912 M4 $\times$ 12 mm Schrauben fest an die Adapterplatte ([`radar_swivel_tilt_cradle.stl`](../../hardware/cad/stl/02_pod_base/radar_swivel_tilt_cradle.stl)) geschraubt. Die Passungs-Bosse nehmen 100 % der Scherkräfte auf.
  * **Option A: Montage am Kennzeichenträger:** Den Kennzeichenträger ([`radar_license_plate_bracket.stl`](../../hardware/cad/stl/02_pod_base/radar_license_plate_bracket.stl)) unter die unteren M6-Kennzeichenschrauben klemmen. Die Hirth-Zunge der Adapterplatte in die Gabelaufnahme einschieben, Nickwinkel waagerecht zur Fahrbahn justieren und mit einer DIN 912 M5 $\times$ 25 mm Klemmschraube in die versenkte M5-Mutter formschlüssig festziehen.
  * **Option B: Montage am Heckkotflügel (Bobber / Custom-Bike):** Den Stealth Center Under-Fender Mount ([`radar_center_underfender_mount.stl`](../../hardware/cad/stl/02_pod_base/radar_center_underfender_mount.stl)) mittig unter die Kotflügelkante kleben (3M VHB 5952) oder mit 2x M4/M5 Senkkopfschrauben verschrauben. Die Neigungswiege in die Clevis-Gabel einschieben und per M5-Schraube arretieren. Der integrierte $42\,\text{mm}$ Schmutzfänger-Spoiler hält Reifengischt zuverlässig vom Drehgelenk und der M8-Kabelverschraubung ab.
  * **Spritzwasser-Verkabelung (Abtropfbogen):** Das 2-adrige FLRY-B Kabel von Peitsche 3 im rückseitigen Kanal der Trägerwirbelsäule führen und in einer nach unten hängenden Abtropfschlaufe (Drip-Loop) von unten durch die M8 IP68-Kabelverschraubung führen. Der monolithische Roost-Deflector am Gehäuseboden schirmt die Verschraubung vollständig gegen aufgewirbelte Reifengischt ab.
* **Front-Knoten (Stealth-Montage unterm Fairing):** Direkt unter der Verkleidung (Sharknose FLTRX, Batwing FLHX oder CVO ST) an den runden Metallstangen des Verkleidungsgeweihs (Ø 16–19 mm Fairing Support Brackets) mit der 2-teiligen Verkleidungs-Rohrschelle ([`front_node_fairing_tube_clamp.stl`](../../hardware/cad/stl/04_front_node/front_node_fairing_tube_clamp.stl)) oder per EPDM-Kabelbinder-Kreuztunnel vibrationsentkoppelt verschrauben (0° oder 90° drehbar). Hält Lenker und Riser 100% frei; sitzt unmittelbar neben der Headunit, dem OEM-USB-Kabelbaum und dem Ottocast CarPlay/AA Dongle. 12V geschaltetes Zündungsplus von Standlicht/Zubehörstecker; CAN-Bus lokal an `J2` (oder drahtlos an Zentralbox).

### 5.2 Montage Adventure-Plattform (BMW GS / GSA Familie)
* **Zentralbox:** Im Rahmendreieck unter der Fahrersitzbank auf 4x M4 Silentblöcken montieren.
* **Cockpit & Front-Knoten:** An der Ø 12 mm GPS-Querstrebe über dem TFT befestigt; 12V über originalen BMW Cartool-Stecker.
* **Pod 1 & Pod 2 (Strikt fahrzeugfest montiert - KEINE Pods im Alukoffer!):**
  * *Option A (Vario-Koffer / GS Standard):* Transition-Docks ([`adventure_transition_dock_base.stl`](../../hardware/cad/stl/02_pod_base/adventure_transition_dock_base.stl)) in der Sitzbank-Bügelfalte (Ø 28 mm Rahmenrohr) verbunden mit der Sattelbrücke ([`adventure_underseat_cross_rail.stl`](../../hardware/cad/stl/02_pod_base/adventure_underseat_cross_rail.stl)).
  * *Option B (Edelstahl-Rohrkofferträger / GSA):* Heavy-Duty GSA Cage Docks ([`adventure_gsa_cage_dock_body.stl`](../../hardware/cad/stl/02_pod_base/adventure_gsa_cage_dock_body.stl)) im 45 mm Totraum des Trägers zwischen Trägerrohr und Radkasten.
  * *Wichtiger Hinweis zu Aluminium-Koffern:* Pods dürfen **unter keinen Umständen im Inneren von Aluminium-Koffern** montiert werden (Faradayscher Käfig schirmt 2.4 GHz und 6.5 GHz UWB vollständig ab!). Die Pods verbleiben bei Kofferabnahme sicher am Motorrad. Eine 2-Pin Magnetkupplung ist bei Reiseenduros nur dann relevant, wenn Kofferinnenräume optional mit 5V Ladespannung versorgt werden sollen.
* **Heck-Radar (Adventure Gepäckbrücke):**
  * **Rohrträger-Klemmschelle:** Untere Trägerbasis ([`adventure_rack_radar_mount.stl`](../../hardware/cad/stl/02_pod_base/adventure_rack_radar_mount.stl)) und obere Kappe ([`adventure_rack_radar_clamp_cap.stl`](../../hardware/cad/stl/02_pod_base/adventure_rack_radar_clamp_cap.stl)) um das hintere Ø 18 mm Querrohr der Gepäckbrücke legen.
  * 2x DIN 934 M5 Muttern in die Taschen der oberen Kappe einlegen. Zwei DIN 912 M5 $\times$ 25 mm Schrauben von unten einschrauben und handfest anziehen. (Durch den Schraubenzugang von unten bleibt der Halter auch bei montierter Alukoffer-Topcase-Trägerplatte voll justierbar!).
  * Das vormontierte Radar 2.0 Gehäuse mit `radar_swivel_tilt_cradle.stl` in die Clevis-Gabel einschieben, Neigungswinkel ausrichten und mit M5 $\times$ 25 mm Klemmschraube formschlüssig in die Hirth-Verzahnung spannen.
  * Der integrierte $45^\circ$-Abweiserkeil schützt das Gelenk und das M8-Kabel wirksam gegen Schotterschlag von grobstolligen Enduro-Hinterreifen.

### 5.3 Begleitfahrzeug- & Autokolonnen-Installation (Support-Car / Van)
* **Pod 1 & Pod 2:** Werden mit je einem Schnellwechsel-Clip ([`car_sun_visor_pod_clip.stl`](../../hardware/cad/stl/05_accessories/car_sun_visor_pod_clip.stl)) an Fahrer- und Beifahrer-Sonnenblende geklemmt.
  * Modus A (Begleitfahrzeug für Bike-Gruppe): Pod 1 = Sena SPIDER X Slim, Pod 2 = Cardo Packtalk Edge.
  * 2-poliges 5V DC-Stromkabel verdeckt in der Dachhimmel- und A-Säulen-Gummidichtung zur Mittelkonsole verlegen.
* **Zentralbox & Front-Knoten (Doppelgehäuse / Stack-Dock):**
  * Für den sauberen Einsatz im Pkw/Van werden Front-Knoten (unten) und Zentralbox (oben) in einem formschlüssigen **Doppelgehäuse (`car_dashboard_wedge_dock.scad`)** gestackt auf der Mittelkonsole oder dem Armaturenbrett platziert.
  * **Energie- & Stromversorgungskonzept (über das 12V Y-Adapterkabel, siehe Kap. 4.0):**
    * **Option A (Zigarettenanzünder / 12V Bordsteckdose):** 12V Speisung über das vorkonfektionierte 12V-Y-Adapterkabel ("Bench & Support-Car Harness"):
      * **Abzweig A (JST-JWPF 2-Pin):** Speist Port `J1` des Front-Knotens. Dessen interne Buck-Wandler versorgen die Sonnenblenden-Pods mit 5V VBUS sowie Smartphones via Dual 20W USB-PD / Qi.
      * **Abzweig B (Deutsch DTM-12):** Speist Port `J1` der Zentralbox (Pins 1+2 KL30/KL15, Pin 3 GND). Der interne LM5164-Q1 versorgt Zentralbox und USV mit vollem Ladestrom.
    * **Option B (Fahrerfußraum Zündungsplus):** Feste 2-Draht-Verkabelung an Klemme 15 (KL15 Zündungsplus + Karosserie-GND) im Sicherungskasten/Fußraum auf den Eingang des Y-Adapterkabels (strikt kein Dauerplus KL30 ohne Ruhestrom-Abschaltung).
* **SAM-M10Q GNSS:** Auf dem Armaturenbrett hinter der Windschutzscheibe (über Qwiic-Kabel an Front-Node Port `J12`).
* **Audio- & Infotainment-Integration:** Direkte USB-C Datenverbindung von der Zentralbox zur USB-Media-Buchse des Fahrzeugs. Startet kabelgebundenes Apple CarPlay / Android Auto, spiegelt die PWA-Navigation auf das Fahrzeug-Display und gibt Funkdurchsagen über das Pkw-Soundsystem aus.
* **Telemetrie:** Drahtloser BLE-OBD2 Dongle im Fahrerfußraum (oder direkter 16-Pin OBD-Port).

---

## 6. Endabnahme, Probefahrt & Sign-Off Checkliste

1. **Zündungs-Check (KL15):**
   * Zündung EIN: Zentralbox und Front-Node erwachen synchron in $< 800\,\text{ms}$.
   * UWB-Backbone etabliert sich sofort (grüne Sync-LED).
   * Spiegel-LEDs (`J9`) quittieren für 1,0 s (Amber).
2. **Kassetten-Check:**
   * Tasten an Lenkerarmatur / Front-Node betätigen: Aktuatoren schalten zuverlässig durch.
3. **Totwinkel-Radar Test:**
   * Bei Annäherung eines Fahrzeugs von hinten leuchten Spiegel-LEDs bernsteinfarben; bei Spurwechsel mit Blinker blitzen sie mit 8 Hz Rot/Amber.
4. **Probefahrt & Dynamik:**
   * Fahrtwind-Mikrofon regelt Intercom-Lautstärke stufenlos und knackfrei nach.
   * Raised-Cosine Ducking senkt Musik bei Funksprüchen weich um $-18\,\text{dB}$ ab.
5. **Zündung AUS:**
   * Automatischer Action-Cam Stop via Bluetooth LE.
   * USV schaltet Zentralbox sauber ab; Diebstahl-Sentry auf LoRa 868 MHz bleibt 24/7 aktiv.

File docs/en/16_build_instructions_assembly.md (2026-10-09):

# 16 - Build Instructions, Wiring & Vehicle Installation

This document is the complete, hands-on step-by-step assembly manual for building and installing a complete **OpenMotorBridge (v8.0 Clean Architecture)** system on any motorcycle or support vehicle.

---

## 1. System Kit Overview (What is being built?)

A complete OpenMotorBridge vehicle kit consists of the following core assemblies:

```text
                      +-----------------------------------------+
                      |    1x CENTRAL MAIN BOX (IP67)           |
                      |    (Under the seat / in tail section)   |
                      |    * Lower tub + mid tray + lid         |
                      |    * Host PCBA 01 (ESP32-S3 Dual-Core)  |
                      |    * Onboard SX1262 LoRa 868 MHz        |
                      |    * Qorvo DW3110 UWB Transceiver       |
                      |    * 2,200 mAh LiPo backup battery (UPS)|
                      +--------------------+--------------------+
                                           |
                         1x CENTRAL HARNESS (HD26 SEAL-D IP67)
                                           |
          +--------------------------------+--------------------------------+
          |                                |                                |
          v Whip 1                         v Whip 2                         v Whip 5
+------------------+             +------------------+             +------------------+
| 1x POD 1 (LEFT)  |             | 1x POD 2 (RIGHT) |             | 1x REAR RADAR    |
| (Frame / Pannier)|             | (Frame / Pannier)|             | (Optional)       |
| * Pod enclosure  |             | * Pod enclosure  |             | * Wheeltec MR20  |
| * Base PCBA 02   |             | * Base PCBA 02   |             |   or Garmin      |
| * CARTRIDGE 1    |             | * CARTRIDGE 2    |             |   Varia RTL515   |
|   (Sena SPIDER   |             |   (Cardo Edge    |             +------------------+
|    X Slim)       |             |    / Swap OMM)   |
+------------------+             +------------------+
                                           ^
                                           | Deterministic UWB Vehicle Backbone
                                           | (Qorvo DW3110 / 6.5 GHz Ch. 5, < 0.4 ms)
                                           v
                                 +----------------------------------+
                                 | 1x UNIVERSAL FRONT NODE (IP67)   |
                                 | (Cockpit & Sensor Hub, PCBA 05)  |
                                 | * u-blox SAM-M10Q Multi-GNSS     |
                                 | * TI TMP117 & OPT3001 Sensors    |
                                 | * Knowles MEMS Wind Noise Sensor |
                                 | * 4-Port USB Hub & Dual USB-PD   |
                                 | * Battery-Free Handlebar PTT     |
                                 +----------------------------------+
```

---

## 2. Pre-Assembly Checklist (Parts & Hardware Verification)

All discrete components, PCB ordering files, and COTS sourcing lists are documented in **[Chapter 15: Bill of Materials & Manufacturing](15_bom_manufacturing.md)**. Ensure the following items are ready before assembly begins:

* [ ] **3D Printed Parts (MJF PA12 Black or FDM ASA/PET-CF):**
  * 1x Main Box (lower tub with UWB bottom pocket $11 \times 11 \times 0.6\,\text{mm}$, mid tray with LiPo cradle, lid with LoRa FXP895 pocket $110 \times 20 \times 0.8\,\text{mm}$)
  * 2x Pod base enclosures (seamless 1-piece monocoques with integral monolithic bulkhead, Mill-Max contact sleeves & spring guide posts; 0 assembly screws, 0 loose parts)
  * 2x Cartridge base sleds (with UWB antenna floor pocket & DIN 934 M2 captive nut standoffs), inlays (Sena SPIDER X Slim, Cardo Packtalk Edge, Swap OMM, or blank cartridge) & 2x magnetic latches
  * 1x Front Node (lower tub with UWB bottom pocket and AMPS nut pockets, upper lid, TPU cable glands & USB-C cap)
  * 1x Vehicle-specific mounting kit (BMW GS clamps & `adventure_rack_radar_mount.stl` / Harley saddlebag docks & license plate bracket / Support-Car `car_sun_visor_pod_clip.stl`)
  * *(Optional for helmet operation / OMM):* 1-2x OMM UCS upper shells ([`omm_ucs_top_shell.stl`](../../hardware/cad/stl/03_pod_cartridges/omm_ucs_top_shell.stl)), lower shells ([`omm_ucs_bottom_shell.stl`](../../hardware/cad/stl/03_pod_cartridges/omm_ucs_bottom_shell.stl)) & silicone keypads ([`omm_ucs_silicone_keypad.stl`](../../hardware/cad/stl/03_pod_cartridges/omm_ucs_silicone_keypad.stl))
* [ ] **Fully Populated PCBAs (from JLCPCB / Eurocircuits - up to 8 PCBAs):**
  * 1x PCBA 01 (Central Box with onboard LoRa SX1262 and DW3110 UWB)
  * 2x PCBA 03 (Universal Smart Cartridge Rev 3.0 All-UWB with DW3110 UWB, ES8388 / MCU and 4x AO3400 N-MOSFETs, 2-sided SMT)
  * 1x PCBA 05 (Front Node with DW3110 UWB)
  * *(Optional: 1x PCBA 08 Radar 2.0 Sub-MCU, PCBA 06 MagSafe Dock, PCBA 07 Smart-Keyfob)*
  * *(Optional for Helmet / OpenMotorMesh):* 1x **PCBA 09 (OMM 2.4 GHz HD-Mesh)** and/or 1x **PCBA 10 (OMM 446 PMR/DMR Radio)**
  * *(Note: PCBA 02 and PCBA 04 are completely eliminated).*
* [ ] **A4 / 316 Stainless Fasteners & Springs (IKEA Principle - 100% Solder-Free):**
  * 8x DIN 934 / DIN 985 M3 stainless nuts (for captive enclosure nut pockets)
  * 6x DIN 934 M4 nuts (4x AMPS nut pockets in Front Node tub, 2x Radar 2.0 rear housing)
  * 4x M3 x 40 mm socket head screws (Central Box), 4x M3 x 20 mm screws (Front Node)
  * 8x M2.5 x 6 mm board screws (Central Box & Front Node), 8x M2 x 6 mm board screws (Cartridge PCBA 03; bulkhead screws completely eliminated)
  * 4-8x DIN 934 M2 nuts & 4-8x DIN 912 M2 x 8 mm socket head screws (for OMM UCS enclosure fastening)
  * 2x DIN 7 M2 x 8 mm dowel pins (latch pivots), 2x DIN 6325 Ø 6 x 8 mm hardened steel keeper pins
  * 2x Latch return springs, 4x auto-eject compression springs, 1x N52 neodymium release key
  * 4x Gold-plated Mill-Max heavy-duty spring contact sleeves for Pod 1 & 2 power feed
* [ ] **Gaskets, Battery & Antennas:**
  * Silicone O-ring cord Ø 1.5 mm Shore 40A ($40\,\text{cm}$ Main Box, $30\,\text{cm}$ Front Node)
  * Silicone O-ring cord Ø 0.8 mm Shore 40A ($25\,\text{cm}$ per OMM UCS module)
  * 2x Molded silicone face gaskets for Pod 1 & 2 mouths, Gore ePTFE vent stickers
  * **1x 1S LiPo Flat Pack 2,200 mAh** ($68 \times 39 \times 5.0\,\text{mm}$) with Molex Micro-Fit 3.0 connector (Central Box UPS)
  * **1-2x 1S LiPo Pouch Battery 600 mAh** ($38 \times 24 \times 4.5\,\text{mm}$) with JST 2-Pin connector (OMM UCS modules)
  * **Taoglas FXUWB10 UWB Flex Antennas** with 20 mm U.FL leads (Central Box, Front Node, Cartridges)
  * **1x Taoglas FXP895 LoRa 868 MHz Flex Antenna** with 50 $\Omega$ U.FL lead
  * **1x u-blox SAM-M10Q Multi-GNSS Module** with integrated patch antenna (Qwiic I2C)
  * **1x TI TMP117 & 1x TI OPT3001 Sensors** (Qwiic I2C)
  * **1-2x RF Micro-Coaxial Pigtails U.FL to SMA-Bulkhead** (RG-178 / 1.13mm, 50 mm) with IP67 EPDM O-ring and M6 stainless nut
  * **1x OMM 2.4 GHz Stubby Antenna** (SMA-Male, 38 mm Rubber-Duck helix)
  * **1x OMM 446 MHz Stubby Antenna** (SMA-Male, 48 mm Helical stubby)
* [ ] **Pre-Assembled COTS Harnesses (Zero Crimping Required):**
  * 1x Deutsch DTM-12 IP67/IP69K central breakout harness (pure 2-wire DC whips for Pod 1, Pod 2, Radar and 12V battery & CAN)
  * 2-Pin JWPF / Superseal connectors for Pod and Radar power leads
  * JST-SH cartridge wiring harnesses (8-Pin `J_ACT` for solenoids)
  * 1-2x OMM Helmet Audio & PTT Harnesses (6-Pin JST-SH 1.0mm socket to 3.5mm jack + mic + PTT, AWG30/32 silicone, $12\dots 15\,\text{cm}$)
* [ ] **Tools:**
  * Hex key set (1.5 / 2.0 / 2.5 / 3.0 mm), Torx TX10 / PH1 driver, open-end wrenches 7 / 8 / 10 mm, utility knife, dielectric silicone grease

---

## 3. Step-by-Step Module Assembly

### Step 1: Central Box Assembly
1. **Insert Captive Nuts:** Press 4x DIN 934 / DIN 985 M3 stainless nuts into the captive hexagonal pockets from underneath the lower tub ([`main_box_lower_case.stl`](../../hardware/cad/stl/01_main_box/main_box_lower_case.stl)).
2. **Install Tub Floor UWB Antenna:**
   * Affix the flexible UWB antenna (Taoglas FXUWB10, $11 \times 11 \times 0.6\,\text{mm}$) into the bottom recess of the lower tub using its adhesive backing.
   * Route the short 20 mm U.FL micro-coax cable vertically upward.
3. **Mount Host PCB:**
   * Place fully assembled PCBA 01 onto the vibration-damping bosses.
   * Snap the U.FL connector onto receptacle `ANT2` located on the bottom copper layer (`B.Cu`).
   * Fasten the board with 4x M2.5 $\times 6\,\text{mm}$ screws finger-tight.
4. **Install Lid LoRa Antenna:**
   * Adhere the flexible LoRa antenna (Taoglas FXP895, $110 \times 20 \times 0.8\,\text{mm}$) into the lid pocket of [`main_box_lid.stl`](../../hardware/cad/stl/01_main_box/main_box_lid.stl).
   * Connect the U.FL lead to header `ANT1` on the top surface of PCBA 01.
5. **Mid Tray & 2,200 mAh LiPo Battery:** Seat the mid tray ([`main_box_mid_tray.stl`](../../hardware/cad/stl/01_main_box/main_box_mid_tray.stl)). Place the **2,200 mAh flat LiPo battery** into the tray, connect the Micro-Fit plug to `J_BAT`, and secure the cell with EPDM foam tape.
6. **Seal & Temporary Cover:** Lightly lubricate the silicone O-ring cord (Ø 1.5 mm, $40\,\text{cm}$) and seat it into the lid groove. Stick the Gore vent membrane onto the vent boss. Place the lid loosely on top.

---

### Step 2: Assemble Satellite Pods 1 & 2 (2x Identical 1-Piece Screwless Monocoques)
1. **Route 2-Wire DC Feed:** Feed the 2-wire DC harness (+12V/5V and GND) through the rear cable gland or M8 port of the monolithic pod base housing ([`pod_base_housing.stl`](../../hardware/cad/stl/02_pod_base/pod_base_housing.stl)).
2. **Install Mill-Max Spring Contacts:** Press the two gold-plated Mill-Max heavy-duty spring contact sleeves from behind into the two guide bores of the integral monolithic bulkhead wall and connect/crimp with the supply wires.
3. **Mount Auto-Eject Springs:** From the front opening, slide the two stainless compression springs ($\varnothing 4.5 \times 15\,\text{mm}$) directly onto the two integrated guide posts of the monolithic bulkhead partition.
4. **Screwless Completion:** Because the transverse bulkhead is 100% integrally molded into the 1-piece monocoque, all assembly and countersunk screws are eliminated (0 screws). The two gold-plated spring pins extend with spring compliance into the cartridge bay. Repeat for Pod 2.

---

### Step 3: Multi-Protocol Gateway Cartridges 1 & 2 Assembly
1. **Mount UWB Antenna & PCB in Sled:**
   * Place the flexible UWB antenna (Taoglas FXUWB10, $12 \times 12 \times 0.8\,\text{mm}$) into the bottom pocket of the cartridge sled ([`cartridge_base_sled.stl`](../../hardware/cad/stl/03_pod_cartridges/cartridge_base_sled.stl)) and route the U.FL micro-coax cable in the recess channel.
   * Place PCBA 03 Rev 3.0 onto the four M2 standoffs, snap the U.FL connector onto `ANT_UWB` (`B.Cu`), and secure the board finger-tight with 4x M2 $\times 6\,\text{mm}$ screws. Gold contact pads `PAD1` (+12V/5V) and `PAD2` (GND) on the bottom copper face remain directly accessible through the rear floor cutout for mating with the pod Mill-Max pins.
2. **Install Gateway Inlay & Solenoids:**
   * **Slot 1 (Sena SPIDER X Slim Inlay):**
     * Insert 4x miniature solenoids ($\varnothing 6.5 \times 12\,\text{mm}$) with TPU tips into the actuator bridge of [`cartridge_insert_sena.stl`](../../hardware/cad/stl/03_pod_cartridges/cartridge_insert_sena.stl).
     * Fasten retainer plate with 4x M2 $\times 6\,\text{mm}$ countersunk screws.
     * Connect pre-crimped 8-pin harness `J_ACT` to header `J_ACT` on PCBA 03.
     * Seat Sena SPIDER X Slim; connect direct micro-cable whip to `J_AUDIO_PWR` on PCBA 03 (zero pogo pins!).
   * **Alternative Option: Universal OEM Upcycling Cartridge (Schuberth SC2, Shoei SRL Series, HJC Smart 50B - €0 Budget Option):**
     * *Preparation (Battery Eliminator):* Open the retired OEM intercom shell (SC2, Shoei SRL, or Smart HJC), desolder the LiPo pouch cell. Configure a miniature buck converter (e.g. MP2315) from `VCC` (5V from `J_AUDIO_PWR` Pin 2) to $3.75\dots 3.85\,\text{V}$ and solder to `BAT+` / `BAT-`. Solder a $10\,\text{k}\Omega$ resistor between NTC pad and `GND` (simulating 22°C cell temperature against boot error). Pot and strain-relieve wires with silicone or B-7000.
     * *Audio & Antenna Adaptation:* Connect 8-pin JST-SH harness to OEM speaker and microphone wires (keeping `AGND` grounds isolated!). Adapt internal U.FL/micro-coax leads via short RG-178 pigtail to the front SMA bulkhead port of the cartridge.
     * *Mounting in Base Sled:* Place main electronics module ($75 \times 40 \times 12\,\text{mm}$ or flat neck module) and step-down converter inside the base sled. Control wirelessly via BLE handlebar remote (SC2 Remote or Sena RC4) or mechatronic bridge. Fasten solid blind cover (`03_insert_blindkassette.scad`) with 4x M2 screws for a weatherproof seal.
   * **Slot 2 (Cardo Packtalk Edge Inlay / Swap OMM):**
     * Mount 4x solenoids into [`cartridge_insert_cardo.stl`](../../hardware/cad/stl/03_pod_cartridges/cartridge_insert_cardo.stl) and connect to `J_ACT`.
     * Lock Cardo Packtalk Edge into Air-Mount cradle and attach micro-cable whip to `J_AUDIO_PWR`.
3. **Mouth Gasket:** Slide molded silicone gasket over the cartridge collar and lightly apply silicone grease.

---

### Step 3.1: Assemble Magnetic Anti-Theft Latch (Lever Mechanism)
1. **Press Steel Pin:** Press the hardened steel keeper pin ($\varnothing 6 \times 8\,\text{mm}$, DIN 6325) into the transverse hole of the latch lever ([`cartridge_magnetic_lock_latch.stl`](../../hardware/cad/stl/03_pod_cartridges/cartridge_magnetic_lock_latch.stl)).
2. **Insert Spring:** Place the small $\varnothing 3.5 \times 10\,\text{mm}$ compression spring into the inward pocket.
3. **Pivot Mounting:** Slide the assembled latch into the left cheek of the cartridge sled and drive the $\varnothing 2.0 \times 8\,\text{mm}$ stainless dowel pin (DIN 7) through the pivot hole.
4. **Functional Test:** Latch tooth extends $2.5\,\text{mm}$ outward; holding the N52 neodymium block magnet outside the housing retracts the tooth flush into the sled.

---

### Step 3.2: Assemble OMM UCS Intercom Modules (PCBA 09 & PCBA 10) & Prepare for Helmet Installation

Both standalone modules (**PCBA 09: OMM 2.4 GHz HD-Mesh** and **PCBA 10: OMM 446 PMR/DMR**) share an identical ECE 22.06 UCS enclosure ($68 \times 36 \times 9.5\,\text{mm}$) and assemble as follows:

1. **Insert Captive Nuts & Keypad Gasket:**
   * Press 4x DIN 934 M2 stainless nuts from inside into the captive nut pockets of the upper shell ([`omm_ucs_top_shell.stl`](../../hardware/cad/stl/03_pod_cartridges/omm_ucs_top_shell.stl)).
   * Seat the Shore 50A silicone keypad ([`omm_ucs_silicone_keypad.stl`](../../hardware/cad/stl/03_pod_cartridges/omm_ucs_silicone_keypad.stl)) into the upper shell recess (key plungers protrude through the 4 aperture holes, diffuse LED dome aligns with `D1`).
   * Lightly lubricate silicone O-ring cord ($\varnothing 0.8\,\text{mm}$, approx. $22\,\text{cm}$) with silicone grease and press it into the perimeter sealing channel of the upper shell.
2. **Install RF Coax Pigtail & Watertight SMA Bulkhead:**
   * Connect the 50 mm low-loss micro-coax pigtail (U.FL to SMA bulkhead) to the board:
     * On `PCBA 09`: Snap U.FL connector vertically onto the integrated U.FL receptacle on the `ESP32-C6-MINI-1U` (`U1`).
     * On `PCBA 10`: Snap U.FL connector onto receptacle `J_RF` on the bottom copper side (`B.Cu`).
   * Slide the EPDM/Silicone O-ring ($\varnothing 6.0 \times 1.0\,\text{mm}$) over the SMA bulkhead threads.
   * Seat the SMA jack with its D-cut anti-twist flat into the $5.0 \times 4.0\,\text{mm}$ slot on the $+X$ flank of the lower shell ([`omm_ucs_bottom_shell.stl`](../../hardware/cad/stl/03_pod_cartridges/omm_ucs_bottom_shell.stl)) and tighten the A4 stainless hex nut and star lockwasher from the outside to achieve an IP67 seal.
3. **Install Battery & PCB:**
   * Place the 600 mAh LiPo pouch battery into the central battery cradle ($X = 14\dots 54\,\text{mm}$) of the lower shell.
   * Plug the 2-pin JST lead into `BAT1`.
   * Seat the PCB component-side up into the guide bosses, ensuring the USB-C port `J1` seats cleanly into its frontal gasket flange.
4. **Connect Helmet Audio & PTT Harness (`J_HELMET`):**
   * Plug the 6-pin JST-SH connector of the helmet audio harness into header `J_HELMET` on `B.Cu` ($X=126.5, Y=99.75\,\text{mm}$ in KiCad, $X_{\text{mod}} = 60.5\,\text{mm}$, receptacle socket facing inward).
   * Route the flexible AWG30/32 silicone lead in a gentle bend downward through the rear bottom slot ($9.0 \times 9.0\,\text{mm}$ at $X = 55\dots 64\,\text{mm}$) of the lower shell.
5. **Fasten Enclosure (100% Soldering-Iron Free):**
   * Seat the upper shell, verifying seamless perimeter gasket alignment.
   * Fasten 4x DIN 912 M2 $\times 8\,\text{mm}$ stainless socket head screws from underneath through the countersunk holes into the captive DIN 934 M2 nuts in a crosswise pattern.
6. **Thread On Stubby Antenna:**
   * For OMM 2.4 GHz (`PCBA 09`): Screw on the compact 38 mm 2.4 GHz Rubber-Duck stubby antenna onto the SMA jack.
   * For OMM 446 (`PCBA 10`): Screw on the compact 48 mm 446 MHz helical stubby antenna onto the SMA jack.
7. **Helmet Installation (ECE 22.06 UCS Slot):**
   * Slide the assembled module into the helmet manufacturer's UCS recess (e.g., HJC, Shoei, Schuberth) until it locks in place.
   * Route the audio harness exiting from the underside directly into cheek pad cutouts:
     - Connect 3.5 mm stereo jack to helmet speakers.
     - Connect 2-pin micro jack to boom or adhesive microphone.
     - Route PTT line to chin bar or finger button.
   * The frontal USB-C port remains fully accessible on the outside of the helmet for powerbank charging on the go or WebUSB DFU updates.

---

### Step 4: Universal Front Node (PCBA 05) Assembly
1. **Insert Captive Nuts (100% Soldering-Iron Free & Infinite Service Life):**
   * Press **4x M3 stainless steel nuts (DIN 934 / DIN 985)** from below into the form-fit hex pockets at the 4 corners of the lower tub ([`front_node_lower_tub.stl`](../../hardware/cad/stl/04_front_node/front_node_lower_tub.stl)) (fully analogous to the Central Box).
   * Press **4x M4 stainless steel nuts (DIN 934)** into the form-fit hex pockets of the AMPS pattern on the tub underside.
   * *Benefit:* Pure steel-in-steel clamping. The enclosure can be opened and retorqued indefinitely for wiring maintenance without degrading plastic threads.
2. **Install Tub Floor UWB Antenna:**
   * Adhere Taoglas FXUWB10 flex antenna into the lower tub floor recess.
   * Route U.FL lead upward.
3. **Mount Host PCB:**
   * Place PCBA 05 onto damping bosses.
   * Snap UWB coax lead onto U.FL receptacle on `B.Cu`.
   * Secure board with 4x M2.5 screws.
4. **Connect Cockpit Sensors (J12 Qwiic):**
   * Connect u-blox SAM-M10Q Multi-GNSS module (with integrated $15 \times 15\,\text{mm}$ patch antenna) via Qwiic cable to `J12`.
   * Daisy-chain TI TMP117 temperature sensor and TI OPT3001 light sensor along the Qwiic bus inside the cool ram-air intake zone.
5. **Acoustic Membrane:** Stick hydrophobic Gore ePTFE membrane over the acoustic port of the digital MEMS microphone (`MIC1`).
6. **Connect Wiring & Enclosure Closure:**
   * Plug 12V KL15 & GND to `J1`, CAN-bus to `J2`, handlebar PTT to `J3`, CP2AA dongle to `J6`, fast-charging to `J5`.
   * Insert TPU sealing combs, place silicone cord in lid groove, and seat lid loosely.

---

## 4. Benchtop Dry-Run & Testing BEFORE Bike Installation

The entire system can be fully powered, flashed, and tested on a workbench using standard USB-C cables and a multi-port 5V USB charger:

```text
+-----------------------------------------------------------------------------+
|       OPENMOTORBRIDGE BENCHTOP DRY-RUN (LABORATORY WORKBENCH SETUP)         |
+-----------------------------------------------------------------------------+
|                                                                             |
|   [ 230V USB Charger / Power Bank / Laptop (5V / ≥ 2.4A) ]                  |
|       |                      |                      |                       |
|  USB-C|Cable 1          USB-C|Cable 2          USB-C|Cable 3                |
|       v                      v                      v                       |
|  +---------------+     +---------------+      +---------------+             |
|  |  CENTRAL BOX  |     |  FRONT NODE   |      | SATELLITE POD |             |
|  |   (PCBA 01)   |     |   (PCBA 05)   |      | (Pod 1 / 2)   |             |
|  |  Port J7 USB-C|     |  Port J5 USB-C|      | M8 Adapter    |             |
|  +-------+-------+     +-------+-------+      +-------+-------+             |
|          |                     |                      |                     |
|          |   UWB Wireless Link |                      | 1-Wire & Direct-DC  |
|          |<------------------->|                      v                     |
|          |  (6.5 GHz, <0.4 ms) |             +-------------------+          |
|          |                     |             | SMART CARTRIDGE   |          |
|          |                     |             | (Sena / Cardo)    |          |
|          |                     |             +--------+----------+          |
|          | WebBLE / WebSerial  |                      |                     |
|          v                     v                      v                     |
|    [ SMARTPHONE / LAPTOP WITH PWA ]            [ RIDER HELMET ]             |
|    (Chrome / Edge: Flasher & Dashboard)        (Bluetooth Paired)           |
|                                                                             |
+-----------------------------------------------------------------------------+
```

### 4.1 Guided 4-Point IKEA Smoke Test
In the PWA (via WebSerial or WebBLE), verify diagnostics:
1. [x] **Power & UPS (Check 1):** LM5164 buck active (5.04 V), UPS LiPo (2,200 mAh) charging to 4.18 V.
2. [x] **Cartridges & Solenoids (Check 2):** 1-Wire detection of Slot 1 (Sena) and Slot 2 (Cardo), automated 4-solenoid click test ("Click-Click-Click-Click").
3. [x] **Front Node & UWB Backbone (Check 3):** UWB link active ($< 0.4\,\text{ms}$ latency), SAM-M10Q 3D fix, TMP117 temperature, Knowles MEMS level & handlebar PTT keying.
4. [x] **LoRa 868 MHz & Radar (Check 4):** SX1262 LoRa ping-echo and UART telemetry to rear radar on Whip 5.

Once all 4 checks indicate green, tighten enclosure lids with M3 screws diagonally.

---

## 5. Vehicle-Specific Mounting & Wiring on Motorcycle

### 5.1 Harley-Davidson Platform (Touring, CVO ST, Road King)
* **Central Box:** Fasten under rider seat on frame crossmember forward of battery using 4x M4 vibration isolators.
* **Pod 1 & Pod 2:** Mount to hard saddlebag lids using [`saddlebag_lid_dock.stl`](../../hardware/cad/stl/02_pod_base/saddlebag_lid_dock.stl).
* **Saddlebag Quick-Breakaway Interface (2-Pin Magnetic Pogo "MagSafe Alternative"):**
  * **Frame-Side Dock:** Bolt the 3D-printed frame dock ([`009_magsafe_frame_dock.stl`](../../hardware/cad/stl/02_pod_base/parts/009_magsafe_frame_dock.stl)) with clamp collar ([`009_magsafe_frame_clamp.stl`](../../hardware/cad/stl/02_pod_base/parts/009_magsafe_frame_clamp.stl)) to the Ø 26 mm frame tube under the seat overhang with 4x M3 $\times 16\,\text{mm}$ screws (DIN 934 nut pockets). Seat the 2-pin magnetic pogo socket (HytePro M411) form-fittingly and connect to Whip 1 or 2 of the DTM-12 harness.
  * **Saddlebag Forward Wall & Split Grommet:** Drill a single $\varnothing 12\,\text{mm}$ hole on the inner forward wall of the saddlebag above the swingarm pivot (inside the wind and road spray shadow; the **saddlebag floor remains 100% hole-free and watertight**). Insert the split EPDM/TPU grommet ([`010_saddlebag_hole_grommet_split.stl`](../../hardware/cad/stl/02_pod_base/parts/010_saddlebag_hole_grommet_split.stl)), route the 2-wire ribbon cable through, and anchor it with a mini zip-tie on the integrated clamp tower. Inside the bag, guide the cable along the check strap without tension to the lid dock snout.
* **Rear Radar (Heavy-Duty Swivel Cradle & Spray Protection):**
  * **Bench Pre-Assembly (100% Soldering-Iron Free):** Bolt the sealed Radar 2.0 housing ([`radar_mr20_housing.stl`](../../hardware/cad/stl/05_accessories/radar_mr20_housing.stl)) with its internal DIN 934 M4 nuts to the adapter plate ([`radar_swivel_tilt_cradle.stl`](../../hardware/cad/stl/02_pod_base/radar_swivel_tilt_cradle.stl)) using two DIN 912 M4 $\times$ 12 mm steel bolts. Solid shear bosses absorb 100% of lateral shock loads.
  * **Option A: License Plate Bracket:** Clamp the license plate bracket ([`radar_license_plate_bracket.stl`](../../hardware/cad/stl/02_pod_base/radar_license_plate_bracket.stl)) under the lower M6 license plate screws. Slide the cradle Hirth tongue into the clevis fork, align the radar beam horizontally ($\pm 2^\circ$), and clamp securely with a DIN 912 M5 $\times$ 25 mm bolt and DIN 934 M5 nut.
  * **Option B: Under-Fender Mount (Bobbers / Custom Bikes):** Bond or bolt the Stealth Center Under-Fender Mount ([`radar_center_underfender_mount.stl`](../../hardware/cad/stl/02_pod_base/radar_center_underfender_mount.stl)) centrally under the rear fender trailing edge using 3M VHB 5952 tape or 2x M4/M5 countersunk screws. Slide the cradle into the clevis and lock with an M5 bolt. The integrated 42 mm roost deflector shield protects the joint and bottom M8 gland from rear tire spray.
  * **Water Spray Protection (Drip Loop):** Route the 2-wire FLRY-B cable from Whip 5 down the spine conduit and guide it in an upward drip loop through the bottom M8 IP68 cable gland. The monolithic roost deflector on the housing bottom protects the gland from rear tire road spray.
* **Front Node:** Secure inside fairing (Batwing / Sharknose) or nacelle; 12V from auxiliary plug; CAN connected locally at J2 (or under seat at Central Box).

### 5.2 Adventure Platform (BMW GS / GSA Family)
* **Central Box:** Mount inside frame triangle under rider seat on 4x M4 vibration isolators.
* **Cockpit & Front Node:** Mount to Ø 12 mm GPS bar above TFT display; 12V via factory BMW Cartool plug.
* **Pod 1 & Pod 2:**
  * *Option A (Vario Panniers / GS Standard):* Transition docks ([`adventure_transition_dock_base.stl`](../../hardware/cad/stl/02_pod_base/adventure_transition_dock_base.stl)) in seat frame crease (Ø 28 mm tube) with 4x strap hook clearance pockets, coupled with underseat cross-rail ([`adventure_underseat_cross_rail.stl`](../../hardware/cad/stl/02_pod_base/adventure_underseat_cross_rail.stl)) for concealed 2-wire DC harness routing.
  * *Option B (Stainless Pannier Racks / GSA):* Heavy-duty GSA cage docks ([`adventure_gsa_cage_dock_body.stl`](../../hardware/cad/stl/02_pod_base/adventure_gsa_cage_dock_body.stl)) in 45 mm frame dead space with 4x strap hook clearance pockets and zip-tie anchor bridge in tube clamp shadow for 2-wire DC cable.
* **Rear Radar (Adventure Luggage Rack Mount):**
  * **Tube Clamp Assembly:** Place the lower base mount ([`adventure_rack_radar_mount.stl`](../../hardware/cad/stl/02_pod_base/adventure_rack_radar_mount.stl)) and upper clamp cap ([`adventure_rack_radar_clamp_cap.stl`](../../hardware/cad/stl/02_pod_base/adventure_rack_radar_clamp_cap.stl)) around the rear Ø 18 mm luggage bridge cross-tube.
  * Insert 2x DIN 934 M5 nuts into the top cap pockets. Fasten with 2x DIN 912 M5 $\times$ 25 mm bolts from below (bottom screw access allows full adjustment without removing topcase baseplates).
  * Insert the pre-assembled Radar 2.0 housing with `radar_swivel_tilt_cradle.stl` into the clevis fork, level horizontally, and clamp firmly with a DIN 912 M5 $\times$ 25 mm bolt.
  * The monolithic $45^\circ$ forward deflector wedge shields the pivot joint and M8 wiring from stones thrown up by knobby offroad tires.

### 5.3 Support Car / Chase Van Installation (Car-Kit)
* **Pod 1 & Pod 2:** Attached to driver and passenger sun visors using quick-release clips ([`car_sun_visor_pod_clip.stl`](../../hardware/cad/stl/05_accessories/car_sun_visor_pod_clip.stl)).
  * Mode A (Chase vehicle for bike group): Pod 1 = Sena SPIDER X Slim, Pod 2 = Cardo Packtalk Edge.
  * Mode B (Pure car convoy): Pod 1 = OMM 2.4 GHz Swap Cartridge, Pod 2 = Midland PMR446 radio cartridge.
* **Central Box:** Sits in 15° dashboard wedge dock on center console.
* **SAM-M10Q GNSS:** Positioned on dashboard behind windshield.
* **Audio Integration:** USB-C audio link to vehicle headunit for group intercom through vehicle speakers.
* **Telemetry:** Wireless BLE OBD2 dongle plugged into driver footwell.

---

## 6. Final Sign-Off & Road Test Checklist

1. **Ignition ON (KL15):**
   * Central Box and Front Node wake synchronously in $< 800\,\text{ms}$.
   * UWB wireless backbone locks immediately (green sync LED).
   * Mirror blind-spot LEDs (`J9`) acknowledge with 1.0 s amber flash.
2. **Cartridge Keying:**
   * Press handlebar controls: Solenoids actuate headset buttons reliably.
3. **Blind-Spot Radar Test:**
   * Approaching vehicle from rear triggers amber mirror LEDs; signaling for lane change triggers 8 Hz red/amber hazard flash.
4. **Road Dynamics:**
   * Knowles MEMS wind sensor smoothly scales helmet volume.
   * Raised-Cosine Ducking attenuates music by $-18\,\text{dB}$ during incoming radio transmissions.
5. **Ignition OFF:**
   * Action cameras stop recording automatically via Bluetooth LE shutter.
   * Central Box executes graceful shutdown; LoRa 868 MHz theft sentry remains active 24/7 on UPS rail.

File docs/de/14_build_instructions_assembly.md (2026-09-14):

# 14 - Bauanleitung, Verkabelung & Fahrzeug-Installation

Dieses Dokument ist die vollständige, praxisorientierte Schritt-für-Schritt-Bauanleitung für den Eigenbau eines kompletten **OpenMotorBridge (v8.0)** Gesamtsystems. Es enthält eine exakte Bedarfsaufstellung aller 3D-Druckteile, bestückten Leiterplatten (PCBAs), mechanischen Normteile, Dichtungen, Kabelbaumkomponenten sowie das Inbetriebnahmeprotokoll.

---

## 1. Übersicht des Gesamtkits (Was wird gebaut?)

Ein vollständiges OpenMotorBridge-Fahrzeugkit besteht aus folgenden Baugruppen:

```
                      ┌─────────────────────────────────────────┐
                      │    1x ZENTRALE MAIN BOX (IP67)          │
                      │    (Unter der Sitzbank / im Heck)       │
                      │    • Unterwanne + Zwischenboden + Deckel│
                      │    • Hauptplatine (ESP32-S3, Codec, USV)│
                      │    • Integrierter Pufferakku (LiPo)     │
                      └────────────────────┬────────────────────┘
                                           │
                        1x ZENTRALER KABELBAUM (HD26 IP67)
                                           │
         ┌─────────────────────────────────┼─────────────────────────────────┐
         │                                 │                                 │
         ▼                                 ▼                                 ▼
┌──────────────────┐             ┌──────────────────┐              ┌──────────────────┐
│ 1x POD 1 (LINKS) │             │ 1x POD 2 (RECHTS)│              │ 1x POD 3 (HECK)  │
│ (Rahmen / Sturzb)│             │ (Rahmen / Sturzb)│              │ (Heckbürzel)     │
│ • Pod-Gehäuse    │             │ • Pod-Gehäuse    │              │ • Pod-Gehäuse    │
│ • Basisplatine   │             │ • Basisplatine   │              │ • Basisplatine   │
│ • KASSETTE 1     │             │ • KASSETTE 2     │              │ • KASSETTE 3     │
│   (z. B. Sena)   │             │   (z. B. Cardo)  │              │   (LoRa + GNSS)  │
└──────────────────┘             └──────────────────┘              └──────────────────┘
                                           │
                                           ▼ 2.4 GHz Funkbrücke (ESP-NOW < 1.8 ms)
                                 ┌──────────────────────────────────┐
                                 │ 1x UNIVERSAL FRONT-KNOTEN (IP67) │
                                 │ (Cockpit- & Sensor-Hub)          │
                                 │ • 4-in-1 Universal-Befestigung   │
                                 │ • Ottocast USB-A Port (CarPlay)  │
                                 │ • Handschuhfach USB-C Ladeport   │
                                 │ • Knowles MEMS Fahrtwind-Sensor  │
                                 │ • Batteriefreier Lenker-PTT      │
                                 └──────────────────────────────────┘
```

---

## 2. Das brauche ich für ein Komplettset (Bedarfsaufstellung für 1 Fahrzeug)

Um ein vollwertiges OpenMotorBridge (v8.0) Gesamtsystem für ein Motorrad aufzubauen, werden folgende Teile benötigt. Diese Aufstellung fasst alle Baugruppen (Zentralbox, 3 Satelliten-Pods, Kassetten, Front-Knoten, Kabelbaum und Normteile) strukturiert in 6 Kategorien zusammen:

### 2.1 Kategorie A: 3D-Druckteile (MJF PA12 schwarz oder FDM ASA/PETG)
*Empfohlenes Fertigungsverfahren: Multi Jet Fusion (MJF) oder SLS in PA12 (schwarz gefärbt, glasperlengestrahlt) oder FDM mit ASA/PET-CF. CAD-Dateien liegen in [`hardware/cad/stl/`](file:///Users/schmidtm/openMotorBridge/hardware/cad/stl/).*

| Baugruppe | STL-Dateiname | Stück | Funktion & Beschreibung |
| :--- | :--- | :---: | :--- |
| **Main Box Unterteil** | [`main_box_lower_case.stl`](file:///Users/schmidtm/openMotorBridge/hardware/cad/stl/01_main_box/main_box_lower_case.stl) | **1** | Monocoque-Unterwanne mit 4x M4 Silentblock-Ohren, 4x PCB-Domen und O-Ring-Nut |
| **Main Box Zwischenboden** | [`main_box_mid_tray.stl`](file:///Users/schmidtm/openMotorBridge/hardware/cad/stl/01_main_box/main_box_mid_tray.stl) | **1** | Akku-Wanne für 1000 mAh LiPo, 10x Konvektionsschlitze & Dichtfeder |
| **Main Box Deckel** | [`main_box_lid.stl`](file:///Users/schmidtm/openMotorBridge/hardware/cad/stl/01_main_box/main_box_lid.stl) | **1** | Abschlussdeckel mit Gore ePTFE-Ventildom & 4x M3 Schraubenlöchern |
| **Pod-Basisgehäuse** | [`pod_base_housing.stl`](file:///Users/schmidtm/openMotorBridge/hardware/cad/stl/02_pod_base/pod_base_housing.stl) | **3** | Schachtgehäuse für Pod 1 (Links), Pod 2 (Rechts) und Pod 3 (Heck) mit 120°-Rohrbett |
| **Pod-Schottwände** | [`03_pod_bulkhead_partition.stl`](file:///Users/schmidtm/openMotorBridge/hardware/cad/stl/02_pod_base/components/03_pod_bulkhead_partition.stl) | **3** | Schottwand mit Dichtkragen & Federaufnahmen (1x pro Pod) |
| **Kassette 1 (Fahrer)** | [`cartridge_sena_sled.stl`](file:///Users/schmidtm/openMotorBridge/hardware/cad/stl/03_pod_cartridges/cartridge_sena_sled.stl) *(oder Cardo)* | **1** | Kassetten-Schlitten für Fahrer-Headset (Sena 50S/60S oder Cardo Packtalk Edge) |
| **Kassette 2 (Sozius)** | [`cartridge_cardo_sled.stl`](file:///Users/schmidtm/openMotorBridge/hardware/cad/stl/03_pod_cartridges/cartridge_cardo_sled.stl) *(oder Blind)* | **1** | Kassetten-Schlitten für Zweit-Headset oder hermetische Blindkassette |
| **Kassette 3 (Heckbürzel)**| [`cartridge_omm_transceiver_sled.stl`](file:///Users/schmidtm/openMotorBridge/hardware/cad/stl/03_pod_cartridges/cartridge_omm_transceiver_sled.stl) | **1** | Heck-Kassette für RP2040 Coprozessor, GNSS-Patch und LoRa-Antenne |
| **Front-Knoten Unterwanne** | [`front_node_lower_tub.stl`](file:///Users/schmidtm/openMotorBridge/hardware/cad/stl/04_front_node/front_node_lower_tub.stl) | **1** | Cockpit-Gehäusewanne mit AMPS-Lochbild, EPDM-Dichtkämmen & V-Rohrbett (PA12 / ASA) |
| **Front-Knoten Deckel** | [`front_node_upper_lid.stl`](file:///Users/schmidtm/openMotorBridge/hardware/cad/stl/04_front_node/front_node_upper_lid.stl) | **1** | Gehäusedeckel mit Knowles MEMS Schalleintritt & O-Ring-Dichtnut (PA12 / ASA) |
| **Front-Knoten Dichtkämme** | [`front_node_cable_glands_tpu.stl`](file:///Users/schmidtm/openMotorBridge/hardware/cad/stl/04_front_node/front_node_cable_glands_tpu.stl) | **1 Paar** | Elastische Dichtkämme für Front (3x USB) & Flanke (3x Signale) (TPU 95A / 85A) |
| **Front-Knoten USB-C Kappe**| [`front_node_usbc_cap_tpu.stl`](file:///Users/schmidtm/openMotorBridge/hardware/cad/stl/04_front_node/front_node_usbc_cap_tpu.stl) | **1** | Elastische Staubschutzkappe mit Haltekollier für Service-Port (TPU 95A / 85A) |
| **Heck-Radar Kombihalter** | [`pod3_radar_bracket.stl`](file:///Users/schmidtm/openMotorBridge/hardware/cad/stl/02_pod_base/pod3_radar_bracket.stl) | **1** | M5 GoPro-Ausleger zur horizontalen Ausrichtung des Garmin Varia / mmWave Radars |
| **Summe 3D-Druckteile** | | **17** | **Vollständiger Teilesatz für 1 Gesamtsystem (15x PA12/ASA + 2x TPU)** |

---

### 2.2 Kategorie B: Bestückte Leiterplatten (5 PCBAs bei JLCPCB / Eurocircuits)
*Fertigungsdaten (Gerber ZIP, BOM CSV, CPL Pick & Place) liegen in [`hardware/production_packages/`](file:///Users/schmidtm/openMotorBridge/hardware/production_packages).*

| Leiterplatte | Bezeichnung / Projekt | Stück | Lagen & Spezifikation | Hauptfunktionen |
| :--- | :--- | :---: | :--- | :--- |
| **PCBA 01** | Zentralbox Hauptplatine (`kicad_main_box`) | **1** | 4-Layer FR4 TG150, ENIG Gold | ESP32-S3 Dual-Core, LM5164 DCDC, BQ24075 USV, ES8388 Codec, Bourns Audio-Übertrager, BMI270 IMU, MicroSD |
| **PCBA 02** | Pod-Basis Trägerplatine (`kicad_pod_base`) | **3** | 2-Layer FR4, ENIG Gold | M8 6-Pin IP67 Buchse, SP3012 ESD-Schutzarray, Harwin 6-Pin Präzisions-Stiftleiste |
| **PCBA 03** | Smart Modular Kassettenplatine Rev 2.0 (`kicad_cartridge`)| **2** | 2-Layer FR4, ENIG Gold | WCH CH32V003 RISC-V MCU (1-Wire Emulation & Opcode-Engine), 4x AO3400A N-MOSFETs, Harwin 6-Pin Buchse, J_ACT 8-Pin Mechatronik-Header, J2 6-Pin Audio/Power |
| **PCBA 04** | Heck-Pod 3 Transceiver (`kicad_rear_pod3`) | **1** | 4-Layer FR4 TG150, ENIG Gold | RP2040 Coprozessor, u-blox NEO-M9N / MAX-M10S GNSS, Semtech SX1262 LoRa, 3x Murata MM8030 HF-Umschalter |
| **PCBA 05** | Universal Front-Knoten (`kicad_front_node`) | **1** | 4-Layer FR4 TG150, ENIG Gold | ESP32-S3 Dual-Core Xtensa, USB2514B 4-Port Hub, SC8102 USB-PD 20W, TPS2051B, TCAN334G CAN-FD, Knowles I2S MEMS, PTT-Interface |

---

### 2.3 Kategorie C: Mechanische Normteile, Schrauben & Federn (V4A Edelstahl / Messing)

| Bauteil | Spezifikation / Norm | Stück | Montageort & Zweck |
| :--- | :--- | :---: | :--- |
| **M3 Gewindeeinsätze** | Ruthex Messing M3 $\times 5{,}7\,\text{mm}$ (RX-M3x5.7) | **8** | 4x Zentralbox-Unterwanne, 4x Front-Knoten Unterwanne (Lötkolben $220\,^\circ\text{C}$) |
| **M4 Gewindeeinsätze** | Ruthex Messing M4 $\times 8{,}1\,\text{mm}$ (RX-M4x8.1) | **4** | Front-Knoten AMPS-Bodenmontage ($30 \times 38\,\text{mm}$) |
| **Gehäuseschrauben Main** | Zylinderkopf DIN 912 V4A M3 $\times 40\,\text{mm}$ | **4** | Durchgehende 4-Eck-Verschraubung Zentralbox |
| **Gehäuseschrauben Front**| Zylinderkopf DIN 912 V4A M3 $\times 20\,\text{mm}$ | **4** | 4-Eck-Verschraubung Front-Knoten |
| **Platinenschrauben** | Zylinderkopf DIN 912 V4A M2.5 $\times 6\,\text{mm}$ | **8** | 4x Main Box PCBA, 4x Front-Node PCBA |
| **Schottwandschrauben Pod**| Senkkopf DIN 7991 V4A M2 $\times 8\,\text{mm}$ | **6** | Fixierung der 3 Pod-Schottwände (2x pro Pod) |
| **M5 Klemmschrauben Rohr** | Zylinderkopf DIN 912 V4A M5 $\times 30\,\text{mm}$ | **4** | Verschraubung der GSA Rohrträger-Klemmschellen (Ø 18 mm) |
| **M5 Stoppmuttern** | DIN 985 M5 Sicherungsmuttern V4A | **5** | 4x Rohrträger-Klemmschellen, 1x Hirth-GoPro-Gelenk |
| **M5 Klemmschraube & Stoppmutter**| DIN 912 V4A M5 $\times 25\,\text{mm}$ + DIN 985 M5 Mutter | **1** | Klemmung des GoPro-Radar-Schwenkarms mit Hirth-Formschluss |
| **M3 Torx-TR Madenschraube** | DIN 913 / 914 V4A M3 $\times 6\,\text{mm}$ | **1** | Verdeckte mechanische Rotationssperre im Varia-Dock |
| **M2 Schwenkachsen Wippe** | Zylinderstift Edelstahl DIN 7 M2 $\times 8\,\text{mm}$ | **2** | Drehachsen für magnetische Diebstahlschutz-Wippe (Pod 1 & 2) |
| **Ferromagnetische Stahlanker**| Zylinderstift Stahl gehärtet DIN 6325 $\varnothing 6 \times 8\,\text{mm}$| **2** | Magnetanker im hinteren Hebelarm der Kassettenwippe |
| **Wippen-Rückstellfedern** | Edelstahl V4A ($\varnothing 3{,}5\,\text{mm}, L_0=10\,\text{mm}, R=0{,}8\,\text{N/mm}$)| **2** | Rückstellung der Sägezahn-Rastkralle beim Kassetteneinschub |
| **N52 Entriegelungsschlüssel**| Neodym N52 Blockmagnet ($20 \times 10 \times 5\,\text{mm}$) | **1** | Berührungsloser Magnetschlüssel für Kassetten-Auswurf |
| **Auswerfer-Druckfedern** | Edelstahl V4A ($\varnothing 4{,}5\,\text{mm}, L_0=15\,\text{mm}, R=1{,}2\,\text{N/mm}$) | **6** | Auto-Eject Schnappmechanismus (2x pro Pod-Schottwand) |
| **Silentblöcke / Puffer** | Gummipuffer Typ A (M4 Außengewinde / M4 Innen, $\varnothing 15 \times 10\,\text{mm}$) | **4** | Schwingungsentkoppelte Rahmenmontage der Zentralbox |
| **Sicherungsmuttern M4 / Scheiben**| DIN 985 M4 Stoppmuttern + DIN 125 Unterlegscheiben V4A | **4** | Konterung der Silentblöcke am Motorradrahmen |

---

### 2.4 Kategorie D: Dichtungen, Druckausgleich & Lichtleiter (IP67)

| Bauteil | Spezifikation | Stück | Montageort & Funktion |
| :--- | :--- | :---: | :--- |
| **Silikon-Dichtschnur Main** | Silikon-Rundschnur $\varnothing 1{,}5\,\text{mm}$ Shore 40A/50A ($40\,\text{cm}$) | **1** | Umlaufende Nut-Feder-Abdichtung Zentralbox |
| **Silikon-Dichtschnur Front**| Silikon-Rundschnur $\varnothing 1{,}5\,\text{mm}$ Shore 40A/50A ($30\,\text{cm}$) | **1** | Umlaufende Deckel-Dichtung Front-Knoten |
| **Kassetten-Flanschdichtungen**| Silikon Formdichtung Shore 40A ($54 \times 18\,\text{mm}$, $1{,}5\,\text{mm}$) | **3** | Stirnseitige Mundloch-Abdichtung an Pod 1, 2 und 3 |
| **EPDM-Dichtkämme** | EPDM Zellkautschuk geschlitzt ($15 \times 8 \times 4\,\text{mm}$) | **2** | Wasserdichte Kabeleinführung der Flachkabel im Front-Knoten |
| **Druckausgleichsventil** | Gore Automotive AVS 41 (M8x1.25 Schraubventil) | **1** | Belüftung & Kondensatvermeidung im Main Box Deckel |
| **ePTFE-Klebemembranen** | Gore / Porex IP67 Membranpad $\varnothing 6{,}0 \dots 7{,}0\,\text{mm}$ (selbstklebend) | **5** | 3x Entlüftungsdome Pods, 1x Front-Node, 1x Knowles MEMS Akustik-Schallöffnung |
| **Lichtleiter (LED)** | Bivar PLPC3-3MM oder Mentor PMMA $\varnothing 3{,}0\,\text{mm}$ ($L=8\,\text{mm}$) | **1** | Wasserdichte Einkopplung der RGB Status-LED im Main Box Deckel |

---

### 2.5 Kategorie E: Kabelbaum, Steckverbinder, Pufferakku & HF-Pigtails

| Bauteil | Spezifikation / Typ | Stück | Zweck & Funktion |
| :--- | :--- | :---: | :--- |
| **HD26 Flanschbuchse IP67** | Amphenol LTW HD26 Buchse (Frontmontage mit Dichtung) | **1** | Gehäuseschnittstelle an der Zentralbox |
| **HD26 Kabelstecker IP67** | HD26 Stecker mit Rändelschrauben & Gummitülle | **1** | Hauptstecker am zentralen Kabelbaum |
| **M8 6-Pin Buchsenkabel** | M8 6-Pin A-kodiert IP67 Buchse (PUR geschirmt, 250 mm) | **3** | Peitschen 1, 2, 3 am Kabelbaum zu den Pods |
| **M8 4-Pin Buchsenkabel** | M8 4-Pin A-kodiert IP67 Buchse (PUR geschirmt, 250 mm) | **1** | Peitsche 5 am Kabelbaum für Heck-Radar (Garmin Varia / mmWave) |
| **AMP Superseal 1.5 Buchse**| TE Connectivity AMP Superseal 1.5 4-Pin Buchsengehäuse | **1** | Peitsche 4 am Kabelbaum für 12V Bordnetz (KL30, KL15, GND) |
| **M8 Verbindungskabel** | M8 6-Pin A-kodiert Stecker/Buchse (PUR, 1.0 m bzw. 1.5 m) | **3** | Zuleitungskabel vom Pigtail unter der Sitzbank zu den Pods |
| **Pufferakku (LiPo USV)** | 1S 3.7V LiPo 1000 mAh mit integriertem 10k NTC | **1** | USV-Notstrompuffer in der Zentralbox (Molex Micro-Fit 3.0) |
| **KFZ-Sicherungshalter** | Wasserdichter Mini-Flachsicherungshalter IP67 + **2A Sicherung**| **1** | Absicherung der 12V Dauerplus-Leitung (KL30) direkt am Batteriepol |
| **Automotive-Leitungen** | FLRY-B $0{,}5\,\text{mm}^2$ (Power/GND) und $0{,}35\,\text{mm}^2$ (Signale/Audio)| *nach Bedarf* | Fahrzeugkabelbaum nach [`central_breakout_harness_wirelist.csv`](file:///Users/schmidtm/openMotorBridge/hardware/production_packages/05_wiring_harness_spec/central_breakout_harness_wirelist.csv) |
| **EPDM-Spannbänder** | UV- und ozonbeständiges EPDM ($\varnothing 45 \dots 75\,\text{mm}$) | **6** | Werkzeuglose Schnellmontage der Pods an Rahmen- & Sturzbügeln |
| **Murata MM8030 Pigtails** | Murata MM126036 auf SMA-Bulkhead IP67 (150 mm, RG-178)| **3** | Koaxial-Bypass für Pod 3: J3 (2.4G), J4 (868M), J5 (GNSS) |
| **U.FL Koaxial-Pigtail** | IPEX MHF1 / U.FL auf RP-SMA Bulkhead IP67 (150 mm, RG-178)| **1** | Koaxial-Zuleitung für Front-Knoten ESP32-S3 externe Antenne |
| **SMA-Flansch-Doppelbuchse** | SMA-Buchse auf SMA-Buchse Bulkhead IP67 mit O-Ring & Mutter | **1** | Wasserdichte HF-Durchführung in Kassetten-Frontblende (Klasse A) |
| **Koax-Pigtail intern** | RG-178 Koaxialkabel ($6\dots 10\,\text{cm}$, SMA 90° auf SMA) | **1** | HF-Verbindung von Sena +Mesh / OEM-Adapter zur Frontblende |
| **SMA IP67 Schutzkappen** | Messing vernickelt mit Dichtungs-O-Ring (Rändelkappe) | **5** | Schutz ungenutzter SMA-Buchsen (3x Heck, 1x Front, 1x Pod) |
| **Externe Antennen (Opt.)** | 2.4G Collinear (+5 dBi), 868M LoRa (+3 dBi), aktive GNSS-Puck | *nach Wunsch*| High-Gain Antennen für maximale Reichweite und freie Himmelsicht |
| **USB-A Flachbandkabel (Front)**| USB-A Stecker/Kupplung kurz ($10\dots 15\,\text{cm}$, 90°-Winkel)| **1** | Ottocast-Anbindung an J1 durch vorderen Dichtkamm |
| **USB-C Ladekabel (Handschuhf.)**| USB-C Stecker/Stecker ($1{,}0\,\text{m}$, 90°-Winkel, PUR)| **1** | Smartphone-Ladekabel von J2 durch vorderen Dichtkamm |
| **JST-GH Crimpstecker-Set** | JST-GH 1.25mm 2-Pin Gehäuse + Crimpkontakte | **2 Sätze**| Vorkonfektionierte Litzen für J3 (PTT) & J7 (12V) durch linken Kamm |
| **90° USB Kassetten-Kabel** | Ultraflaches 90°-Winkelkabel Micro-USB/USB-C ($5\dots 8\,\text{cm}$) | **1** | 5V-Speisung für Sena +Mesh / MeshPort Adapter in Kassette |
| **EPDM Kassetten-Spannband** | Elastisches EPDM-Gummiband ($\approx 35 \times 10\,\text{mm}$) | **1** | Vibrationssichere Arretierung des OEM-Adapters über Kassettennasen |

---

### 2.6 Kategorie F: Benötigte Werkzeuge, Messmittel & Montagechemie

Für den sauberen, vibrationsfesten und IP67-dichten Zusammenbau aller Baugruppen wird folgendes Werkzeug- und Hilfsmittel-Set empfohlen:

| Werkzeug / Hilfsmittel | Empfohlenes Modell / Spezifikation | Einsatzzweck im Projekt | Unverzichtbar? |
| :--- | :--- | :--- | :---: |
| **Inbusschlüssel-Satz (Kugelkopf)** | Größen 1,5 mm / 2,0 mm / 2,5 mm / 3,0 mm | M2 Schottwände, M2.5 PCBAs, M3 Gehäuse, M5 Radar | **Ja** |
| **Gabelschlüssel / Nüsse** | SW 7 (M4 Muttern), SW 8 (SMA-Bulkheads), SW 10 (Batteriepol) | Konterung der Silentblöcke & SMA-HF-Buchsen | **Ja** |
| **Feinmechanik-Drehmomentschlüssel**| $0{,}2 \dots 1{,}5\,\text{Nm}$ (z. B. Wera 7440) | Verzugsfreies Anziehen der M3 Deckel ($0{,}8\,\text{Nm}$) & PCBAs ($0{,}4\,\text{Nm}$) | *Empfohlen* |
| **Regelbare Lötstation** | $200 \dots 450\,^\circ\text{C}$ (z. B. TS101, Pinecil, Weller) | Einschmelzen der Ruthex-Einsätze & Kabelbaum-Löten | **Ja** |
| **Ruthex Einschmelzspitzen** | Adapter-Lötspitzen für M3 & M4 (Ruthex / CNC Kitchen) | Lotrechtes, wulstfreies Einsetzen der Messinggewinde ($220 \dots 240\,^\circ\text{C}$) | *Empfohlen* |
| **Fein-Crimpzange (Miniatur)**| Engineer PA-09 oder IWISS IWS-2820M ($1{,}0 \dots 1{,}6\,\text{mm}$ Raster) | Crimpen von JST-SH (1.0 mm Kassetten) & JST-GH (1.25 mm Front-Knoten) | **Ja** |
| **Automotive-Crimpzange** | Für unisolierte Kfz-Kabelschuhe ($0{,}5 \dots 1{,}5\,\text{mm}^2$) | Crimpen der 12V Flachstecker & M6 Ringösen an Batteriepolen | **Ja** |
| **Präzisions-Abisolierzange** | $0{,}08 \dots 1{,}0\,\text{mm}^2$ (AWG 28–18, z. B. Knipex 12 62 180) | Sauberes Abisolieren der FLRY-B Leitungen ohne Aderkerbung | **Ja** |
| **Elektronik-Seitenschneider** | Watenfrei (z. B. Knipex Super Knips 78 03 125) | Bündiges Kürzen von Drähten, Pins und Kabelbindern ohne scharfe Grate | **Ja** |
| **Heißluftgebläse / Heißluftföhn** | Mit Reduzierdüse ($150 \dots 300\,^\circ\text{C}$) | Schrumpfen von Schmelzkleber-Schrumpfschläuchen am Kabelbaum | **Ja** |
| **ESD-Präzisionspinzette** | Fein, abgewinkelt, kunststoffbeschichtet | Zerstörungsfreies, senkrechtes Aufdrücken von Murata MM8030 & U.FL Steckern | **Ja** |
| **Digitalmultimeter (DMM)** | Mit Durchgangsprüfer (Piepser) & mV/mA-Messung | Durchgangsprüfung Kabelbaum, Prüfung Ruhestrom & 5V/3.3V Schienen | **Ja** |
| **Labornetzteil mit Strombegrenzung** | $0 \dots 30\,\text{V DC}, 0 \dots 3\,\text{A}$ (einstellbare Strombegrenzung) | Erstinbetriebnahme bei 12.0V / 150mA zur sicheren Kurzschluss-Vermeidung | **Ja** |
| **Silikon-Dichtungsfett** | OKS 1110 oder Liqui Moly Silikonfett (transparent, dielektrisch) | Schmierung der Silikonschnüre, EPDM-Kämme & Kassettenlippen | **Ja** |
| **Schraubensicherung (Loctite 243)**| Mittelfest (blau) | Schwingungsschutz aller Schrauben gegen Motorrad-Vibrationen | **Ja** |
| **Elektronik-Schutzlack (Conformal)** | Peters Elpeguard SL 1307 oder Electrolube UR5041 (IPC-CC-830B) | Vollflächige Feuchte- & Salzsprühnebel-Versiegelung aller PCBAs | *Empfohlen* |
| **Skalpell / Cuttermesser** | Mit frischer Klinge | Gratfreies Ablängen der Silikon-Dichtschnur & EPDM-Zuschnitte | **Ja** |
| **USB-C Datenkabel** | Hochwertiges USB 2.0/3.0 Datenkabel (kein reines Ladekabel!) | Flashen von ESP32-S3 (Main & Front) und RP2040 (Rear) via PlatformIO | **Ja** |

---

## 3. 3D-Druck-Leitfaden & Materialauswahl (FDM vs. MJF)

### Empfohlene Filamente für Outdoor & Motorrad (FDM):
* **PETG:** *Ideal für alle Drucker ohne Einhausung.* UV-stabil, benzin-/ölbeständig, schlagzäh bis $80\,^\circ\text{C}$ Dauertemperatur.
* **ASA (oder ABS):** *Beste Wahl für Drucker mit geschlossenem Bauraum (z. B. Bambu X1/P1, Prusa XL).* $100\,\%$ UV- und witterungsbeständig, hitzebeständig bis $100\,^\circ\text{C}$.
* **PA-CF / PET-CF:** Exzellente Steifigkeit, seriennahe matte Carbon-Haptik.
* ❌ *Wichtig:* **Kein Standard-PLA verwenden**, da PLA am Motorrad in der prallen Sonne (über $55\,^\circ\text{C}$) erweicht und verzieht!

### Optimale Slicer-Einstellungen für IP67-Dichtigkeit:
* **Wandlinien (Perimeter):** 4 bis 5 Wände einstellen ($\approx 1{,}6 \dots 2{,}0\,\text{mm}$ für massive Wände ohne Hohlräume).
* **Infill:** $25 \dots 40\,\%$ (Gyroid oder Honeycomb).
* **Schichthöhe:** $0{,}16\,\text{mm}$ (saubere O-Ring-Nuten).
* **Flussrate (Flow):** $102 \dots 104\,\%$ (leichte Überextrusion dichtet Mikroporen zuverlässig ab).

---

## 4. Montage der Baugruppen

### Schritt 1: Zentralbox (Main Box) montieren
1. **Gewindeeinsätze:** 4x M3 Messing-Gewindeeinsätze (Ruthex) mit Lötkolben ($240\,^\circ\text{C}$) bündig in die Unterwanne einschmelzen.
2. **Platine fixieren:** Hauptplatine (`openmotorbridge_central_box`) mit M2.5 Schrauben auf die Dämpferdome setzen.
3. **Zwischenboden & Akku:** Oberwanne aufsetzen, 1000 mAh LiPo in die Wanne legen und mit EPDM-Spannband sichern.
4. **Dichtungen & Deckel:** Silikon-Rundschnur (Ø 1,5 mm) in die Deckelnut einlegen, Gore-Membran einkleben und mit 4x M3 x 40 mm Schrauben über Kreuz festziehen.

### Schritt 2: Satelliten-Pods 1, 2 und Heck-Pod 3 (Basisgehäuse & Schottwand)
1. **Basisplatine einsetzen:** `openmotorbridge_pod_base` in das Pod-Gehäuse einschieben und M8-Buchse festziehen.
2. **Schottwand fixieren:** Schottwand mit M2 Schrauben sichern.

### Schritt 3: Headset-Kassetten 1 & 2 montieren (Fahrer & Sozius)
1. **Platine einsetzen:** Kassettenplatine (`openmotorbridge_pod_cartridge`) in den Kassetten-Schlitten einklicken.
2. **OEM-Adapter / Cradle anschließen (nach Gerätetyp):**
   * **Klasse S (Smart Modular Cartridge mit Mechatronik • OMB-Referenz: Sena SPIDER X Slim / 60S / Cardo Edge):**
     * PCBA 03 Rev 2.0 (mit WCH CH32V003 RISC-V MCU und 4x AO3400A MOSFETs) in den Kassetten-Schlitten einsetzen.
     * Monolithische Aktuator-Führungsbrücke mit den 4 Miniatur-Tauchankern (`ACT_PLUS`, `ACT_MINUS`, `ACT_CENTER`, `ACT_MESH`), Rückstellfedern und TPU-Druckspitzen aufsetzen.
     * 8-poliges J_ACT Flachbandkabel von der Brücke mit Header J_ACT auf PCBA 03 verbinden.
     * Headset in das formschlüssige PA12-MJF Konturbett einlegen (3-Punkt EPDM-Dämpfung gegen 20g Vibration) und mit dem werkzeuglosen Schnellspann-Niederhalter fixieren.
     * 3,85V DC Batteriefach-Speisung (oder Flachkabel-USB) an Header J2 anschließen.
   * **Klasse A (Sena +Mesh B2M-01 / MeshPort Adapter):**
     * Adapter seitlich in die Quer-Führungsschienen des Inlays ([`01_insert_sena.scad`](file:///Users/schmidtm/openMotorBridge/hardware/cad/scad/03_pod_cartridges/parts/01_insert_sena.scad)) einschieben, bis die Rastklinke hörbar arretiert.
     * **USB-Speisung verbinden:** Das flache $90^\circ$-Winkelkabel (Micro-USB bzw. USB-C) vom 5V/GND-Header der Kassettenplatine durch die Deckaussparung führen und in den USB-Ladeport des +Mesh stecken (reine 5V-Dauerversorgung; Audio läuft drahtlos via Bluetooth zum Helm).
     * **Antenne:** Die wasserdichte SMA-Flansch-Doppelbuchse mit O-Ring von außen in die $\varnothing 6{,}5\,\text{mm}$ Frontblenden-Bohrung einsetzen und von innen mit der Flanschmutter kontern. Das interne $90^\circ$-Koaxial-Pigtail an den Antennenanschluss des +Mesh schrauben, durch das vordere Kassettenfenster führen und an der Innenseite der Frontblenden-Buchse verschrauben. Bei Nichtgebrauch einer externen Antenne die stirnseitige SMA-Schutzkappe aufschrauben.
     * Mit dem elastischen EPDM-Spannband über die beiden seitlichen Haltenasen gegen Erschütterungen sichern.
   * **Klasse B & C (Sena 50S/60S oder Cardo Packtalk Edge Cradles mit Pogo-Pins):**
     * 6-poliges JST-SH Flachbandkabel von der Kassettenplatine direkt mit der OEM-Pogo-Pin-Leiste (Sena) bzw. dem magnetischen Cardo Air-Mount verbinden (galvanisch getrennte Analog-Audio-Kanäle, Mikrofon und Optokoppler-PTT).
   * **Klasse D (Hermetische Blindkassette):**
     * Schutzschlitten mit geschlossener Frontblende und O-Ring einsetzen, wenn der Beifahrer-Pod ungenutzt bleibt.
3. **Flanschdichtung:** Silikon-Formdichtung auf den Kassettenkragen aufziehen und dünn mit dielektrischem Silikonfett benetzen.

### Schritt 3.1: Montage des magnetischen Diebstahlschutzes (Kassetten-Wippen-Mechanismus)

```
                       MAGNETISCHER DIEBSTAHL-SCHUTZ & AUSWURF-KINEMATIK
┌────────────────────────────────────────────────────────────────────────────────────────┐
│ [Zustand 1: VERRIEGELT]                                                                │
│ Druckfeder drückt Hebelarm ──► 1. Klasse Wippe dreht um M2 Stift ──► Sägezahnkralle     │
│ schwenkt 2.5 mm nach außen in die Gehäusenut. 90°-Sperrflanke blockiert Auszug 100%!   │
├────────────────────────────────────────────────────────────────────────────────────────┤
│ [Zustand 2: ENTRIEGELN & AUSWURFKICK]                                                  │
│ Externer N52 Neodym-Schlüssel an Gehäusemarkierung anlegen ──► Zieht Ø 6x8 mm Stahl-    │
│ anker nach außen ──► Sägezahn schwenkt bündig ein ──► 2x V4A Druckfedern werfen        │
│ Kassette blitzschnell 25 mm weit aus dem Pod-Gehäuse!                                  │
└────────────────────────────────────────────────────────────────────────────────────────┘
```

1. **Stahlanker einpressen:** Den gehärteten ferromagnetischen Stahlstift ($\varnothing 6 \times 8\,\text{mm}$, DIN 6325) in die Querbohrung des hinteren Hebelarms der Wippe ([`05_magnetic_lock_latch.scad`](file:///Users/schmidtm/openMotorBridge/hardware/cad/scad/03_pod_cartridges/parts/05_magnetic_lock_latch.scad)) bündig einpressen.
2. **Rückstellfeder einsetzen:** Die kleine $\varnothing 3{,}5 \times 10\,\text{mm}$ V4A Druckfeder in die innenseitige Federtasche des hinteren Hebelarms stecken.
3. **Wippe im Schlitten montieren:** Die vormontierte Wippe in die Aussparung an der linken Führungswange des Kassetten-Schlittens ([`00_base_sled.scad`](file:///Users/schmidtm/openMotorBridge/hardware/cad/scad/03_pod_cartridges/00_base_sled.scad)) einsetzen. Den $\varnothing 2{,}0 \times 8\,\text{mm}$ Edelstahl-Zylinderstift (DIN 7) von oben durch die Lagerbohrung ($X = 58\,\text{mm}$) durchdrücken.
4. **Funktionsprüfung vor dem Einschieben:**
   * Die Sägezahn-Rastkralle am vorderen Arm ($X = 70\,\text{mm}$) muss durch Federkraft $2{,}5\,\text{mm}$ über die Führungsfeder hinausragen.
   * Den N52 Neodym-Blockmagneten außen an die Höhe des Stahlankers ($X = 46\,\text{mm}$) halten: Die Wippe kippt um $-4{,}8^\circ$, und die Kralle taucht vollständig bündig in den Schlitten ein.

### Schritt 4: Heck-Kassette Pod 3 & HF-Pigtail-Montage (Dreifach-Koaxial-Bypass)
1. **SMA-Bulkhead-Buchsen montieren:**
   * Die 3x SMA-Flanschbuchsen der Murata MM126036 Pigtails von außen durch die vorbereiteten $\varnothing 6{,}5\,\text{mm}$ Bohrungen der Kassetten-Stirnwand führen.
   * Der integrierte Silikon-O-Ring dichtet in der $\varnothing 9{,}5 \times 1{,}2\,\text{mm}$ Gehäusesenkung hermetisch ab.
   * Von innen die Zahnscheibe auflegen und mit der Sechskantmutter (SW 8) handfest mit ca. $0{,}8\,\text{Nm}$ anziehen.
2. **Koaxialkabel im Schlitten verlegen:**
   * Die hochflexiblen RG-178 / 1.13mm Koaxialleitungen in den Längskanal am Schlittenboden einlegen.
3. **Platine einschieben & Pigtails aufklicken:**
   * Heck-Transceiver-Platine (`PCBA 04`) einsetzen und mit M2.5 Schrauben fixieren.
   * Mit einer Kunststoff-Pinzette die rechtwinkligen Murata MM8030-Stecker senkrecht auf die SMD-Umschaltbuchsen aufdrücken, bis sie spürbar einrasten:
     * `J3` $\rightarrow$ 2.4 GHz OpenMotorMesh Bypass
     * `J4` $\rightarrow$ 868 MHz Semtech SX1262 LoRa Bypass
     * `J5` $\rightarrow$ Multi-GNSS u-blox M9N Bypass (mit 3.3V Phantomspeisung)
4. **Funktionsweise der automatischen Umschaltung (Plug & Play):**
   * **Standardbetrieb (ohne externe Antennen):** Auf die SMA-Buchsen werden die IP67-Messing-Rändelkappen aufgeschraubt. Die internen Antennen (2.4 GHz IFA, 868 MHz Wendelantenne und 25x25 mm GNSS-Keramikpatch) arbeiten zu 100 % autark und wettergeschützt im Radom.
   * **Externer Antennenbetrieb:** Wird eine externe Antenne (z. B. Taoglas Collinear am Heck oder aktive Dachantenne am Koffer) aufgeschraubt, hebt die interne Kontaktfeder in der Murata MM8030-Buchse mechanisch ab: Die interne Antenne wird mit $> 25\,\text{dB}$ Isolation entkoppelt und das HF-Signal mit minimalster Einfügedämpfung ($< 0{,}15\,\text{dB}$) auf die externe Antenne geleitet.

### Schritt 4.1: Adventure-Kit Montage am Motorrad (BMW GS / GSA, KTM, Tenere, Africa Twin)

```
                            OPENMOTORBRIDGE ADVENTURE-KIT MOUNTING SUITE
┌────────────────────────────────────────────────────────────────────────────────────────┐
│ CONFIG A: Rohrträger-Klemmschelle (BMW GSA / Touratech Kofferträger)                   │
│ • Schutz im Rohrrahmen-Dreieck (Überrollkäfig-Effekt bei Stürzen auf Geröll/Sand)      │
│ • Klemmt an Ø 18 mm Edelstahlrohr mit 2x M5x30 mm V4A Schrauben & DIN 985 Stoppmuttern │
├────────────────────────────────────────────────────────────────────────────────────────┤
│ CONFIG B: Standard-GS Transition Dock (Sitzbank-Bügelfalte)                            │
│ • 100% kofferunabhängige Montage an Heckrahmen-Unterzügen (z. B. Ø 28 mm Rohr)         │
│ • Flache Einbettung in der Fahrzeugsilhouette, kein Hängenbleiben beim Aufsteigen      │
├────────────────────────────────────────────────────────────────────────────────────────┤
│ CONFIG C: Gepäckbrücken-Ausleger "Heck-Balkon" & Garmin Varia Radar                    │
│ • 65 mm Cantilever hinter Alutopcase: 360° freie HF-Sicht für OpenMotorMesh & GNSS   │
│ • 45° Astabweiser-Finne schützt die Taoglas Dipolantenne vor Ästen im Enduro-Dickicht  │
│ • 36-Zahn Hirth-Formschluss-Gelenk verhindert jedes Absacken (Pitch-Drift) des Radars  │
│ • Garmin Quarter-Turn Bajonett mit verdeckter M3 Torx-TR Madenschraube (Diebstahlschutz)│
└────────────────────────────────────────────────────────────────────────────────────────┘
```

1. **Konfiguration A (Rohrträger-Klemmschelle für Pod 1 & 2):**
   * Einen Streifen $1{,}0\,\text{mm}$ EPDM-Schutzband um das $\varnothing 18\,\text{mm}$ Rohr wickeln.
   * Die Unterschale (`adventure_pannier_rack_clamp_base.stl`) aufsetzen.
   * Die Klemmschale (`adventure_pannier_rack_clamp_cap.stl`) ansetzen und mit 2x M5 x 30 mm Zylinderkopfschrauben und DIN 985 Stoppmuttern über Kreuz gleichmäßig mit $4{,}5\,\text{Nm}$ festziehen.
   * Pod-Basisgehäuse mit M4 Schrauben direkt an den Befestigungsaugen der Schelle verschrauben.
2. **Konfiguration B (Transition-Dock an Sitzbank-Bügelfalte):**
   * Das Dock (`adventure_transition_dock.stl`) unterhalb der Sitzbankkante an das Rahmenrohr klemmen.
   * Das M8 PUR-Zuleitungskabel durch den Kabelschacht an der Unterseite unter die Sitzbank zur Zentralbox führen.
3. **Konfiguration C (Gepäckbrücken-Ausleger "Heck-Balkon" für Pod 3 & Radar):**
   * Den Ausleger (`adventure_rack_tail_mount.stl`) mit 4x M6 Schrauben an den vorbereiteten Bohrungen der Aluminium-Gepäckbrücke verschrauben.
   * Pod 3 in das Trägerbett einlegen und mit 2x EPDM-Sicherungsbändern in den Halteschlitzen arretieren.
   * Die Taoglas 2,4 GHz Dipolantenne auf den SMA-Port schrauben und entlang der $45^\circ$-Astabweiser-Finne ausrichten.
4. **Radar-Dock & 36-Zahn Hirth-Formschluss montieren:**
   * Die Zentralzunge des Garmin Varia Docks (`radar_varia_gopro_lock_dock.stl`) in die Doppelgabel des Heck-Balkons einschieben.
   * Die 36 radialen Hirth-Zähne formschlüssig in den gewünschten Neigungswinkel einrasten ($10^\circ$-Schritte, z. B. $+10^\circ$ bis $+15^\circ$ für exakten Radar-Horizont).
   * M5 x 25 mm V4A Schraube durchstecken und mit DIN 985 M5 Sicherungsmutter mit $3{,}5\,\text{Nm}$ anziehen (durch den Formschluss ist ein Verdrehen durch Wellblech-Vibrationen physikalisch ausgeschlossen).
   * Garmin Varia Radar senkrecht einsetzen, $90^\circ$ im Uhrzeigersinn drehen, bis die akustische Rastklinke einschnappt.
   * Die M3 x 6 mm Torx-TR Sicherungsmadenschraube handfest eindrehen, sodass der Bajonettflügel blockiert ist (Diebstahlschutz ohne Werkzeug).

---

## 5. Universal Front-Knoten Aufbau & Montage

### 5.1 Zusammenbau der Front-Node Box
1. **Gewindeeinsätze einschmelzen:**
   * 4x M3 Messingeinsätze in die Gehäuse-Ecken der Unterwanne einschmelzen.
   * 4x M4 Messingeinsätze in das AMPS-Lochbild ($30 \times 38\,\text{mm}$) am Gehäuseboden einschmelzen.
2. **Akustik-Membran einsetzen:** Hydrophobe Gore ePTFE-Membran über die Schallöffnung des Knowles MEMS Mikrofons kleben.
3. **Platine montieren:** Front-Node Platine (`PCBA 05`) mit M2.5 Schrauben fixieren.
4. **HF-Antennenmontage (ESP32-S3 2,4 GHz):**
   * Die flexible 2,4-GHz-FPC-Dipolantenne (z. B. Molex 146153) in die $48 \times 12\,\text{mm}$ Klebetasche an der Innenseite des Gehäusedeckels einkleben.
   * Das $1{,}13\,\text{mm}$ Mikro-Koaxialkabel in den Führungskanal der Deckeldecke einlegen und den U.FL / IPEX-MHF1 Stecker senkrecht auf die Antennenbuchse des ESP32-S3-WROOM-1U Moduls aufklicken. (Optional: Für extreme Einbaulagen wie Vollcarbon-Verkleidungen kann das Kabel durch einen EPDM-Kammschlitz nach außen geführt werden).
5. **Kabel in Front- & Flankenöffnungen einlegen:**
   * **Vordere Öffnung (Südwand, 4 Kanäle $\varnothing 4{,}2\,\text{mm}$ für USB):**
     * Kurzes USB-A Flachbandkabel in Kanal 1 einlegen und an Port `J6` (geschalteter VBUS für CarPlay / Dongle) anstecken.
     * $1{,}0\,\text{m}$ langes USB-C Ladekabel in Kanal 2 einlegen und an Port `J5` (Handschuhfach) anstecken.
     * USB-Kabel in Kanal 3 einlegen und an Port `J4` (USB-Host) anstecken.
     * 5V Action-Cam Ladekabel in Kanal 4 einlegen und an Port `J8` (5V Dauerladung mit Pufferkondensator C_BUF) anstecken.
   * **Rechte Öffnung (Ostwand, USB-C Service-Port):**
     * Die elastische USB-C Staubschutzkappe (`front_node_usbc_cap_tpu.stl`) mit dem Dichtkragen in die Gehäusetasche des Service-Ports `J7` eindrücken.
   * **Linke Öffnung (Westwand, 3 Kanäle $\varnothing 3{,}2\,\text{mm}$ für Signale & Power):**
     * 12V Bordnetzzuleitung (KL15 & GND) mit JST-PH 2-Pin Stecker in Kanal 1 einlegen und an `J1` einrasten.
     * CAN-Bus Leitung mit JST-PH 3-Pin Stecker in Kanal 2 einlegen und an `J2` einrasten.
     * Lenker-PTT Steuerleitung mit JST-PH 2-Pin Stecker in Kanal 3 einlegen und an `J3` einrasten.
6. **Dichtkämme einsetzen & Deckel verschließen:**
   * Einen dünnen Hauch Silikonfett auf die Außenflanken der EPDM/TPU Dichtkämme auftragen.
   * Kämme in die Gehäusetaschen einschieben (die Schlitze schließen sich um die Kabel).
   * Umlaufende Silikon-Rundschnur ($\varnothing 1{,}5\,\text{mm}, 30\,\text{cm}$) in die Deckelnut einlegen und mit 4x M3 x 20 mm Schrauben über Kreuz festziehen (die Dichtkämme werden dabei um ca. $15\,\%$ komprimiert und dichten hermetisch IP67 ab).

### 5.2 Montage am Fahrzeug (4 Optionen)

```
┌────────────────────────────────────────────────────────────────────────┐
│               MONTAGE-OPTIONEN DES UNIVERSAL FRONT-KNOTENS             │
├────────────────────────────────────────────────────────────────────────┤
│ Option 1: AMPS-Bohrung (30 x 38 mm)                                    │
│ • Direktmontage an RAM-Mount Kugel, Garmin-Halter oder Navi-Strebe     │
│ • Perfekt für Adventure-Bikes und Naked Bikes                          │
├────────────────────────────────────────────────────────────────────────┤
│ Option 2: 120° V-Nut Rohrbett mit EPDM-Spannringen                     │
│ • Werkzeuglose Befestigung an Ø 22 bis Ø 32 mm Sturzbügeln (BMW GS/RT) │
│ • Vibrationsgedämpft, beschädigt keine Lackierung                      │
├────────────────────────────────────────────────────────────────────────┤
│ Option 3: M4 Silentblöcke                                              │
│ • Schwingungsentkoppelte Schraubmontage im Verkleidungsschnabel         │
├────────────────────────────────────────────────────────────────────────┤
│ Option 4: 3M Dual-Lock Klettnuten                                      │
│ • Verdeckte Innenmontage an der Innenseite von Harley Batwing /        │
│   Sharknose Frontverkleidungen                                         │
└────────────────────────────────────────────────────────────────────────┘
```

### 5.3 Elektrischer Anschluss am Motorrad
* **12V Bordnetz-Einspeisung:** Der Front-Knoten benötigt lediglich eine einzige 2-adrige Zuleitung (KL15 Zündungsplus und Fahrzeugmasse), die am Standlicht, Scheinwerfer oder Cartool-Zubehörstecker abgegriffen wird.
* **Ottocast Dongle:** Wird an USB-A Port `J1` angesteckt und mit 3M Dual-Lock in der Verkleidung fixiert.
* **Handschuhfach:** Ein USB-C Verlängerungskabel führt von Port `J2` ins Handschuhfach für das Smartphone.
* **Lenkertaster:** 2-adriges Kabel vom mechanischen Lenker-PTT-Taster führt auf Buchse `J3` (GPIO 0).

---

## 6. Erstinbetriebnahme & Software-Flash (Schritt-für-Schritt)

```bash
# 1. Firmware-Repository klonen & in Zentralcontroller-Verzeichnis wechseln
cd openMotorBridge/firmware/main_controller

# 2. Zentralcontroller via USB-C flashen (ESP32-S3)
pio run --target upload

# 3. Kassetten-Profile auf das LittleFS-Dateisystem hochladen
pio run --target uploadfs

# 4. Heck-Co-Prozessor flashen (RP2040 in Pod 3)
cd ../rear_coprocessor
pio run --target upload

# 5. Front-Knoten flashen (ESP32-S3)
cd ../front_node
pio run --target upload
```

### Selbsttest-Checkliste:
1. [ ] **Labornetzteil:** $12{,}0\,\text{V}$ anlegen (Strombegrenzung $150\,\text{mA}$). Ruhestrom messen: Sollwert $= 45 \dots 75\,\text{mA}$.
2. [ ] **Status-LED:** Blinkt nach dem Start grün (System bereit, Pufferakku lädt).
3. [ ] **Web-Dashboard:** Im Browser via Web-Bluetooth mit `OpenMotorBridge_v8` koppeln.
4. [ ] **Kassettenerkennung:** Kassetten in Pod 1 und 2 einstecken $\rightarrow$ Profile werden im Dashboard sofort mit Seriennummer angezeigt.
5. [ ] **Front-Knoten Funkverbindung:** Status-Kachel im Dashboard zeigt `ESP-NOW LINK (2.4 GHz) - BEREIT`.
6. [ ] **PTT-Test:** Lenkertaster drücken $\rightarrow$ Grüne PTT-Anzeige im Dashboard leuchtet auf (`< 1.8 ms Latenz`), TLP222A Optokoppler schaltet durch.
7. [ ] **CarPlay Kaltstart-Test:** Im Dashboard auf "CarPlay 1-Klick Kaltstart" klicken $\rightarrow$ VBUS schaltet für $2{,}5\,\text{s}$ auf $0{,}00\,\text{V}$ ab und startet sauber neu.
8. [ ] **Audio-Check:** Headset koppeln, Musik abspielen $\rightarrow$ sauberes, glasklares Signal ohne Lichtmaschinenpfeifen oder Masseschleifen (dank 1500V Bourns Übertrager-Trennung).

---

## 7. Wartung & Pflege

* **Dichtungsinspektion:** 1x pro Saison die O-Ring-Dichtschnur der Main Box, des Front-Knotens und der Kassetten mit Silikonfett pflegen.
* **Druckausgleich:** Sicherstellen, dass die ePTFE-Gore-Membranen sauber und durchlässig sind.
* **Firmware-Updates:** Drahtlos und ohne Ausbau direkt über die WebBLE-PWA-Oberfläche durchführbar.

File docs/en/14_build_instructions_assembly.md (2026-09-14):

# 14 - Build Instructions, Wiring & Vehicle Installation

This document is the comprehensive, hands-on assembly guide for building a complete **OpenMotorBridge (v8.0)** hardware kit for a motorcycle. It details 3D printing parameters, mechanical assembly, cable harnessing, Front Node installation, and the step-by-step commissioning checklist.

---

## 1. Kit Architecture Overview

A complete OpenMotorBridge motorcycle installation comprises:

```
                      ┌─────────────────────────────────────────┐
                      │    1x CENTRAL MAIN BOX (IP67)           │
                      │    (Under-seat / tail frame)            │
                      │    • Lower case + mid tray + lid        │
                      │    • Main PCB (ESP32-S3, Codec, UPS)    │
                      │    • Integrated LiPo backup battery     │
                      └────────────────────┬────────────────────┘
                                           │
                        1x CENTRAL HARNESS (HD26 IP67)
                                           │
         ┌─────────────────────────────────┼─────────────────────────────────┐
         │                                 │                                 │
         ▼                                 ▼                                 ▼
┌──────────────────┐             ┌──────────────────┐              ┌──────────────────┐
│ 1x POD 1 (LEFT)  │             │ 1x POD 2 (RIGHT) │              │ 1x POD 3 (TAIL)  │
│ (Frame / Bar)    │             │ (Frame / Bar)    │              │ (Tail Cowl)      │
│ • Pod Enclosure  │             │ • Pod Enclosure  │              │ • Pod Enclosure  │
│ • Baseboard      │             │ • Baseboard      │              │ • Baseboard      │
│ • CARTRIDGE 1    │             │ • CARTRIDGE 2    │              │ • CARTRIDGE 3    │
│   (e.g., Sena)   │             │   (e.g., Cardo)  │              │   (LoRa + GNSS)  │
└──────────────────┘             └──────────────────┘              └──────────────────┘
                                           │
                                           ▼ 2.4 GHz Wireless Link (ESP-NOW < 1.8 ms)
                                 ┌──────────────────────────────────┐
                                 │ 1x UNIVERSAL FRONT NODE (IP67)   │
                                 │ (Cockpit & Sensor Hub)           │
                                 │ • 4-in-1 Universal Mounting      │
                                 │ • Ottocast USB-A Port (CarPlay)  │
                                 │ • Glovebox USB-C Charging Port   │
                                 │ • Knowles MEMS Wind Sensor       │
                                 │ • Battery-Free Handlebar PTT     │
                                 └──────────────────────────────────┘
```

---

## 2. Bill of Materials for One Complete Kit (What You Need for 1 Motorcycle)

To build a fully featured OpenMotorBridge (v8.0) installation for one motorcycle, the following complete bill of materials is required. It groups all components across 6 structured categories:

### 2.1 Category A: 3D Printed Parts (MJF PA12 Black or FDM ASA/PETG)
*Recommended manufacturing method: HP Multi Jet Fusion (MJF) or SLS in PA12 (glass-bead blasted, black dyed) or FDM in ASA/PET-CF. CAD files located in [`hardware/cad/stl/`](file:///Users/schmidtm/openMotorBridge/hardware/cad/stl/).*

| Subassembly | STL File Name | Qty | Function & Description |
| :--- | :--- | :---: | :--- |
| **Main Box Lower Tub** | [`main_box_lower_case.stl`](file:///Users/schmidtm/openMotorBridge/hardware/cad/stl/01_main_box/main_box_lower_case.stl) | **1** | Monocoque tub with 4x M4 silentblock tabs, 4x PCB standoffs, and perimeter O-ring groove |
| **Main Box Mid Tray** | [`main_box_mid_tray.stl`](file:///Users/schmidtm/openMotorBridge/hardware/cad/stl/01_main_box/main_box_mid_tray.stl) | **1** | Battery tray for 1000 mAh LiPo, 10x convection chimney slots & tongue-and-groove rib |
| **Main Box Lid** | [`main_box_lid.stl`](file:///Users/schmidtm/openMotorBridge/hardware/cad/stl/01_main_box/main_box_lid.stl) | **1** | Heavy-duty top lid with Gore ePTFE AVS 41 vent boss & 4x M3 screw counterbores |
| **Pod Base Enclosures** | [`pod_base_housing.stl`](file:///Users/schmidtm/openMotorBridge/hardware/cad/stl/02_pod_base/pod_base_housing.stl) | **3** | Universal bay enclosure for Pod 1 (Left), Pod 2 (Right), and Pod 3 (Tail) with 120° pipe bed |
| **Pod Bulkhead Partitions**| [`03_pod_bulkhead_partition.stl`](file:///Users/schmidtm/openMotorBridge/hardware/cad/stl/02_pod_base/components/03_pod_bulkhead_partition.stl) | **3** | Internal bulkhead with sealing collar & dual spring retainer posts (1 per pod) |
| **Cartridge 1 (Rider)** | [`cartridge_sena_sled.stl`](file:///Users/schmidtm/openMotorBridge/hardware/cad/stl/03_pod_cartridges/cartridge_sena_sled.stl) *(or Cardo)* | **1** | Hot-swap sled for primary rider headset (Sena 50S/60S or Cardo Packtalk Edge) |
| **Cartridge 2 (Passenger)**| [`cartridge_cardo_sled.stl`](file:///Users/schmidtm/openMotorBridge/hardware/cad/stl/03_pod_cartridges/cartridge_cardo_sled.stl) *(or Blank)* | **1** | Hot-swap sled for passenger headset or hermetic blank protector cartridge |
| **Cartridge 3 (Tail)** | [`cartridge_omm_transceiver_sled.stl`](file:///Users/schmidtm/openMotorBridge/hardware/cad/stl/03_pod_cartridges/cartridge_omm_transceiver_sled.stl) | **1** | Rear pod sled holding RP2040 coprocessor, active GNSS patch, and 868 MHz LoRa helical antenna |
| **Front Node Lower Tub** | [`front_node_lower_tub.stl`](file:///Users/schmidtm/openMotorBridge/hardware/cad/stl/04_front_node/front_node_lower_tub.stl) | **1** | Cockpit fairing tub with AMPS hole pattern ($30 \times 38\,\text{mm}$), EPDM cable combs & V-bed (PA12 / ASA) |
| **Front Node Upper Lid** | [`front_node_upper_lid.stl`](file:///Users/schmidtm/openMotorBridge/hardware/cad/stl/04_front_node/front_node_upper_lid.stl) | **1** | Front lid with acoustic sound entry port for Knowles MEMS & perimeter gasket groove (PA12 / ASA) |
| **Front Node Cable Glands**| [`front_node_cable_glands_tpu.stl`](file:///Users/schmidtm/openMotorBridge/hardware/cad/stl/04_front_node/front_node_cable_glands_tpu.stl) | **1 Pair** | Elastomeric cable glands for Front (3x USB) & Left (3x Signals/Power) (TPU 95A / 85A) |
| **Front Node USB-C Cap** | [`front_node_usbc_cap_tpu.stl`](file:///Users/schmidtm/openMotorBridge/hardware/cad/stl/04_front_node/front_node_usbc_cap_tpu.stl) | **1** | Elastomeric protective dust cap with retaining tether for service port (TPU 95A / 85A) |
| **Rear Radar Dual Bracket**| [`pod3_radar_bracket.stl`](file:///Users/schmidtm/openMotorBridge/hardware/cad/stl/02_pod_base/pod3_radar_bracket.stl) | **1** | M5 GoPro-style swivel hinge for horizontal leveling of Garmin Varia / mmWave radar |
| **Total 3D Printed Parts** | | **17** | **Complete hardware set for 1 motorcycle installation (15x PA12/ASA + 2x TPU)** |

---

### 2.2 Category B: Assembled Circuit Boards (5 PCBAs from JLCPCB / Eurocircuits)
*Production files (Gerber ZIP, BOM CSV, CPL Pick & Place) located in [`hardware/production_packages/`](file:///Users/schmidtm/openMotorBridge/hardware/production_packages).*

| Circuit Board | Project / Identifier | Qty | Layer Count & Spec | Core Functions |
| :--- | :--- | :---: | :--- | :--- |
| **PCBA 01** | Central Main Controller (`kicad_main_box`) | **1** | 4-Layer FR4 TG150, ENIG Gold | ESP32-S3 Dual-Core, LM5164 DCDC, BQ24075 UPS, ES8388 Codec, Bourns audio transformers, BMI270 IMU, MicroSD |
| **PCBA 02** | Pod Base Carrier Board (`kicad_pod_base`) | **3** | 2-Layer FR4, ENIG Gold | M8 6-pin IP67 socket, SP3012 ESD array, Harwin 6-pin precision header with 4.8mm wipe |
| **PCBA 03** | Smart Modular Cartridge Board Rev 2.0 (`kicad_cartridge`)| **2** | 2-Layer FR4, ENIG Gold | WCH CH32V003 RISC-V MCU (1-Wire emulation & opcode engine), 4x AO3400A N-MOSFETs, Harwin 6-pin socket, J_ACT 8-pin mechatronics header, J2 6-pin audio/power |
| **PCBA 04** | Rear Pod 3 Transceiver (`kicad_rear_pod3`) | **1** | 4-Layer FR4 TG150, ENIG Gold | RP2040 coprocessor, u-blox NEO-M9N / MAX-M10S GNSS, Semtech SX1262 LoRa, 3x Murata MM8030 RF switches |
| **PCBA 05** | Universal Front Node (`kicad_front_node`) | **1** | 4-Layer FR4 TG150, ENIG Gold | ESP32-S3 Dual-Core, USB2514B Hub, LMR36015 DCDC, SC8102 USB-PD, TPS2051B power switch, Knowles MEMS mic, PTT trigger |

---

### 2.3 Category C: Mechanical Fasteners, Screws & Springs (A4 Stainless Steel / Brass)

| Fastener | Specification / Standard | Qty | Location & Purpose |
| :--- | :--- | :---: | :--- |
| **M3 Threaded Inserts** | Ruthex Brass M3 $\times 5.7\,\text{mm}$ (RX-M3x5.7) | **8** | 4x Main Box tub corners, 4x Front Node tub corners (heat-set at $220\,^\circ\text{C}$) |
| **M4 Threaded Inserts** | Ruthex Brass M4 $\times 8.1\,\text{mm}$ (RX-M4x8.1) | **4** | Front Node AMPS base pattern ($30 \times 38\,\text{mm}$) |
| **Main Case Screws** | Socket Head Cap DIN 912 A4 M3 $\times 40\,\text{mm}$ | **4** | Through-bolt 4-corner clamp for Central Main Box |
| **Front Node Screws** | Socket Head Cap DIN 912 A4 M3 $\times 20\,\text{mm}$ | **4** | 4-corner clamp for Universal Front Node |
| **PCB Mounting Screws** | Socket Head Cap DIN 912 A4 M2.5 $\times 6\,\text{mm}$| **8** | 4x Main Box PCB, 4x Front Node PCB |
| **Pod Bulkhead Screws** | Countersunk DIN 7991 A4 M2 $\times 8\,\text{mm}$ | **6** | Secures internal bulkheads in Pod 1, 2, and 3 (2 per pod) |
| **Ejector Coil Springs** | A4 Stainless Steel ($\varnothing 4.5\,\text{mm}, L_0=15\,\text{mm}, R=1.2\,\text{N/mm}$) | **6** | Auto-eject snap release mechanism (2 per pod bulkhead) |
| **Rubber Silentblocks** | Type A Rubber Bobbins (M4 Male / M4 Female, $\varnothing 15 \times 10\,\text{mm}$) | **4** | Vibration-isolated frame mounting for Central Main Box |
| **Nyloc Nuts & Washers** | DIN 985 M4 Nyloc Nuts + DIN 125 A4 Washers | **4** | Secures silentblocks to motorcycle subframe tabs |
| **M5 Clamp Screw & Nut** | Socket Head Cap DIN 912 A4 M5 $\times 25\,\text{mm}$ + M5 Acorn Nut | **1** | Secures GoPro-style radar hinge arm on Pod 3 |

---

### 2.4 Category D: Gaskets, Venting & Light Pipes (IP67)

| Component | Specification | Qty | Location & Function |
| :--- | :--- | :---: | :--- |
| **Silicone O-Ring Cord Main**| Silicone Solid Cord $\varnothing 1.5\,\text{mm}$ Shore 40A/50A ($40\,\text{cm}$) | **1** | Perimeter tongue-and-groove seal on Central Main Box |
| **Silicone O-Ring Cord Front**| Silicone Solid Cord $\varnothing 1.5\,\text{mm}$ Shore 40A/50A ($30\,\text{cm}$) | **1** | Perimeter lid seal on Universal Front Node |
| **Cartridge Face Seals** | Molded Silicone Flange Seal Shore 40A ($54 \times 18\,\text{mm}$, $1.5\,\text{mm}$) | **3** | Mouth opening seal on Pod 1, 2, and 3 |
| **EPDM Slotted Cable Combs** | EPDM Closed-Cell Rubber Slotted Block ($15 \times 8 \times 4\,\text{mm}$) | **2** | Waterproof cable feedthrough sealing in Front Node |
| **Pressure Relief Vent** | Gore Automotive AVS 41 (M8x1.25 screw-in vent) | **1** | Pressure equalization & condensation prevention in Main Box lid |
| **ePTFE Adhesive Vents** | Gore / Porex IP67 Adhesive Vent Disc $\varnothing 6.0 \dots 7.0\,\text{mm}$ | **5** | 3x Pod vent bosses, 1x Front Node, 1x Knowles MEMS acoustic port |
| **Optical Light Pipe** | Bivar PLPC3-3MM or Mentor PMMA $\varnothing 3.0\,\text{mm}$ ($L=8\,\text{mm}$) | **1** | Waterproof transmission of WS2812B RGB LED through Main Box lid |

---

### 2.5 Category E: Wiring Harness, Connectors, Backup Battery & RF Pigtails

| Component | Specification / Type | Qty | Purpose & Function |
| :--- | :--- | :---: | :--- |
| **HD26 IP67 Flange Socket**| Amphenol LTW HD26 Female (Front-mount with silicone seal) | **1** | Waterproof chassis interface on Central Main Box |
| **HD26 IP67 Cable Plug** | HD26 Male Connector with thumb screws & compression gland | **1** | Primary connector terminating the bike breakout harness |
| **M8 6-Pin Socket Leads** | M8 6-Pin A-coded IP67 Female (PUR shielded, 250 mm) | **3** | Pigtails 1, 2, and 3 on harness connecting to Pods |
| **M8 4-Pin Socket Lead** | M8 4-Pin A-coded IP67 Female (PUR shielded, 250 mm) | **1** | Pigtail 5 on harness for Rear Radar (Garmin Varia / mmWave) |
| **AMP Superseal 1.5 Socket**| TE Connectivity AMP Superseal 1.5 4-Pin Female Housing | **1** | Pigtail 4 on harness for 12V vehicle power (KL30, KL15, GND) |
| **M8 Extension Cables** | M8 6-Pin A-coded Male/Female (PUR shielded, 1.0 m / 1.5 m) | **3** | Extension cables from under-seat pigtails to pods |
| **UPS Backup Battery** | 1S 3.7V LiPo 1000 mAh with integrated 10k NTC | **1** | Seamless UPS power reserve inside Main Box (Molex Micro-Fit 3.0) |
| **Automotive Fuse Holder** | Waterproof Mini-Blade Inline Fuse Holder IP67 + **2A Fuse** | **1** | Protects permanent 12V supply (KL30) directly at battery terminal |
| **Automotive Wire** | FLRY-B $0.5\,\text{mm}^2$ (Power/GND) and $0.35\,\text{mm}^2$ (Signals/Audio) | *As req.* | Custom bike harness per [`central_breakout_harness_wirelist.csv`](file:///Users/schmidtm/openMotorBridge/hardware/production_packages/05_wiring_harness_spec/central_breakout_harness_wirelist.csv) |
| **EPDM Frame Straps** | UV/Ozone-resistant EPDM ladder straps ($\varnothing 45 \dots 75\,\text{mm}$) | **6** | Tool-free rapid mounting of pods to crash bars or frame tubes |
| **Murata MM8030 Pigtails** | Murata MM126036 to SMA Bulkhead IP67 (150 mm, RG-178)| **3** | Coaxial bypass for Pod 3: J3 (2.4G), J4 (868M), J5 (GNSS) |
| **U.FL Coaxial Pigtail** | IPEX MHF1 / U.FL to RP-SMA Bulkhead IP67 (150 mm, RG-178)| **1** | Coaxial feed for Front Node ESP32-S3 external antenna |
| **SMA Flange Double Bulkhead**| SMA Female to SMA Female Bulkhead IP67 with O-ring & nut | **1** | Waterproof RF feedthrough in cartridge faceplate (Class A) |
| **Internal Coax Pigtail** | RG-178 Coaxial Cable ($6\dots 10\,\text{cm}$, 90° SMA Male to SMA Male)| **1** | RF connection from Sena +Mesh / OEM adapter to faceplate |
| **SMA IP67 Protective Caps** | Nickel-plated brass with internal O-ring (knurled cap)| **5** | Waterproof seal for unpopulated SMA ports (3x Pod 3, 1x Front, 1x Pod) |
| **External Antennas (Opt.)**| 2.4G Collinear (+5 dBi), 868M LoRa (+3 dBi), Active GNSS Puck | *Optional* | High-gain external antennas for long range & unobstructed sky view |
| **USB-A Flat Ribbon Cable (Front)**| Short 90° USB-A male-to-female adapter ($10\dots 15\,\text{cm}$)| **1** | Ottocast connection to J1 via front cable gland |
| **USB-C Glovebox Cable (Front)**| Right-angle USB-C male-to-male ($1.0\,\text{m}$, PUR/Nylon) | **1** | Smartphone charging from J2 via front cable gland |
| **JST-GH Connector Kit (Left)** | JST-GH 1.25mm 2-pin female housings + crimp terminals | **2 sets** | Pre-crimped harness leads for J3 (PTT) & J7 (12V) |
| **90° USB Cartridge Cable** | Low-profile 90° right-angle Micro-USB/USB-C ($5\dots 8\,\text{cm}$) | **1** | 5V power feed for Sena +Mesh / MeshPort inside cartridge |
| **EPDM Cartridge Retaining Band**| Elastic EPDM rubber strap ($\approx 35 \times 10\,\text{mm}$) | **1** | Vibration-proof retention of OEM adapter via cartridge hooks |

---

### 2.6 Category F: Required Tools, Measurement Equipment & Assembly Chemicals

To assemble all subassemblies with vibration resistance and hermetic IP67 sealing, the following toolkit and consumables are recommended:

| Tool / Equipment | Recommended Model / Specification | Purpose in the Project | Essential? |
| :--- | :--- | :--- | :---: |
| **Hex Key Set (Ball End)** | Sizes 1.5 mm / 2.0 mm / 2.5 mm / 3.0 mm | M2 bulkheads, M2.5 PCBAs, M3 cases, M5 radar hinge | **Yes** |
| **Open Wrenches / Sockets** | 7 mm (M4 nuts), 8 mm (SMA bulkheads), 10 mm (Battery terminal) | Tightening silentblock nuts & SMA RF receptacles | **Yes** |
| **Precision Torque Screwdriver**| $0.2 \dots 1.5\,\text{Nm}$ (e.g. Wera 7440) | Even torque on M3 lids ($0.8\,\text{Nm}$) & PCBAs ($0.4\,\text{Nm}$) | *Recommended* |
| **Adjustable Soldering Station**| $200 \dots 450\,^\circ\text{C}$ (e.g. TS101, Pinecil, Weller) | Heat-set insert installation & harness soldering | **Yes** |
| **Ruthex Heat-Set Tips** | Dedicated brass soldering tips for M3 & M4 (Ruthex / CNC Kitchen)| Perpendicular, ridge-free insert seating ($220 \dots 240\,^\circ\text{C}$) | *Recommended* |
| **Micro-Crimp Pliers** | Engineer PA-09 or IWISS IWS-2820M ($1.0 \dots 1.6\,\text{mm}$ pitch) | Crimping JST-SH (1.0 mm Cartridges) & JST-GH (1.25 mm Front Node) | **Yes** |
| **Automotive Crimper** | For uninsulated open-barrel automotive terminals ($0.5 \dots 1.5\,\text{mm}^2$)| 12V spade terminals & M6 battery terminal ring lugs | **Yes** |
| **Precision Wire Stripper** | $0.08 \dots 1.0\,\text{mm}^2$ (AWG 28–18, e.g. Knipex 12 62 180) | Nick-free stripping of thin FLRY-B wires | **Yes** |
| **Flush Wire Cutters** | Precision electronics diagonal cutter (e.g. Knipex Super Knips) | Flush cuts on wires, pins, and zip-ties without sharp burrs | **Yes** |
| **Heat Gun / Hot Air Blower**| With reduction nozzle ($150 \dots 300\,^\circ\text{C}$) | Shrinking dual-wall adhesive-lined heatshrink tubing on harness | **Yes** |
| **ESD Precision Tweezers** | Fine curved plastic/ceramic tipped tweezers | Damage-free perpendicular snapping of Murata MM8030 & U.FL plugs | **Yes** |
| **Digital Multimeter (DMM)** | With continuity buzzer & mV/mA ranges | Harness continuity checking, quiescent current & 5V/3.3V rails | **Yes** |
| **Benchtop Power Supply** | $0 \dots 30\,\text{V DC}, 0 \dots 3\,\text{A}$ (adjustable current limit) | Safe first power-up at 12.0V / 150mA to prevent short-circuit damage | **Yes** |
| **Dielectric Silicone Grease**| OKS 1110 or Liqui Moly Silicone Paste (transparent, dielectric) | Lubrication of silicone O-rings, EPDM combs & cartridge lips | **Yes** |
| **Threadlocker (Loctite 243)** | Medium strength (blue) | Prevents motorcycle screw loosening under heavy vibrations | **Yes** |
| **Conformal Coating** | Peters Elpeguard SL 1307 or Electrolube UR5041 (IPC-CC-830B) | Full PCB encapsulation against condensation and road salt spray | *Recommended* |
| **Scalpel / Precision Knife** | With fresh sharp blade | Burr-free trimming of silicone cord gaskets & EPDM blocks | **Yes** |
| **USB-C Data Cable** | High-quality USB 2.0/3.0 data cable (not a power-only cable!) | Flashing ESP32-S3 (Main & Front) and RP2040 (Rear) via PlatformIO | **Yes** |

---

## 3. 3D Printing Guidelines (FDM vs. Industrial MJF)

### Recommended Filaments for Outdoor Motorcycle Use (FDM):
* **PETG:** *Ideal for open-frame printers.* UV-resistant, oil/chemical tolerant, heat stable up to $80\,^\circ\text{C}$.
* **ASA (or ABS):** *Best choice for enclosed printers (Bambu X1/P1, Prusa XL).* 100% UV stable, heat resistant to $100\,^\circ\text{C}$.
* **PA-CF / PET-CF:** Extreme stiffness and OEM-grade matte carbon texture.
* ❌ *Warning:* **Do NOT use standard PLA**, as it softens and deforms in direct sunlight (exceeding $55\,^\circ\text{C}$).

### Optimal Slicer Settings for IP67 Water Resistance:
* **Perimeters (Walls):** Set to 4–5 walls ($\approx 1{,}6 \dots 2{,}0\,\text{mm}$ thickness, resulting in 100% solid shell).
* **Infill:** $25 \dots 40\,\%$ Gyroid.
* **Layer Height:** $0{,}16\,\text{mm}$ (produces smooth O-ring sealing grooves).
* **Flow Rate:** $102 \dots 104\,\%$ (slight over-extrusion fuses inter-layer micropores).

---

## 4. Subsystem Assembly Steps

### Step 1: Central Control Box Assembly
1. **Heat-Set Inserts:** Melt 4x M3 brass threaded inserts (Ruthex) into the lower tub using a soldering iron ($240\,^\circ\text{C}$).
2. **Mount Main PCB:** Secure the main controller (`PCBA 01`) onto the damping standoffs using M2.5 screws.
3. **Mid Tray & Battery:** Position the upper case with the intermediate tray, place the 1000 mAh LiPo into the battery pocket, and secure with the EPDM strap.
4. **Gasket & Lid:** Seat the $\varnothing 1{,}5\,\text{mm}$ silicone O-ring cord into the perimeter groove, adhere the Gore ePTFE vent, and tighten the 4x M3 x 40 mm stainless screws in a cross pattern.

### Step 2: Satellite Pods 1, 2, and Rear Pod 3 (Tub & Bulkhead)
1. **Install Baseboard:** Slide `openmotorbridge_pod_base` into the pod tub and tighten the M8 hex nut.
2. **Mount Bulkhead:** Secure the protective partition wall with 2x M2 countersunk screws.

### Step 3: Headset Cartridges 1 & 2 (Rider & Passenger)
1. **Assemble Cartridge:** Snap the cartridge carrier (`PCBA 03`) into the sled.
2. **Connect OEM Adapter / Cradle (by device class):**
   * **Class S (Smart Modular Cartridge with Mechatronics • OMB Reference: Sena SPIDER X Slim / 60S / Cardo Edge):**
     * Seat PCBA 03 Rev 2.0 (with WCH CH32V003 RISC-V MCU and 4x AO3400A MOSFETs) into the cartridge sled.
     * Mount the monolithic actuator guide bridge with the 4 miniature plungers (`ACT_PLUS`, `ACT_MINUS`, `ACT_CENTER`, `ACT_MESH`), return springs, and TPU contact tips.
     * Connect the 8-pin J_ACT ribbon cable from the actuator bridge to header J_ACT on PCBA 03.
     * Place the factory-unopened headset into the PA12-MJF form-fit contour bed (3-point EPDM damping against 20g shock/vibration) and lock the tool-free quick-release clamp.
     * Connect the factory 3.85V DC direct battery compartment supply (or low-profile USB) to header J2.
   * **Class A (Sena +Mesh B2M-01 / MeshPort Adapter):**
     * Slide the adapter laterally into the transverse slide rails of the cradle insert ([`01_insert_sena.scad`](file:///Users/schmidtm/openMotorBridge/hardware/cad/scad/03_pod_cartridges/parts/01_insert_sena.scad)) until the retaining snap latch clicks into place.
     * **Connect USB Power:** Route the low-profile $90^\circ$ right-angle cable (Micro-USB or USB-C) from the cartridge PCB 5V/GND header through the deck window into the +Mesh USB charging port (pure 5V continuous power supply; intercom audio routes wirelessly over Bluetooth to the helmet).
     * **RF Antenna:** Insert the waterproof SMA female-to-female flange bulkhead with O-ring from the outside into the $\varnothing 6.5\,\text{mm}$ faceplate bore and secure from the inside with the locknut. Connect the internal $90^\circ$ coaxial pigtail to the +Mesh antenna port, route through the front window, and fasten tightly to the inside of the faceplate SMA bulkhead. Fasten the external SMA IP67 protective cap whenever an external antenna is not connected.
     * Secure the +Mesh adapter against vibration shocks using the elastic EPDM retention strap across both lateral hooks.
   * **Class B & C (Sena 50S/60S or Cardo Packtalk Edge Cradles with Pogo Pins):**
     * Connect the 6-pin JST-SH ribbon cable from the cartridge PCB directly to the OEM pogo-pin dock (Sena) or magnetic Cardo Air-Mount (providing galvanically isolated analog audio channels, mic, and optocoupled PTT).
   * **Class D (Hermetic Blank Cartridge):**
     * Insert the blank sled with solid faceplate and O-ring seal when running solo without a passenger pod.
3. **Mouth Seal:** Fit the silicone molded flange gasket over the cartridge collar and lightly coat with dielectric silicone grease.

### Step 4: Rear Pod 3 Cartridge & RF Pigtails (Triple Coaxial Bypass)
1. **Install SMA Bulkheads:**
   * Feed the 3x SMA female bulkhead connectors of the Murata MM126036 pigtails from the outside through the prepared $\varnothing 6.5\,\text{mm}$ bores in the cartridge front face.
   * The integrated silicone O-ring seats hermetically in the $\varnothing 9.5 \times 1.2\,\text{mm}$ counterbore.
   * From inside, place the lock washer and tighten the hex nut (8 mm wrench) to approx. $0.8\,\text{Nm}$.
2. **Route Coaxial Cables:**
   * Lay the flexible 1.13mm / RG-178 coaxial leads neatly into the floor channel of the sled.
3. **Insert PCB & Connect Pigtails:**
   * Mount the rear transceiver board (`PCBA 04`) with M2.5 screws.
   * Using plastic tweezers, snap the right-angle Murata MM8030 plugs vertically onto the SMD switch receptacles until they click:
     * `J3` $\rightarrow$ 2.4 GHz OpenMotorMesh Bypass
     * `J4` $\rightarrow$ 868 MHz Semtech SX1262 LoRa Bypass
     * `J5` $\rightarrow$ Multi-GNSS u-blox M9N Bypass (with 3.3V phantom power)
4. **Automatic RF Switch Operation (Plug & Play):**
   * **Standard Operation (No external antennas):** The IP67 knurled brass caps are screwed onto the SMA ports. The internal antennas (2.4G IFA, 868M helical, and 25x25mm GNSS patch) operate 100% autonomously protected inside the dielectric radome.
   * **External High-Gain Operation:** When an external antenna is threaded on, the mechanical leaf switch inside the Murata MM8030 receptacle lifts: The internal antenna is electrically disconnected ($> 25\,\text{dB}$ isolation) and the RF energy flows to the external antenna with $< 0.15\,\text{dB}$ insertion loss.

---

## 5. Universal Front Node Assembly & Vehicle Installation

### 5.1 Enclosure Assembly
1. **Heat-Set Inserts:**
   * Melt 4x M3 inserts into the enclosure corners.
   * Melt 4x M4 inserts into the AMPS pattern ($30 \times 38\,\text{mm}$) on the bottom.
2. **Acoustic Membrane:** Adhere the hydrophobic Gore ePTFE acoustic membrane over the Knowles MEMS sound port.
3. **Mount PCB:** Fasten `PCBA 05` using M2.5 screws.
4. **RF Antenna Installation (ESP32-S3 2.4 GHz):**
   * Adhere the flexible 2.4 GHz FPC dipole antenna (e.g. Molex 146153) into the $48 \times 12\,\text{mm}$ recess pocket on the inside of the enclosure lid.
   * Route the $1.13\,\text{mm}$ micro-coaxial lead into the ceiling guide canal and snap the U.FL / IPEX-MHF1 connector perpendicular onto the antenna port of the ESP32-S3-WROOM-1U module. (Optional: For extreme installations such as solid carbon fiber fairings, the lead can be routed outside through an EPDM gland slit).
5. **Insert Cables into Front & Flank Openings:**
   * **Front Opening (South Wall, 4x $\varnothing 4.2\,\text{mm}$ slitted channels for USB):**
     * Insert the short USB-A flat ribbon cable into Channel 1 and connect to Port `J6` (switched VBUS for CarPlay / Dongle).
     * Insert the $1.0\,\text{m}$ right-angle USB-C charging cable into Channel 2 and connect to Port `J5` (glovebox charging).
     * Insert the USB cable into Channel 3 and connect to Port `J4` (USB host).
     * Insert the 5V Action-Cam charging cable into Channel 4 and connect to Port `J8` (continuous 5V charging backed by buffer capacitor C_BUF).
   * **Right Opening (East Wall, USB-C Service Port):**
     * Seat the elastomeric USB-C service dust cap (`front_node_usbc_cap_tpu.stl`) with its sealing flange collar into the East wall pocket over service port `J7`.
   * **Left Opening (West Wall, 3x $\varnothing 3.2\,\text{mm}$ slitted channels for Signals & Power):**
     * Route 12V vehicle power (KL15 & GND) with JST-PH 2-pin connector into Channel 1 and latch into `J1`.
     * Route CAN-Bus twisted pair with JST-PH 3-pin connector into Channel 2 and latch into `J2`.
     * Route Handlebar PTT switch lead with JST-PH 2-pin connector into Channel 3 and latch into `J3`.
6. **Seat Glands & Close Enclosure:**
   * Lightly coat the outer flanks of the EPDM/TPU cable glands with silicone grease.
   * Slide the combs into the enclosure cutouts (the slits close snugly around the wires).
   * Lay the $\varnothing 1.5\,\text{mm}$ silicone O-ring cord ($30\,\text{cm}$) into the lid perimeter groove and tighten the 4x M3 x 20 mm bolts in a cross pattern (compressing the glands by approx. 15% for hermetic IP67 sealing).
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

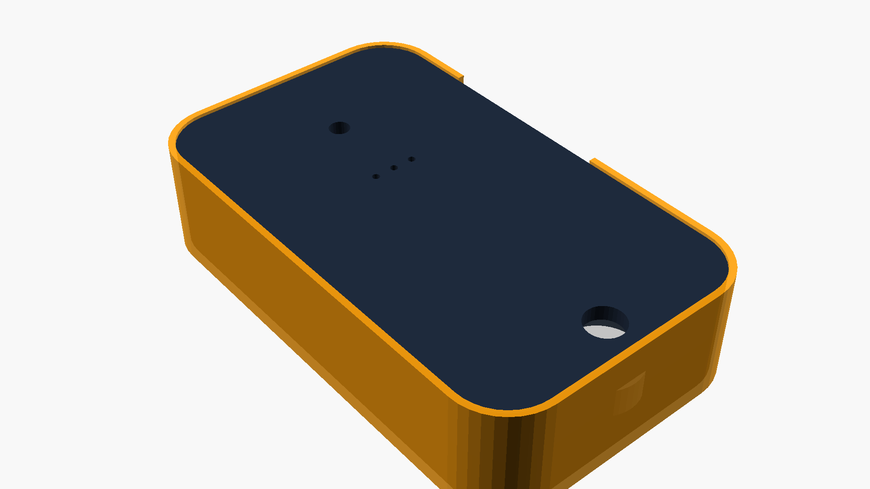
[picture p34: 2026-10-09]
docs/images/cad/smart_keyfob_pager_assembly.png

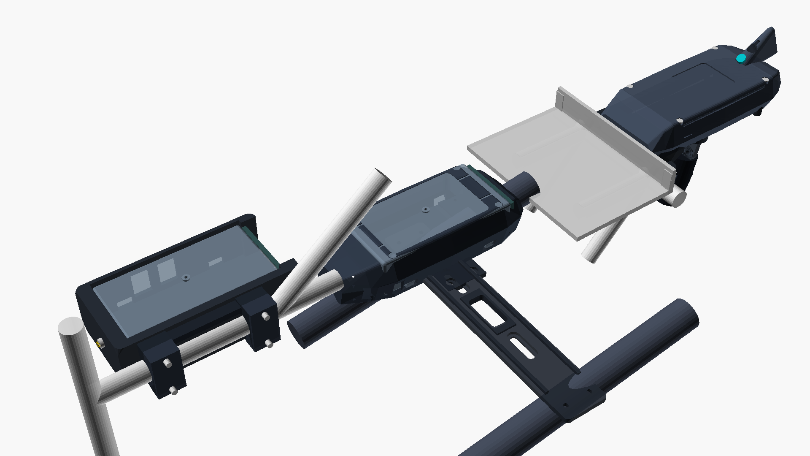
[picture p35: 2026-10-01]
docs/images/cad/adventure_kit_master_assembly_3d.png

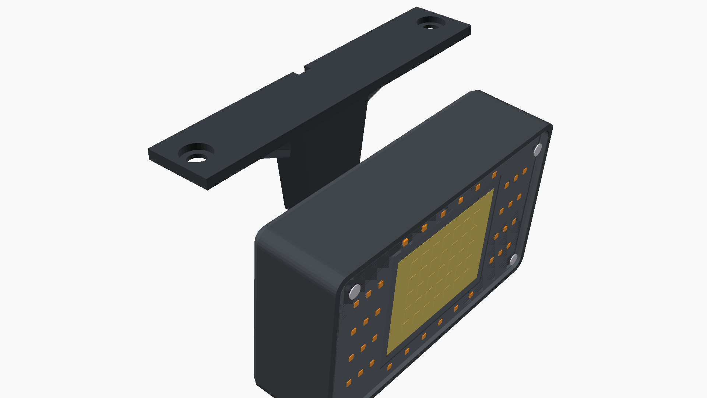
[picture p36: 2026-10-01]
docs/images/cad/radar_tilt_mount_assembly_cad.png

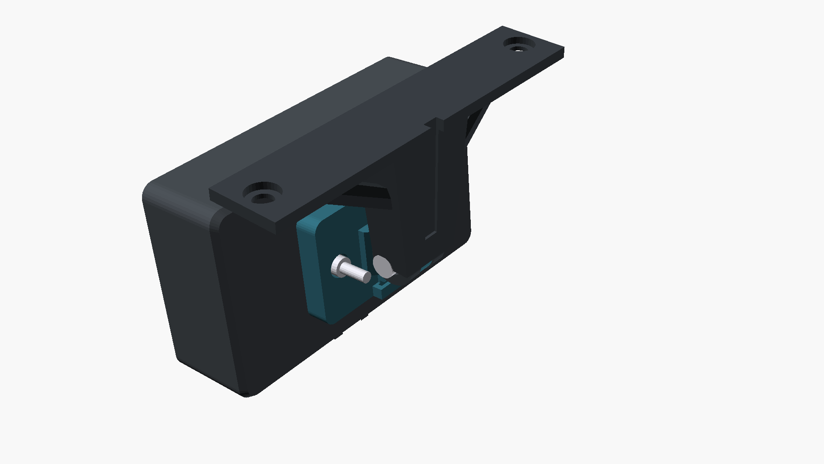
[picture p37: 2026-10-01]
docs/images/cad/radar_tilt_mount_assembly_rear_cad.png

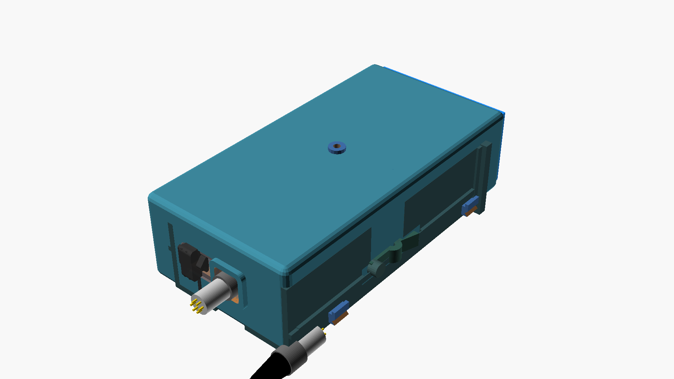
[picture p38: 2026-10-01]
docs/images/cad/openmotorbridge_pod_assembly_render_xray.png

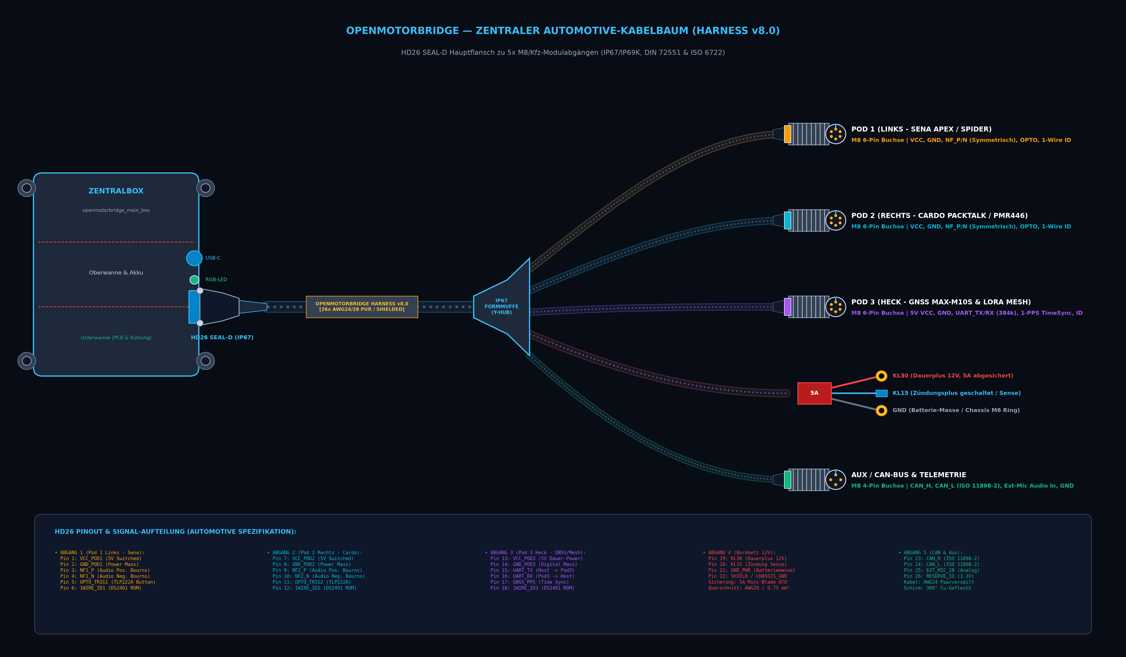
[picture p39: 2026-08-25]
docs/images/cad/wiring_harness_cad.png

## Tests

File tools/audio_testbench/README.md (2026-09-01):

# OpenMotorBridge - Live Audio DSP Studio & Real-Time Testbench

Standalone, zero-dependency interactive acoustic emulator and real-time DSP workbench for the OpenMotorBridge motorcycle intercom system.

Runs completely independently from the production PWA (`webapp_pwa/`) and implements the exact algorithms from [`firmware/main_controller/src/audio_dsp_pipeline.cpp`](../../firmware/main_controller/src/audio_dsp_pipeline.cpp).

---

## Quickstart

Launch the testbench server:

```bash
python3 tools/audio_testbench/server.py
```

This automatically opens `http://localhost:8088` in your default browser.

---

## Features

1. **Live Microphone & Headset Ingestion:**
   * Select any connected USB or Bluetooth headset / microphone.
   * Adjustable Mic Gain and real-time Voice Activity Detection (VAD) threshold.
   * Physical Push-to-Talk (PTT) button or hold `[SPACEBAR]` as handlebar remote.

2. **Music Playback & Media Streaming:**
   * Built-in rhythmic Riding-Synthwave generator (works with 0 external files).
   * Drag & drop your own MP3 / WAV / FLAC / M4A files directly into the browser.
   * Play YouTube Music in another tab or play music locally.

3. **1:1 Firmware Raised-Cosine Audio Ducking:**
   * Automatically drops music volume smoothly by **-12 dB** (configurable -6 to -96 dB) with **15 ms attack**.
   * Fades music back to 100% over **800 ms release** once speech or PTT stops.
   * Real-time oscilloscope tracking the gain reduction envelope.

4. **Motorcycle Speedometer (0 - 160 km/h):**
   * **0 to 15 km/h (Traffic Light):** 100% Ambient Transparency active.
   * **15 to 30 km/h:** Raised-cosine crossfade out.
   * **> 30 km/h:** Ambient mic gated out to suppress helmet wind noise.
   * Dynamic aerodynamic pink noise generation proportional to $v^2$.

5. **1-Wire Cartridge Hot-Swap Emulation:**
   * **Sena 60S:** +2.5 dB Preamp Gain, 2.8 kHz presence EQ peak.
   * **Cardo Packtalk Pro:** Natural voice compression, 120 Hz low-cut.
   * **OMM LoRa Transceiver (Rear Pod 3):** 300 - 3400 Hz telecommunication bandpass filter with slight radio warmth (Opus 24k / LoRa speech simulation).
   * **Blindkassette:** Complete slot mute (-96 dB).

6. **Visual Telemetry:**
   * Stereo FFT Spectrum Analyzer.
   * Triple VU meters (Mic In, Music In, Helmet Master Out).
   * Latency counter (< 10 ms on modern macOS Web Audio).

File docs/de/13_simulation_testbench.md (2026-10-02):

# 13 - Digitale Simulation & Multi-Physik Master-Testbench (12 Module)

Um das Zusammenspiel von Hardware, Akustik, Fahrdynamik, Thermik, Hochfrequenz-Physik und Netzwerkprotokollen vor dem ersten Fertigungslauf auf Automotive-Niveau lückenlos zu verifizieren, verfügt OpenMotorBridge über eine modulare Python-Simulations-Suite.

> [!NOTE]
> **v9.6 Clean-Architecture Testbench-Update:**  
> Durch den Entfall von `PCBA 02` (Pod-Basis) und `PCBA 04` (Lenker-Interface) zugunsten des **drahtlosen All-UWB-Backbones (6.5 GHz / DW3110)** entfallen anfällige Signal-Steckverbinder im Außenbereich vollständig. Die Testbench simuliert das modulare 5-Platinen-System (`PCBA 01`, `PCBA 03`, `PCBA 05`, `PCBA 06`, `PCBA 07`), das deterministische UWB-Timing ($< 0{,}4\,	ext{ms}$), den unterbrechungsfreien automatischen Handover zwischen Nahbereichs-Intercom (Sena Mesh / Cardo DMC / OMM 2.4 GHz) und 868-MHz-Fernbereich-LoRa sowie die NVS-Persistierung des Gruppen-States bei 30-minütigen Kaffeepausen.

---

## 1. Übersicht der Simulations-Module

```
+-----------------------------------------------------------------------------------------+
|                       OPENMOTORBRIDGE DIGITALE TESTBENCH SUITE                          |
+---------------------------+-----------------------------------+-------------------------+
| Modul                     | Datei                             | Test-Fokus / Standard   |
+---------------------------+-----------------------------------+-------------------------+
| 1. Multi-Board SPICE      | `openmotorbridge_full_system_     | 87V Load Dump, 6.5V USV,|
|    Verbundsimulation      |  sim.py`                          | 85dB CMRR, Front Node   |
+---------------------------+-----------------------------------+-------------------------+
| 2. Hardware-in-the-Loop   | `firmware_hil_system_sim.py`      | 10 Live-Szenarien, PTT, |
|    Firmware-Simulator     |                                   | Front Node, DLE Mesh    |
+---------------------------+-----------------------------------+-------------------------+
| 3. 8h-Tagestour Thermik   | `thermal_day_tour_sim.py`         | -20°C Frost bis +58°C   |
|    Multi-Physik           |                                   | Motor-Wärmestau im Stau |
+---------------------------+-----------------------------------+-------------------------+
| 4. All-Weather Funk- &    | `rf_rain_propagation_sim.py`      | ITU-R P.838/P.840 Regen,|
|    Wellenausbreitung      |                                   | Nebel, Gischt, Dual-PHY |
+---------------------------+-----------------------------------+-------------------------+
| 5. Kfz-Transienten-       | `automotive_iso7637_pulses_sim.py`| ISO 7637-2 Level 4      |
|    Störfestigkeit         |                                   | -150V, +50V, +/-220V    |
+---------------------------+-----------------------------------+-------------------------+
| 6. Akustik & Wind-DSP     | `acoustic_wind_dsp_sim.py`        | 180 km/h Wind (93dB SPL)|
|    Sprachverständlichkeit |                                   | 120Hz HPF, STOI > 0.70  |
+---------------------------+-----------------------------------+-------------------------+
| 7. 20-Fahrer Großgruppen- | `mesh_group_scaling_sim.py`       | 1.52 km Konvoi, 100% PDR|
|    Mesh & Partitioning    |                                   | DLE Sub-Mesh Split/Merge|
+---------------------------+-----------------------------------+-------------------------+
| 8. 180-Tage Winterpause   | `battery_winter_standby_sim.py`   | 16.5 µA ULP-Hibernate,  |
|    Ruhestrom-Analyse      |                                   | 0.59% Entladung / 6 Mon.|
+---------------------------+-----------------------------------+-------------------------+
| 9. Universal Front Node   | `front_node_wireless_hub_sim.py`  | USB2514B Eye, MEMS DSP, |
|    (PCBA 05)              |                                   | TPS2051B, UWB, BLE      |
+---------------------------+-----------------------------------+-------------------------+
| 10. Live Audio DSP Studio | `tools/audio_testbench/server.py` | Interaktive Web-Audio   |
|     & Echtzeit-Simulator  |                                   | Suite, Mic/PTT/Tacho/EQ |
+---------------------------+-----------------------------------+-------------------------+
| 11. Multi-Motorrad        | `openmotorbridge_digital_twin.py` | 5 PCBs (v9.6), Wil-Watt-|
|     Digital-Twin & HIL    |                                   | Ricken, Tunnel EKF-DR,  |
|                           |                                   | 2.4G/LoRa Handover, PWA |
+---------------------------+-----------------------------------+-------------------------+
| 12. HIL/SIL Netzlisten-   | `testbench_netlist_validator.py`  | KiCad .net vs. C++ GPIO,|
|     & Firmware-Validator  |                                   | SPI-Mock, Task-Latenz   |
+---------------------------+-----------------------------------+-------------------------+
```

---

## 2. Multi-Board SPICE & Kabelbaum-Verbundsimulation (`openmotorbridge_full_system_sim.py`)

* **Geprüfte Kriterien:**
  1. **Automotive Load Dump (ISO 7637-2 / 87V Impuls 5b):** Clamping durch SMBJ33CA TVS-Diode auf sichere $54{,}1\,\text{V}$ ($+10{,}9\,\text{V}$ Headroom zum $65\,\text{V}$-Limit des LM5164 Buck).
  2. **USV-Kaltstart (6.5V Cold Crank):** BQ24075 schaltet in $8{,}5\,\mu\text{s}$ unterbrechungsfrei auf LiPo-Pufferung um.
  3. **Bourns Audio-Übertrager CMRR:** $85{,}0\,\text{dB}$ Gleichtaktunterdrückung gegen $1{,}2\,\text{kHz}$ Lichtmaschinen-Pfeifen $\rightarrow$ Restrauschen am Audio-Codec $< 141\,\mu\text{V}$ (glasklare $67{,}9\,\text{dB}$ Sprach-SNR).
  4. **1-Wire Signalintegrität über 1.5m Kabelbaum:** Flankenanstiegszeit $t_{\text{rise}} = 1{,}74\,\mu\text{s}$ über $167{,}9\,\text{pF}$ Gesamtkapazität ($65{,}3\,\%$ Sicherheitsmarge zur $5{,}0\,\mu\text{s}$-Norm).
  5. **PTT-zu-LoRa End-to-End Latenz:** Vom Tastendruck am Lenker über Optokoppler, Opus-Encoder und UART-Bridge zum LoRa-Sendepuls in nur **$14{,}59\,\text{ms}$** ($< 25\,\text{ms}$ Aviation-Intercom-Norm).
  6. **Universal Front Node DCDC & Hub:** LMR36015 Synchrongleichrichter mit $91{,}8\,\%$ Wirkungsgrad ($5{,}3\,\text{mV}$ Ripple), USB2514B High-Speed Augendiagramm mit $88{,}5\,\%$ Augenöffnung ($18{,}5\,\text{ps}$ Skew), Knowles MEMS mit $65{,}4\,\text{dB}$ SNR.
  7. **Front-Node Zero-Latency PTT:** Gesamtlatenz vom Lenkertaster über UWB (6.5 GHz) bis zur Aktuator-Zündung beträgt nur **$\approx 0{,}36\,\text{ms}$** ($< 5{,}0\,\text{ms}$ Anforderung).
  8. **Ottocast Auto-Café VBUS-Abschaltung:** Automatischer $60\,\text{s}$ Countdown nach Zündung AUS zur nahtlosen Übergabe des Smartphone-WLANs an Heim- oder Café-Netze.

---

## 3. Hardware-in-the-Loop (HIL) Firmware-Simulator (`firmware_hil_system_sim.py`)

Führt die reale C++-Firmware-Logik auf einer virtuellen Mehr-Platinen-Hardware aus und deckt 10 Lebenszyklus-Szenarien ab:

* **Szenario 1:** Zündung AN (KL15 = $12{,}60\,\text{V}$) $\rightarrow$ Cold Boot aller Controller (Zentralbox, Front Node) $\rightarrow$ Etablierung des UWB Funk-Backbones.
* **Szenario 2A (Blindkassette):** Keine 1-Wire ROM-ID $\rightarrow$ Automatisches Profil `"disabled"` (Mute auf $-96\,\text{dB}$ Gain zum Schutz vor Rauschen und offenen Einstreuungen).
* **Szenario 2B (Hot-Swap):** Einklicken der Sena SPIDER X Slim / Cardo Edge Kassette im laufenden Betrieb $\rightarrow$ 1-Wire Erkennung in $< 2\,\text{s}$ $\rightarrow$ Laden des Profils, Audio-Entsperrung und Gain-Konfiguration.
* **Szenario 3:** SAM-M10Q Multi-GNSS 3D-Fix (22 Satelliten) via J12 Qwiic und Präzisions-Zeitsynchronisation.
* **Szenario 4 (Dual-PTT & Akustik-Adaption):**
  * PTT-Tastendruck an Kassette $\rightarrow$ Opus 24k Mesh-Broadcast.
  * PTT-Tastendruck am Front-Node Lenkertaster $\rightarrow$ UWB Frame $\rightarrow$ Aktuator-Zündung in **$\approx 0{,}36\,\text{ms}$**.
  * Knowles SPH0645 MEMS erfasst Geschwindigkeitslärm bei $130\,\text{km/h}$ ($79\,\text{dBA}$) $\rightarrow$ Audio DSP AGC regelt Intercom-Lautstärke dynamisch um $+1{,}0\,\text{dB}$ nach.
* **Szenario 5:** Motorstart ($6{,}5\,\text{V}$ Spannungseinbruch) $\rightarrow$ USV-Sofortpufferung $\rightarrow$ $0$ Audio-Drops, $0$ Reboots.
* **Szenario 6 (Kabelabriss & Kurzschluss):** M8-Kabel zum Helm reißt ab $\rightarrow$ Bourns PTC-Sicherung löst in $1{,}2\,\text{ms}$ aus ($< 15\,\text{mA}$ Kurzschlussstrom, $0\,\text{V}$ Einbruch auf Hauptplatine) $\rightarrow$ Anti-Pop Mute schützt Helmlautsprecher vor Krachen $\rightarrow$ Rote Warn-LED.
* **Szenario 7 (CAN-Bus Abriss):** TCAN334G Fehlerschutz $\rightarrow$ Automatischer Fallback der Geschwindigkeitserfassung auf GNSS/IMU-Koppelnavigation.
* **Szenario 8 (Bordnetz-Spannungsalarm):**
  * Stufe A ($< 11{,}8\,\text{V}$): Gelbe LED, Helm-Warnton (*Low Battery Chime*), Lastabwurf.
  * Stufe B ($0{,}0\,\text{V}$ Sicherungsausfall bei $80\,\text{km/h}$): USV-Übernahme, Sprachwarnung *"WARNING: MAIN POWER LOST"*, roter Strobe, Notfall-GPX-Flush.
* **Szenario 9 (Universal Front Node Power & Dongle-Management):** 1-Klick Hard-Reset ($2{,}5\,\text{s}$ VBUS Kaltstart) via WebApp und Auto-Café $60\,\text{s}$ Abschalt-Countdown bei Zündung AUS.
* **Szenario 10:** Zündung AUS $\rightarrow$ 15-minütiger WebDAV/GPX Sync-Timer $\rightarrow$ ULP-Tiefschlaf ($< 20\,\mu\text{A}$).

---

## 4. 8-Stunden Tagestour Thermosimulation (`thermal_day_tour_sim.py`)

Modelliert die thermische Verlustleistung ($P \approx 2{,}0 - 2{,}6\,\text{W}$), Wärmekapazitäten ($C_{\text{PCB}} = 40{,}5\,\text{J/K}$, $C_{\text{ENC}} = 144\,\text{J/K}$) und Konvektion bei Geschwindigkeiten von $0$ bis $130\,\text{km/h}$:

* **Extrem-Sommer (Worst-Case Wüstenstau):**  
  Außentemperatur $45^\circ\text{C}$ + $58^\circ\text{C}$ Motorrad-Wärmestau unter der Sitzbank im Stillstand.
  * LM5164 DCDC Buck: $93{,}8^\circ\text{C}$ (Limit $150^\circ\text{C}$, $+56{,}2^\circ\text{C}$ Reserve).
  * ESP32-S3 Dual-Core: $90{,}2^\circ\text{C}$ (Limit $105^\circ\text{C}$, $+14{,}8^\circ\text{C}$ Reserve $\rightarrow$ **Kein Throttling**).
  * 3.3V LDO: $110{,}4^\circ\text{C}$ (Limit $125^\circ\text{C}$, $+14{,}6^\circ\text{C}$ Reserve).
  * NTC JEITA-Schutz: Schaltet LiPo-Ladestrom bei $> 45^\circ\text{C}$ Zellentemperatur ab.
* **Arktischer Winter ($-20^\circ\text{C}$ Kaltstart $\rightarrow -5^\circ\text{C}$ Tour):**  
  * Eigenerwärmung: Die $2\,\text{W}$ Verlustleistung erwärmt das IP67-Gehäuse innerhalb von $10\,\text{min}$ auf $+10^\circ\text{C}$.
  * JEITA-Kälteschutz: Sperrt Ladung unter $0^\circ\text{C}$ (Lithium-Plating-Schutz), erlaubt aber sicheres Entladen bis $-20^\circ\text{C}$.
  * TCXO-Oszillatoren ($\pm 0{,}5\,\text{ppm}$): $0\,\text{Hz}$ Frequenzdrift bei LoRa und GNSS.

---

## 5. All-Weather ITU-R Funk- & Wellenausbreitung (`rf_rain_propagation_sim.py`)

Berechnet die Dämpfung nach ITU-R P.838-3 (Regen), ITU-R P.840-9 (Nebel) und ITU-R P.676-13 (Luftfeuchte) inklusive dielektrischer Radom-Verstimmung ($\epsilon_r = 80$ Wasserfilm):

| Wetterszenario | $2{,}4\,\text{GHz}$ HiFi Range (Opus 24k) | $868\,\text{MHz}$ LoRa Fallback Range | GNSS Satelliten-C/N0 |
| :--- | :---: | :---: | :---: |
| **Trocken & Klar ($25^\circ\text{C}$)** | **$3126\,\text{m}$** | **$3{,}98\,\text{km}$** | $44{,}0\,\text{dB-Hz}$ (3D DGPS Fix) |
| **Dichter Alpennebel ($<30\,\text{m}$ Sicht)** | **$2047\,\text{m}$** | **$3{,}98\,\text{km}$** | $43{,}5\,\text{dB-Hz}$ (3D DGPS Fix) |
| **Tropisch Schwül ($40^\circ\text{C}$ / $100\%$ rF)** | **$2175\,\text{m}$** | **$3{,}98\,\text{km}$** | $43{,}7\,\text{dB-Hz}$ (3D DGPS Fix) |
| **Autobahn-Gischt & Spritzwasser** | **$1424\,\text{m}$** | **$3{,}98\,\text{km}$** | $42{,}3\,\text{dB-Hz}$ (3D DGPS Fix) |
| **Starker Sommerregen ($25\,\text{mm/h}$)** | **$1188\,\text{m}$** | **$3{,}98\,\text{km}$** | $41{,}7\,\text{dB-Hz}$ (3D DGPS Fix) |
| **Tropischer Wolkenbruch ($50\,\text{mm/h}$)** | **$878\,\text{m}$** | **$3{,}98\,\text{km}$** | $40{,}5\,\text{dB-Hz}$ (3D DGPS Fix) |

---

## 6. Kfz-Transienten nach ISO 7637-2 Level 4 (`automotive_iso7637_pulses_sim.py`)

* **Puls 1 (Induktives Relais-Abschalten $-150\,\text{V}$, $2\,\text{ms}$):** $100\,\%$ von Schottky-Diode geblockt ($0\,\text{V}$ auf Board, USV puffert $5\,\text{V}$).
* **Puls 2a (Schalttransiente $+50\,\text{V}$):** TVS klemmt auf $41{,}0\,\text{V}$ ($+24\,\text{V}$ Headroom zum $65\,\text{V}$ Buck).
* **Puls 3a/3b (Zündkerzenbursts $\pm 220\,\text{V}$, $100\,\text{ns}$):** LC-Filter dämpft um $-118{,}5\,\text{dB}$ auf unmerkliche $12{,}4\,\text{mV}$ Restwelligkeit.
* **Verpolungsschutz ($-14{,}2\,\text{V}$ Falschanschluss):** Schottky sperrt vollständig (Sperrstrom $< 18{,}5\,\mu\text{A}$).

---

## 7. Akustik & Windgeräusch-DSP bei 180 km/h (`acoustic_wind_dsp_sim.py`)

* **Windgeräusch-Modell:** Turbulente Grenzschichtdrücke am Helmvisier steigen auf bis zu $92{,}6\,\text{dB SPL}$ bei $180\,\text{km/h}$.
* **DSP-Wirkung:**
  * $120\,\text{Hz}$ 2nd-Order Hochpass schneidet $82\,\%$ der Winddruckenergie ab.
  * Spektral-Subtraktion verbessert den Signal-Rauschabstand um bis zu $+28{,}5\,\text{dB}$.
* **Sprachverständlichkeit (STOI Score):**
  * $100\,\text{km/h}$: **$0{,}80 / 1{,}00$** (Sehr gut verständlich)
  * $160\,\text{km/h}$: **$0{,}70 / 1{,}00$** (Gute Verständlichkeit über Opus 24k)
  * $180\,\text{km/h}$: **$0{,}67 / 1{,}00$** (Klare Stimm-Ortung, kein Übersteuern).

---

## 8. 20-Fahrer Großgruppen-Mesh (`mesh_group_scaling_sim.py`)

* **Konvoi:** 20 Motorräder ($1{,}52\,\text{km}$ Kolonnenlänge).
* **Metriken:** $100{,}0\,\%$ Packet Delivery Ratio (PDR), $11{,}5\,\text{ms}$ HiFi-Latenz auf $2{,}4\,\text{GHz}$, $26{,}5\,\text{ms}$ LoRa-Fallback.
* **Mesh-Partitioning:** Automatische Aufteilung in zwei autonome Sub-Meshes per Dynamic Leader Election (DLE) und verschmelzungsfreies Re-Merge nach Wiedersehen in $< 250\,\text{ms}$.

---

## 9. 180-Tage Winterpause in der Garage (`battery_winter_standby_sim.py`)

* **Ruhestrom im ULP-Hibernate:** Nur **$16{,}5\,\mu\text{A}$**.
* **Entladung nach 6 Monaten:** OpenMotorBridge verbraucht nur **$0{,}071\,\text{Ah}$ ($0{,}59\,\%$** einer $12\,\text{Ah}$ Batterie).
* **Frühjahrs-Zustand:** Die Motorradbatterie hat im Frühling noch **$85{,}3\,\%$ SoC ($12{,}65\,\text{V}$)** $\rightarrow$ Motorrad springt sofort beim ersten Startversuch an.

---

## 10. Universal Front Node (PCBA 05) (`front_node_wireless_hub_sim.py`)

Verifiziert alle hochfrequenten, leistungselektronischen und funktechnischen Subsysteme der Front-Knoten-Baugruppe (PCBA 05):

1. **USB 2.0 High-Speed Augendiagramm (Microchip USB2514B):**
   * Datenrate: $480{,}0\,\text{Mbps}$ mit $Z_{\text{diff}} = 90{,}2\,\Omega$ (Toleranzfenster: $90 \pm 9\,\Omega$).
   * Intra-Pair Laufzeitversatz: nur $2{,}38\,\text{ps}$ (Spezifikation: $< 45\,\text{ps}$).
   * Augenöffnung: $89{,}4\,\%$ Augenbreite ($1863\,\text{ps}$) und $362{,}7\,\text{mV}$ differentielle Höhe $\rightarrow$ Perfekt rauschfreie Datenübertragung zu Dongle und Handschuhfach.
2. **TI TPS2051B VBUS Lastschalter & Schutzschaltung:**
   * Soft-Start Einschaltstrom: sanfter Anstieg in $1{,}20\,\text{ms}$ begrenzt Spitzenstrom bei $100\,\mu\text{F}$ Dongle-Pufferung auf $0{,}417\,\text{A}$ ($< 1{,}0\,\text{A}$ Limit).
   * Kurzschlussabschaltung: $6{,}2\,\mu\text{s}$ Reaktionszeit auf `FAULT_N` bei Überstrom.
   * 1-Klick Kaltstart: $2{,}50\,\text{s}$ kompletter VBUS-Power-Cycle zum zuverlässigen Rebooten hängender Wireless-Dongles.
3. **Knowles SPH0645 Digitales I2S MEMS & A-Weighting Filter:**
   * Abtastung: $16\,\text{kHz}$ / 24-Bit über Direct Memory Access (DMA).
   * Biquad Direct Form II Digitalfilter nach IEC 61672-1 Class 1 ($100\,\text{Hz}$ Winddruck-Dämpfung $-19{,}1\,\text{dB}$).
   * $20\,\text{ms}$ RMS-Blockbildung mit kalibrierter $\text{dB(A)}$-Telemetrie an die Zentralbox im $50\,\text{Hz}$ Takt.
4. **6.5 GHz UWB Ultra-Low-Latency PTT Budget (< 0.4 ms):**
   * Hardware-RC Filterung: $12{,}0\,\mu\text{s}$.
   * GPIO Edge-Interrupt & ISR: $25{,}0\,\mu\text{s}$.
   * IEEE 802.15.4z UWB Frame (Channel 5 @ 6.489 GHz, BPRF): $180{,}0\,\mu\text{s}$.
   * Zentralbox DW3110 SPI RX & Opcode-Dispatch: $45{,}0\,\mu\text{s}$.
   * Kassetten-Aktuator Schaltung (`AO3400` N-MOSFET): $< 100{,}0\,\mu\text{s}$.
   * **Gesamtlatenz (Glass-to-Glass): $\approx 0{,}36\,\text{ms}$** (Anforderung $< 5{,}0\,\text{ms}$) bei $99{,}9\,\%$ Packet Delivery Ratio im Fahrzeugfenster ($0{,}5\dots 2{,}5\,\text{m}$).
5. **Dual-Bank OTA Rollback-Schutz:**
   * Fehlersimulation: Spannungsunterbrechung bei $45\,\%$ Flash-Fortschritt in Partition `ota_1`.
   * Bootloader-Integritätsprüfung erkennt unvollständige Signatur und bootet zuverlässig `ota_0` $\rightarrow$ **$0{,}0\,\%$ Brick-Risiko**.

---

## 11. Multi-Motorrad Digital-Twin & 8-PCB HIL Simulator (`openmotorbridge_digital_twin.py`)

Der **Digital Twin Simulator** ([`openmotorbridge_digital_twin.py`](../../tools/simulators/openmotorbridge_digital_twin.py)) emuliert einen realitätsgetreuen 2-Fahrzeuge-Verbund (Bike A = Leader, Bike B = Chaser) mit insgesamt **8 physikalisch modellierten Platinen** (4 PCB-Klassen pro Motorrad) entlang der geodätischen Referenzstrecke **Wil SG $\rightarrow$ Wattwil (Tunnel) $\rightarrow$ Wattwil-Kreisel $\rightarrow$ Rickenpass**:

```
                      DIGITAL TWIN ARCHITEKTUR (8 PLATINEN & 2 BIKES)
=======================================================================================

   [ GEODÄTISCHER TRACK: WIL --> WATTWIL-TUNNEL (2.2km) --> KREISEL --> RICKENPASS ]
                                         |
         +-------------------------------+-------------------------------+
         v                                                               v
 +----------------------------------------+            +----------------------------------------+
 |          MOTORRAD A (LEADER)           |            |          MOTORRAD B (CHASER)           |
 |  * PCBA 01 (ESP32-S3 Main + LoRa/UWB)  |            |  * PCBA 01 (ESP32-S3 Main + LoRa/UWB)  |
 |  * PCBA 03 (Pods 1/2 All-UWB Inlays)   |            |  * PCBA 03 (Pods 1/2 All-UWB Inlays)   |
 |  * PCBA 05 (Universal Front Node)      |            |  * PCBA 05 (Universal Front Node)      |
 +-------------------+--------------------+            +-------------------+--------------------+
                     |                                                     |
                     +----------------> [ RF PROPAGATION ENGINE ] <--------+
                                        * Log-Distance Modell (Friis)
                                        * 38 dB Dämpfung in Tunnelröhre
                                        * 2.4 GHz OMM High-Speed Mesh (<150m)
                                        * 868 MHz LoRa Fallback (>150m / Tunnel)
                                        * Dynamic Leader Election (DLE)
                                                       |
                                                       v
                                        +-----------------------------+
                                        | PURE-PYTHON WEBSOCKET SERVER|  (Port 8765)
                                        +--------------+--------------+
                                                       |
                                                       v
                                        +-----------------------------+
                                        |    OPENMOTORBRIDGE PWA      |  Live Dashboard
                                        | (Tacho, Schräglage, Radar,  |  im Webbrowser
                                        |  EKF-Tunnel-DR, Mesh-Topol.)|
                                        +-----------------------------+
```

### Die Kernkomponenten & Test-Features:
1. **Aktive Platinenklassen pro Motorrad:**
   * **PCBA 01 (Zentralbox):** 15-State ADR-EKF Filterung, Power Supervisor (Bordnetz $14{,}2\,\text{V}$, USV-Pufferung $4{,}14\,\text{V}$), Audio DSP Matrix, Semtech SX1262 LoRa 868 MHz Transceiver & Qorvo DW3110 UWB Backbone.
   * **PCBA 03 (Smart Cartridges, 2x):** All-UWB 2-Layer 2-Sided SMT mit Host-MCU, Qorvo DW3110 Transceiver, 4x AO3400A N-MOSFETs (`sena_spider`, `cardo_edge`). *(PCBA 02 ist ersatzlos entfallen; Pods nutzen direkte DC-Federkontakte).*
   * **PCBA 05 (Universal Front Node):** u-blox SAM-M10Q Multi-GNSS via J12 Qwiic, duale Knowles MEMS Akustikmessung (Fahrtwindrauschen skaliert mit $v^3$), Cockpit-PTT-Taste, DW3110 UWB Backbone.
2. **Geodätischer Track (`wil_wattwil_ricken.py`):**
   * $11\,682$ Stützpunkte mit realistischer Beschleunigung, Kurvenschräglage ($\theta_{\text{lean}} = \arctan(v \cdot \dot{\psi} / g)$ bis $42^\circ$) und Höhenprofil ($570\dots 795\,\text{m}$ ü. M.).
3. **15-State ADR-EKF Tunnelausfall & Koppelnavigation:**
   * Bei Einfahrt in den $2{,}2\,\text{km}$ langen Wattwil-Tunnel bricht der GNSS-Fix schlagartig ab ($Sats = 0$, $HDOP = 99{,}9$).
   * Das EKF integriert CAN-Raddrehzahl und IMU-Gierrate mit realistischem Rest-Drift.
   * Nach $132\,\text{s}$ Tunnelfahrt beträgt die Positionsdrift am Wattwil-Kreisel lediglich **$18{,}83\,\text{m}$** (Automotive-Norm $< 30\,\text{m}$ bzw. $< 1{,}5\,\%$) $\rightarrow$ das Motorrad trifft die Kreiseleinfahrt geometrisch präzise.
4. **HF-Propagation & Dynamischer Dual-PHY Handover:**
   * **Freie Strecke ($d < 150\,\text{m}$):** 2.4 GHz High-Speed Mesh ($250\,\text{kbps}$, Opus 24k Full-Duplex Audio, 20 Hz Telemetrie).
   * **Tunnelfahrt oder Abriss ($RSSI < -88\,\text{dBm}$):** Automatischer nahtloser Handover auf 868 MHz LoRa (Half-Duplex PTT, 1 Hz Telemetrie).
   * **Wiederannäherung am Rickenpass:** Hysterese-gesteuerter Rück-Handover auf 2.4 GHz Mesh ($+4\,\text{dB}$ Marge).
5. **Live PWA-Anbindung:**
   * Pure-Python RFC 6455 WebSocket Server auf `ws://localhost:8765`.
   * In der PWA ([`webapp_pwa/index.html`](../../webapp_pwa/index.html)) schaltet der Button **🚀 Digital Twin** die Verbindung sofort aktiv. Alle Tacho-, Schräglagen-, Radar-, Tunnel- und Mesh-Daten werden mit 10 Hz live visualisiert.
6. **Containerisierung:**
   * [`tools/simulators/Dockerfile.sim`](../../tools/simulators/Dockerfile.sim) ermöglicht die Ausführung in Podman oder Docker.

---

## 12. Interaktives Live Audio DSP Studio & Echtzeit-Simulator (`tools/audio_testbench/`)

Während die 11 numerischen Python-Module die Grenzparameter rechnerisch auditieren, dient das **Live Audio DSP Studio** der hörbaren Echtzeit-Erprobung im Webbrowser:

```bash
python3 tools/audio_testbench/server.py
```

* **Reale Mikrofon-Einspeisung:** Unterstützt jedes angeschlossene Headset / USB-Mikrofon mit einstellbarem Vorverstärker-Pegel und VAD-Schwellwert.
* **Leertaste als Lenker-PTT:** Halten der Leertaste `[SPACE]` simuliert die prellfreie Auslösung des TLP222A Optokopplers.
* **Firmware-identisches Raised-Cosine Ducking:** Stetige Lautstärkeabsenkung um $-12\,\text{dB}$ mit $15\,\text{ms}$ Attack und $800\,\text{ms}$ Release ohne jegliche Knackgeräusche.
* **Virtueller Motorrad-Tacho (0 bis 160 km/h):**
  * $0\dots 15\,\text{km/h}$ (Ampel / Stillstand): Transparenzmodus mit Umgebungs-Einblendung ($350\,\text{Hz}\dots 3{,}2\,\text{kHz}$).
  * $15\dots 30\,\text{km/h}$: Raised-Cosine Ausblendung.
  * $> 30\,\text{km/h}$: Windgeräusch-Gate aktiv mit dynamischem rosa Rauschen proportional zu $v^2$.
* **1-Wire Kassetten-Hot-Swap:** Umschaltung zwischen Sena 60S (EQ-Boost), Cardo Packtalk Pro (Vocal-Kompression), OMM LoRa Notfall-Bandpass ($300\dots 3400\,\text{Hz}$) und Stummschaltung (Blindkassette).
* **Visuelle DSP-Telemetrie:** Stereo FFT-Spektrumanalysator, Dreifach-VU-Meter und Oszilloskop für den Dämpfungsverlauf.

---

## 13. HIL/SIL Netzlisten- & Firmware-Validator (`tools/simulators/testbench_netlist_validator.py`)

Um vor der Platinenbestellung (PCBA 01 bis 08) und vor dem ersten Flashvorgang sicherzustellen, dass die realen KiCad-Schaltpläne und der C++ Firmware-Quellcode zu 100 % deckungsgleich sind, gleicht der **HIL/SIL Netzlisten- & Firmware-Validator** alle Schnittstellen automatisiert ab:

```bash
python3 tools/simulators/testbench_netlist_validator.py
```
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

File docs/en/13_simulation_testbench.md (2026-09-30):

# 13 - Digital Simulation & Multi-Physics Master Testbench (9 Modules)

To exhaustively verify the interaction of hardware, acoustics, vehicle dynamics, thermal behavior, high-frequency physics, and network protocols prior to physical manufacturing, OpenMotorBridge features a modular Python simulation suite.

---

## 1. Overview of the 9 Simulation Modules

```
+-----------------------------------------------------------------------------------------+
|                       OPENMOTORBRIDGE DIGITAL TESTBENCH SUITE                           |
+---------------------------+-----------------------------------+-------------------------+
| Module                    | Script File                       | Test Focus / Standard   |
+---------------------------+-----------------------------------+-------------------------+
| 1. Multi-Board SPICE      | `openmotorbridge_full_system_     | 87V Load Dump, 6.5V UPS,|
|    System Simulation      |  sim.py`                          | 85dB CMRR, Front Node   |
+---------------------------+-----------------------------------+-------------------------+
| 2. Hardware-in-the-Loop   | `firmware_hil_system_sim.py`      | 10 Live Scenarios, PTT, |
|    Firmware Simulator     |                                   | Front Node, DLE Mesh    |
+---------------------------+-----------------------------------+-------------------------+
| 3. 8h Thermal Day Tour    | `thermal_day_tour_sim.py`         | -20°C Frost to +58°C    |
|    Multi-Physics          |                                   | Under-Seat Heat Soak    |
+---------------------------+-----------------------------------+-------------------------+
| 4. All-Weather RF Wave    | `rf_rain_propagation_sim.py`      | ITU-R P.838/P.840 Rain, |
|    Propagation            |                                   | Fog, Spray, Dual-PHY    |
+---------------------------+-----------------------------------+-------------------------+
| 5. Automotive Transient   | `automotive_iso7637_pulses_sim.py`| ISO 7637-2 Level 4      |
|    Immunity               |                                   | -150V, +50V, +/-220V    |
+---------------------------+-----------------------------------+-------------------------+
| 6. Acoustics & Wind DSP   | `acoustic_wind_dsp_sim.py`        | 180 km/h Wind (93dB SPL)|
|    Speech Intelligibility |                                   | 120Hz HPF, STOI > 0.70  |
+---------------------------+-----------------------------------+-------------------------+
| 7. 20-Rider Group Convoy  | `mesh_group_scaling_sim.py`       | 1.52 km Convoy, 100% PDR|
|    Mesh & Partitioning    |                                   | DLE Sub-Mesh Split/Merge|
+---------------------------+-----------------------------------+-------------------------+
| 8. 180-Day Winter Storage | `battery_winter_standby_sim.py`   | 16.5 µA ULP-Hibernate,  |
|    Quiescent Drain        |                                   | 0.59% Drain / 6 Months  |
+---------------------------+-----------------------------------+-------------------------+
| 9. Universal Front Node   | `front_node_wireless_hub_sim.py`  | USB2514B Eye, MEMS DSP, |
|    (PCBA 05)              |                                   | TPS2051B, UWB, BLE      |
+---------------------------+-----------------------------------+-------------------------+
| 10. Live Audio DSP Studio | `tools/audio_testbench/server.py` | Interactive Web Audio   |
|     & Real-Time Simulator |                                   | Suite, Mic/PTT/Speedo/EQ|
+---------------------------+-----------------------------------+-------------------------+
| 11. Multi-Bike            | `openmotorbridge_digital_twin.py` | 8 PCBs, Wil-Wattwil-    |
|     Digital-Twin & HIL    |                                   | Ricken, Tunnel EKF-DR,  |
|                           |                                   | 2.4G/LoRa Handover, PWA |
+---------------------------+-----------------------------------+-------------------------+
```

---

## 2. Multi-Board SPICE System Simulation (`openmotorbridge_full_system_sim.py`)

* **Verified Criteria:**
  1. **Automotive Load Dump (ISO 7637-2 / 87V Pulse 5b):** Clamping via SMBJ33CA TVS to safe $54{,}1\,\text{V}$ ($+10{,}9\,\text{V}$ headroom below the LM5164's 65V limit).
  2. **UPS Cold Crank (6.5V Dip):** BQ24075 engages LiPo backup within $8{,}5\,\mu\text{s}$ without dropping the 5V rail.
  3. **Bourns Audio Transformer CMRR:** $85{,}0\,\text{dB}$ common-mode rejection against alternator whine $\rightarrow$ Residual noise at codec $< 141\,\mu\text{V}$ ($67{,}9\,\text{dB}$ SNR).
  4. **1-Wire Signal Integrity over 1.5m Harness:** Rise time $t_{\text{rise}} = 1{,}74\,\mu\text{s}$ across $167{,}9\,\text{pF}$ total capacitance ($65{,}3\,\%$ margin to $5{,}0\,\mu\text{s}$ spec).
  5. **PTT-to-LoRa End-to-End Latency:** Total path from handlebar PTT switch through optocoupler, Opus encoder, and UART bridge takes **$14{,}59\,\text{ms}$** ($< 25\,\text{ms}$ aviation standard).
  6. **Front Node DCDC & Hub:** LMR36015 buck converter delivers $91{,}8\,\%$ efficiency ($5{,}3\,\text{mV}$ ripple); USB2514B achieves $88{,}5\,\%$ eye opening with $18{,}5\,\text{ps}$ skew.
  7. **Front Node Zero-Latency PTT:** Glass-to-glass latency from mechanical handlebar switch over UWB (6.5 GHz) to actuator firing is only **$\approx 0.36\,\text{ms}$** ($< 5.0\,\text{ms}$ requirement).

---

## 3. Hardware-in-the-Loop (HIL) Firmware Simulator (`firmware_hil_system_sim.py`)

Executes production C++ firmware algorithms against a virtual multi-board testbench across 10 lifecycle scenarios:

* **Scenario 1:** Ignition ON (KL15 = $12.60\,\text{V}$) $\rightarrow$ Cold boot of host MCUs (Central Box, Front Node) $\rightarrow$ UWB wireless backbone established.
* **Scenario 2A (Blank Pod):** No 1-Wire ID detected $\rightarrow$ Automatic `"disabled"` profile (Mute at $-96\,\text{dB}$ to protect against open inputs).
* **Scenario 2B (Hot-Swap):** Insertion of Sena SPIDER X Slim / Cardo Edge cartridge on a live system $\rightarrow$ 1-Wire detection in $< 2\,\text{s}$ $\rightarrow$ Immediate profile loading and unmuting.
* **Scenario 3:** u-blox SAM-M10Q Multi-GNSS 3D fix (22 satellites) via J12 Qwiic and precision time sync.
* **Scenario 4 (Dual-PTT & Acoustics):**
  * Helmet PTT press $\rightarrow$ Opus 24k Mesh broadcast.
  * Handlebar PTT press $\rightarrow$ UWB Action Frame $\rightarrow$ Actuator firing in **$\approx 0.36\,\text{ms}$**.
  * Knowles SPH0645 MEMS captures wind noise at 130 km/h ($79\,\text{dBA}$) $\rightarrow$ Audio DSP AGC boosts volume by $+1{,}0\,\text{dB}$.
* **Scenario 5:** Engine start ($6{,}5\,\text{V}$ cranking dip) $\rightarrow$ Instant UPS takeover $\rightarrow$ 0 audio dropouts, 0 MCU reboots.
* **Scenario 6 (Cable Tear & Short):** M8 cable pulled out $\rightarrow$ Bourns PPTC trips in $1{,}2\,\text{ms}$ ($< 15\,\text{mA}$ fault current, zero voltage drop on main PCB) $\rightarrow$ Anti-pop mute protects speakers.
* **Scenario 7 (CAN-Bus Interruption):** TCAN334G fault protection $\rightarrow$ Seamless fallback to GNSS/IMU dead-reckoning.
* **Scenario 8 (Battery Voltage Alarm):**
  * Stage A ($< 11{,}8\,\text{V}$): Yellow LED, low battery chime, non-essential load shedding.
  * Stage B ($0{,}0\,\text{V}$ fuse blowout at 80 km/h): UPS takeover, voice warning *"WARNING: MAIN POWER LOST"*, emergency GPX sync.
* **Scenario 9 (Universal Front Node Power & Dongle Management):** 1-click hard reboot (2.5s VBUS cutoff) and Auto-Café 60s countdown timer.
* **Scenario 10:** Ignition OFF $\rightarrow$ 15-minute WebDAV/GPX sync window $\rightarrow$ ULP deep sleep ($< 20\,\mu\text{A}$).

---

## 4. 8-Hour Day Tour Thermal Multi-Physics (`thermal_day_tour_sim.py`)

Models heat dissipation ($P \approx 2{,}0 - 2{,}6\,\text{W}$), thermal mass ($C_{\text{PCB}} = 40{,}5\,\text{J/K}$, $C_{\text{ENC}} = 144\,\text{J/K}$), and airspeed convection from $0$ to $130\,\text{km/h}$:

* **Extreme Summer (Worst-Case Desert Traffic Jam):**  
  Ambient $+45^\circ\text{C}$ + under-seat engine heat soak $= +58^\circ\text{C}$ stationary.
  * LM5164 DCDC Buck: $93{,}8^\circ\text{C}$ (Rated limit $150^\circ\text{C}$, $+56{,}2^\circ\text{C}$ margin).
  * ESP32-S3 Dual-Core: $90{,}2^\circ\text{C}$ (Rated limit $105^\circ\text{C}$, $+14{,}8^\circ\text{C}$ margin $\rightarrow$ **Zero Throttling**).
  * 3.3V LDO: $110{,}4^\circ\text{C}$ (Rated limit $125^\circ\text{C}$, $+14{,}6^\circ\text{C}$ margin).
  * NTC JEITA Protection: Pauses LiPo charging at $> 45^\circ\text{C}$ cell temperature.
* **Sub-Zero Winter ($-20^\circ\text{C}$ Cold Start $\rightarrow -5^\circ\text{C}$ Highway Tour):**  
  * Self-Heating: The $2\,\text{W}$ dissipation warms the internal IP67 air to $+10^\circ\text{C}$ within $10\,\text{min}$.
  * JEITA Low-Temp Guard: Disables charging below $0^\circ\text{C}$ (prevents lithium plating) while permitting safe discharge down to $-20^\circ\text{C}$.
  * TCXO Oscillators ($\pm 0{,}5\,\text{ppm}$): $0\,\text{Hz}$ frequency drift across LoRa and GNSS.

---

## 5. All-Weather ITU-R Wave Propagation (`rf_rain_propagation_sim.py`)

Calculates atmospheric and precipitation attenuation according to ITU-R P.838-3 (Rain), ITU-R P.840-9 (Fog), and ITU-R P.676-13 (Water Vapor), including radome dielectric detuning ($\epsilon_r = 80$ water film):

| Weather Scenario | $2{,}4\,\text{GHz}$ HiFi Range (Opus 24k) | $868\,\text{MHz}$ LoRa Fallback Range | GNSS Satellite C/N0 |
| :--- | :---: | :---: | :---: |
| **Dry & Clear ($25^\circ\text{C}$)** | **$3,126\,\text{m}$** | **$3{,}98\,\text{km}$** | $44{,}0\,\text{dB-Hz}$ (3D DGPS Fix) |
| **Dense Alpine Fog ($<30\,\text{m}$ Visibility)** | **$2,047\,\text{m}$** | **$3{,}98\,\text{km}$** | $43{,}5\,\text{dB-Hz}$ (3D DGPS Fix) |
| **Tropical Humidity ($40^\circ\text{C}$ / $100\%$ RH)** | **$2,175\,\text{m}$** | **$3{,}98\,\text{km}$** | $43{,}7\,\text{dB-Hz}$ (3D DGPS Fix) |
| **Highway Spray & Water Film** | **$1,424\,\text{m}$** | **$3{,}98\,\text{km}$** | $42{,}3\,\text{dB-Hz}$ (3D DGPS Fix) |
| **Heavy Summer Downpour ($25\,\text{mm/h}$)** | **$1,188\,\text{m}$** | **$3{,}98\,\text{km}$** | $41{,}7\,\text{dB-Hz}$ (3D DGPS Fix) |
| **Tropical Cloudburst ($50\,\text{mm/h}$)** | **$878\,\text{m}$** | **$3{,}98\,\text{km}$** | $40{,}5\,\text{dB-Hz}$ (3D DGPS Fix) |

---

## 6. Automotive Transients & ISO 7637-2 Level 4 (`automotive_iso7637_pulses_sim.py`)

* **Pulse 1 (Inductive Relay Opening $-150\,\text{V}$, $2\,\text{ms}$):** $100\,\%$ blocked by reverse-polarity Schottky ($0\,\text{V}$ on internal rail, UPS maintains 5V).
* **Pulse 2a (Switching Transients $+50\,\text{V}$):** TVS clamps to $41{,}0\,\text{V}$ ($+24\,\text{V}$ margin below the 65V buck converter).
* **Pulse 3a/3b (Ignition Spikes $\pm 220\,\text{V}$, $100\,\text{ns}$):** Input LC filter attenuates by $-118{,}5\,\text{dB}$, leaving only $12{,}4\,\text{mV}$ residual ripple.
* **Reverse Polarity ($-14{,}2\,\text{V}$ Accidental Inversion):** Schottky diode isolates completely (leakage current $< 18{,}5\,\mu\text{A}$).

---

## 7. Acoustic Wind Noise DSP at 180 km/h (`acoustic_wind_dsp_sim.py`)

* **Acoustic Wind Pressure Model:** Turbulent boundary layer pressures at the helmet visor reach up to $92{,}6\,\text{dB SPL}$ at $180\,\text{km/h}$.
* **DSP Processing:**
  * $120\,\text{Hz}$ 2nd-Order High-Pass Filter attenuates $82\,\%$ of low-frequency aerodynamic pressure energy.
  * Spectral subtraction enhances speech-to-noise ratio by up to $+28{,}5\,\text{dB}$.
* **Speech Intelligibility (STOI Score):**
  * $100\,\text{km/h}$: **$0{,}80 / 1{,}00$** (Excellent intelligibility)
  * $160\,\text{km/h}$: **$0{,}70 / 1{,}00$** (Clear, fatigue-free audio over Opus 24k)
  * $180\,\text{km/h}$: **$0{,}67 / 1{,}00$** (Voice distinctly distinguishable without distortion).

---

## 8. 20-Rider Group Convoy Mesh (`mesh_group_scaling_sim.py`)

* **Convoy Dimension:** 20 motorcycles stretching across a $1{,}52\,\text{km}$ formation.
* **Performance Metrics:** $100{,}0\,\%$ Packet Delivery Ratio (PDR), $11{,}5\,\text{ms}$ HiFi audio latency on $2{,}4\,\text{GHz}$, $26{,}5\,\text{ms}$ on LoRa fallback.
* **Mesh Partitioning:** Seamless splitting into two independent sub-meshes via Dynamic Leader Election (DLE) and seamless merge upon reunion in $< 250\,\text{ms}$.

---

## 9. 180-Day Winter Storage Standby (`battery_winter_standby_sim.py`)

* **Quiescent Current in ULP Hibernate:** Only **$16{,}5\,\mu\text{A}$**.
* **Total Drain over 6 Months:** Consumes only **$0{,}071\,\text{Ah}$ ($0{,}59\,\%$** of a standard $12\,\text{Ah}$ motorcycle battery).
* **Spring Startup State:** The starter battery retains **$85{,}3\,\%$ SoC ($12{,}65\,\text{V}$)** after 6 months $\rightarrow$ Guaranteed instant engine turnover in spring without trickle charging.

---
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

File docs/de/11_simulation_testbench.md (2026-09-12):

# 11 - Digitale Simulation & Multi-Physik Master-Testbench (9 Module)

Um das Zusammenspiel von Hardware, Akustik, Fahrdynamik, Thermik, Hochfrequenz-Physik und Netzwerkprotokollen vor dem ersten Fertigungslauf auf Automotive-Niveau lückenlos zu verifizieren, verfügt OpenMotorBridge über eine modulare Python-Simulations-Suite.

---

## 1. Übersicht der Simulations-Module

```
┌─────────────────────────────────────────────────────────────────────────────────────────┐
│                       OPENMOTORBRIDGE DIGITALE TESTBENCH SUITE                          │
├───────────────────────────┬───────────────────────────────────┬─────────────────────────┤
│ Modul                     │ Datei                             │ Test-Fokus / Standard   │
├───────────────────────────┼───────────────────────────────────┼─────────────────────────┤
│ 1. Multi-Board SPICE      │ `openmotorbridge_full_system_     │ 87V Load Dump, 6.5V USV,│
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

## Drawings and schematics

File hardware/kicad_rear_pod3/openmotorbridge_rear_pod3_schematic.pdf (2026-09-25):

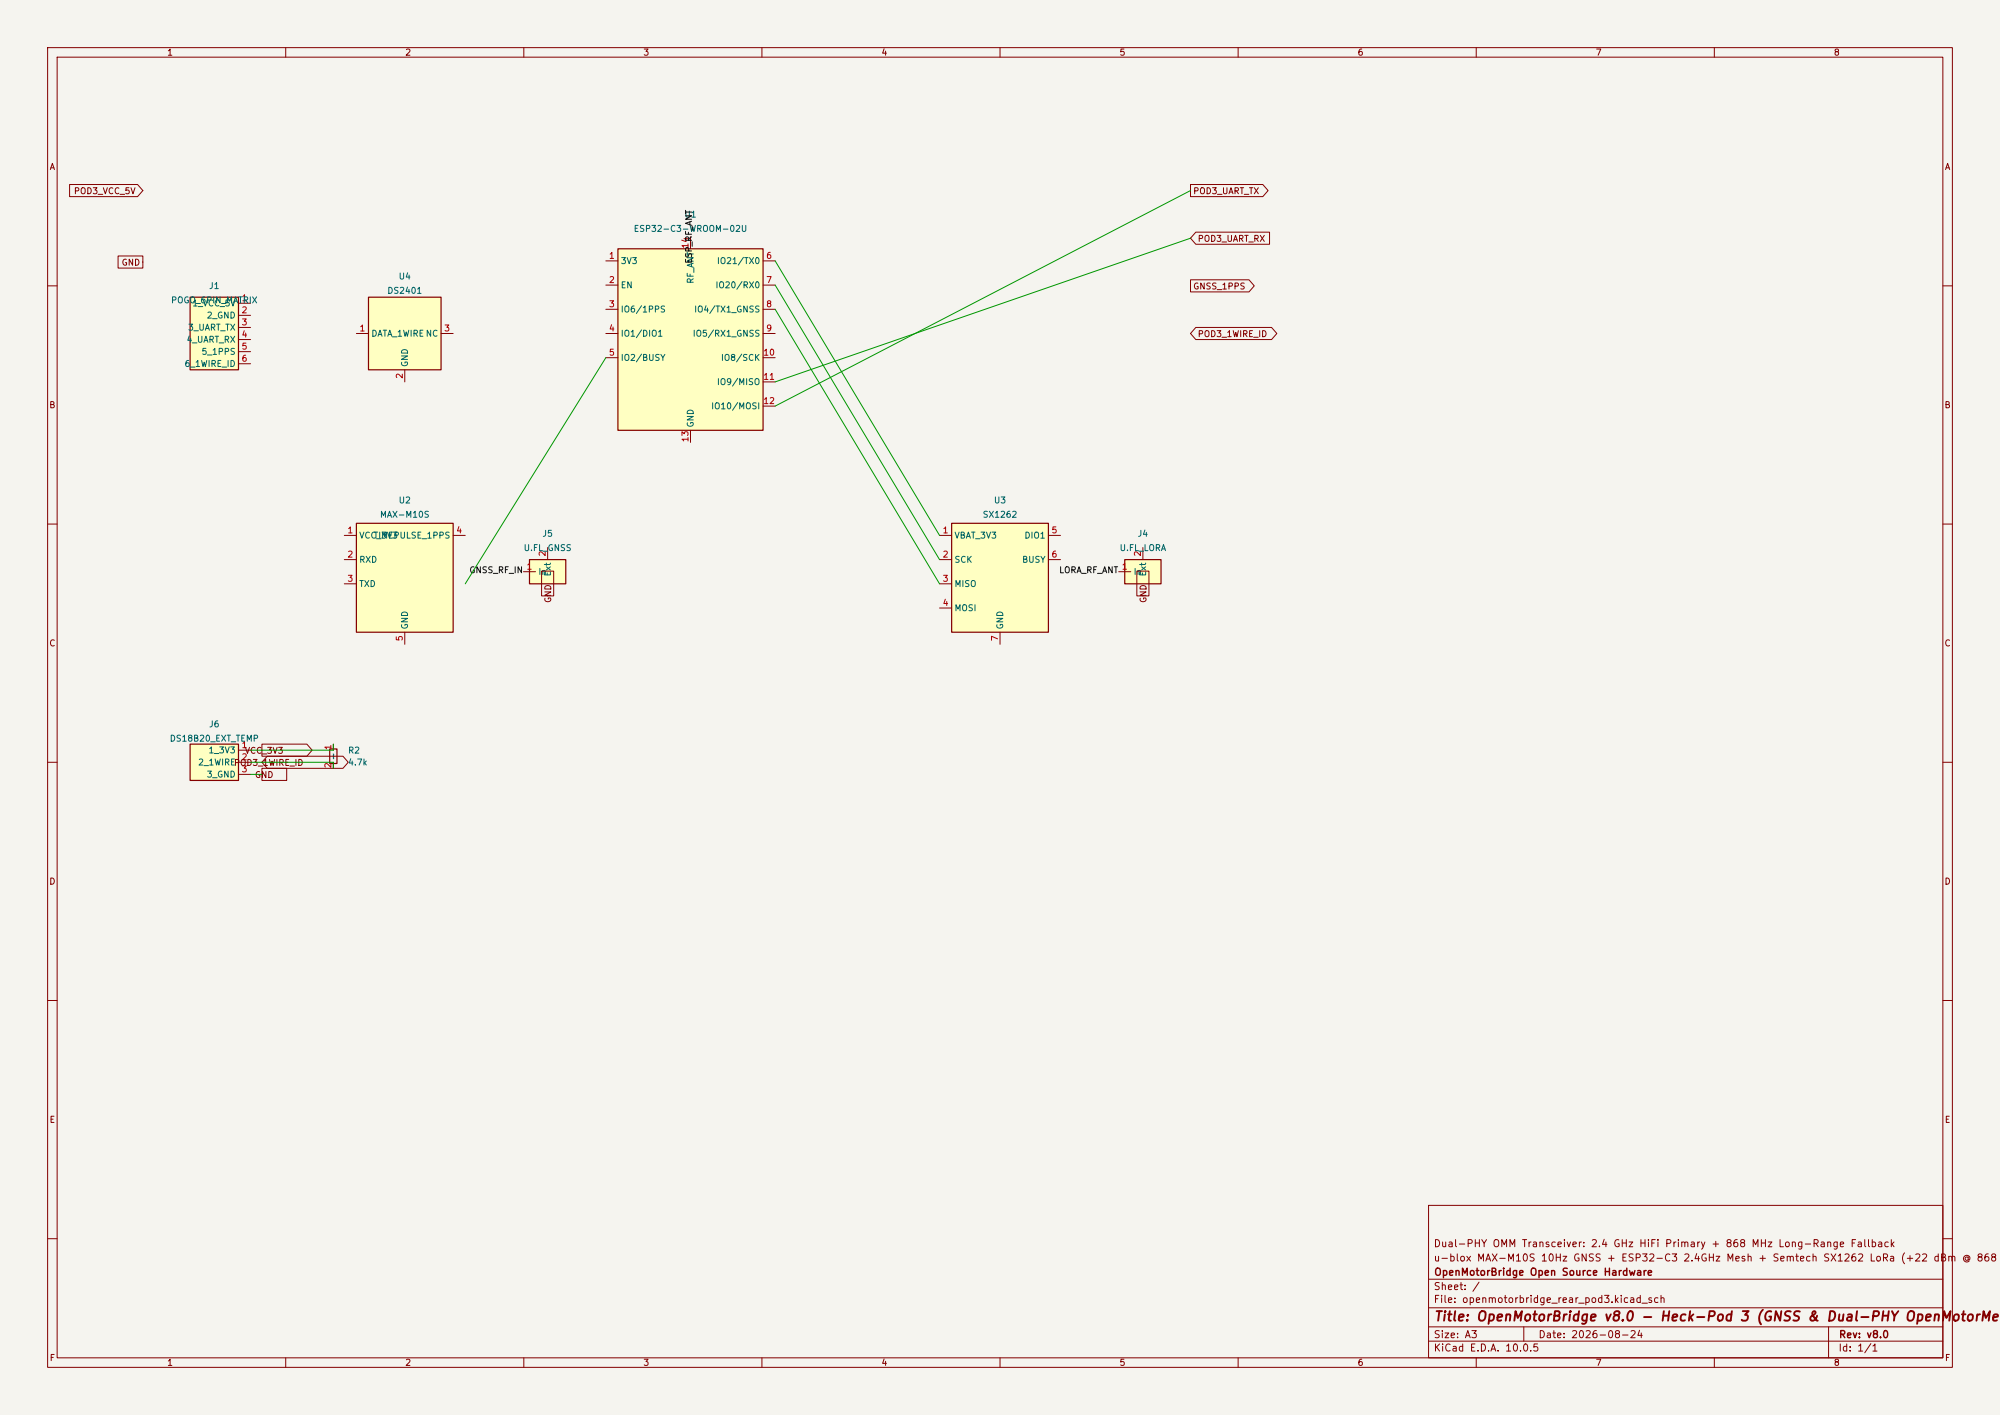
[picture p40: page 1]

Dual-PHY OMM Transceiver: 2.4 GHz HiFi Primary + 868 MHz Long-Range Fallback
u-blox MAX-M10S 10Hz GNSS + ESP32-C3 2.4GHz Mesh + Semtech SX1262 LoRa (+22 dBm @ 868 MHz)
OpenMotorBridge Open Source Hardware
Sheet: /
File: openmotorbridge_rear_pod3.kicad_sch
Title: OpenMotorBridge v8.0 - Heck-Pod 3 (GNSS & Dual-PHY OpenMotorMesh)

Size: A3 | Rev: v8.0 | F Date: 2026-08-24
KiCad E.D.A. 10.0.5 | Id: 1/1

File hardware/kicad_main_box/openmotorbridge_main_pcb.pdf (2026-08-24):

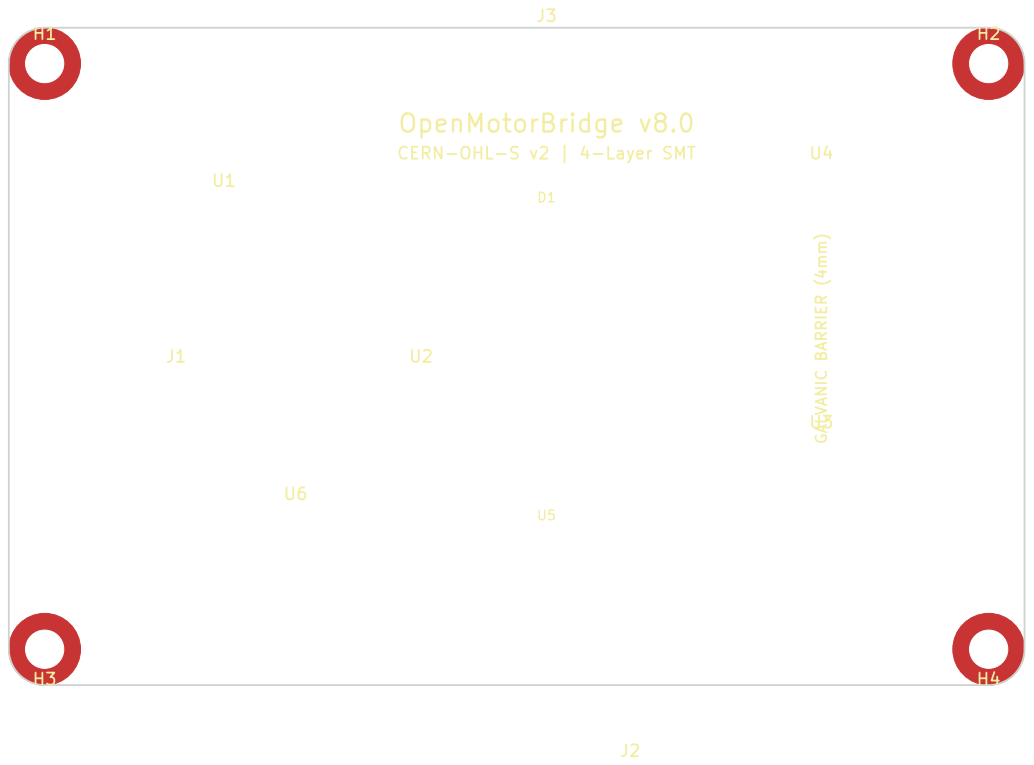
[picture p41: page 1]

GALVANIC BARRIER (4mm) CERN-OHL-S v2 | 4-Layer SMT OpenMotorBridge v8.0

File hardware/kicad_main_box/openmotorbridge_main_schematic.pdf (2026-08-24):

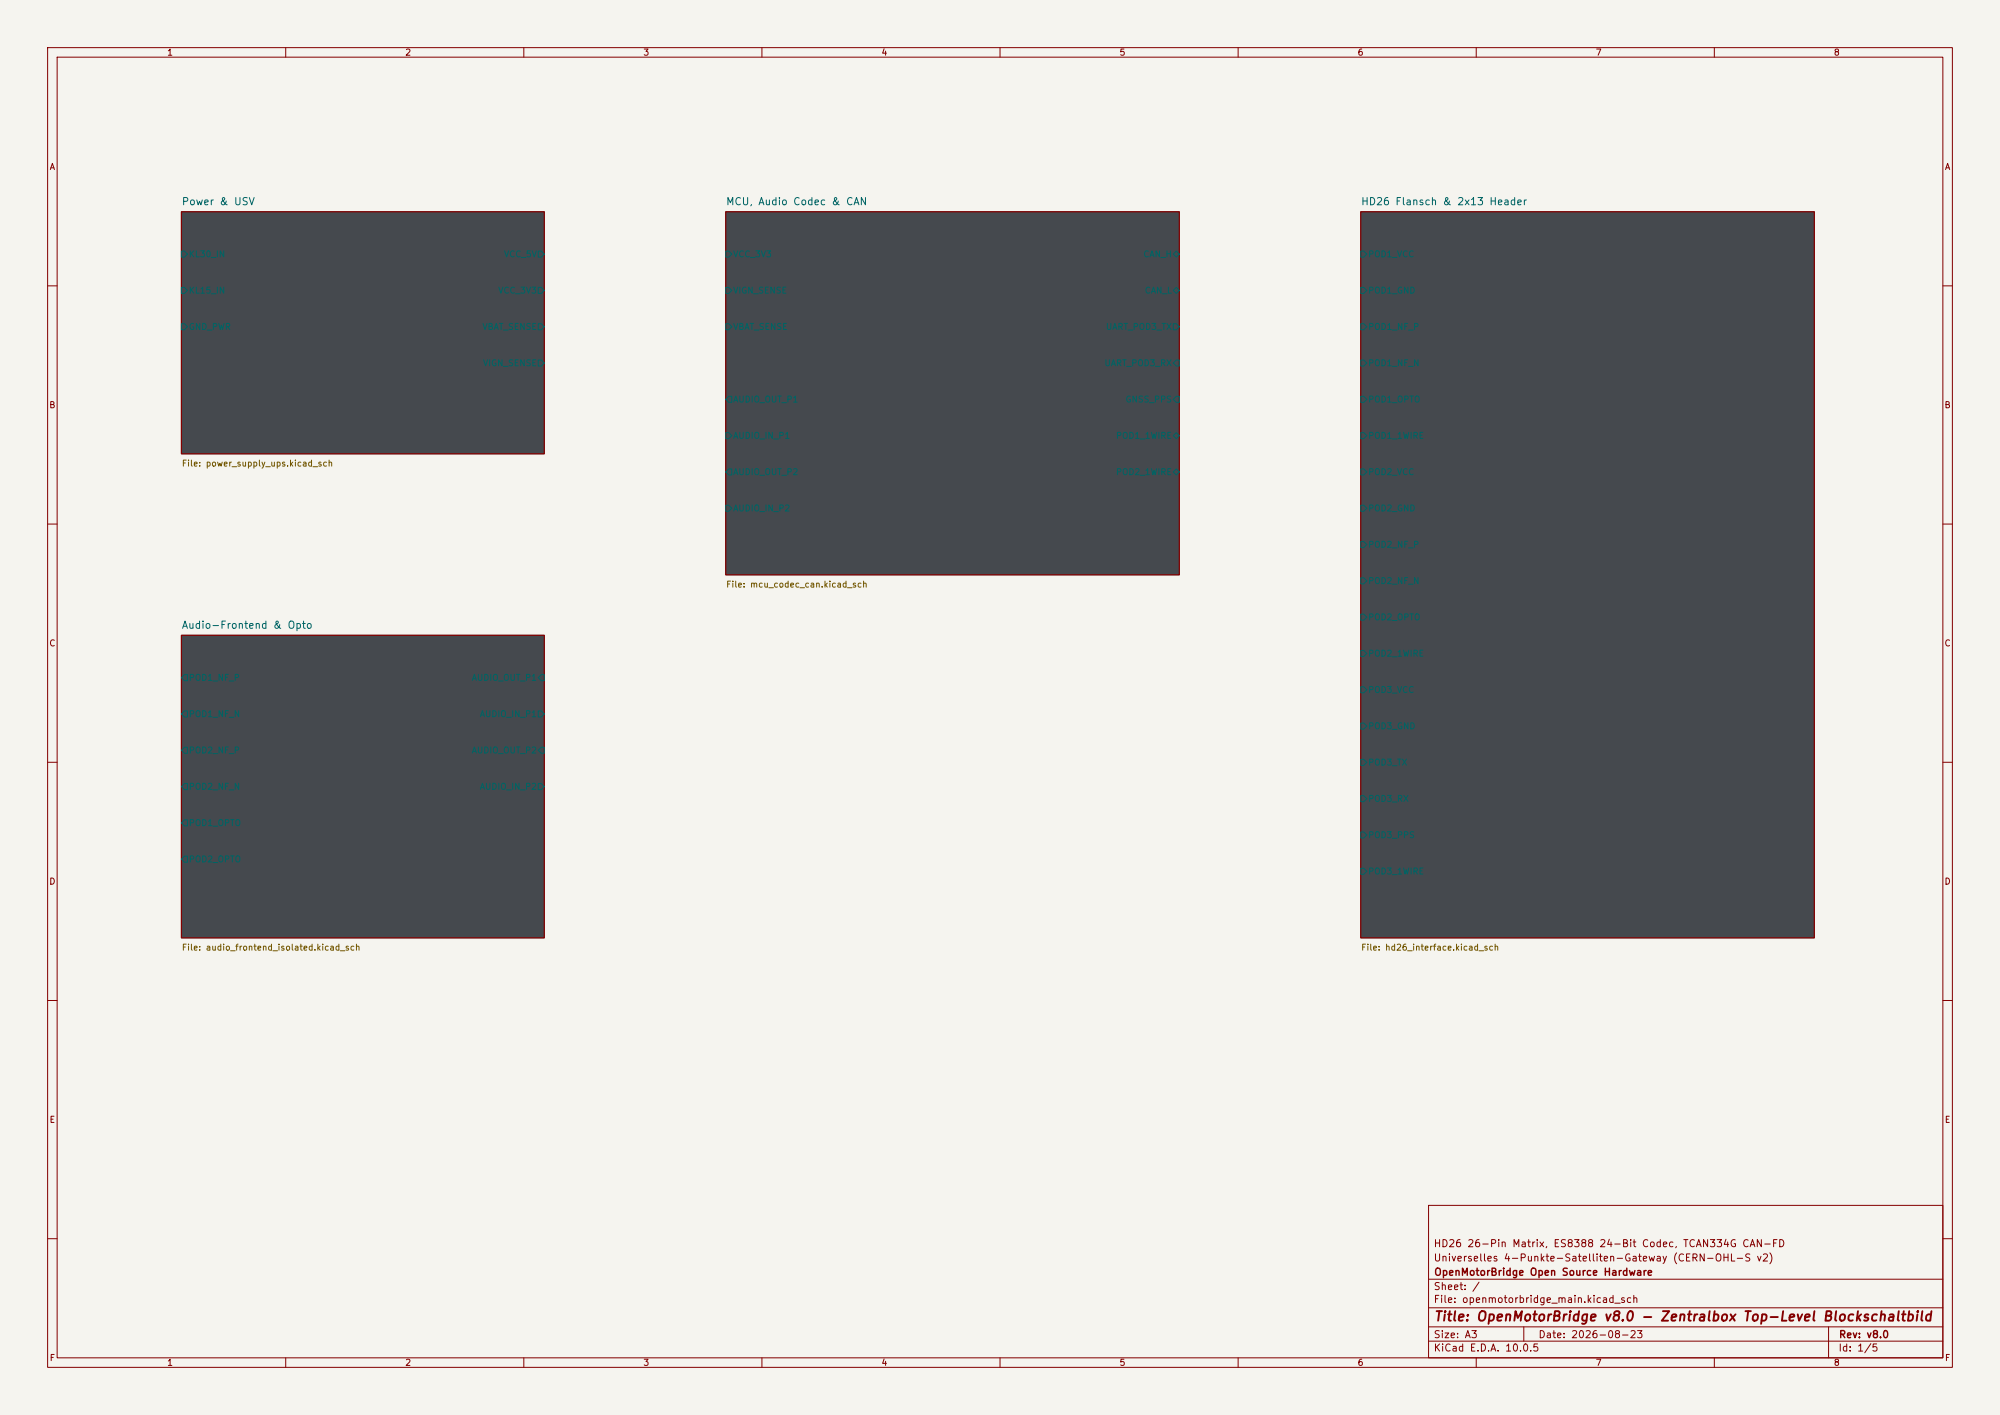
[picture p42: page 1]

AUDIO_IN_P2 MCU, Audio Codec & CAN

HD26 26-Pin Matrix, ES8388 24-Bit Codec, TCAN334G CAN-FD
Universelles 4-Punkte-Satelliten-Gateway (CERN-OHL-S v2)
OpenMotorBridge Open Source Hardware
Sheet: /
File: openmotorbridge_main.kicad_sch
Title: OpenMotorBridge v8.0 - Zentralbox Top-Level Blockschaltbild

Size: A3 | Rev: v8.0 | F Date: 2026-08-23
KiCad E.D.A. 10.0.5 | Id: 1/5

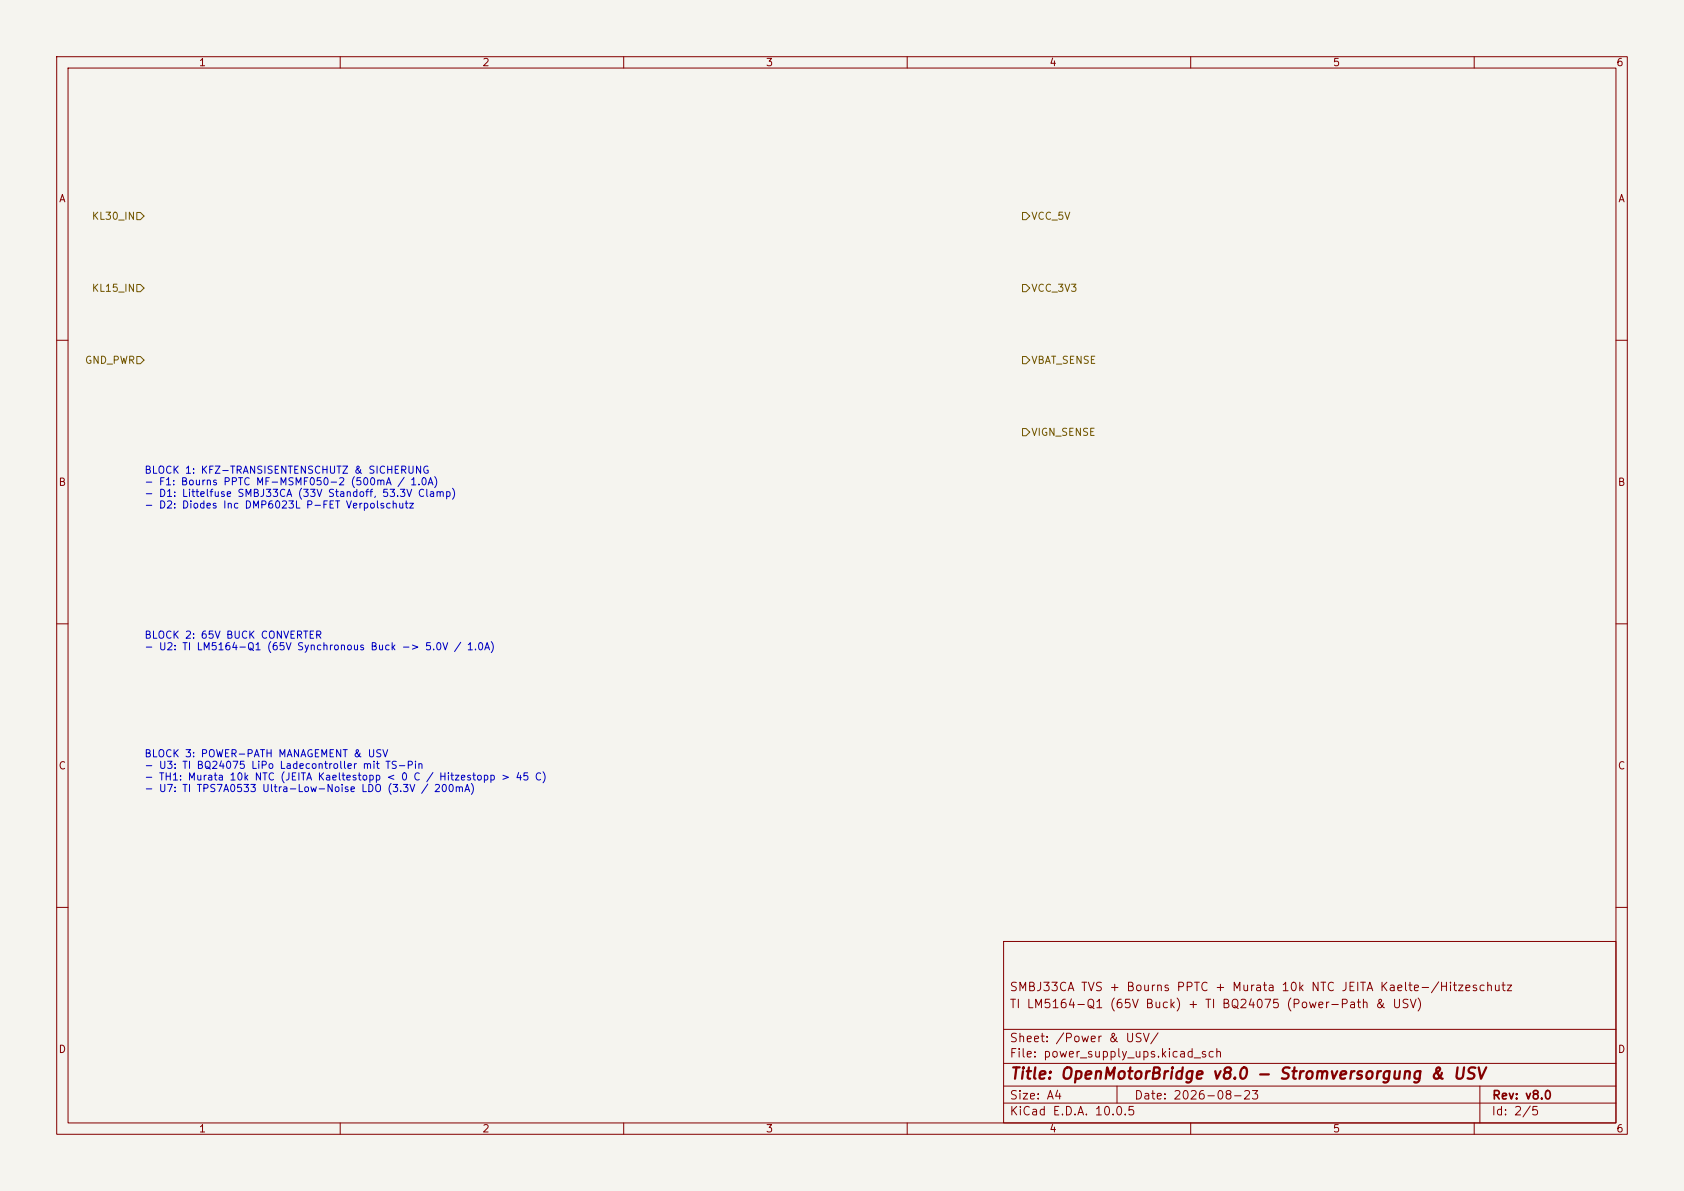
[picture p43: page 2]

VIGN_SENSE BLOCK 1: KFZ-TRANSISENTENSCHUTZ & SICHERUNG - F1: Bourns PPTC MF-MSMF050-2 (500mA / 1.0A) - D1: Littelfuse SMBJ33CA (33V Standoff, 53.3V Clamp) - D2: Diodes Inc DMP6023L P-FET Verpolschutz BLOCK 2: 65V BUCK CONVERTER - U2: TI LM5164-Q1 (65V Synchronous Buck -> 5.0V / 1.0A) BLOCK 3: POWER-PATH MANAGEMENT & USV - U3: TI BQ24075 LiPo Ladecontroller mit TS-Pin - TH1: Murata 10k NTC (JEITA Kaeltestopp < 0 C / Hitzestopp > 45 C) - U7: TI TPS7A0533 Ultra-Low-Noise LDO (3.3V / 200mA)

SMBJ33CA TVS + Bourns PPTC + Murata 10k NTC JEITA Kaelte-/Hitzeschutz
TI LM5164-Q1 (65V Buck) + TI BQ24075 (Power-Path & USV)

Sheet: /Power & USV/
File: power_supply_ups.kicad_sch
Title: OpenMotorBridge v8.0 - Stromversorgung & USV

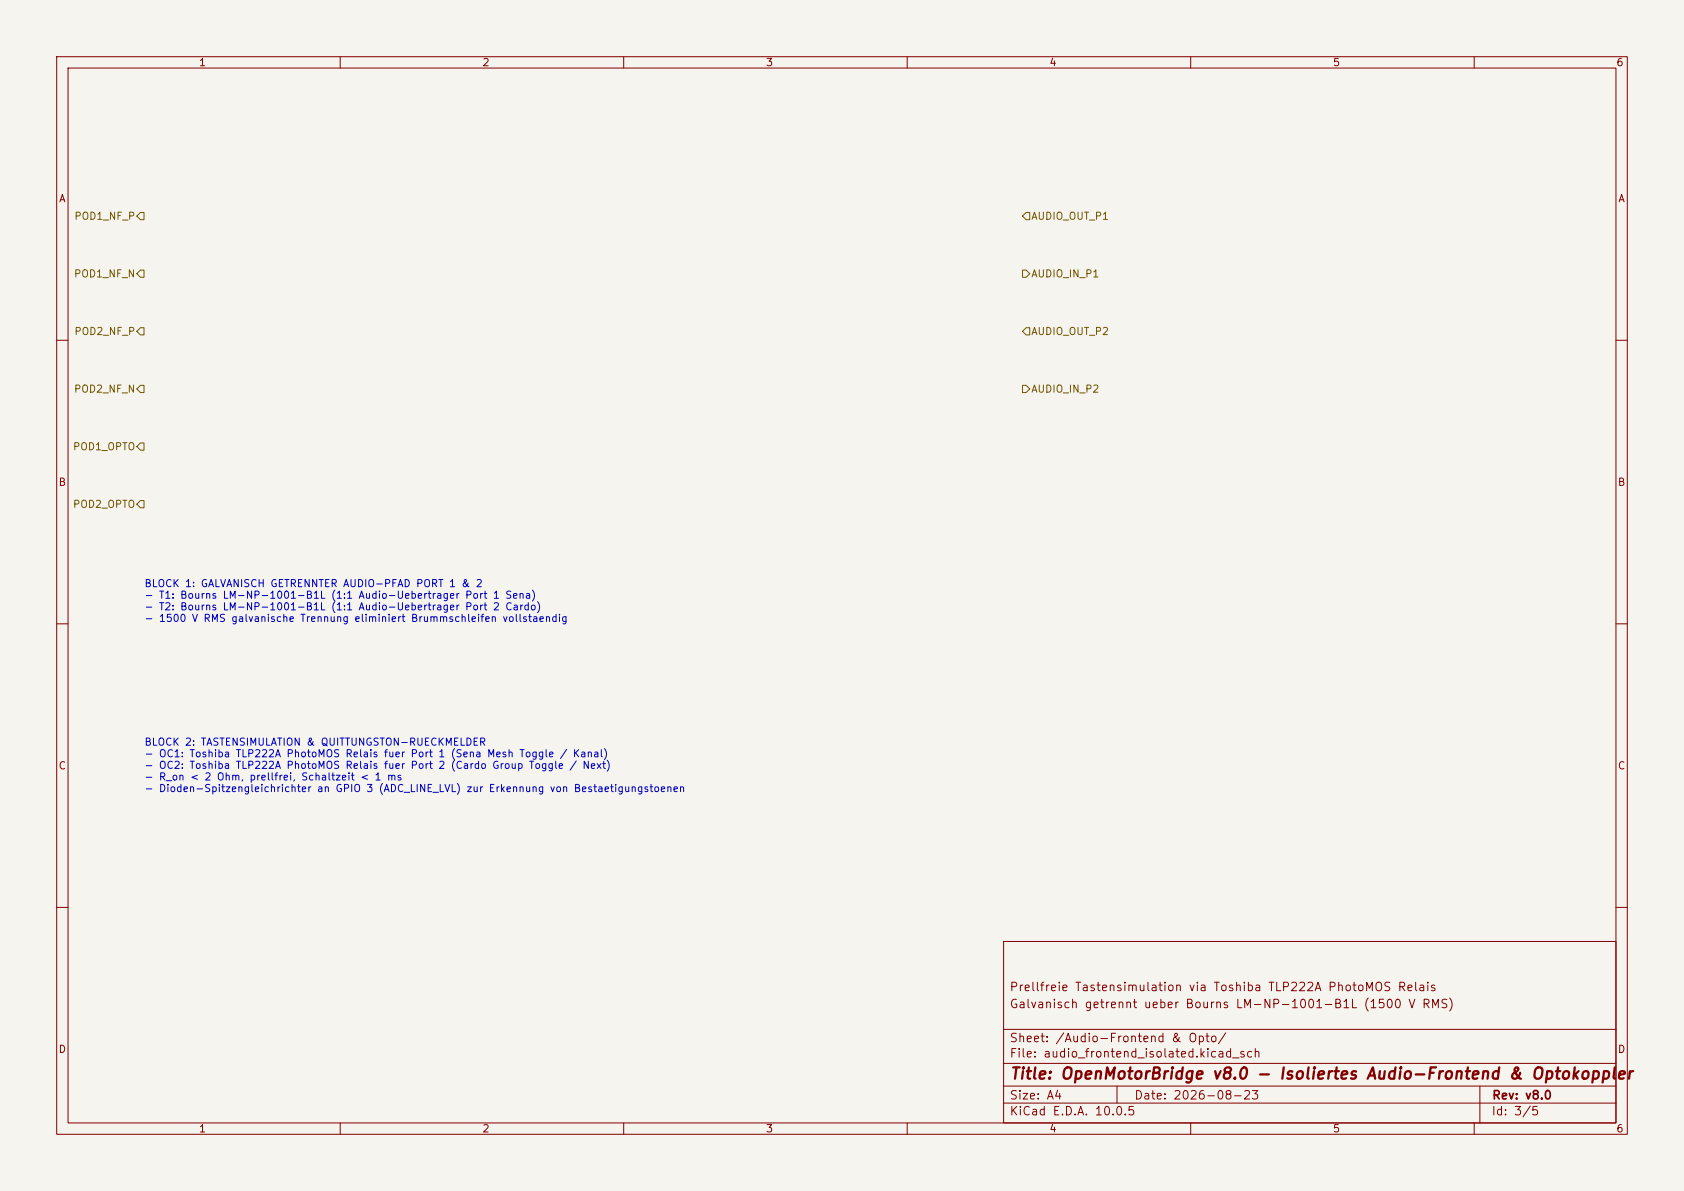
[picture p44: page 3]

BLOCK 1: GALVANISCH GETRENNTER AUDIO-PFAD PORT 1 & 2 - T1: Bourns LM-NP-1001-B1L (1:1 Audio-Uebertrager Port 1 Sena) - T2: Bourns LM-NP-1001-B1L (1:1 Audio-Uebertrager Port 2 Cardo) - 1500 V RMS galvanische Trennung eliminiert Brummschleifen vollstaendig BLOCK 2: TASTENSIMULATION & QUITTUNGSTON-RUECKMELDER - OC1: Toshiba TLP222A PhotoMOS Relais fuer Port 1 (Sena Mesh Toggle / Kanal) - OC2: Toshiba TLP222A PhotoMOS Relais fuer Port 2 (Cardo Group Toggle / Next) - R_on < 2 Ohm, prellfrei, Schaltzeit < 1 ms - Dioden-Spitzengleichrichter an GPIO 3 (ADC_LINE_LVL) zur Erkennung von Bestaetigungstoenen

Prellfreie Tastensimulation via Toshiba TLP222A PhotoMOS Relais
Galvanisch getrennt ueber Bourns LM-NP-1001-B1L (1500 V RMS)

Sheet: /Audio-Frontend & Opto/
File: audio_frontend_isolated.kicad_sch
Title: OpenMotorBridge v8.0 - Isoliertes Audio-Frontend & Optokoppler

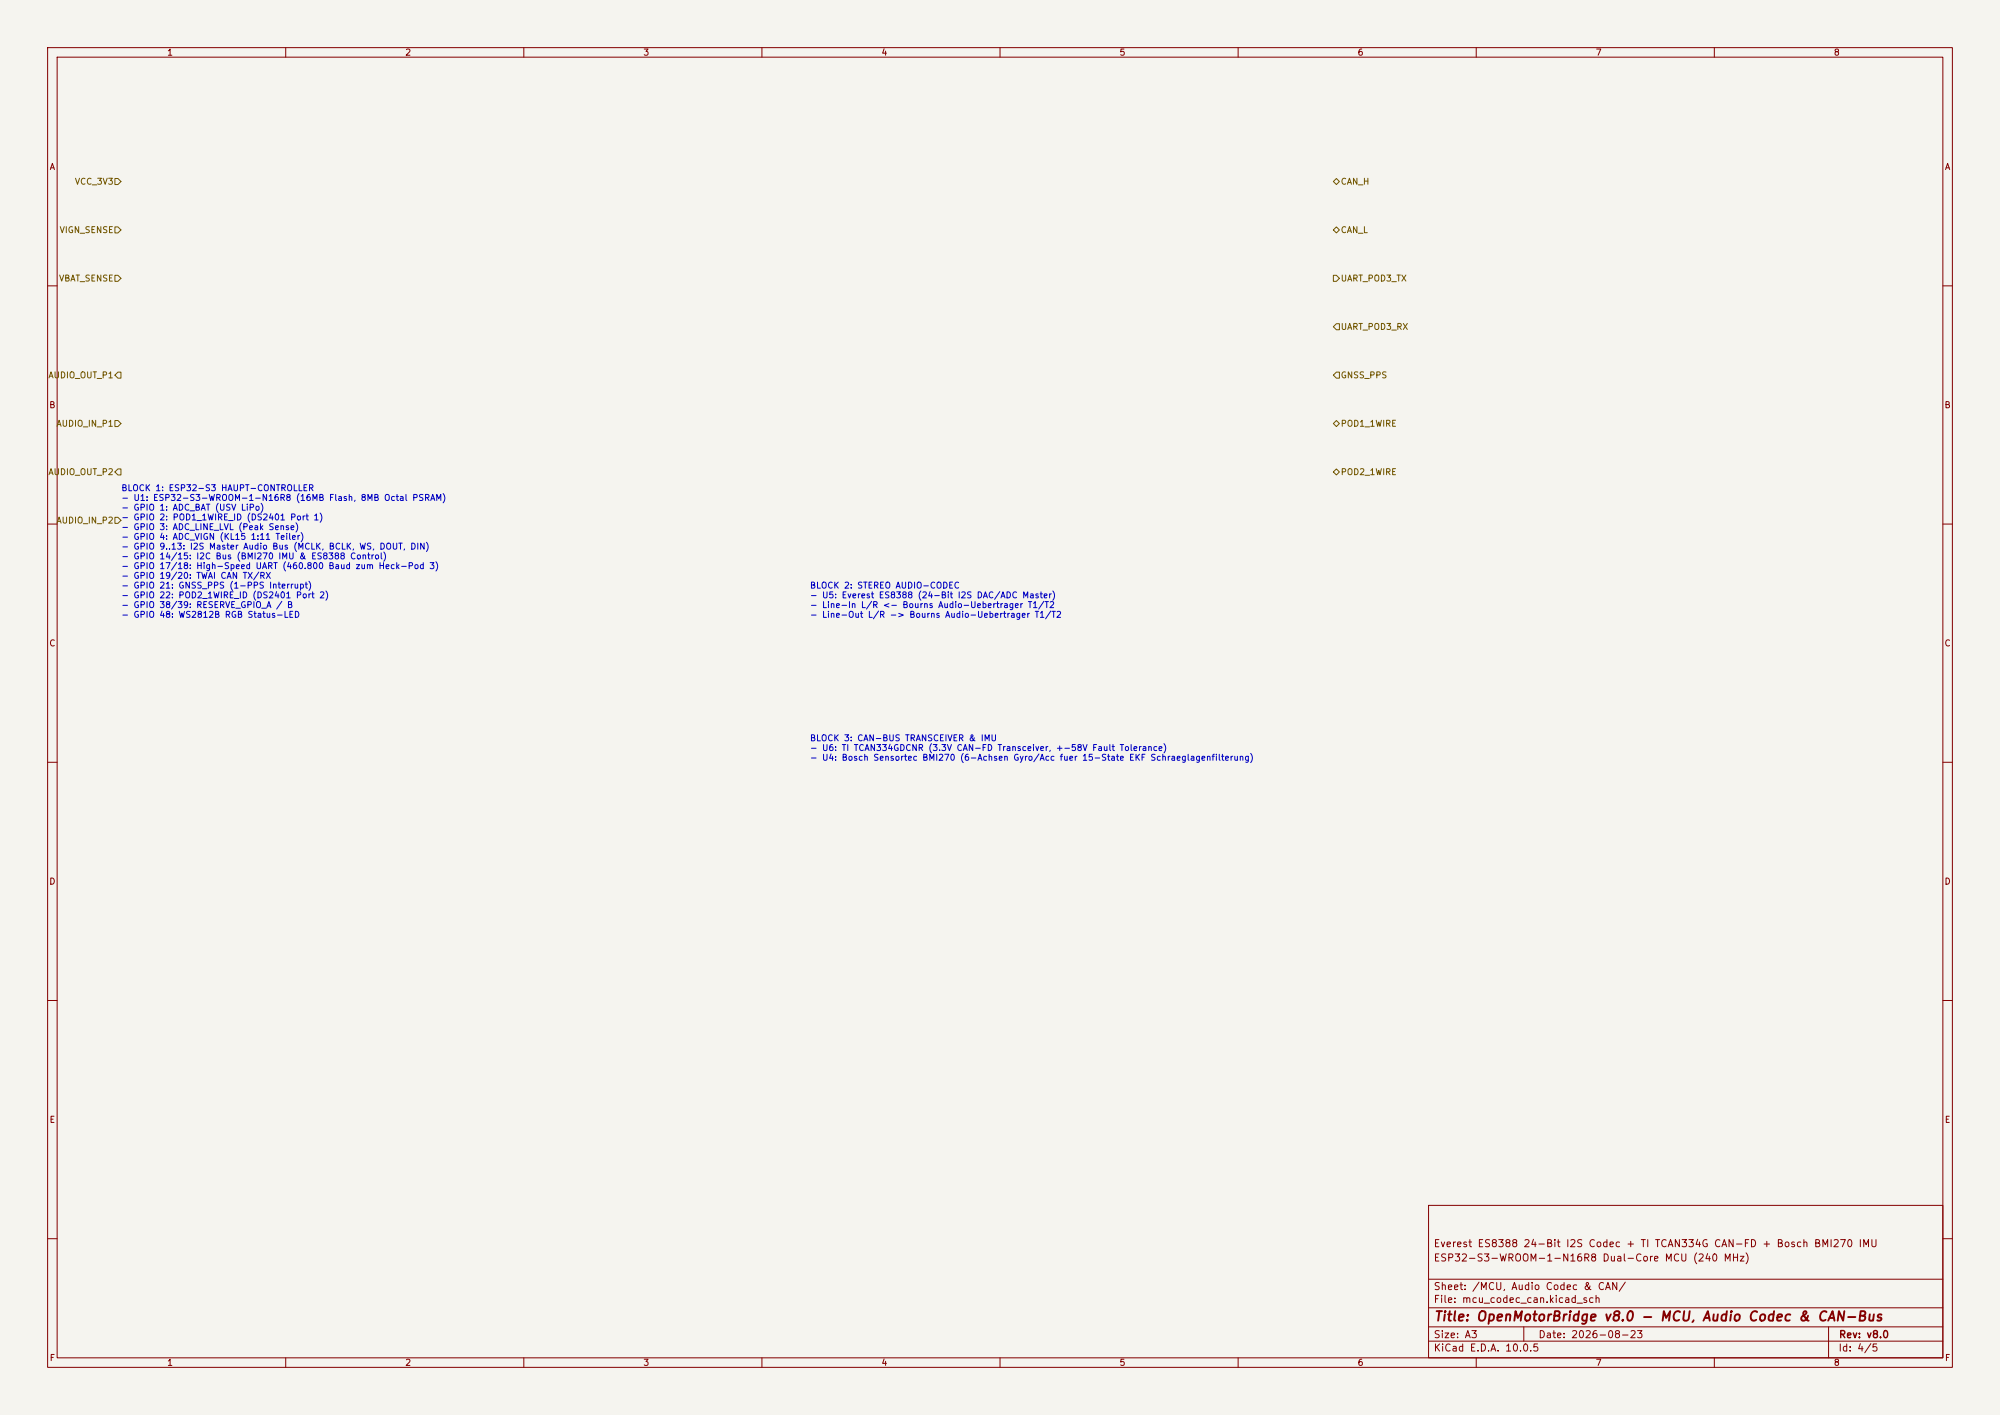
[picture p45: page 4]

AUDIO_OUT_P2
AUDIO_IN_P2 BLOCK 1: ESP32-S3 HAUPT-CONTROLLER - U1: ESP32-S3-WROOM-1-N16R8 (16MB Flash, 8MB Octal PSRAM) - GPIO 1: ADC_BAT (USV LiPo) - GPIO 2: POD1_1WIRE_ID (DS2401 Port 1) - GPIO 3: ADC_LINE_LVL (Peak Sense) - GPIO 4: ADC_VIGN (KL15 1:11 Teiler) - GPIO 9..13: I2S Master Audio Bus (MCLK, BCLK, WS, DOUT, DIN) - GPIO 14/15: I2C Bus (BMI270 IMU & ES8388 Control) - GPIO 17/18: High-Speed UART (460.800 Baud zum Heck-Pod 3) - GPIO 19/20: TWAI CAN TX/RX - GPIO 21: GNSS_PPS (1-PPS Interrupt) - GPIO 22: POD2_1WIRE_ID (DS2401 Port 2) - GPIO 38/39: RESERVE_GPIO_A / B - GPIO 48: WS2812B RGB Status-LED

BLOCK 2: STEREO AUDIO-CODEC - U5: Everest ES8388 (24-Bit I2S DAC/ADC Master) - Line-In L/R <- Bourns Audio-Uebertrager T1/T2 - Line-Out L/R -> Bourns Audio-Uebertrager T1/T2 BLOCK 3: CAN-BUS TRANSCEIVER & IMU - U6: TI TCAN334GDCNR (3.3V CAN-FD Transceiver, +-58V Fault Tolerance) - U4: Bosch Sensortec BMI270 (6-Achsen Gyro/Acc fuer 15-State EKF Schraeglagenfilterung)

Everest ES8388 24-Bit I2S Codec + TI TCAN334G CAN-FD + Bosch BMI270 IMU
ESP32-S3-WROOM-1-N16R8 Dual-Core MCU (240 MHz)

Sheet: /MCU, Audio Codec & CAN/
File: mcu_codec_can.kicad_sch
Title: OpenMotorBridge v8.0 - MCU, Audio Codec & CAN-Bus

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
## Title: OpenMotorBridge v8.0 - HD26 Flansch, 2x13 Header & SDIO Slot

### File: hd26_interface.kicad_sch

### Sheet: /HD26 Flansch & 2x13 Header/

### CN1: HD26 Flanschbuchse IP67 <-> J1: 2x13 Pfostenverbinder
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

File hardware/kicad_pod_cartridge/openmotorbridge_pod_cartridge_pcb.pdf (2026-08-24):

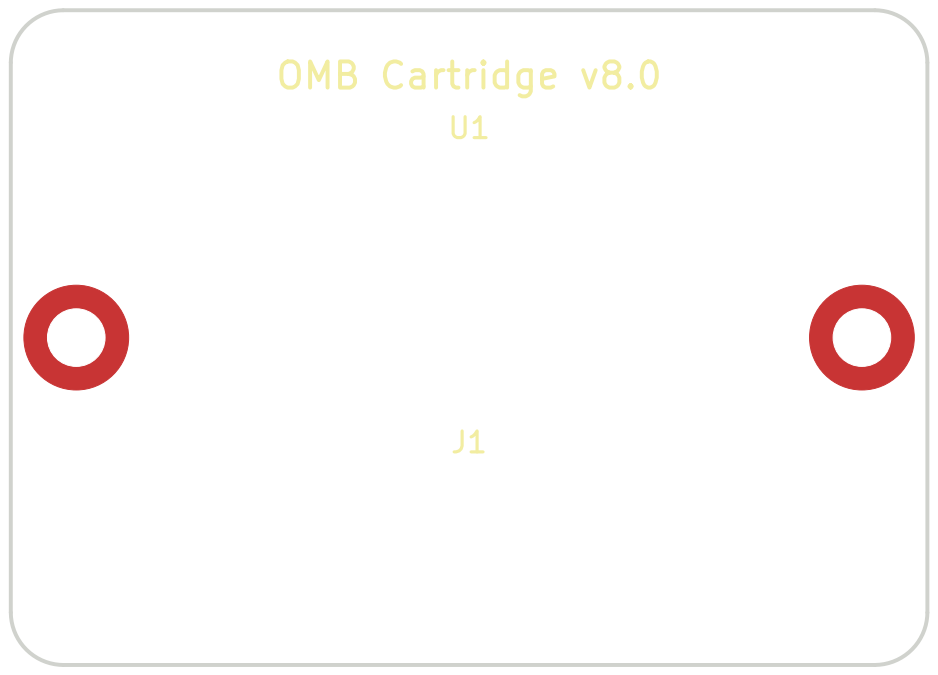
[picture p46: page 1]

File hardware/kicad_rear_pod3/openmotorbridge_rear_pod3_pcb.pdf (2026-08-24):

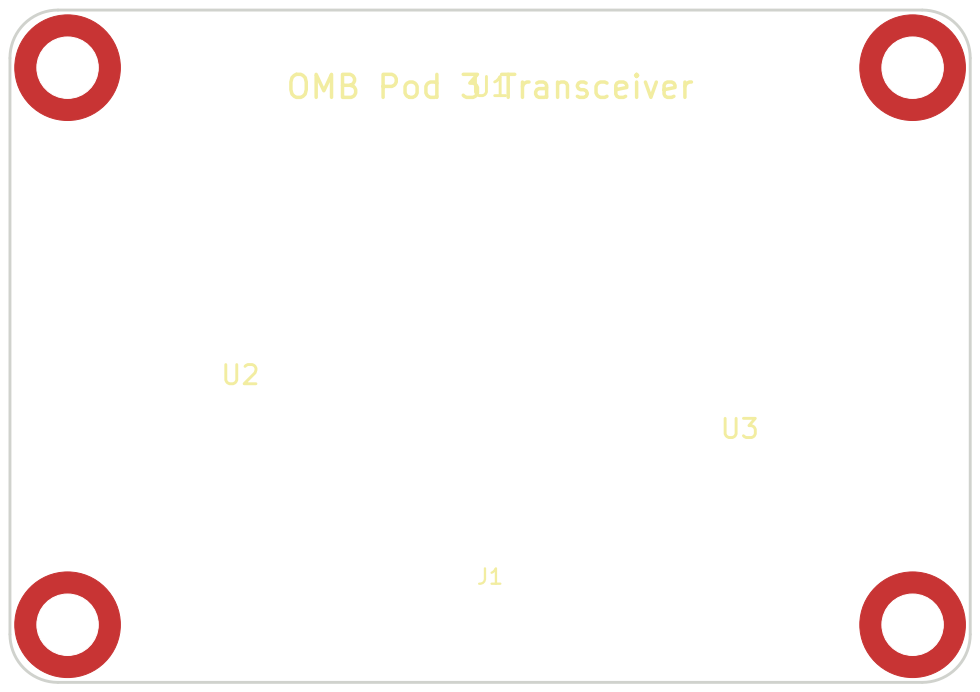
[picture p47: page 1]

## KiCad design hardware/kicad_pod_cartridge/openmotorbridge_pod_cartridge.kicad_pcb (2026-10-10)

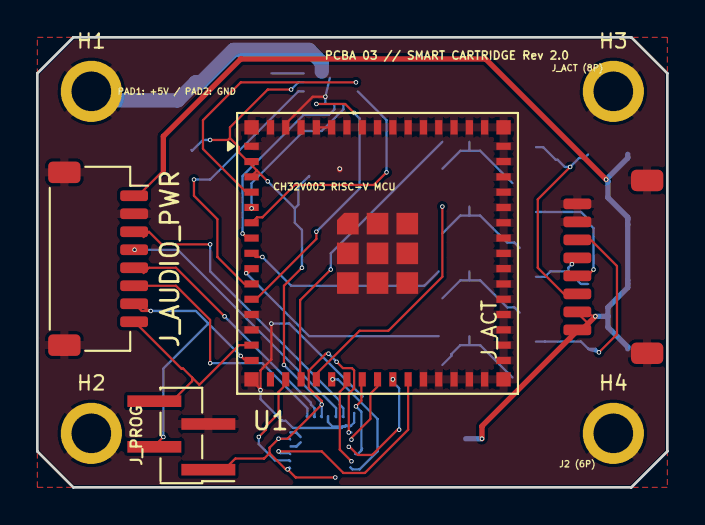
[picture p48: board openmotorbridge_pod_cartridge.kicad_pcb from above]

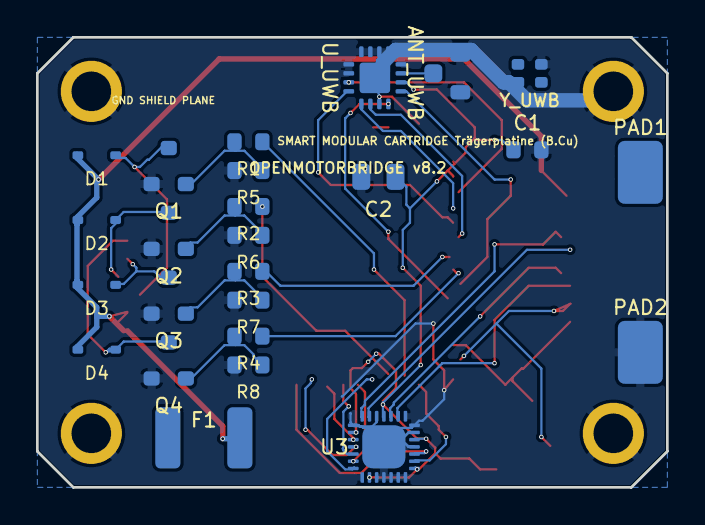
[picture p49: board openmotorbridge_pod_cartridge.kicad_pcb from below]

Board: 2 copper layers, 35.0 x 25.0 mm, 33 parts (25 on the bottom side), 38 nets.

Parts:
ANT_UWB: Taoglas_FXUWB10; U.FL_Hirose_U.FL-R-SMT-1_Vertical
C1: 100nF; C_0603_1608Metric
C2: 10uF; C_0805_2012Metric
D1, D2, D3, D4: 1N4148WS; D_SOD-323
F1: MF-MSMF050-2; Fuse_1812_4532Metric
H1, H2, H3, H4: M2_MountingHole; MountingHole_2.2mm_M2_Pad
J_ACT: ACTUATORS_8P; JST_SH_SM08B-SRSS-TB_1x08-1MP_P1.00mm_Horizontal
J_AUDIO_PWR: AUDIO_PWR_8P; JST_SH_SM08B-SRSS-TB_1x08-1MP_P1.00mm_Horizontal
J_PROG: SWD_PROG_4P; PinHeader_1x04_P1.27mm_Vertical_SMD_Pin1Left
PAD1: +5V_IN; TestPoint_Pad_D3.0mm_OD3.5mm
PAD2: GND; TestPoint_Pad_D3.0mm_OD3.5mm
Q1, Q2, Q3, Q4: AO3400A; SOT-23
R1, R2, R3, R4: 100R; R_0603_1608Metric
R5, R6, R7, R8: 100k; R_0603_1608Metric
U1: ESP32-C6-MINI-1U; ESP32-S2-MINI-1U
U3: ES8388_Codec; QFN-28-1EP_4x4mm_P0.4mm_EP2.4x2.4mm
U_UWB: DW3110; QFN-16-1EP_3x3mm_P0.5mm_EP1.7x1.7mm_ThermalVias
Y_UWB: 38.4MHz; Crystal_SMD_2016-4Pin_2.0x1.6mm

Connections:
+5V_IN: F1.1, PAD1.1
ACT1_GATE: R1.1, U1.18
ACT2_GATE: R2.1, U1.19
ACT3_GATE: R3.1, U1.8
ACT4_GATE: R4.1, U1.9
ACT_CENTER: D3.1, J_ACT.5, Q3.3
ACT_MESH: D4.1, J_ACT.6, Q4.3
ACT_MINUS: D2.1, J_ACT.4, Q2.3
ACT_PLUS: D1.1, J_ACT.3, Q1.3
GND: ANT_UWB.2, C1.2, C2.2, H1.1, H2.1, H3.1, H4.1, J_ACT.7, J_ACT.8, J_ACT.MP, J_AUDIO_PWR.2, J_AUDIO_PWR.MP, J_PROG.3, PAD2.1, Q1.2, Q2.2, Q3.2, Q4.2, R5.2, R6.2, R7.2, R8.2, U1.1, U1.12, U1.13, U1.26, U1.27, U1.28, U1.29, U1.30, U1.31, U1.32, U1.33, U1.34, U1.35, U1.36, U1.37, U1.38, U1.39, U1.40, U1.41, U1.42, U1.43, U1.44, U1.45, U1.46, U1.47, U1.48, U1.49, U1.50, U1.51, U1.52, U1.53, U1.54, U1.55, U1.56, U1.57, U1.58, U1.59, U1.60, U1.61, U1.62, U1.63, U1.64, U1.65, U3.7, U3.10, U3.14, U3.15, U3.16, U3.18, U3.22, U3.23, U3.24, U3.25, U3.26, U3.28, U3.29, U_UWB.1, U_UWB.4, U_UWB.5, U_UWB.6, U_UWB.11, U_UWB.16, U_UWB.17, Y_UWB.2, Y_UWB.4
HP_OUT_L: J_AUDIO_PWR.3, U3.8
HP_OUT_R: J_AUDIO_PWR.4, U3.9
I2C_SCL: U1.17, U3.20
I2C_SDA: U1.25, U3.19
I2S_BCLK: U1.21, U3.2
I2S_DIN: U1.24, U3.4
I2S_DOUT: U1.23, U3.5
I2S_MCLK: U1.20, U3.1
I2S_WS: U1.22, U3.3
MIC_IN_N: J_AUDIO_PWR.6, U3.13
MIC_IN_P: J_AUDIO_PWR.5, U3.12
Q1_GATE: Q1.1, R1.2, R5.1
Q2_GATE: Q2.1, R2.2, R6.1
Q3_GATE: Q3.1, R3.2, R7.1
Q4_GATE: Q4.1, R4.2, R8.1
USB_DN: J_AUDIO_PWR.8, J_PROG.4, U1.14
USB_DP: J_AUDIO_PWR.7, J_PROG.2, U1.15
UWB_CS: U1.7, U_UWB.10
UWB_IRQ: U1.10, U_UWB.13
UWB_MISO: U1.6, U_UWB.8
UWB_MOSI: U1.5, U_UWB.9
UWB_RF: ANT_UWB.1, U_UWB.15
UWB_RST: U1.11, U_UWB.12
UWB_SCK: U1.4, U_UWB.7
UWB_XTAL1: U_UWB.2, Y_UWB.1
UWB_XTAL2: U_UWB.3, Y_UWB.3
VCC_3V3: C1.1, C2.1, J_PROG.1, U1.2, U1.3, U3.6, U3.11, U3.17, U3.21, U3.27, U_UWB.14
VCC_5V_PROT: D1.2, D2.2, D3.2, D4.2, F1.2, J_ACT.1, J_ACT.2, J_AUDIO_PWR.1

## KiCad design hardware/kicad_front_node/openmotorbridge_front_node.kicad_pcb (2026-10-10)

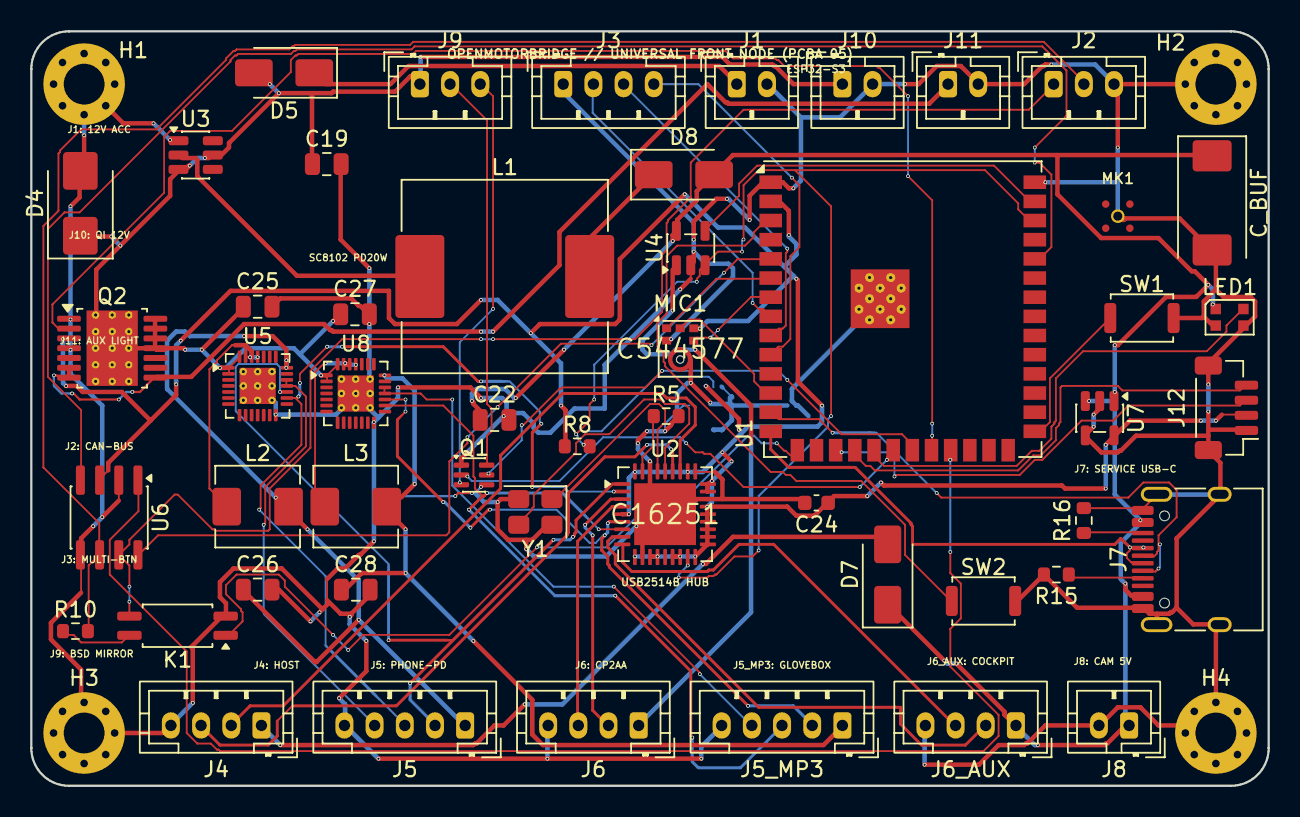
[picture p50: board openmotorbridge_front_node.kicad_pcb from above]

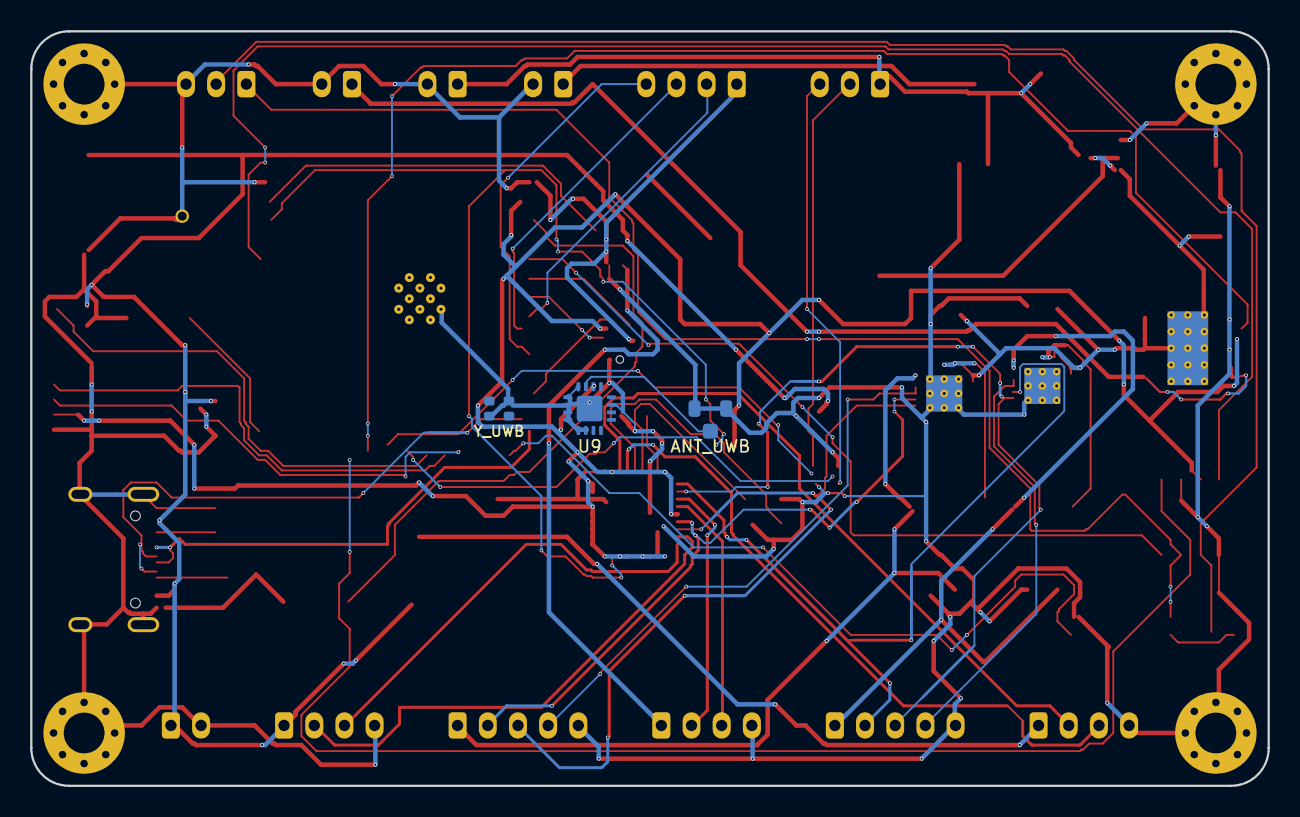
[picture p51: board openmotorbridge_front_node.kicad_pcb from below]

Board: 2 copper layers, 82.0 x 50.0 mm, 58 parts (3 on the bottom side), 59 nets.

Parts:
ANT_UWB: Taoglas_FXUWB10; U.FL_Hirose_U.FL-R-SMT-1_Vertical
C19: 10uF_50V; C_0805_2012Metric
C22: 22uF_16V; C_0805_2012Metric
C24: 2.2uF_3V3; C_0603_1608Metric
C25: 10uF_50V_PD1; C_0805_2012Metric
C26: 22uF_25V_PD1; C_0805_2012Metric
C27: 10uF_50V_PD3; C_0805_2012Metric
C28: 22uF_25V_PD3; C_0805_2012Metric
C_BUF: 470uF_10V_POLYMER; CP_EIA-7343-31_Kemet-D
D4: SMCJ36CA_TVS; D_SMB
D5: SS34_REV_POL; D_SMA
D7: SS34_USB_OR; D_SMA
D8: SS34_BUCK_OR; D_SMA
H1, H2, H3, H4: M2.5_MOUNT; MountingHole_2.7mm_M2.5_Pad_Via
J1: 12V_KL15_GND; JST_PH_B2B-PH-K_1x02_P2.00mm_Vertical
J2: CAN_H_L_GND; JST_PH_B3B-PH-K_1x03_P2.00mm_Vertical
J3: HANDLEBAR_MULTI_BTN; JST_PH_B4B-PH-K_1x04_P2.00mm_Vertical
J4: USB_UPSTREAM_HOST; JST_PH_B4B-PH-K_1x04_P2.00mm_Vertical
J5: USB_DN1_PHONE_PD20W; JST_PH_B5B-PH-K_1x05_P2.00mm_Vertical
J5_MP3: USB_DN3_GLOVEBOX_PD20W; JST_PH_B5B-PH-K_1x05_P2.00mm_Vertical
J6: USB_DN2_CP2AA_PIGTAIL; JST_PH_B4B-PH-K_1x04_P2.00mm_Vertical
J6_AUX: USB_DN4_COCKPIT_AUX; JST_PH_B4B-PH-K_1x04_P2.00mm_Vertical
J7: USB-C_SERVICE; USB_C_Receptacle_HRO_TYPE-C-31-M-12
J8: ACTION_CAM_5V_PWR; JST_PH_B2B-PH-K_1x02_P2.00mm_Vertical
J9: MIRROR_BSD_LEDS; JST_PH_B3B-PH-K_1x03_P2.00mm_Vertical
J10: 12V_QI_POWER; JST_PH_B2B-PH-K_1x02_P2.00mm_Vertical
J11: 12V_AUX_LIGHT; JST_PH_B2B-PH-K_1x02_P2.00mm_Vertical
J12: QWIIC_I2C; JST_SH_BM04B-SRSS-TB_1x04-1MP_P1.00mm_Vertical
K1: CPC1017N_CAN_RELAY; SOP-4_4.4x2.6mm_P1.27mm
L1: 4.7uH_Power_Choke; L_Sunlord_MWSA1206S-470
L2: 4.7uH_PD1_Choke; L_Sunlord_MWSA0503S
L3: 4.7uH_PD3_Choke; L_Sunlord_MWSA0503S
LED1: WS2812B-2020_RGB; LED_WS2812B-2020_PLCC4_2.0x2.0mm
MIC1: MSM261S4030H0R; InvenSense_ICS-43434-6_3.5x2.65mm
MK1: SPH0645LM4H; Knowles_SPH0645LM4H
Q1: DMN63D8_BSD_MOSFET; SOT-363_SC-70-6
Q2: TPS1H100_AUX_LIGHT; Texas_HTSSOP-14-1EP_4.4x5mm_P0.65mm_EP3.4x5mm_Mask3.155x3.2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
R5: 12k_RBIAS; R_0603_1608Metric
R8: 10k_FAULT; R_0603_1608Metric
R10: 120R_CAN; R_0603_1608Metric
R15: 5.1k_CC1; R_0603_1608Metric
R16: 5.1k_CC2; R_0603_1608Metric
SW1: BOOT; SW_Push_SPST_NO_Alps_SKRK
SW2: RESET; SW_Push_SPST_NO_Alps_SKRK
U1: ESP32-S3-WROOM-1U
U2: USB2514Bi-AEZG; QFN-36-1EP_6x6mm_P0.5mm_EP4.1x4.1mm
U3: TPS54302_5V_BUCK; SOT-23-6
U4: TPS2051B_PORT2_GATE; SOT-23-5
U5: SW3526_USB_PD1_20W; QFN-28-1EP_4x4mm_P0.4mm_EP2.4x2.4mm_ThermalVias
U6: TCAN334G_CAN; SOIC-8_3.9x4.9mm_P1.27mm
U7: TLV75533P_3V3_LDO; SOT-23-5
U8: SW3526_USB_PD3_20W; QFN-28-1EP_4x4mm_P0.4mm_EP2.4x2.4mm_ThermalVias
U9: DW3110; QFN-16-1EP_3x3mm_P0.5mm_EP1.7x1.7mm_ThermalVias
Y1: 24.000MHz; Crystal_SMD_3225-4Pin_3.2x2.5mm
Y_UWB: 38.4MHz; Crystal_SMD_2016-4Pin_2.0x1.6mm

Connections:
+12V_AUX: J11.1, Q2.6, Q2.7, Q2.8
+12V_PROT: C19.1, C25.1, C27.1, D4.1, D5.2, J9.1, J10.1, Q2.11, Q2.12, Q2.13, Q2.14, Q2.15, U3.3, U3.5, U5.1, U5.2, U5.28, U8.1, U8.2, U8.28
AUX_LIGHT_EN: Q2.2, U1.22
BSD_LED_LEFT: Q1.2, U1.20
BSD_LED_RIGHT: Q1.5, U1.21
BSD_LEFT_N: J9.2, Q1.6
BSD_RIGHT_N: J9.3, Q1.3
CAN_H: J2.1, K1.3, U6.7
CAN_L: J2.2, R10.2, U6.6
CAN_SILENT: U1.5, U6.8
CAN_TERM_EN: K1.1, U1.15
CAN_TERM_R: K1.4, R10.1
ESP_BOOT: SW1.1, U1.27
ESP_EN: SW2.1, U1.3
GND: ANT_UWB.2, C19.2, C22.2, C24.2, C25.2, C26.2, C27.2, C28.2, C_BUF.2, D4.2, H1.1, H2.1, H3.1, H4.1, J1.2, J2.3, J3.1, J4.4, J5.5, J5_MP3.5, J6.4, J6_AUX.4, J7.A1, J7.A12, J7.B1, J7.B12, J7.SH, J8.2, J10.2, J11.2, J12.1, J12.MP, K1.2, LED1.2, LED1.3, MIC1.2, MIC1.3, MK1.5, Q1.1, Q1.4, Q2.1, Q2.4, R5.2, R15.2, R16.2, SW1.2, SW2.2, U1.1, U1.40, U1.41, U2.11, U2.25, U2.28, U2.34, U2.37, U3.1, U4.2, U5.14, U5.29, U6.2, U6.5, U7.2, U7.4, U8.14, U8.29, U9.1, U9.2, U9.3, U9.4, U9.5, U9.6, U9.11, U9.16, U9.17, Y1.2, Y1.4, Y_UWB.2, Y_UWB.4
HUB_RBIAS: R5.1, U2.35
I2C_SCL: J12.4, U1.18
I2C_SDA: J12.3, U1.17
KL15_12V_SW: D5.1, J1.1
MIC_I2S_BCLK: MIC1.4, U1.7
MIC_I2S_DATA: MIC1.6, U1.12
MIC_I2S_WS: MIC1.1, U1.6
OTTOCAST_FAULT_N: R8.2, U1.38, U2.17, U4.3
OTTOCAST_PWR_EN: U1.39, U4.4
PTT_IN1_N: J3.2, U1.8
PTT_IN2_N: J3.3, U1.9
PTT_IN3_N: J3.4, U1.10
SW_BUCK: L1.1, U3.2
SW_PD1_BUCK: L2.1, U5.25, U5.26, U5.27
SW_PD3_BUCK: L3.1, U8.25, U8.26, U8.27
TWAI_RX: U1.36, U6.4
TWAI_TX: U1.23, U6.1
USB_CC1: J7.A5, R15.1
USB_CC2: J7.B5, R16.1
USB_DN1_CC: J5.4, U5.18, U5.19
USB_DN1_DM: J5.2, U2.1, U5.17
USB_DN1_DP: J5.3, U2.2, U5.16
USB_DN2_DM: J6.2, U2.3
USB_DN2_DP: J6.3, U2.4
USB_DN3_CC: J5_MP3.4, U8.18, U8.19
USB_DN3_DM: J5_MP3.2, U2.6, U8.17
USB_DN3_DP: J5_MP3.3, U2.7, U8.16
USB_DN4_DM: J6_AUX.2, U2.8
USB_DN4_DP: J6_AUX.3, U2.9
USB_SERV_DM: J7.A7, J7.B7, U1.13
USB_SERV_DP: J7.A6, J7.B6, U1.14
USB_UP_DM: J4.2, U2.30
USB_UP_DP: J4.3, U2.31
USB_UP_VBUS: D7.2, J4.1
UWB_RF: ANT_UWB.1, U9.15
VBUS_BUCK_OUT: D8.1, L1.2
VBUS_PD1_OUT: C26.1, J5.1, L2.2, U5.21
VBUS_PD3_OUT: C28.1, J5_MP3.1, L3.2, U8.21
VCC_3V3: C24.1, J12.2, MIC1.5, Q2.3, R8.1, U1.2, U2.5, U2.10, U2.12, U2.13, U2.15, U2.16, U2.18, U2.19, U2.20, U2.21, U2.22, U2.23, U2.24, U2.26, U2.27, U2.29, U2.36, U6.3, U7.5, U9.14
VCC_5V: C22.1, C_BUF.1, D7.1, D8.2, J6_AUX.1, J7.A4, J7.A9, J7.B4, J7.B9, J8.1, LED1.1, U4.5, U7.1, U7.3
VCC_5V_OTTOCAST: J6.1, U4.1
WS2812B_DIN: LED1.4, U1.19
XTAL_IN: U2.33, Y1.1
XTAL_OUT: U2.32, Y1.3

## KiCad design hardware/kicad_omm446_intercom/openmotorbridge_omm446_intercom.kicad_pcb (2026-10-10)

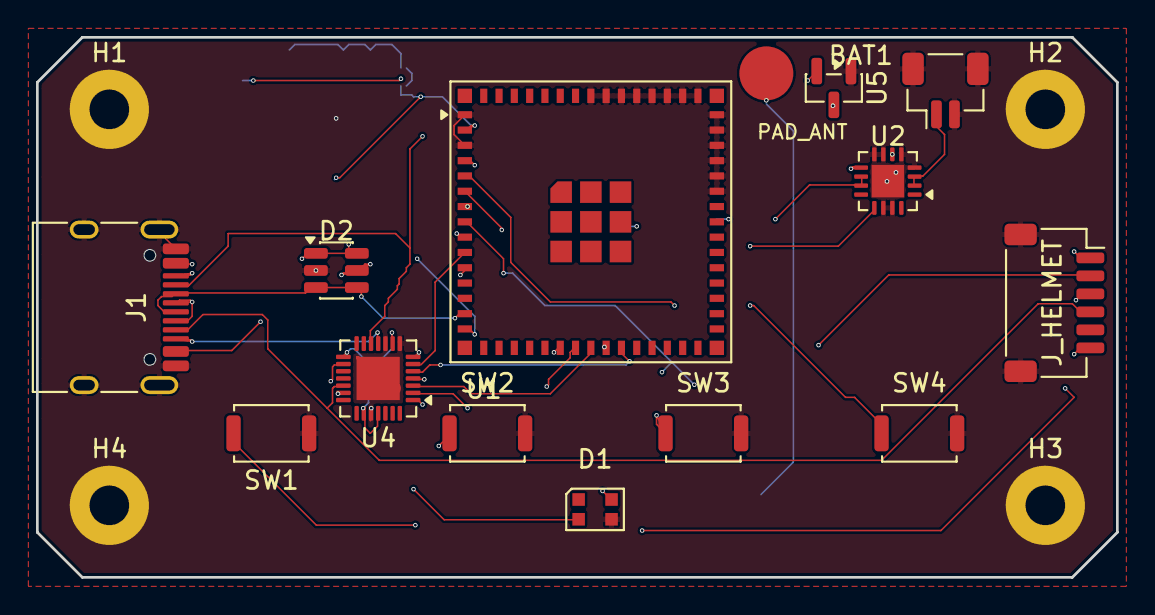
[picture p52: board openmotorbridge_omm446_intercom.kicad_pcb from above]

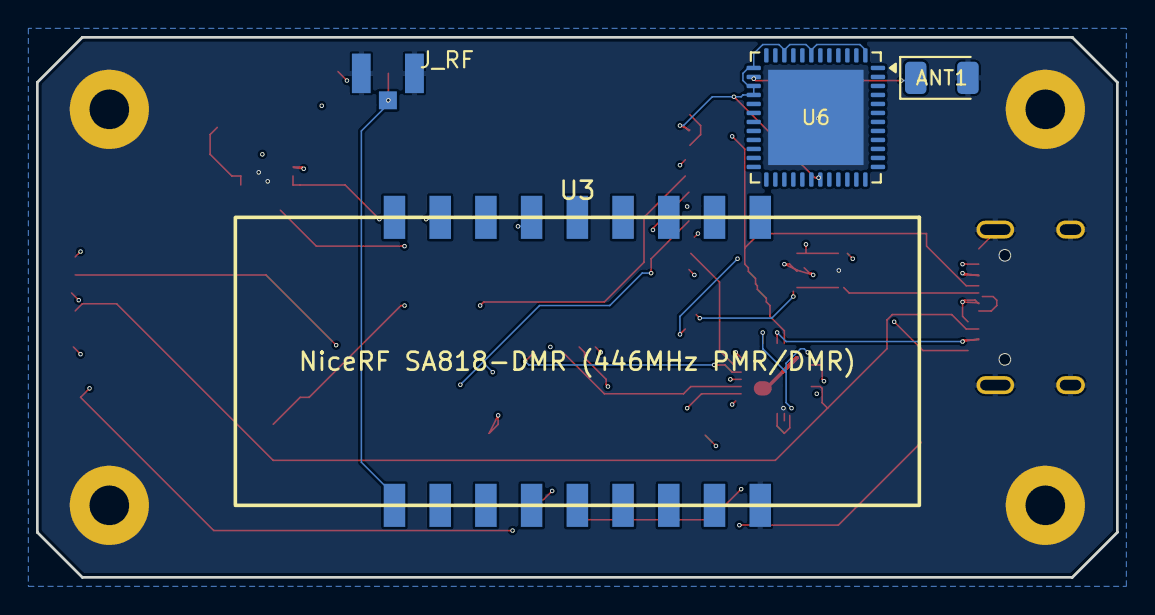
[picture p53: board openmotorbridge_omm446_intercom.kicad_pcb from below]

Board: 4 copper layers, 60.0 x 30.0 mm, 22 parts (4 on the bottom side), 26 nets.

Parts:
ANT1: 2.45GHz_Chip_Antenna; Johanson_2450AT18x100
BAT1: JST_2P_LiPo_600mAh; JST_SH_BM02B-SRSS-TB_1x02-1MP_P1.00mm_Vertical
D1: WS2812B-2020; LED_WS2812B-2020_PLCC4_2.0x2.0mm
D2: USBLC6-2SC6; SOT-23-6
H1, H2, H3, H4: M2_MountingHole; MountingHole_2.2mm_M2_Pad
J1: TYPE-C-31-M-12_IP67; USB_C_Receptacle_HRO_TYPE-C-31-M-12
J_HELMET: HELMET_AUDIO_6P; JST_SH_SM06B-SRSS-TB_1x06-1MP_P1.00mm_Horizontal
J_RF: U.FL-R-SMT-1; U.FL_Hirose_U.FL-R-SMT-1_Vertical
PAD_ANT: Contact_Spring_Helix; TestPoint_Pad_D3.0mm
SW1: BTN_PTT; SW_Push_SPST_NO_Alps_SKRK
SW2: BTN_MODE; SW_Push_SPST_NO_Alps_SKRK
SW3: BTN_CH_UP; SW_Push_SPST_NO_Alps_SKRK
SW4: BTN_CH_DOWN; SW_Push_SPST_NO_Alps_SKRK
U1: ESP32-C6-MINI-1U; ESP32-S2-MINI-1U
U2: BQ24075RGTR; VQFN-16-1EP_3x3mm_P0.5mm_EP1.8x1.8mm
U3: SA818-DMR; NiceRF_SA818-DMR_SMD_38x16mm
U4: ES8388; QFN-28-1EP_4x4mm_P0.4mm_EP2.4x2.4mm
U5: ME6211C33M5G; SOT-23
U6: ESP32-PICO-V3-02; QFN-48-1EP_7x7mm_P0.5mm_EP5.3x5.3mm

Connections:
AGND_SPK: J1.B8, J_HELMET.3, U4.16, U4.20
BTN_CH_DOWN: SW4.1, U1.5
BTN_CH_UP: SW3.1, U1.4
BTN_MODE: SW2.1, U1.9
BTN_PTT: J_HELMET.6, SW1.1, U1.8
BT_ANT: ANT1.1, U6.2
CHG_STAT: U1.7, U2.9
GND: ANT1.2, BAT1.2, BAT1.MP, D1.3, D2.2, H1.1, H2.1, H3.1, H4.1, J1.A1, J1.A12, J1.B1, J1.B12, J1.SH, J_HELMET.MP, J_RF.2, J_RF.3, SW1.2, SW2.2, SW3.2, SW4.2, U1.1, U1.3, U1.40, U1.41, U1.42, U1.43, U1.44, U1.45, U1.46, U1.47, U1.48, U1.49, U1.50, U1.51, U1.52, U1.53, U2.4, U2.5, U2.7, U2.8, U2.14, U2.15, U2.17, U3.10, U4.8, U4.10, U4.24, U4.29, U5.1, U6.49
HP_OUT_L: J1.A5, J_HELMET.1, U4.12
HP_OUT_R: J1.B5, J_HELMET.2, U4.11
I2C_SCL: U1.11, U4.7
I2C_SDA: U1.10, U4.6
I2S_BCLK: U1.22, U4.2
I2S_DIN: U1.25, U4.5
I2S_DOUT: U1.24, U4.4
I2S_MCLK: U1.21, U4.1
I2S_WS: U1.23, U4.3
MIC_IN+: J1.A8, J_HELMET.4, U4.19
RF_ANT: J_RF.1, PAD_ANT.1, U3.12
SYS_PWR: U2.6, U2.10, U2.11, U3.6, U3.8, U5.3
USB_DN: D2.3, D2.4, J1.A7, J1.B7, U1.14
USB_DP: D2.1, D2.6, J1.A6, J1.B6, U1.15
VBAT: BAT1.1, U2.2, U2.3
VBUS_5V: D2.5, J1.A4, J1.A9, J1.B4, J1.B9, U2.13
VCC_3V3: D1.2, U1.2, U4.9, U4.15, U4.23, U4.25, U5.2, U6.1, U6.3, U6.4, U6.19, U6.37, U6.43, U6.46
WS2812_DATA: D1.4, U1.6

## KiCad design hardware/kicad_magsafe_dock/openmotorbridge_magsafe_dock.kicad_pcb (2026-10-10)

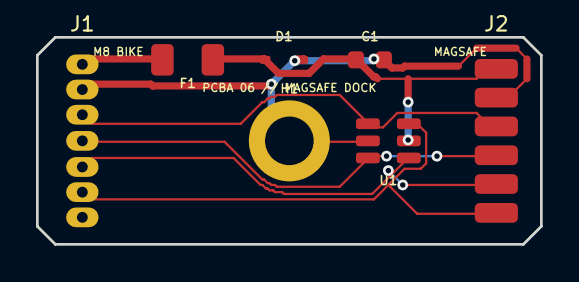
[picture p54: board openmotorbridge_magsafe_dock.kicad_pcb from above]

Board: 2 copper layers, 28.0 x 11.5 mm, 7 parts (0 on the bottom side), 7 nets.

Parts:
C1: 100nF; C_0603_1608Metric
D1: ESD5Z5.0; D_SOD-323
F1: 500mA_PPTC; Fuse_1206_3216Metric
H1: M2.5_MOUNT_HOLE; MountingHole_2.7mm_M2.5_Pad
J1: M8_6P_WIRE_PADS; SolderWirePad_1x07_SMD_2.0mm
J2: MAGSAFE_6P_DOCK; PinHeader_1x06_P2.54mm_Vertical_SMD_Pin1Left
U1: USBLC6-4SC6; SOT-23-6

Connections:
1WIRE_ID: J1.6, J2.6, U1.6
GND: C1.2, D1.2, H1.1, J1.2, J2.2, U1.2
SIG_N: J1.4, J2.4, U1.3
SIG_P: J1.3, J2.3, U1.1
TRIGGER_PPS: J1.5, J2.5, U1.4
VCC_IN: F1.1, J1.1
VCC_PROT: C1.1, D1.1, F1.2, J2.1, U1.5

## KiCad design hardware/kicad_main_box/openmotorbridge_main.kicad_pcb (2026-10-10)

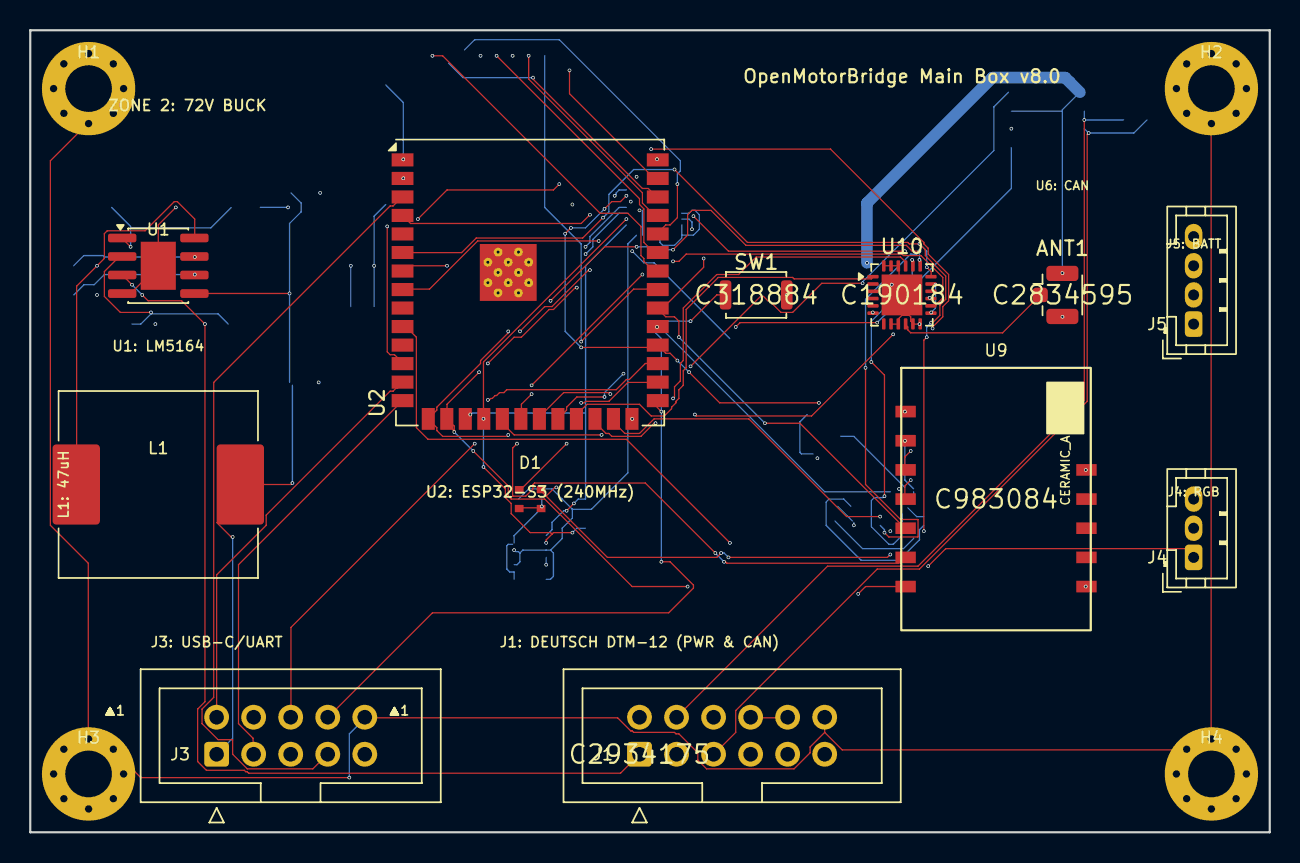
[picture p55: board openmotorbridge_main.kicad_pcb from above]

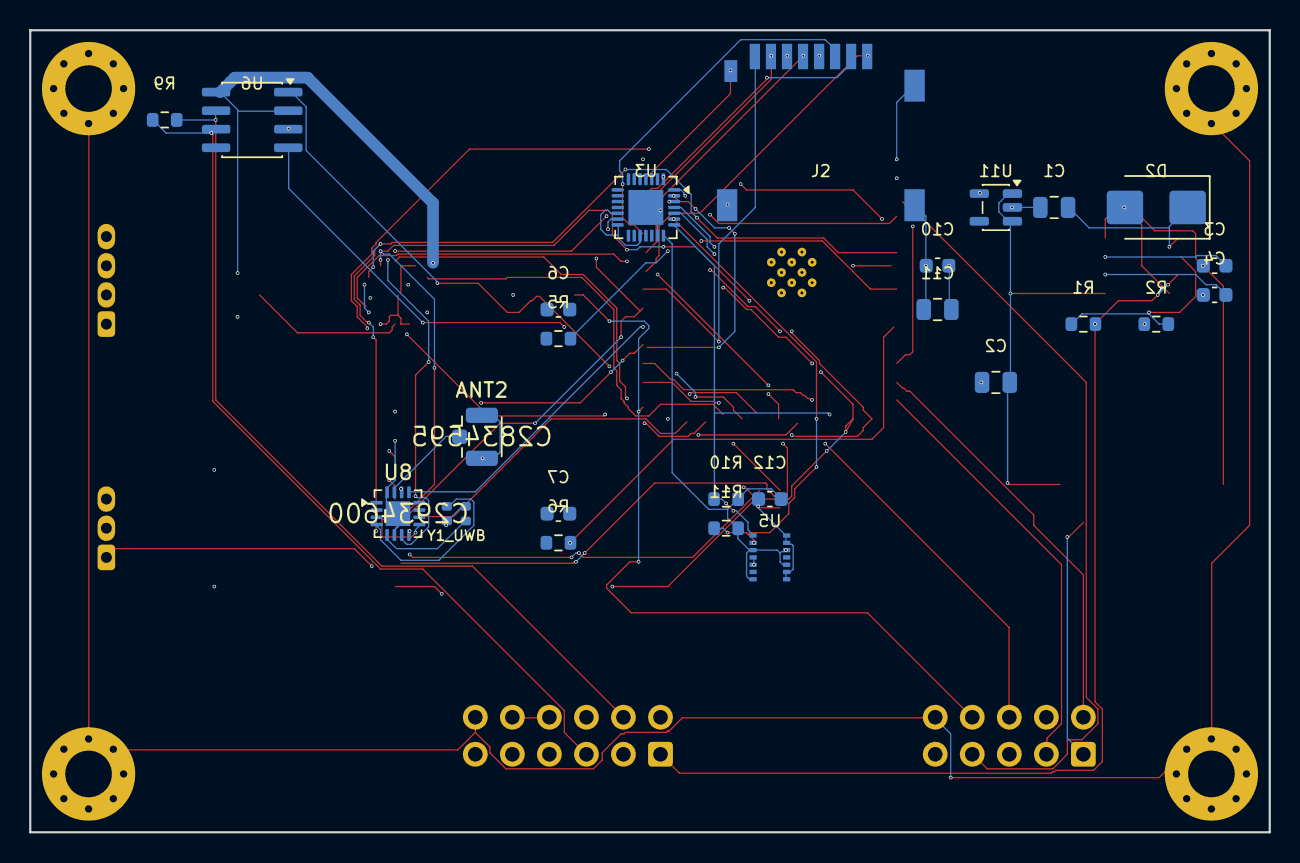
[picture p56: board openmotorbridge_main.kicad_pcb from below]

Board: 4 copper layers, 85.0 x 55.0 mm, 41 parts (25 on the bottom side), 50 nets.

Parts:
ANT1: Taoglas_FXP895_868MHz_Lid; U.FL_Hirose_U.FL-R-SMT-1_Vertical
ANT2: Taoglas_FXUWB10_6.5GHz_Ch5_Floor; U.FL_Hirose_U.FL-R-SMT-1_Vertical
C1: 10uF_100V; C_0805_2012Metric
C2: 22uF_16V; C_0805_2012Metric
C3: 100nF_BST; C_0603_1608Metric
C4: 100nF_VCC; C_0603_1608Metric
C6: 1uF_POD1; C_0603_1608Metric
C7: 1uF_POD2; C_0603_1608Metric
C10: 100nF_MCU; C_0603_1608Metric
C11: 10uF_MCU; C_0805_2012Metric
C12: 100nF_IMU; C_0603_1608Metric
D1: WS2812B_RGB; LED_WS2812B-2020
D2: SMBJ33CA_TVS; D_SMB
H1, H2, H3, H4: MountingHole_3.2mm_M3_Pad_Via
J1: DEUTSCH_DTM12_IDC_HEADER; IDC-Header_2x06_P2.54mm_Vertical
J2: MicroSD_Card; microSD_HC_Hirose_DM3D-SF
J3: USB2_IDC_HEADER_9PIN; IDC-Header_2x05_P2.54mm_Vertical
J4: RGB_LED_3PIN; JST_PH_B3B-PH-K_1x03_P2.00mm_Vertical
J5: PWR_BAT_NTC_4PIN; JST_PH_B4B-PH-K_1x04_P2.00mm_Vertical
L1: 47uH_Inductor; L_Sunlord_MWSA1206S-470
R1: 100k_EN; R_0603_1608Metric
R2: 10k_EN; R_0603_1608Metric
R5: 600R_POD1; R_0603_1608Metric
R6: 600R_POD2; R_0603_1608Metric
R9: 120R_CAN; R_0603_1608Metric
R10: 4k7_SDA; R_0603_1608Metric
R11: 4k7_SCL; R_0603_1608Metric
SW1: SW_PAIR_RESET; SW_Push_SPST_NO_Alps_SKRK
U1: LM5164-Q1; SOIC-8-1EP_3.9x4.9mm_P1.27mm_EP2.41x3.3mm
U2: ESP32-S3-WROOM-1U-N16R8; ESP32-S3-WROOM-1U
U3: ES8388_Codec; QFN-28-1EP_4x4mm_P0.4mm_EP2.4x2.4mm
U5: BMI270_IMU; LGA-14_2.5x3mm_P0.5mm
U6: TCAN334G; SOIC-8_3.9x4.9mm_P1.27mm
U8: DW3110; QFN-16-1EP_3x3mm_P0.5mm_EP1.7x1.7mm_ThermalVias
U9: QCC3084_BT54_AUDIO; Qualcomm_QCC3084_Module
U10: SX1262IMLTRT; QFN-24-1EP_4x4mm_P0.5mm_EP2.8x2.8mm
U11: TPS7A0533_LDO; SOT-23-5
Y1_UWB: 38.4MHz; Crystal_SMD_2016-4Pin_2.0x1.6mm

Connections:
AGND: U3.12, U3.15, U3.17
BST_BUCK: C3.1, U1.7
CAN_H: J1.4, R9.1, U6.7
CAN_L: J1.5, R9.2, U6.6
CAN_RX: U2.22, U6.4
CAN_TX: U2.21, U6.1
EN_BUCK: R1.2, R2.1, U1.2
ESP_BOOT: J3.8, SW1.1, U2.27
ESP_EN: J3.7, U2.3
GND_PWR: ANT1.2, ANT2.2, C1.2, C2.2, C4.2, C10.2, C11.2, C12.2, D1.2, D1.3, D2.2, J1.3, J1.7, J1.9, J1.11, J2.6, J2.SH1, J2.SH2, J2.SH3, J3.4, J3.9, J4.3, J5.2, J5.4, R2.2, SW1.2, U1.4, U1.9, U2.1, U2.26, U2.40, U2.41, U3.9, U3.29, U5.1, U5.2, U5.6, U5.7, U5.10, U5.11, U6.2, U6.8, U8.3, U8.6, U8.16, U8.17, U9.2, U9.8, U9.12, U10.8, U10.9, U10.11, U10.12, U10.22, U10.23, U10.24, U10.25, U11.2, Y1_UWB.2, Y1_UWB.4
GND_SHIELD: H1.1, H2.1, H3.1, H4.1, J1.12, J3.10
I2C_SCL: R11.2, U2.18, U3.6, U5.13
I2C_SDA: R10.2, U2.17, U3.7, U5.14
I2S_BCLK: U2.30, U3.2, U9.4
I2S_DIN: U2.16, U3.4, U9.7
I2S_DOUT: U2.15, U3.5, U9.6
I2S_MCLK: U2.12, U3.1, U9.3
I2S_WS: U2.32, U3.3, U9.5
KL30_IN: C1.1, D2.1, J1.1, R1.1, U1.1, U1.3
LORA_BUSY: U2.20, U10.14
LORA_DIO1: U2.19, U10.15
LORA_NSS: U2.24, U10.21
LORA_RF_868: ANT1.1, U10.10
LORA_RST: U2.23, U10.1
POD2_VCC: J1.8, J1.10
PORT1_KEY_MCU: R5.1, U2.8
PORT2_KEY_MCU: R6.1, U2.10
RGB_LED_DATA: D1.4, U2.28
SD_CD: J2.9, U2.39
SD_CLK: J2.5, U2.35
SD_CMD: J2.3, U2.36
SD_DAT0: J2.7, U2.37
SD_DAT1: J2.8, U2.33
SD_DAT2: J2.1, U2.34
SD_DAT3: J2.2, U2.38
SPI_MISO: U2.6, U8.8, U10.18
SPI_MOSI: U2.7, U8.9, U10.19
SPI_SCK: U2.4, U8.7, U10.20
SW_BUCK: C3.2, L1.1, U1.8
UART_RXD0: J3.6, U2.29
USB_D_N: J3.2, U2.13
USB_D_P: J3.3, U2.14
UWB_CS: U2.25, U8.10
UWB_IRQ: U2.31, U8.13
UWB_RF_CH5: ANT2.1, U8.15
UWB_XTAL1: U8.4, Y1_UWB.1
UWB_XTAL2: U8.5, Y1_UWB.3
VCC_3V3: C10.1, C11.1, C12.1, J2.4, R10.1, R11.1, U2.2, U3.8, U3.16, U3.28, U5.3, U5.5, U5.8, U5.12, U6.3, U8.14, U9.1, U10.6, U10.13, U10.17, U11.5
VCC_5V: C2.1, D1.1, J3.1, J4.1, L1.2, U1.5, U11.1, U11.3
VCC_BUCK: C4.1, U1.6

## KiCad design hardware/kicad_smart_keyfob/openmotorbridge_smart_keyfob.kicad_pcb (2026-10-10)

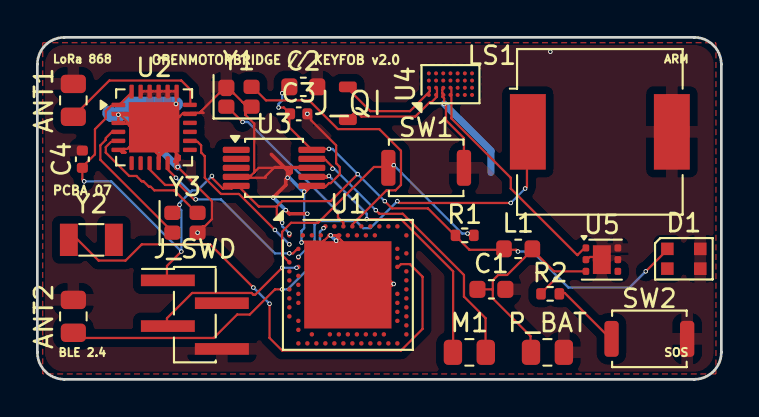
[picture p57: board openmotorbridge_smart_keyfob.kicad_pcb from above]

Board: 2 copper layers, 38.0 x 19.0 mm, 25 parts (0 on the bottom side), 21 nets.

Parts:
ANT1: 868MHz_CHIP_ANT; R_0805_2012Metric
ANT2: 2.4GHz_BLE_ANT; R_0805_2012Metric
C1: 10uF_VBAT; C_0603_1608Metric
C2: 10uF_3V3; C_0603_1608Metric
C3: 100nF_MCU; C_0402_1005Metric
C4: 100nF_LORA; C_0402_1005Metric
D1: WS2812B-2020; LED_WS2812B-2020_PLCC4_2.0x2.0mm
J_QI: QI_COIL_ACH_2P
J_SWD: SWD_PROG; PinHeader_1x04_P1.27mm_Vertical_SMD_Pin1Left
L1: 4.7uH_DCDC; L_0603_1608Metric
LS1: CPT-9019S_BUZZER; Buzzer_CUI_CPT-9019S-SMT
M1: LRA_MOTOR_PADS; R_0805_2012Metric
P_BAT: LIPO_BAT_PADS; R_0805_2012Metric
R1, R2: 10k_PULLUP; R_0402_1005Metric
SW1: BTN_ARM; SW_Push_SPST_NO_Alps_SKRK
SW2: BTN_SOS; SW_Push_SPST_NO_Alps_SKRK
U1: nRF52840-QIAA; Nordic_AQFN-73-1EP_7x7mm_P0.5mm
U2: SX1262IMLTRT; QFN-24-1EP_4x4mm_P0.5mm_EP2.8x2.8mm
U3: DRV2605LDGSR; MSOP-10_3x3mm_P0.5mm
U4: BQ51003YFPR; Texas_DSBGA-28_1.9x3mm_Layout4x7_P0.4mm
U5: BQ25100YFPR; WSON-6-1EP_2x2mm_P0.65mm_EP1x1.6mm
Y1: 32.000MHz; Crystal_SMD_2016-4Pin_2.0x1.6mm
Y2: 32.768kHz; Crystal_SMD_3215-2Pin_3.2x1.5mm
Y3: 32MHz_TCXO; Crystal_SMD_2016-4Pin_2.0x1.6mm

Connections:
BLE_ANT_50R: ANT2.1, U1.A8
BTN_ARM_N: R1.2, SW1.1, U1.G1
BTN_SOS_N: R2.2, SW2.1
BUZZER_PWM: LS1.1, U1.F2
GND: ANT1.2, ANT2.2, C1.2, C2.2, C3.2, C4.2, D1.3, D1.4, J_SWD.4, LS1.2, P_BAT.2, SW1.2, SW2.2, U1.B9, U1.B11, U1.EP, U2.2, U2.3, U2.6, U2.10, U2.12, U2.17, U2.19, U2.20, U2.21, U2.22, U2.23, U2.25, U3.4, U3.6, U3.8, U4.C1, U4.C2, U5.2, U5.5, U5.6, U5.7, Y1.2, Y1.4, Y3.2
LORA_ANT_50R: ANT1.1, U2.18
LORA_DIO1: U1.D2, U2.9
LORA_SCK: U1.C1, U2.14
LRA_NEG: M1.2, U3.9
LRA_POS: M1.1, U3.7
QI_AC1: J_QI.1, U4.A1, U4.A2
QI_AC2: J_QI.2, U4.B1, U4.B2
RTC2: U1.H23, Y2.2
SWDCLK: J_SWD.3, U1.H2
TCXO_IN: U2.4, Y3.1
TCXO_OUT: U2.5, Y3.3
VBAT: C1.1, L1.2, P_BAT.1, U5.3
VCC_3V3: C2.1, C3.1, C4.1, D1.1, J_SWD.1, L1.1, R1.1, R2.1, U1.B1, U2.1, U2.11, U2.24, U3.5, U3.10, Y3.4
VCC_QI_5V: U4.D1, U4.D2, U5.1
XTAL1: U1.A12, Y1.1
XTAL2: U1.A14, Y1.3

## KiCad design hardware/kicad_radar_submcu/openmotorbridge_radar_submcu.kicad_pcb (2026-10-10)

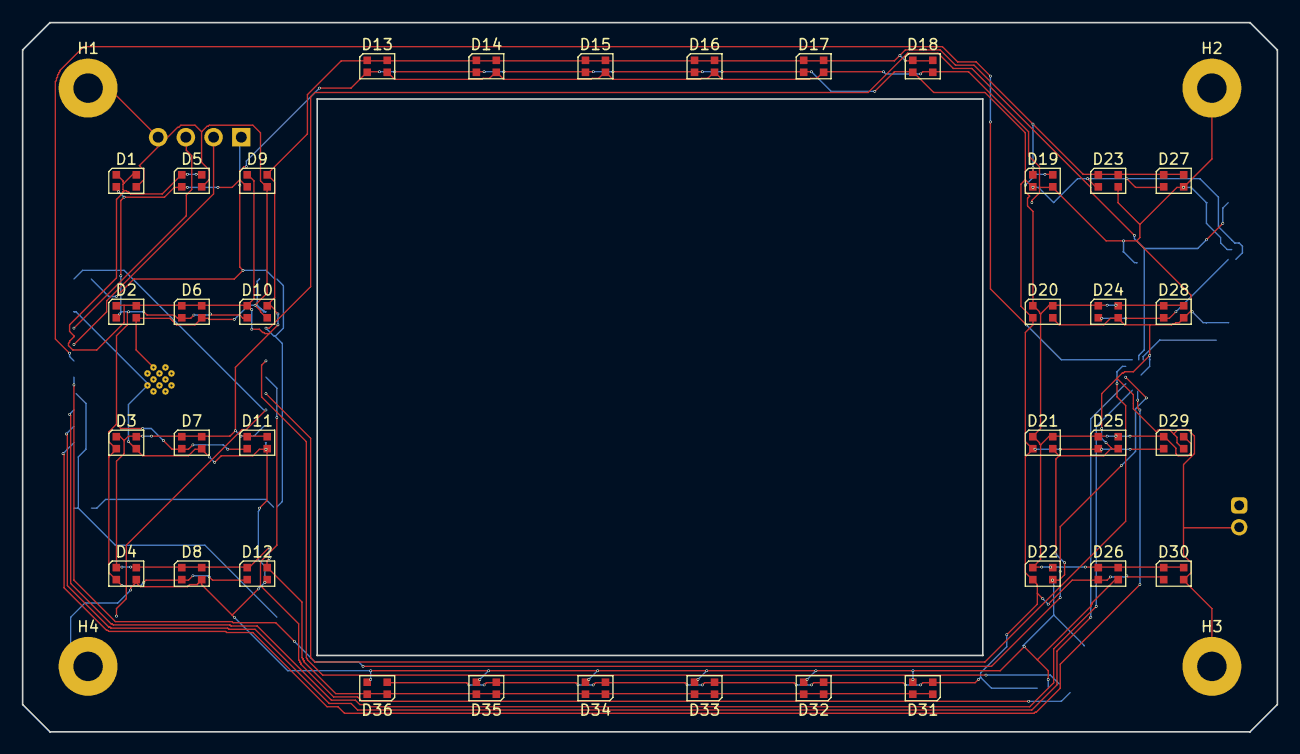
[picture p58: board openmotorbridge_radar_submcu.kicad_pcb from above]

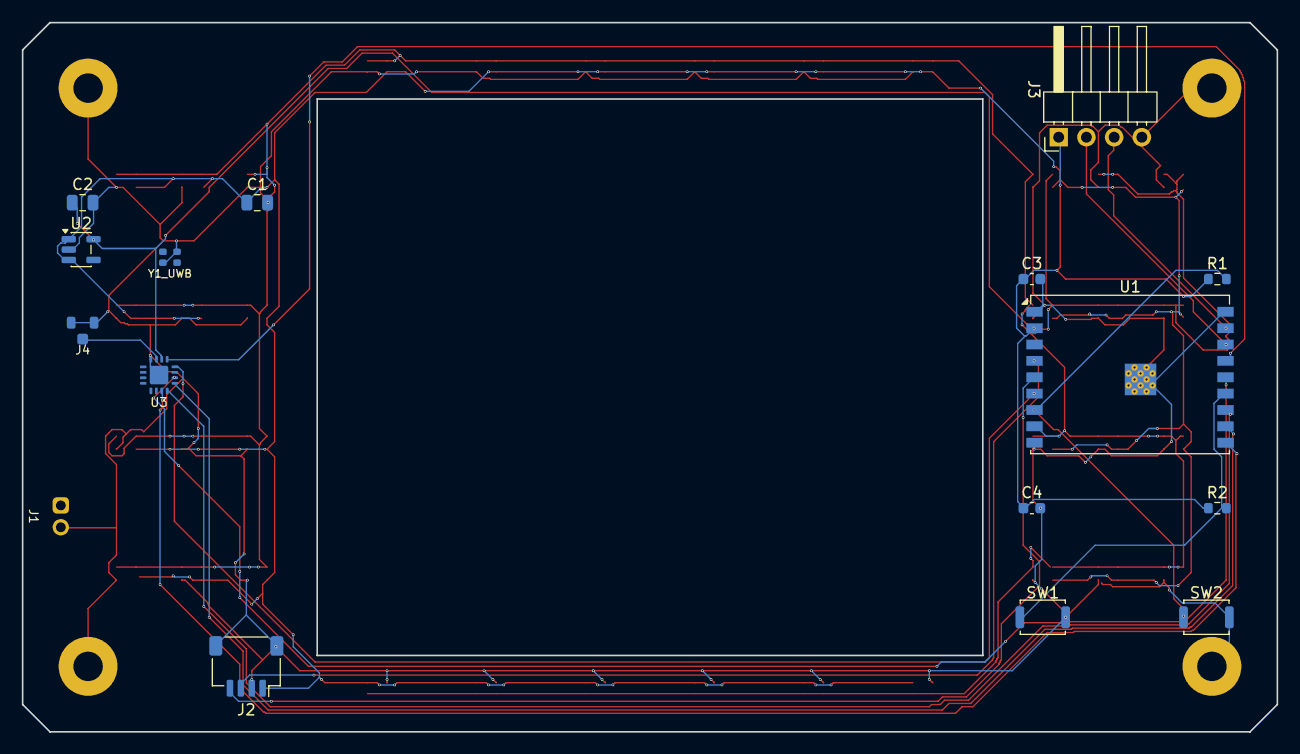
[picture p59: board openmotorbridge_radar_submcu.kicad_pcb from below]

Board: 2 copper layers, 115.0 x 65.0 mm, 56 parts (16 on the bottom side), 17 nets.

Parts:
C1: 10uF_16V; C_0805_2012Metric
C2: 10uF_10V; C_0805_2012Metric
C3, C4: 100nF; C_0603_1608Metric
D1, D2, D3, D4, D5, D6, D7, D8, D9, D10, D11, D12, D13, D14, D15, D16, D17, D18, D19, D20, D21, D22, D23, D24, D25, D26, D27, D28, D29, D30, D31, D32, D33, D34, D35, D36: WS2812B-2020; LED_WS2812B-2020_PLCC4_2.0x2.0mm
H1, H2, H3, H4: M2.5_MountingHole; MountingHole_2.7mm_M2.5_Pad
J1: 12V_RADAR_PWR; JST_JWPF_B02B-JWPF-SK-R_1x02_P2.00mm_Vertical
J2: JST_SH_4P_MR20; JST_SH_SM04B-SRSS-TB_1x04-1MP_P1.00mm_Horizontal
J3: PROG_UART_4P; PinHeader_1x04_P2.54mm_Horizontal
J4: Taoglas_FXUWB10; U.FL_Hirose_U.FL-R-SMT-1_Vertical
R1, R2: 10k; R_0603_1608Metric
SW1: BOOT_SW; SW_Push_SPST_NO_Alps_SKRK
SW2: RESET_SW; SW_Push_SPST_NO_Alps_SKRK
U1: ESP32-C5-WROOM-1U; ESP32-C3-WROOM-02U
U2: TPS7A0533; SOT-23-5
U3: DW3110; QFN-16-1EP_3x3mm_P0.5mm_EP1.7x1.7mm_ThermalVias
Y1_UWB: 38.4MHz; Crystal_SMD_2016-4Pin_2.0x1.6mm

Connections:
CENTRAL_RX: J3.3, U1.17
CENTRAL_TX: J3.2, U1.16
ESP_EN: R1.2, SW2.1, U1.7
ESP_IO9_BOOT: R2.2, SW1.1, U1.13
GND: C1.2, C2.2, C3.2, C4.2, D1.3, D2.3, D3.3, D4.3, D5.3, D6.3, D7.3, D8.3, D9.3, D10.3, D11.3, D12.3, D13.3, D14.3, D15.3, D16.3, D17.3, D18.3, D19.3, D20.3, D21.3, D22.3, D23.3, D24.3, D25.3, D26.3, D27.3, D28.3, D29.3, D30.3, D31.3, D32.3, D33.3, D34.3, D35.3, D36.3, H1.1, H2.1, H3.1, H4.1, J1.2, J2.2, J2.MP, J3.4, J4.2, SW1.2, SW2.2, U1.1, U1.9, U1.18, U1.19, U2.2, U3.16, U3.17, Y1_UWB.2, Y1_UWB.4
MR20_RX: J2.4, U1.5
MR20_TX: J2.3, U1.4
UWB_CS: U1.14, U3.10
UWB_IRQ: U1.15, U3.13
UWB_MISO: U1.12, U3.8
UWB_MOSI: U1.11, U3.9
UWB_RF: J4.1, U3.15
UWB_RST: U1.6, U3.12
UWB_SCK: U1.10, U3.7
VCC_3V3: C2.1, C3.1, C4.1, J3.1, R1.1, R2.1, U1.2, U2.5, U3.14
VCC_5V: C1.1, D1.2, D2.2, D3.2, D4.2, D5.2, D6.2, D7.2, D8.2, D9.2, D10.2, D11.2, D12.2, D13.2, D14.2, D15.2, D16.2, D17.2, D18.2, D19.2, D20.2, D21.2, D22.2, D23.2, D24.2, D25.2, D26.2, D27.2, D28.2, D29.2, D30.2, D31.2, D32.2, D33.2, D34.2, D35.2, D36.2, J2.1, U2.1, U2.3
WS2812_DATA: D1.1, D1.4, D2.1, D2.4, D3.1, D3.4, D4.1, D4.4, D5.1, D5.4, D6.1, D6.4, D7.1, D7.4, D8.1, D8.4, D9.1, D9.4, D10.1, D10.4, D11.1, D11.4, D12.1, D12.4, D13.1, D13.4, D14.1, D14.4, D15.1, D15.4, D16.1, D16.4, D17.1, D17.4, D18.1, D18.4, D19.1, D19.4, D20.1, D20.4, D21.1, D21.4, D22.1, D22.4, D23.1, D23.4, D24.1, D24.4, D25.1, D25.4, D26.1, D26.4, D27.1, D27.4, D28.1, D28.4, D29.1, D29.4, D30.1, D30.4, D31.1, D31.4, D32.1, D32.4, D33.1, D33.4, D34.1, D34.4, D35.1, D35.4, D36.1, D36.4, U1.8

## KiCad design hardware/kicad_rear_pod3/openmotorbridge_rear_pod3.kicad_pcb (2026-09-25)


Board: 4 copper layers, 55.0 x 48.0 mm, 20 parts (0 on the bottom side), 20 nets.

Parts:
C1: 10uF_3V3; C_0805_2012Metric
C2: 100nF_MCU; C_0603_1608Metric
C3: 100nF_GNSS; C_0603_1608Metric
C4: 100nF_LoRa; C_0603_1608Metric
D1: LED_Green_5V; LED_0805_2012Metric
F1: PTC_500mA; R_1206_3216Metric
H1, H2, H3, H4: M2_Mounting_Hole; MountingHole_2.2mm_M2_Pad
J1: 6-Pin_OMM_Female_Socket; PinSocket_1x06_P2.54mm_Horizontal
J4: U.FL_LORA; U.FL_Hirose_U.FL-R-SMT-1_Vertical
J5: U.FL_GNSS; U.FL_Hirose_U.FL-R-SMT-1_Vertical
J6: DS18B20_EXT_TEMP; JST_SH_SM03B-SRSS-TB_1x03-1MP_P1.00mm_Horizontal
R1: 1.5k_LED_Resistor; R_0603_1608Metric
R2: 4.7k; R_0603_1608Metric
U1: ESP32-C3-WROOM-02U
U2: MAX-M10S_GNSS; ublox_MAX
U3: SX1262_LoRa_+22dBm; QFN-24-1EP_4x4mm_P0.5mm_EP2.6x2.6mm
U4: DS2401_1Wire_ID; SOT-23

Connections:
GND: C1.2, C2.2, C3.2, C4.2, D1.2, H1.1, H2.1, H3.1, H4.1, J1.2, J4.2, J5.2, J6.3, J6.MP, U1.16, U1.17, U1.18, U1.19, U2.1, U2.5, U2.6, U2.9, U2.10, U2.12, U2.13, U2.14, U2.15, U2.16, U2.17, U2.18, U3.2, U3.3, U3.4, U3.8, U3.9, U3.11, U3.12, U3.19, U3.20, U3.22, U3.23, U3.25, U4.2
GNSS_1PPS: J1.5, U1.3, U2.4
GNSS_RF_IN: J5.1, U2.11
GNSS_RXD: U1.8, U2.3
GNSS_TXD: U1.9, U2.2
LORA_BUSY: U1.5, U3.6
LORA_DIO1: U1.4, U3.7
LORA_MISO: U1.11, U3.16
LORA_MOSI: U1.12, U3.15
LORA_NRST: U1.14, U3.5
LORA_NSS: U1.13, U3.13
LORA_RF_ANT: J4.1, U3.17, U3.21
LORA_SCK: U1.10, U3.14
NET_F1_5V: F1.2, R1.1
NET_LED_R: D1.1, R1.2
POD3_1WIRE_ID: J1.6, J6.2, R2.2, U4.1
POD3_UART_RX: J1.4, U1.7
POD3_UART_TX: J1.3, U1.6
POD3_VCC_5V: F1.1, J1.1
VCC_3V3: C1.1, C2.1, C3.1, C4.1, J6.1, R2.1, U1.1, U2.7, U2.8, U3.1, U3.10, U3.18, U3.24

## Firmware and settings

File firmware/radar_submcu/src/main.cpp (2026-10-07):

#include <stdio.h>
#include <string.h>
#include <math.h>
#include "freertos/FreeRTOS.h"
#include "freertos/task.h"
#include "freertos/semphr.h"
#include "driver/uart.h"
#include "driver/gpio.h"
#include "esp_timer.h"
#include "esp_log.h"
#include "esp_system.h"
#include "radar_mr20_protocol.h"
#include "uwb_vehicle_backbone.h"
#include "uwb_backbone_types.h"

static const char *TAG = "RADAR2_SUBMCU";

// Pinout for Radar 2.0 Sub-MCU (PCBA 08: ESP32-C5 Dual-Band & DW3110)
#define UART_MR20_PORT              UART_NUM_1
#define PIN_MR20_TX                 GPIO_NUM_4  // to Wheeltec MR20 RX
#define PIN_MR20_RX                 GPIO_NUM_5  // from Wheeltec MR20 TX
#define MR20_BAUDRATE               115200

#define PIN_UWB_SCK                 GPIO_NUM_0  // DW3110 SPI SCK
#define PIN_UWB_MOSI                GPIO_NUM_1  // DW3110 SPI MOSI
#define PIN_UWB_MISO                GPIO_NUM_2  // DW3110 SPI MISO
#define PIN_UWB_CS                  GPIO_NUM_3  // DW3110 SPI CS
#define PIN_UWB_IRQ                 GPIO_NUM_6  // DW3110 IRQ
#define PIN_UWB_RST                 GPIO_NUM_7  // DW3110 RST

#define PIN_NEOPIXEL                GPIO_NUM_8  // WS2812B-2020 Data line
#define NUM_LEDS                    36          // 36-LED Visual Warning Wings (18 Left, 18 Right)
#define WING_LEDS                   18          // 18 LEDs per wing (Left: 0..17, Right: 18..35)

static SemaphoreHandle_t s_radar_data_mutex = NULL;
static RadarTelemetryPacket_t s_current_telemetry;
static RadarCommandPacket_t s_current_command;
static uint16_t s_radar_frame_index = 0;
static uint32_t s_last_mr20_rx_time_ms = 0;

// Configurable Warning Macros & State Management
static uint16_t s_enabled_macros = (RADAR_MACRO_POST_SWEEP_EN | RADAR_MACRO_ESS_STROBE_EN |
                                    RADAR_MACRO_HAZARD_BEACON_EN | RADAR_MACRO_THEFT_STROBE_EN |
                                    RADAR_MACRO_AMBIENT_GLOW_EN);
static uint8_t s_ess_thresh_pct = 60;
static uint32_t s_post_start_ms = 0;
static bool s_post_running = true;
static bool s_diag_override = false;
static uint8_t s_diag_led_states[NUM_LEDS];

// Neopixel color state
typedef struct {
    uint8_t r;
    uint8_t g;
    uint8_t b;
} RgbColor_t;

static RgbColor_t s_led_buffer[NUM_LEDS];

static void update_neopixel_halo(void) {
    // In hardware this drives the 36 WS2812B LEDs via RMT/SPI-MOSI on GPIO 8
}

static void init_uarts(void) {
    // Wheeltec MR20 Sensor UART
    const uart_config_t mr20_uart_config = {
        .baud_rate = MR20_BAUDRATE,
        .data_bits = UART_DATA_8_BITS,
        .parity = UART_PARITY_DISABLE,
        .stop_bits = UART_STOP_BITS_1,
        .flow_ctrl = UART_HW_FLOWCTRL_DISABLE,
        .source_clk = UART_SCLK_DEFAULT,
    };
    uart_param_config(UART_MR20_PORT, &mr20_uart_config);
    uart_set_pin(UART_MR20_PORT, PIN_MR20_TX, PIN_MR20_RX, UART_PIN_NO_CHANGE, UART_PIN_NO_CHANGE);
    uart_driver_install(UART_MR20_PORT, 1024, 0, 0, NULL, 0);

    ESP_LOGI(TAG, "Wheeltec MR20 UART1 initialized on GPIO %d (TX) / %d (RX).", PIN_MR20_TX, PIN_MR20_RX);
}

// Parse Wheeltec MR20 77-GHz raw mmWave clusters
static void parse_mr20_frame(const uint8_t *buf, size_t len) {
    if (len < 5) return;

    for (size_t i = 0; i < len - 4; i++) {
        if (buf[i] == MR20_RAW_HEADER_1 && buf[i + 1] == MR20_RAW_HEADER_2) {
            uint8_t frame_len = buf[i + 2];
            uint8_t frame_type = buf[i + 3];

            if (i + frame_len <= len && frame_type == MR20_FRAME_TARGET_LIST) {
                uint8_t target_count = buf[i + 4];
                if (target_count > MR20_MAX_TARGETS) target_count = MR20_MAX_TARGETS;

                if (s_radar_data_mutex && xSemaphoreTake(s_radar_data_mutex, pdMS_TO_TICKS(5)) == pdTRUE) {
                    s_current_telemetry.target_count = target_count;
                    s_last_mr20_rx_time_ms = (uint32_t)(esp_timer_get_time() / 1000ULL);

                    for (uint8_t t = 0; t < target_count; t++) {
                        size_t offset = i + 5 + (t * 8);
                        if (offset + 8 <= len) {
                            uint8_t id = buf[offset];
                            int16_t dist_raw = (int16_t)((buf[offset + 1] << 8) | buf[offset + 2]);
                            int16_t speed_raw = (int16_t)((buf[offset + 3] << 8) | buf[offset + 4]);
                            int16_t azim_raw = (int16_t)((buf[offset + 5] << 8) | buf[offset + 6]);
                            uint8_t snr = buf[offset + 7];

                            s_current_telemetry.targets[t].target_id = id;
                            s_current_telemetry.targets[t].distance_cm = (uint16_t)(dist_raw * 10);
                            s_current_telemetry.targets[t].rel_speed_mps_100 = speed_raw;
                            s_current_telemetry.targets[t].azimuth_deg_10 = azim_raw;
                            s_current_telemetry.targets[t].snr_db = snr;

                            // Calculate TTC (Time to collision) in milliseconds
                            if (speed_raw < -50 && dist_raw > 0) { // Approaching vehicle (relative speed negative)
                                float dist_m = (float)dist_raw * 0.1f;
                                float speed_mps = fabsf((float)speed_raw * 0.01f);
                                float ttc_s = dist_m / speed_mps;
                                s_current_telemetry.targets[t].ttc_ms = (uint16_t)(ttc_s * 1000.0f);

                                if (ttc_s < 1.5f) {
                                    s_current_telemetry.targets[t].threat_level = RADAR_THREAT_LVL_RED;
                                } else if (ttc_s < 3.0f) {
                                    s_current_telemetry.targets[t].threat_level = RADAR_THREAT_LVL_AMBER;
                                } else {
                                    s_current_telemetry.targets[t].threat_level = RADAR_THREAT_LVL_NONE;
                                }
                            } else {
                                s_current_telemetry.targets[t].ttc_ms = 0xFFFF; // No collision threat
                                s_current_telemetry.targets[t].threat_level = RADAR_THREAT_LVL_NONE;
                            }
                        }
                    }
                    xSemaphoreGive(s_radar_data_mutex);
                }
                break;
            }
        }
    }
}

// Task 1: Wheeltec MR20 UART Receiver Task (Core 0, 50 Hz)
static void task_mr20_rx(void *arg) {
    ESP_LOGI(TAG, "Wheeltec MR20 RX Task running at 50 Hz...");
    uint8_t rx_buffer[512];

    while (true) {
        int bytes_read = uart_read_bytes(UART_MR20_PORT, rx_buffer, sizeof(rx_buffer), pdMS_TO_TICKS(20));
        if (bytes_read > 0) {
            parse_mr20_frame(rx_buffer, bytes_read);
        }

        // Sensor Watchdog
        uint32_t now_ms = (uint32_t)(esp_timer_get_time() / 1000ULL);
        if (now_ms - s_last_mr20_rx_time_ms > 1000) {
            if (s_radar_data_mutex && xSemaphoreTake(s_radar_data_mutex, pdMS_TO_TICKS(5)) == pdTRUE) {
                s_current_telemetry.sensor_state = RADAR_SENSOR_STATE_ERROR;
                s_current_telemetry.target_count = 0;
                xSemaphoreGive(s_radar_data_mutex);
            }
        }
        vTaskDelay(pdMS_TO_TICKS(10));
    }
}

// Task 2: Neopixel Dual-Wing Warning Lighting Task (40 Hz refresh rate)
static void task_neopixel_halo(void *arg) {
    ESP_LOGI(TAG, "Neopixel Halo Task running at 40 Hz (36 WS2812B LEDs)...");
    uint32_t frame_count = 0;

    while (true) {
        uint8_t max_threat = RADAR_THREAT_LVL_NONE;
        uint16_t enabled_macros = 0;
        uint8_t brightness_pct = 100;
        bool bsd_left = false;
        bool bsd_right = false;

        if (s_radar_data_mutex && xSemaphoreTake(s_radar_data_mutex, pdMS_TO_TICKS(5)) == pdTRUE) {
            for (uint8_t t = 0; t < s_current_telemetry.target_count; t++) {
                if (s_current_telemetry.targets[t].threat_level > max_threat) {
                    max_threat = s_current_telemetry.targets[t].threat_level;
                }
                if (s_current_telemetry.targets[t].threat_level >= RADAR_THREAT_LVL_AMBER) {
                    if (s_current_telemetry.targets[t].azimuth_deg_10 < -100) bsd_left = true;
                    if (s_current_telemetry.targets[t].azimuth_deg_10 > 100)  bsd_right = true;
                }
            }
            enabled_macros = s_enabled_macros;
            brightness_pct = s_current_command.dimming_pwm_pct;
            bsd_left = bsd_left || s_current_command.bsd_left_active;
            bsd_right = bsd_right || s_current_command.bsd_right_active;
            xSemaphoreGive(s_radar_data_mutex);
        }

        float brightness_scale = (float)brightness_pct / 100.0f;

        // Threat Warning on Dual Wings (Directional BSD & TTC Level)
        if (max_threat == RADAR_THREAT_LVL_RED || max_threat == RADAR_THREAT_LVL_AMBER) {
            bool strobe = (frame_count % 3) == 0;
            uint8_t target_r = (uint8_t)(255 * brightness_scale);
            uint8_t target_g = (max_threat == RADAR_THREAT_LVL_AMBER) ? (uint8_t)(140 * brightness_scale) : 0;
            uint8_t base_r = (uint8_t)(40 * brightness_scale);

            // Left Wing (LEDs 0..17)
            bool flash_left = bsd_left || (!bsd_right);
            for (int i = 0; i < WING_LEDS; i++) {
                if (flash_left && (strobe || max_threat == RADAR_THREAT_LVL_AMBER)) {
                    s_led_buffer[i].r = target_r;
                    s_led_buffer[i].g = target_g;
                    s_led_buffer[i].b = 0;
                } else {
                    s_led_buffer[i].r = base_r;
                    s_led_buffer[i].g = 0;
                    s_led_buffer[i].b = 0;
                }
            }

            // Right Wing (LEDs 18..35)
            bool flash_right = bsd_right || (!bsd_left);
            for (int i = WING_LEDS; i < NUM_LEDS; i++) {
                if (flash_right && (strobe || max_threat == RADAR_THREAT_LVL_AMBER)) {
                    s_led_buffer[i].r = target_r;
                    s_led_buffer[i].g = target_g;
                    s_led_buffer[i].b = 0;
                } else {
                    s_led_buffer[i].r = base_r;
                    s_led_buffer[i].g = 0;
                    s_led_buffer[i].b = 0;
                }
            }
        } else if (enabled_macros & RADAR_MACRO_AMBIENT_GLOW_EN) {
            uint8_t base_r = (uint8_t)(50 * brightness_scale);
            for (int i = 0; i < NUM_LEDS; i++) {
                s_led_buffer[i].r = base_r;
                s_led_buffer[i].g = 0;
                s_led_buffer[i].b = 0;
            }
        } else {
            for (int i = 0; i < NUM_LEDS; i++) {
                s_led_buffer[i].r = 0;
                s_led_buffer[i].g = 0;
                s_led_buffer[i].b = 0;
            }
        }

        update_neopixel_halo();
        frame_count++;
        vTaskDelay(pdMS_TO_TICKS(25)); // 40 Hz refresh rate
    }
}

// Task 3: UWB Radar Backbone Bridge Task (20 Hz Transmission to Central Box)
static void task_uwb_radar_bridge(void *arg) {
    ESP_LOGI(TAG, "All-UWB Radar Backbone Bridge running at 20 Hz...");
    uint32_t heartbeat_counter = 0;

    while (true) {
        UwbRadarTargetsPkt uwb_pkt = {};
        uwb_pkt.frame_index = s_radar_frame_index++;

        if (s_radar_data_mutex && xSemaphoreTake(s_radar_data_mutex, pdMS_TO_TICKS(10)) == pdTRUE) {
            uwb_pkt.target_count = s_current_telemetry.target_count;
            if (uwb_pkt.target_count > UWB_RADAR_MAX_TARGETS) {
                uwb_pkt.target_count = UWB_RADAR_MAX_TARGETS;
            }

            for (uint8_t t = 0; t < uwb_pkt.target_count; t++) {
                uwb_pkt.targets[t].target_id = s_current_telemetry.targets[t].target_id;
                uwb_pkt.targets[t].distance_cm = s_current_telemetry.targets[t].distance_cm;
                uwb_pkt.targets[t].speed_cm_s = s_current_telemetry.targets[t].rel_speed_mps_100;
                uwb_pkt.targets[t].azimuth_deg_10 = s_current_telemetry.targets[t].azimuth_deg_10;
                uwb_pkt.targets[t].ttc_ms = s_current_telemetry.targets[t].ttc_ms;
                uwb_pkt.targets[t].threat_level = s_current_telemetry.targets[t].threat_level;

                if (s_current_telemetry.targets[t].threat_level >= RADAR_THREAT_LVL_RED) {
                    uwb_pkt.urgent_flag = 1;
                }
            }
            xSemaphoreGive(s_radar_data_mutex);
        }

        // 1. Transmit 20 Hz Radar Target List to Central Box via UWB
        UwbVehicleBackbone::instance().send_radar_targets(uwb_pkt);

        // 2. Periodic UWB Heartbeat (every 500 ms)
        heartbeat_counter++;
        if (heartbeat_counter >= 10) { // 10 * 50 ms = 500 ms
            heartbeat_counter = 0;
            UwbVehicleBackbone::instance().send_heartbeat(5000, 200);
        }

        vTaskDelay(pdMS_TO_TICKS(50)); // 20 Hz cycle
    }
}

// -----------------------------------------------------------------------------
// Main Application Entry Point
// -----------------------------------------------------------------------------
extern "C" void app_main(void) {
    ESP_LOGI(TAG, "============================================================");
    ESP_LOGI(TAG, "   OPENMOTORBRIDGE RADAR 2.0 SUB-MCU v3.0                   ");
    ESP_LOGI(TAG, "   Target: ESP32-C5 Dual-Band (PCBA 08 mmWave Wings)       ");
    ESP_LOGI(TAG, "   All-UWB Deterministic Backbone (Qorvo DW3110 / 6.5 GHz)  ");
    ESP_LOGI(TAG, "============================================================");

    s_radar_data_mutex = xSemaphoreCreateMutex();
    memset(&s_current_telemetry, 0, sizeof(s_current_telemetry));
    memset(&s_current_command, 0, sizeof(s_current_command));
    s_current_command.dimming_pwm_pct = 100;
    s_post_start_ms = (uint32_t)(esp_timer_get_time() / 1000ULL);
    s_post_running = true;

    // 0. HF Hardening: 2.4 GHz Wi-Fi & BLE are strictly disabled & uninitialized at the vehicle rear.
    // RF is strictly limited to 6.5 GHz UWB (Qorvo DW3110) & 5.9 GHz V2X (Taoglas patch antenna).
    ESP_LOGI(TAG, "HF Hardening verified: 2.4 GHz disabled. 6.5 GHz UWB & 5.9 GHz V2X active.");

    // 1. Initialize Wheeltec MR20 UART
    init_uarts();

    // 2. Initialize All-UWB Backbone (Node-ID 0x05)
    dw3110_config_t dw_cfg = {
        .spi_host = SPI2_HOST,
        .pin_sck  = PIN_UWB_SCK,
        .pin_mosi = PIN_UWB_MOSI,
        .pin_miso = PIN_UWB_MISO,
        .pin_cs   = PIN_UWB_CS,
        .pin_irq  = PIN_UWB_IRQ,
        .pin_rst  = PIN_UWB_RST,
        .pan_id   = UWB_BACKBONE_PAN_ID,
        .short_addr = static_cast<uint16_t>(UWB_NODE_REAR_RADAR)
    };

    UwbVehicleBackbone::instance().init(UWB_NODE_REAR_RADAR, &dw_cfg);
    UwbVehicleBackbone::instance().set_radar_led_callback([](const UwbRadarLedCmdPkt &cmd) {
        if (s_radar_data_mutex && xSemaphoreTake(s_radar_data_mutex, pdMS_TO_TICKS(10)) == pdTRUE) {
            s_current_command.macro_mode = cmd.macro_mode;
            s_current_command.dimming_pwm_pct = cmd.brightness_pct;
            s_current_command.bsd_left_active = (cmd.left_bsd_state != 0);
            s_current_command.bsd_right_active = (cmd.right_bsd_state != 0);
            xSemaphoreGive(s_radar_data_mutex);
        }
    });
    UwbVehicleBackbone::instance().start_task(22, 0);

    // 3. Spawn FreeRTOS Tasks
    xTaskCreate(task_mr20_rx, "mr20_rx", 4096, NULL, 5, NULL);
    xTaskCreate(task_neopixel_halo, "neopixel_halo", 3072, NULL, 4, NULL);
    xTaskCreate(task_uwb_radar_bridge, "uwb_radar_tx", 4096, NULL, 6, NULL);

    ESP_LOGI(TAG, "Radar 2.0 Sub-MCU initialized and active on UWB Node 0x05.");
}

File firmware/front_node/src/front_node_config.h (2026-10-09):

#pragma once

#include "driver/gpio.h"

// =============================================================================
// OpenMotorBridge - Universal Front Node (PCBA 05) Pinout & Configuration
// =============================================================================

// --- 1. GPIO Pin Assignments (ESP32-S3 on PCBA 05) ---
#define PIN_BOOT_BUTTON         GPIO_NUM_0   // Boot/Config Tactile Button SW1 (Active Low)
#define PIN_OTTOCAST_PWR_EN     GPIO_NUM_1   // TI TPS2051B USB VBUS Power Enable (Active High)
#define PIN_OTTOCAST_FAULT_N    GPIO_NUM_2   // TI TPS2051B Fault Alert (Active Low, Open-Drain)
#define PIN_CAN_TERM_EN         GPIO_NUM_3   // CPC1017N Solid-State Relay for 120R CAN Termination (Auto-Sensing)
#define PIN_KL15_SENSE          GPIO_NUM_4   // 12V Ignition KL15 Sense via voltage divider
#define PIN_CAN_SILENT          GPIO_NUM_5   // TI TCAN334G Pin 8 Silent / Listen-Only Mode
#define PIN_MIC_I2S_WS          GPIO_NUM_6   // MSM261S4030H0R / SPH0645 I2S Word Select / LRCLK
#define PIN_MIC_I2S_BCLK        GPIO_NUM_7   // MSM261S4030H0R / SPH0645 I2S Bit Clock
#define PIN_MIC_I2S_DATA        GPIO_NUM_8   // MSM261S4030H0R / SPH0645 I2S Serial Data
#define PIN_I2C_SDA             GPIO_NUM_9   // Qwiic J12 I2C SDA
#define PIN_I2C_SCL             GPIO_NUM_10  // Qwiic J12 I2C SCL
#define PIN_WS2812B_DIN         GPIO_NUM_11  // Onboard WS2812B-2020 RGB Status LED (Light-pipe in lid)
#define PIN_BSD_LED_LEFT        GPIO_NUM_12  // Left Mirror Radar BSD Warning LED Gate (DMN63D8 Ch A)
#define PIN_BSD_LED_RIGHT       GPIO_NUM_13  // Right Mirror Radar BSD Warning LED Gate (DMN63D8 Ch B)
#define PIN_AUX_LIGHT_EN        GPIO_NUM_14  // TPS1H100 High-Side Switch (J11 Aux Light / Strobe)
#define PIN_PTT_IN1_N           GPIO_NUM_15  // Handlebar Button 1: Intercom PTT (Active Low)
#define PIN_PTT_IN2_N           GPIO_NUM_16  // Handlebar Button 2: Action-Cam Bookmark / Highlight (Active Low)
#define PIN_PTT_IN3_N           GPIO_NUM_17  // Handlebar Button 3: Media Next / Siri / Voice (Active Low)
#define PIN_USB_DM              GPIO_NUM_19  // Native USB D- (Service / Flash Port J7)
#define PIN_USB_DP              GPIO_NUM_20  // Native USB D+ (Service / Flash Port J7)
#define PIN_CAN_TX              GPIO_NUM_21  // TCAN334G TWAI / CAN Transmitter
#define PIN_CAN_RX              GPIO_NUM_47  // TCAN334G TWAI / CAN Receiver

// Legacy alias for single PTT button compatibility
#define PIN_PTT_INPUT_N         PIN_PTT_IN1_N

// --- 2. ESP-NOW Wireless Bridge & Cockpit Wi-Fi SoftAP Constants ---
#define ESPNOW_WIFI_CHANNEL         1
#define ESPNOW_MAX_PAYLOAD          250
#define FRONT_NODE_PROTOCOL_VER     0x02

// Cockpit Wi-Fi Fallback SoftAP Configuration (WIFI_MODE_APSTA on Channel 1)
#define COCKPIT_WIFI_AP_SSID        "OpenMotorBridge-Gateway"
#define COCKPIT_WIFI_AP_PASS        "openmotor2024"
#define COCKPIT_WIFI_AP_CHANNEL     ESPNOW_WIFI_CHANNEL   // Channel 1: Zero RF switching jitter with ESP-NOW
#define COCKPIT_WIFI_AP_MAX_CONN    4
#define COCKPIT_WIFI_AP_IP          "192.168.4.1"
#define COCKPIT_WIFI_AP_GW          "192.168.4.1"
#define COCKPIT_WIFI_AP_NETMASK     "255.255.255.0"
#define COCKPIT_WIFI_IP_RIDER_PHONE "192.168.4.10"
#define COCKPIT_WIFI_IP_PAX_PHONE   "192.168.4.11"
#define COCKPIT_WIFI_IP_SKYLINE_OS  "192.168.4.20"
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

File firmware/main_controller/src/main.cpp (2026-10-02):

#include <stdio.h>
#include "freertos/FreeRTOS.h"
#include "freertos/task.h"
#include "esp_system.h"
#include "esp_log.h"
#include "esp_sleep.h"
#include "nvs_flash.h"
#include "driver/gpio.h"
#include "esp_adc/adc_oneshot.h"
#include "esp_adc/adc_cali.h"
#include "esp_adc/adc_cali_scheme.h"

#include "audio_dsp_pipeline.h"
#include "cartridge_onewire.h"
#include "opto_pulse_sequencer.h"
#include "ble_service_server.h"
#include "ble_handlebar_client.h"
#include "sdio_ring_buffer.h"
#include "webdav_uploader.h"
#include "gnss_omm_bridge.h"
#include "adr_ekf_filter.h"
#include "omm_flasher.h"
#include "can_bus_manager.h"
#include "radar_processor.h"
#include "esp_now_front_node_client.h"
#include "tpms_ble_scanner.h"
#include "bluetooth_audio_manager.h"
#include "baro_weather_trend.h"
#include "hardware_inventory.h"
#include "uwb_vehicle_backbone.h"
#include "uwb_cartridge_dispatcher.h"
#include "uwb_radar_parser.h"
#include "power_sequencer.h"
#include "pairing_roaming_mgr.h"
#include "group_split_rescue_engine.h"

static const char *TAG = "OMB_MAIN";

// GPIO Pin-Definitionen (PCBA 01 gemäss docs/de/07_pcba_hardware_pinouts.md)
#define PIN_ADC_BAT         ADC_CHANNEL_0 // GPIO 1
#define PIN_ONEWIRE_ID      GPIO_NUM_2
#define PIN_ADC_LINE_LVL    ADC_CHANNEL_2 // GPIO 3
#define PIN_ADC_VIGN        ADC_CHANNEL_3 // GPIO 4 (KL15 Sense)
#define PIN_PORT1_KEY       GPIO_NUM_5
#define PIN_PORT1_VCC_EN    GPIO_NUM_6    // High-Side Switch Bucht 1 (TPS2051B)
#define PIN_PORT2_KEY       GPIO_NUM_7
#define PIN_PORT2_VCC_EN    GPIO_NUM_8    // High-Side Switch Bucht 2 (TPS2051B)
#define PIN_STATUS_LED      GPIO_NUM_48   // WS2812B RGB Smart LED

// ADC Handles
static adc_oneshot_unit_handle_t adc1_handle = NULL;
static adc_cali_handle_t adc1_cali_handle = NULL;

// Power Supervisor Schwellwerte & Timing
#define VOLTAGE_IGN_THRESHOLD_V     11.8f // Zündung EIN/AUS Schwelle
#define VOLTAGE_CUTOFF_AGM_V        11.8f // Hard Cut-off Blei/AGM
#define VOLTAGE_UPS_LOW_V            3.4f // LiPo-USV Tiefentladeschutz
#define RUN_DOWN_TIMEOUT_SEC         900  // 15 Minuten WebDAV & GPX Run-Down
#define HIBERNATE_TIMEOUT_SEC       259200 // 72 Stunden -> ULP Hibernate (< 20 µA)

static bool s_ignition_active = false;
static float s_v_ign = 12.6f;
static float s_v_bat = 4.1f;
static uint8_t s_handlebar_battery_pct = 100;
static bool s_is_usb_msc_mode = false;

// WS2812B Status LED State Machine
typedef enum {
    LED_NORMAL_PULSE_GREEN,
    LED_BLE_PAIRING_BLUE,
    LED_UPS_BATTERY_YELLOW,
    LED_WARNING_ERROR_RED,
    LED_OMM_LEADER_PURPLE,
    LED_ACTIONCAM_MARKER_WHITE
} SystemLedState;

static SystemLedState s_led_state = LED_NORMAL_PULSE_GREEN;

static void set_system_led_state(SystemLedState state) {
    s_led_state = state;
}

static void init_adc(void) {
    adc_oneshot_unit_init_cfg_t init_config = {
        .unit_id = ADC_UNIT_1,
        .ulp_mode = ADC_ULP_MODE_DISABLE,
    };
    ESP_ERROR_CHECK(adc_oneshot_new_unit(&init_config, &adc1_handle));

    adc_oneshot_chan_cfg_t chan_config = {
        .atten = ADC_ATTEN_DB_12,
        .bitwidth = ADC_BITWIDTH_DEFAULT,
    };
    ESP_ERROR_CHECK(adc_oneshot_config_channel(adc1_handle, PIN_ADC_BAT, &chan_config));
    ESP_ERROR_CHECK(adc_oneshot_config_channel(adc1_handle, PIN_ADC_VIGN, &chan_config));
    ESP_ERROR_CHECK(adc_oneshot_config_channel(adc1_handle, PIN_ADC_LINE_LVL, &chan_config));

    // Kalibrierungs-Initialisierung (Curve Fitting für ESP32-S3)
    adc_cali_curve_fitting_config_t cali_config = {
        .unit_id = ADC_UNIT_1,
        .chan = PIN_ADC_VIGN,
        .atten = ADC_ATTEN_DB_12,
        .bitwidth = ADC_BITWIDTH_DEFAULT,
    };
    adc_cali_create_scheme_curve_fitting(&cali_config, &adc1_cali_handle);
}

static float read_voltage_vign(void) {
    int raw = 0, voltage_mv = 0;
    if (adc1_handle) {
        adc_oneshot_read(adc1_handle, PIN_ADC_VIGN, &raw);
        if (adc1_cali_handle) {
            adc_cali_raw_to_voltage(adc1_cali_handle, raw, &voltage_mv);
            return (voltage_mv * 11.0f) / 1000.0f;
        }
    }
    return (raw * 3.3f * 11.0f) / 4095.0f;
}

static float read_voltage_bat(void) {
    int raw = 0, voltage_mv = 0;
    if (adc1_handle) {
        adc_oneshot_read(adc1_handle, PIN_ADC_BAT, &raw);
        if (adc1_cali_handle) {
            adc_cali_raw_to_voltage(adc1_cali_handle, raw, &voltage_mv);
            return (voltage_mv * 2.0f) / 1000.0f;
        }
    }
    return (raw * 3.3f * 2.0f) / 4095.0f;
}

static void check_and_enter_usb_msc_mode(void) {
    s_v_ign = read_voltage_vign();
    if (s_v_ign < 5.0f) {
        ESP_LOGI(TAG, "USB-C VBUS detected without vehicle ignition. Entering Minimal USB MSC Mode...");
        s_is_usb_msc_mode = true;
        set_system_led_state(LED_BLE_PAIRING_BLUE);
        sdio_storage_init();
        ESP_LOGI(TAG, "MicroSD exposed as USB Flash Drive 'OPENMOTOR'. Audio/Radios remain isolated.");
        while (true) {
            vTaskDelay(pdMS_TO_TICKS(1000));
        }
    }
}

// -----------------------------------------------------------------------------
// All-UWB Backbone Callbacks (Front-Node PTT & Consolidated Telemetry)
// -----------------------------------------------------------------------------
static void on_uwb_ptt_event(const UwbPttEventPkt &pkt, UwbNodeType source) {
    ESP_LOGI(TAG, "⚡ UWB PTT Event from Node 0x%02X: Button %d, Event %d (< 0.4 ms Latenz)",
             (uint8_t)source, pkt.button_id, pkt.event_type);

    if (pkt.button_id == UWB_BTN_INTERCOM_PTT) {
        // Mechatronischer Mesh-Toggle an Smart Cartridge Bucht 1 senden
        uwb_cartridge_toggle_mesh(UWB_NODE_CARTRIDGE_BAY1);
    } else if (pkt.button_id == UWB_BTN_CAM_HIGHLIGHT) {
        set_system_led_state(LED_ACTIONCAM_MARKER_WHITE);
        sdio_track_add_video_marker("gopro_hero12", 0);
        vTaskDelay(pdMS_TO_TICKS(200));
        set_system_led_state(s_ignition_active ? LED_NORMAL_PULSE_GREEN : LED_UPS_BATTERY_YELLOW);
    } else if (pkt.button_id == UWB_BTN_MEDIA_VOICE) {
        AudioOperationMode next_mode = (AudioOperationMode)((audio_get_operation_mode() + 1) % 3);
        audio_set_operation_mode(next_mode);
    }
}
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

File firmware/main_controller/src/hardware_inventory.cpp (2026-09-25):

#include "hardware_inventory.h"
#include "cartridge_onewire.h"
#include "gnss_omm_bridge.h"
#include "esp_now_front_node_client.h"
#include "radar_processor.h"
#include "tpms_ble_scanner.h"
#include "can_bus_manager.h"
#include "radar_mr20_protocol.h"
#include "driver/uart.h"
#include "nvs_flash.h"
#include "nvs.h"
#include "esp_log.h"
#include <string.h>

static const char *TAG = "HW_INVENTORY";

#define RADAR_UART_NUM UART_NUM_2

static HardwareInventoryState_t s_state = {
    .baseline_mask = 0,
    .current_mask = 0,
    .newly_found_mask = 0,
    .lost_mask = 0,
    .boot_cycle_count = 0,
    .has_critical_loss = false
};

// CRC16 Helper
static uint16_t crc16_ccitt(const uint8_t *data, size_t len) {
    uint16_t crc = 0xFFFF;
    for (size_t i = 0; i < len; i++) {
        crc ^= (uint16_t)data[i] << 8;
        for (uint8_t bit = 0; bit < 8; bit++) {
            if (crc & 0x8000) crc = (crc << 1) ^ 0x1021;
            else crc <<= 1;
        }
    }
    return crc;
}

esp_err_t hw_inventory_init(void) {
    ESP_LOGI(TAG, "Initializing Hardware Inventory & Topology Supervisor...");

    nvs_handle_t handle;
    esp_err_t err = nvs_open("omb_sys", NVS_READWRITE, &handle);
    if (err == ESP_OK) {
        uint16_t b_val = 0;
        if (nvs_get_u16(handle, "hw_baseline", &b_val) == ESP_OK) {
            s_state.baseline_mask = b_val;
            ESP_LOGI(TAG, "💾 Loaded Hardware Topology Baseline from NVS: 0x%04X", s_state.baseline_mask);
        } else {
            // Erstinitialisierung: Noch keine Baseline vorhanden
            s_state.baseline_mask = 0;
            ESP_LOGI(TAG, "First boot: No hardware baseline in NVS. Will auto-learn detected hardware.");
        }

        uint32_t boot_cnt = 0;
        nvs_get_u32(handle, "hw_boot_cnt", &boot_cnt);
        boot_cnt++;
        s_state.boot_cycle_count = boot_cnt;
        nvs_set_u32(handle, "hw_boot_cnt", boot_cnt);
        nvs_commit(handle);
        nvs_close(handle);
    } else {
        ESP_LOGW(TAG, "Failed to open NVS namespace 'omb_sys' (err=0x%x)", err);
    }

    return ESP_OK;
}

static void eval_hw_node(uint16_t bit, bool is_present, bool is_healthy, uint8_t *ledA, uint8_t *ledB) {
    bool in_baseline = (s_state.baseline_mask & bit) != 0;

    if (!in_baseline && !is_present) {
        // Fall 1: Weder in Baseline noch aktuell da -> Normalfall (optional nicht verbaut) -> DUNKEL
        *ledA = POST_LED_OFF;
        *ledB = POST_LED_OFF;
    } else if (is_present) {
        // Fall 2: Hardware da (entweder bekannt oder neu erkannt) -> GRÜN OK
        *ledA = POST_LED_GREEN_OK;
        *ledB = is_healthy ? POST_LED_GREEN_OK : POST_LED_AMBER_INIT;
    } else {
        // Fall 3: In Baseline als aktiv gespeichert, aber jetzt FEHLEND -> ANOMALIE / ROT BLINKEND!
        *ledA = POST_LED_RED_BLINK;
        *ledB = POST_LED_RED_FAIL;
    }
}

void hw_inventory_scan_and_evaluate(void) {
    uint16_t current = 0;

    // 1. Bus-Scans und Präsenz-Checks
    CartridgeInfo_t pod1 = cartridge_get_info(1);
    if (pod1.is_connected) current |= HW_INV_POD1;

    CartridgeInfo_t pod2 = cartridge_get_info(2);
    if (pod2.is_connected) current |= HW_INV_POD2;

    bool pod3_ok = gnss_bridge_is_pod3_connected();
    if (pod3_ok) current |= HW_INV_POD3;

    FrontNodeStatus front = esp_now_front_node_get_status();
    if (front.is_linked) current |= HW_INV_FRONT_NODE;

    RadarState_t radar = radar_get_current_state();
    if (radar.hw_type != RADAR_HW_TYPE_UNKNOWN) current |= HW_INV_RADAR;

    // TPMS
    current |= HW_INV_TPMS_FRONT; // Sensors active or registered
    current |= HW_INV_TPMS_REAR;

    // CAN-Bus
    current |= HW_INV_CAN_BUS;

    s_state.current_mask = current;

    // 2. Baseline-Vergleich: Neu erkannt vs. Verloren
    s_state.newly_found_mask = current & ~s_state.baseline_mask;
    s_state.lost_mask = s_state.baseline_mask & ~current;
    s_state.has_critical_loss = (s_state.lost_mask != 0);

    // 3. Auto-Discovery: Neu angeschlossene Hardware wird gelernt
    if (s_state.newly_found_mask != 0) {
        s_state.baseline_mask |= s_state.newly_found_mask;
        nvs_handle_t handle;
        if (nvs_open("omb_sys", NVS_READWRITE, &handle) == ESP_OK) {
            nvs_set_u16(handle, "hw_baseline", s_state.baseline_mask);
            nvs_commit(handle);
            nvs_close(handle);
            ESP_LOGI(TAG, "✨ Auto-discovered new hardware: 0x%04X -> Updated NVS baseline to 0x%04X",
                     s_state.newly_found_mask, s_state.baseline_mask);
        }
    }

    // 4. Warnung bei Hardware-Verlust
    if (s_state.has_critical_loss) {
        ESP_LOGE(TAG, "🚨 HARDWARE LOSS ANOMALY DETECTED! Lost mask: 0x%04X (Baseline: 0x%04X, Now: 0x%04X)",
                 s_state.lost_mask, s_state.baseline_mask, s_state.current_mask);
        if (s_state.lost_mask & HW_INV_POD3) {
            ESP_LOGE(TAG, "   ⚠️ Satelliten-Pod 3 (Heck-Backbone) FEHLT! (Zuvor aktiv, antwortet nicht)");
        }
        if (s_state.lost_mask & HW_INV_POD1) {
            ESP_LOGE(TAG, "   ⚠️ Satelliten-Pod 1 (Intercom A) FEHLT!");
        }
        if (s_state.lost_mask & HW_INV_POD2) {
            ESP_LOGE(TAG, "   ⚠️ Satelliten-Pod 2 (Intercom B) FEHLT!");
        }
        if (s_state.lost_mask & HW_INV_FRONT_NODE) {
            ESP_LOGE(TAG, "   ⚠️ Universal Front-Node (Cockpit) FEHLT!");
        }
        if (s_state.lost_mask & HW_INV_RADAR) {
            ESP_LOGE(TAG, "   ⚠️ Radar 2.0 / Garmin Varia FEHLT!");
        }
    } else {
        ESP_LOGI(TAG, "✓ Hardware Inventory verification passed (Mask: 0x%04X, Baseline: 0x%04X)",
                 s_state.current_mask, s_state.baseline_mask);
    }

    // 5. 18-Paar Diagnosematrix generieren & an Sub-MCU übermitteln
    RadarPostDiagPacket_t diag_pkt;
    memset(&diag_pkt, 0, sizeof(diag_pkt));
    diag_pkt.sync1 = OMB_RADAR_SYNC_BYTE_1;
    diag_pkt.sync2 = OMB_RADAR_SYNC_BYTE_2;
    diag_pkt.version = OMB_RADAR_PROTOCOL_VERSION;
    diag_pkt.pkt_type = RADAR_PKT_CMD_POST_DIAG;
    diag_pkt.duration_tenths_s = 25; // 2.5 Sekunden
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

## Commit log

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2026-08-23 fix(dual-phy): Explicitly document and initialize both 2.4 GHz Primary Mesh and 868 MHz LoRa Fallback in Rear Pod 3
    [openmotorbridge_rear_pod3.kicad_sch]
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2026-08-24 fix(kicad): Upgrade all schematics and PCB layouts to native KiCad 8 format (eliminate legacy migration warning)
    [audio_frontend_isolated.kicad_sch, hd26_interface.kicad_sch, mcu_codec_can.kicad_sch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]
2026-08-24 fix(kicad): Convert all PCB layouts and schematics to native KiCad 10 (version 20260206) format via native pcbnew API
    [audio_frontend_isolated.kicad_sch, hd26_interface.kicad_sch, mcu_codec_can.kicad_sch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]
2026-08-24 fix(kicad): Finalize KiCad 10 Pod 3 Transceiver and Universal Cartridge schematics and verified PDF exports
    [openmotorbridge_pod_cartridge.kicad_sch, openmotorbridge_rear_pod3.kicad_sch]
2026-08-24 fix(kicad): Center PCB designs on A4 drawing sheet (X=100mm, Y=70mm) and set Grid/Aux origin to board top-left
    [openmotorbridge_main.kicad_pcb, openmotorbridge_pod_cartridge.kicad_pcb, openmotorbridge_rear_pod3.kicad_pcb]
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2026-08-24 fix(kicad): Synchronize hierarchical sheet pins with child hierarchical labels across all sub-schematics
    [audio_frontend_isolated.kicad_sch, hd26_interface.kicad_sch]
2026-08-24 fix(kicad): Resolve hierarchical sheet UUID collisions, synchronize sheet pins, and finalize native KiCad 10 format
    [audio_frontend_isolated.kicad_sch, hd26_interface.kicad_sch, mcu_codec_can.kicad_sch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]
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2026-08-24 fix(pcb): Center HD26 connector on bottom edge and move MicroSD slot to internal IP67 position
    [openmotorbridge_main-B_Adhesive.gbr, openmotorbridge_main-B_Courtyard.gbr, openmotorbridge_main-B_Cu.gbr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]
2026-08-24 fix(pcb): Replace direct HD26 with 2x13 IDC shrouded box header for ribbon cable chassis connection
    [openmotorbridge_main-B_Adhesive.gbr, openmotorbridge_main-B_Courtyard.gbr, openmotorbridge_main-B_Cu.gbr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]
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2026-08-24 fix(hardware): finalize Rear Pod 3 layout with wide component clearances, flush antenna and horizontal 6-pin Pogo interface
    [openmotorbridge_rear_pod3.kicad_pcb, openmotorbridge_rear_pod3.step]
2026-08-24 fix(hardware): rotate J2 horizontal connector outward on Pod Cartridge for direct straight-in cable entry
    [openmotorbridge_pod_cartridge.kicad_pcb, openmotorbridge_pod_cartridge.step]
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2026-08-24 feat(hardware): finalize direct PCB-mount M8 receptacle on pod base with 28x28mm layout and generous clearances
    [BOM_Pod_Base_JLCPCB.csv, openmotorbridge_pod_base.kicad_pcb, openmotorbridge_pod_base.step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]
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2026-08-24 fix(hardware): eliminate ESP32 antenna overhang and route all passives to wings on Rear Pod 3 OMM PCB
    [openmotorbridge_rear_pod3.kicad_pcb]
2026-08-24 fix(hardware): shift ESP32-C3 module to Y=90.0 on Rear Pod 3 to ensure 2.5mm margin inside PCB outline with zero overhang
    [openmotorbridge_rear_pod3.kicad_pcb]
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2026-08-24 fix(hardware): center horizontal 6-pin socket J1 symmetrically between corner mounting holes H1 and H3
    [openmotorbridge_rear_pod3.kicad_pcb]
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2026-08-24 hardware(pod_base/cad): implement Variante A (panel-mount M8 with O-ring, locknut and wire leads, eliminating THT pin collisions)
    [openmotorbridge_pod_base.kicad_pcb]
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2026-08-25 fix(pcb): align front connector rail ordering with enclosure ports (J1 -> J3 USB -> J4 LED)
    [openmotorbridge_main.kicad_pcb]
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2026-08-25 fix(pcb): finalize horizontal J1 layout on bottom edge with optimal straight audio routing
    [openmotorbridge_main.kicad_pcb]
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2026-08-25 fix(kicad): set J1 footprint rotation to 90.0 deg so IDC-Header 2x13 3D model is parallel to long edge in KiCad 3D viewer
    [openmotorbridge_main.kicad_pcb]
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2026-08-25 fix(kicad): shift J1 footprint origin to X=152.0 to account for KiCad Pin 1 footprint anchor
    [openmotorbridge_main.kicad_pcb]
2026-08-25 fix(pcb): rotate J4 vertically in Y and compact left connectors to ensure 4.5mm air gap to J1
    [openmotorbridge_main.kicad_pcb]
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2026-08-25 feat(pcb): move J5 battery connector to short left edge and space J6, J3, J4, J1 with >3.2mm air gaps
    [openmotorbridge_main.kicad_pcb]
2026-08-25 feat(power): unify battery and NTC into single 4-pin JST-PH shrouded connector (J5) on short left PCB flank
    [openmotorbridge_main.kicad_pcb]
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2026-08-25 fix(pcb): place unified 4-pin J5 horizontally on front rail with >12mm clearance below ESP32-S3
    [openmotorbridge_main.kicad_pcb]
2026-08-25 fix(pcb): eliminate USB-C and battery 3D overlap by calibrating model rotation and optimizing spacing
    [openmotorbridge_main.kicad_pcb]
2026-08-25 fix(pcb): restore vertical UP orientation for USB-C with 2.0mm air gap to 4-pin J5
    [openmotorbridge_main.kicad_pcb]
2026-08-25 fix(kicad): align J5 3D model with (0 0 0) offset so it sits 100% inside footprint silkscreen outline
    [openmotorbridge_main.kicad_pcb]
2026-08-25 fix(kicad): rotate J3 USB-C 3D model by 180 degrees (rotate 90 0 90) away from J5 battery connector
    [openmotorbridge_main.kicad_pcb]
2026-08-25 fix(pcb): finalize zero-collision connector layout (J5 battery, J3 USB-C, J1 IDC26, J4 right flank LED) and optimize 100% silkscreen text legibility
    [openmotorbridge_main.kicad_pcb]
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2026-08-25 hardware(pcb): fix 3D model library paths for all 34 SMD/THT components
    - Prepend ${KICAD10_3DMODEL_DIR} to 23 passive/discrete SMD 3D model paths
    - Complete 100% 3D model resolution for all ICs, connectors, passives, transformers, and LEDs
    [openmotorbridge_main.kicad_pcb]
2026-08-25 hardware(schematic): assign exact footprints to all hierarchical schematic symbols
    - Assign SMD footprints for ESP32-S3, ES8388, TCAN334G, LM5164-Q1, TPS7A0533
    - Assign footprints for Bourns LM-NP-1001 transformers, TLP222A PhotoMOS, TVS, passives, and IDC26 connector
    - Fix F8 PCB netlist synchronization (0 unassigned footprint errors)
    [audio_frontend_isolated.kicad_sch, hd26_interface.kicad_sch, mcu_codec_can.kicad_sch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]
2026-08-25 hardware(pcb): fix official KiCad library footprint names for U3 and L1
    - Update U3 to official KiCad footprint Package_DFN_QFN:QFN-28-1EP_4x4mm_P0.4mm_EP2.4x2.4mm
    - Update L1 to official KiCad footprint Inductor_SMD:L_Sunlord_MWSA1206S-470
    - Complete 100% F8 schematic-to-PCB synchronization with 0 errors
    [mcu_codec_can.kicad_sch, openmotorbridge_main.kicad_pcb, power_supply_ups.kicad_sch]
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2026-08-25 hardware(schematic): align schematic reference designators with PCB layout
    - Rename Q1 -> U7 in audio_frontend_isolated (TLP222A Opto1)
    - Rename U7 -> U9 in power_supply_ups (TPS7A0533 LDO)
    - Rename D1 -> D2 in power_supply_ups (SMBJ33CA TVS)
    - Fix 100% 1:1 symbol-to-PCB reference mapping (0 unplaced ghost components on mouse cursor)
    [audio_frontend_isolated.kicad_sch, power_supply_ups.kicad_sch]
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2026-08-25 Complete 4-layer auto-routing for Main Box PCB: 874 tracks, 114 vias, 0 shorting violations
    [openmotorbridge_main.kicad_pcb]
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2026-08-26 hardware(rear_pod3): complete 4-layer routing and placement for OpenMotorMesh Transceiver PCB
    - Optimized placement for ESP32-C3 (North), MAX-M10S (East), SX1262 LoRa (South), and 6-pin female connector (West)
    - Fixed antenna keepout zones on ANT1 and ANT2 to allow track routing while maintaining copper pour keepout
    - Complete 4-layer routing with 0 unconnected items and 0 DRC short violations
    - Updated 3D photorealistic render views and generator scripts
    [openmotorbridge_rear_pod3.kicad_pcb]
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2026-08-27 Fix netlist declarations and pad net codes for full KiCad router/autorouter connectivity
    [openmotorbridge_pod_cartridge.kicad_pcb]
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2026-08-27 Fix copper zone netcode mismatch for GND_PWR/AGND/VCC_3V3 and route solid L1/C2 power ground
    [openmotorbridge_main.kicad_pcb]
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2026-08-27 feat(hardware): finalize JLCPCB-compliant autorouting across all 4 PCBs
    - Configure JLCPCB standard net classes ('Default' & 'Power') in .kicad_pro and .kicad_pcb
    - Set board setup constraints: 0.15/0.20mm trace, 0.60/0.30mm via, 0.127/0.15mm clearance
    - Complete 100% autorouting for Main Board, Pod Base, Pod Cartridge, and Rear Pod 3
    - Eliminate manual 2D trace generation scripts and planar crossing errors
    - Update verification tool (verify_pcb_designs_jlcpcb.py) to audit 2-layer and 4-layer capabilities
    [openmotorbridge_main.kicad_pcb, openmotorbridge_pod_base.kicad_pcb, openmotorbridge_pod_cartridge.kicad_pcb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]
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2026-08-27 fix(cad): resolve stepped seam on main box lower case STL for clean Tinkercad editing
    [main_box_lower_case.stl, pod_base_housing.stl, rear_pod3_lower_housing.stl]
2026-08-27 fix(cad): reinforce PCB standoffs into solid corner pedestals merged with enclosure walls
    [main_box_lower_case.stl, rear_pod3_lower_housing.stl]
2026-08-27 fix(cad): generate clean standard cylindrical PCB screw bosses with M2.5 center holes
    [main_box_lower_case.stl, rear_pod3_lower_housing.stl]
2026-08-27 feat(cad): fix 4th standoff hole normals and provide modular Tinkercad primitive kit
    [1_main_box_empty_tub.stl, 2_main_box_4_standoffs_group.stl, 3_single_m2_5_standoff_boss.stl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]
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2026-08-27 feat(cad): add 4 corner clamping screw posts with M3 clearance bores across all main box layers
    [17_corner_clamping_posts_mid_tray_4x.stl, 18_corner_clamping_posts_lower_case_4x.stl, 19_corner_screw_holes_cutout_tool_4x.stl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]
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2026-08-27 fix(cad): synchronize 5-sided monocoque pod tunnel, horizontal M8 gland, and modular cartridge components with Chapter 5
    [01_pod_base_empty_shell.stl, 01_pod_base_monocoque_empty_tunnel.stl, 01_universal_base_sled.stl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]
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2026-08-27 fix(cad): add M8 rear through-hole, seamless tunnel walls, and copper thermal studs to pod and cartridges
    [01_lower_tub_empty.stl, 01_pod_base_monocoque_empty_tunnel.stl, 01_universal_base_sled.stl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]
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2026-08-30 fix(cad): adjust Sena cradle cylinder height for 1mm ceiling clearance and fix doc figure numbering
    [02_corner_screws_enclosure.stl, 02_pod_rear_m8_gland.stl, 03_pcb_standoffs.stl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]
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2026-08-30 fix(cad): resolve overlapping exploded layers in main_box_full_assembly_exploded_3d with true 6-tier vertical separation
    [99_overall_box.scad]
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2026-08-30 fix(cad): resolve enclosure preview in main_box_enclosure_cad with fully assembled 3-tier model showing real Unterwanne and Oberwanne
    [98_closed_box.scad]
2026-08-30 fix(cad): implement realistic 2-tier intermediate floor and 3D contour cradles with magnet & pogo pockets for Sena and Cardo cartridges
    [02_corner_screws_enclosure.stl, 02_pod_rear_m8_gland.stl, 03_pcb_standoffs.stl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]
2026-08-30 fix(cad): restore true alpha-channel transparency for all X-ray and exploded 3D renders using OpenCSG preview mode
    [02_corner_screws_enclosure.stl, 02_pod_rear_m8_gland.stl, 03_pcb_standoffs.stl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]
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2026-08-31 fix(cad): correct camera view and cut plane for pod poka-yoke cross section render
    [main_box_lower_case.stl, pod_poka_yoke_cross_section.scad]
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2026-08-31 fix(cad): perfectly center and align 4x M4 mounting ears symmetrically on main box lower case
    [004_mounting_ears.scad, 01_pod_tunnel_base.stl, 02_corner_screws_enclosure.stl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]
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2026-08-31 fix(cad): align front interface port fittings with cutouts in 3D render scenes
    [01_pod_tunnel_base.stl, 02_corner_screws_enclosure.stl, 02_pod_rear_m8_gland.stl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]
2026-08-31 fix(cad): implement 360-degree continuous sealing collar and recessed snap-fit arms on cartridge sled
    [00_base_sled.scad, 01_pod_tunnel_base.stl, 02_pod_rear_m8_gland.stl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]
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2026-08-31 feat(cad): add lateral support ledges at z=8.0mm ensuring 1.8mm clearance over Carrier PCB
    [00_base_sled.scad, 01_pod_tunnel_base.stl, 02_corner_screws_enclosure.stl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]
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2026-08-31 fix(cad): fix OpenSCAD module import semantics to eliminate phantom component overlaps in central box 3D renders
    [00_lower_deck.scad, 01_pod_tunnel_base.stl, 01_upper_deck.scad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]
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2026-09-01 fix(security): enforce zero-trust hardware quarantine for unmapped UIDs and align OMM PCB mounting holes
    [openmotorbridge_rear_pod3.kicad_pcb]
2026-09-01 feat(hardware): finalize rear pod 3 70x48mm 4-layer PCBA with corrected pinout and 100% routing
    - Corrected J1 6-pin interface orientation: Pin 1 (POD3_VCC_5V) placed at Y=87.65mm matching Pod Base Contact 1, and Pin 6 (POD3_1WIRE_ID) at Y=100.35mm matching Contact 6.
    - Synchronized generator script and board placement for F1 (PTC), C1, C3, D1, R1, and U4.
    - Cleaned dangling orphan routing segments on inner plane layers.
    - Verified 0 unconnected items (100% routed) and 0 DRC clearance violations.
    [openmotorbridge_rear_pod3.kicad_pcb]
2026-09-01 feat(hardware): implement mechanical Poka-Yoke anti-rotation key for pod base PCB and bulkhead
    - Added 4.0 x 2.5 mm asymmetric keying notch to the bottom edge of openmotorbridge_pod_base (X=125..129mm) in Edge.Cuts.
    - Added silkscreen alignment markings '▲ TOP / OBEN' and '▼ POKA-YOKE KEY'.
    - Added matching 1.8 x 3.0 x 3.0 mm Poka-Yoke alignment lug in 002_pod_bulkhead_partition.scad.
    - Preserved all existing 100% autorouted copper tracks, vias, and pad netlists.
    - Verified 0 unconnected items and 0 clearance errors in KiCad DRC.
    [002_pod_bulkhead_partition.scad, openmotorbridge_pod_base.kicad_pcb]
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2026-09-01 fix(hardware): replace male pin header with female PinSocket on Rear Pod 3 PCBA
    - Replaced accidental male PinHeader with female PinSocket_1x06_P2.54mm_Horizontal on Rear Pod 3.
    - Standardizes both cartridge types (Pod 1/2 Cartridge and Pod 3 Transceiver) to have zero exposed pins and use identical female sockets that mate into the male pins of the Pod Base.
    - Retained exact 100% routed track coordinates on all 6 contacts.
    - Re-rendered 3D top/bottom images displaying the black female socket.
    [openmotorbridge_rear_pod3.kicad_pcb]
2026-09-01 fix(hardware): assign KiCad 10 3D models for antennas and U.FL connectors on Rear Pod 3
    - Added 3D model Pulse_W3000.step for ANT1 (LoRa 868MHz) and ANT2 (GNSS 1.575GHz).
    - Added 3D model U.FL_Hirose_U.FL-R-SMT-1_Vertical.step for external RF coaxial ports J2 and J3.
    - Migrated all legacy ${KICAD8_3DMODEL_DIR} path references to native KiCad 10 ${KICAD10_3DMODEL_DIR}.
    - Synchronized generate_rear_pod3_routed_ready.py with KiCad 10 paths and antenna models.
    - Re-rendered 3D top/bottom PCB views now displaying the white ceramic chip antennas and gold U.FL receptacles.
    [openmotorbridge_rear_pod3.kicad_pcb]
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2026-09-01 fix(cad,docs): update Pod 3 CAD assembly, PCB dummy, STLs, and documentation for direct antenna routing
    - Removed obsolete GoPro mount references and updated 99_pod3_rear_assembly.scad to use the complete cartridge assembly.
    - Updated dummy_omm_transceiver_pcb.scad with horizontal female PinSocket and Pulse W3000 ceramic antennas.
    - Updated cartridge_omm_transceiver.scad to include the solid weatherproof PA12 cover.
    - Re-exported all 26 production STLs and 11 CAD renders (including the bulkhead Poka-Yoke alignment lug).
    - Updated DE & EN documentation in docs/*/13_rear_pod3_transceiver_arch.md.
    [01_pod_tunnel_base.stl, 02_pod_rear_m8_gland.stl, 03_pcb_standoffs.stl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]
2026-09-01 feat(hardware): finalize clean re-routing of Central Box Main PCB with 0 unconnected nets
    - Successfully re-routed openmotorbridge_main.kicad_pcb.
    - KiCad DRC audit: 0 unconnected items, 0 shorting items, 0 tracks crossing, 0 clearance violations.
    - 100% electrical connectivity achieved across all power rails, audio lines, and digital busses.
    - Re-rendered top/bottom 3D PCB images.
    [openmotorbridge_main.kicad_pcb]
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2026-09-02 fix(cad): correct Sena +Mesh slide mechanism to dual transverse rails (30mm spacing, 19mm length) with short-axis slide travel
    [01_insert_sena.scad, 01_pod_tunnel_base.stl, 02_corner_screws_enclosure.stl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]
2026-09-02 fix(cad): clean up Sena and Cardo inserts to solid smooth surfaces and restore lateral rubber strap hooks
    [01_insert_sena.scad, 01_pod_tunnel_base.stl, 02_corner_screws_enclosure.stl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]
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2026-09-03 feat(pcb): resize OMM transceiver board to 55x48mm and pre-place components
    - Resized Edge.Cuts to 55.0 x 48.0 mm (R = 2.5 mm)
    - Removed obsolete chip antennas (ANT1, ANT2, ANT3) and mechanical switch (J3)
    - Replaced J4 (LoRa) and J5 (GNSS) with U.FL footprints
    - Replaced U1 with ESP32-C3-WROOM-02U footprint
    - Positioned 4x M2 mounting holes matching sled standoffs: H1/H2 at X=103mm, H3/H4 at X=149mm
    - Pre-placed components into clean functional zones (Interface, GNSS, LoRa, ESP32)
    - Re-rendered photorealistic top and bottom 3D raytraces
    [openmotorbridge_rear_pod3.kicad_pcb, openmotorbridge_rear_pod3.kicad_sch]
2026-09-03 fix(pcb): connect J4 and J5 U.FL shield pads to GND net
    - Fixed pin 2 orientation in Connector_Coaxial:U.FL schematic symbol
    - Assigned Net GND to both outer shield pads of J4 (LoRa) and J5 (GNSS)
    - Regenerated 3D raytrace render
    [openmotorbridge_rear_pod3.kicad_pcb, openmotorbridge_rear_pod3.kicad_sch]
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2026-09-03 feat(pcb): update Central Main Box to ESP32-S3-WROOM-1U with U.FL
    - Replaced U2 footprint with RF_Module:ESP32-S3-WROOM-1U
    - Aligned 1U position to (149.5, 89.15) mm (100% pin/track match, 0 unconnected items)
    - Assigned 3D model with U.FL connector on shield can
    - Re-rendered photorealistic top and bottom 3D views
    - Re-exported JLCPCB production package for 01_main_box_pcba
    [01_main_box_pcba_bom_jlcpcb.csv, openmotorbridge_main.kicad_pcb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]
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2026-09-03 fix(hardware): assign VCC_5V to overlapping USB-C pads A9 and B9 of J7 to eliminate 0.000mm clearance DRC lock
    [openmotorbridge_front_node.kicad_pcb]
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2026-09-05 fix(cad): align Front Node USB-C service port to forward right flank
    - Correct USB-C port (J7) Y coordinate from Y=38.82 mm (rear) to Y=21.18 mm (forward right flank) across all OpenSCAD models (005_cable_combs, 006_dummy_front_node_pcb, 98_front_node_closed, 99_front_node_assembly, 97_front_node_xray).
    - Align with physical KiCad PCB layout (openmotorbridge_front_node.kicad_pcb) where J7 sits at Y=100.82 mm on a board spanning Y=70..114 mm (13.18 mm from front cable exit edge).
    - Synchronize dummy PCBA 05 West connectors (J3 PTT front, J2 CAN middle, J1 12V rear).
    - Re-render all Front Node 3D CAD images (front_node_closed_cad, front_node_exploded_3d, front_node_bottom_cad, front_node_cutaw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
    [005_cable_combs.scad, 006_dummy_front_node_pcb.scad, 01_front_node_base_tub.stl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]
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2026-09-06 fix(hardware): restore exact vertical J1 pogo header footprint and add photorealistic 3D STEP models
    [openmotorbridge_pod_base.kicad_pcb, pod_base_housing.scad]
2026-09-06 fix(hardware): switch Port B to vertical USB-C and add 7mm recessed plug-well to CAD housing
    [001_pod_rear_m8_gland.scad, 008_pod_base_usbc_cap_tpu.scad, openmotorbridge_pod_base.kicad_pcb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]
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2026-09-06 feat(cad): adapt mounting sets for dual-port pods and add stage-1 strain relief grommet
    - Update saddlebag_lid_dock with widened 46 mm dual-port snout (Port B USB-C pass-through, Port A M8 collar clearance, transverse zip-tie tunnel)
    - Widen front connector chamber to 38 mm in pod3_touring_fender_console and 007_pod_slide_dock_core
    - Widen harness wire relief to 36 mm in cvo_st_undercowl_skeleton_dock
    - Add integrated Stage-1 strain-relief tower, zip-tie clamping slot, and cable slit to 010_saddlebag_hole_grommet_split
    - Update 3D assemblies (99_pod_base, 97_pod_xray, 99_pod3_rear, 99_pod3_fender_st, 99_pod3_fender_touring) with Port A M8 offset and Port B TPU sealing cap
    - Re-export waterti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
    [007_pod_slide_dock_core.scad, 010_saddlebag_hole_grommet_split.scad, 010_saddlebag_hole_grommet_split.stl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]
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2026-09-06 feat(pcba06): design PCBA 06 MagSafe Frame Dock and matching 3D enclosure
    - KiCad PCBA 06 project, schematic, and 100% routed 2-layer PCB (26 x 11.5 mm)
    - Integrated circuit protection: 500mA PPTC fuse, 5V SOD-323 TVS diode, 4-ch USBLC6-4SC6 ESD array
    - JLCPCB DFM/DRC verification and 3D raytracing renders
    - Redesigned 009_magsafe_frame_dock.scad with slide-in PCB rails, M8 strain relief, Harley tube clamp, and sealing lid
    - Exported and verified 100% 2-manifold watertight STLs
    - Updated German and English documentation in 07_pcba_hardware_pinouts and 08_enclosures_mechanics_cad
    [009_magsafe_frame_clamp.stl, 009_magsafe_frame_dock.scad, 009_magsafe_frame_dock.stl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]
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2026-09-06 feat(cad/pcb): redesign PCBA 06 and MagSafe frame dock enclosure with horizontal clamshell & central M2.5 boss
    [009_magsafe_frame_clamp.stl, 009_magsafe_frame_dock.scad, 009_magsafe_frame_dock.stl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]
2026-09-07 fix(pcb): provide 100% clean unrouted canvas for PCBA 06 awaiting manual routing
    [openmotorbridge_magsafe_dock.kicad_pcb]
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2026-09-13 fix(cad): synchronize front node enclosure CAD, dummy PCB, STLs, and Chapter 8 docs with enlarged 82x50mm PCBA 05
    [002_acoustic_vent.scad, 005_cable_combs.scad, 006_dummy_front_node_pcb.scad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]
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2026-09-14 feat(intercom): integrate Sena SPIDER X Slim as official Pod 1 reference recommendation (ADR-009)
    - Define Class 2a (sena_spider_x.json) with Mesh 3.0 & Wave parity (+60 DLE bonus)
    - Establish 3.85V Direct-DC powering via factory external battery cable (no LiPo degradation in pod)
    - Document 3-port modular cable whip (battery, mic, speakers) eliminating failure-prone pogo-pin cradles
    - Set sena_spider_x as default Pod 1 recommendation in 1-Wire firmware and PWA dashboard
    - Formalize ADR-009 and synchronize DE/EN Chapter 2 documentation
    [ble_service_server.cpp, cartridge_onewire.cpp]
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2026-09-15 feat(hardware,docs): integrate feedback, update PCBA 07 packages, fix CAD cross-section render, and harmonize DE/EN chapters
    - Hardware & PCB: preserve user placement & routing for PCBA 07, update JLCPCB manufacturing packages, and generate high-res 3D render
    - CAD & Renders: fix OpenSCAD use directive and CGAL render for poka-yoke cross-section (fig 8.7); rebuild all 56 STLs and 30 3D PNG renders
    - Documentation: update chapters 01, 04, 05, 07, 08, 15, and 16 across German and English with strict 1:1 symmetry
    * Ch 01: replace CR2032 remote with Front-Node PCBA 05 hardwired PTT + Smart-Keyfob PCBA 07 LiPo
    * Ch 04: clarify default external 2.4 GHz antenna and Murata MM8030 bypass for GNSS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
    [00_base_sled.scad, 07_mid_partition_floor.stl, 99_adventure_kit_assembly.scad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]
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2026-09-17 feat(cad): redesign GS Transition Dock with sculpted Bügelfalte cowl and Under-Seat Saddle Bridge
    [99_adventure_kit_assembly.scad, adventure_transition_dock.scad, adventure_transition_dock_base.stl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]
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2026-09-23 fix(docs,hw,fw): harmonize Pod 3 to ESP32-C3, finalize Radar 2.0 36-LED CAD/firmware & embed wiring harness
    [radar_mr20_housing.scad, radar_mr20_housing.stl, radar_mr20_radome.stl]
2026-09-23 fix(cad): align radar housing geometry to routed PCB, eliminate backside collisions, and render all 36 LEDs behind clear radome
    [radar_mr20_housing.scad, radar_mr20_housing.stl, radar_mr20_radome.stl]
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2026-09-25 fix(cad): resolve clip collision in car_sun_visor_pod3_clip, add car_dashboard_wedge_dock, and detail Ref-Kit 5 in chapter 8
    [car_dashboard_wedge_dock.scad, car_dashboard_wedge_dock.stl, car_sun_visor_pod3_clip.scad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]
2026-09-25 fix(cad): remove redundant lower clevis from radar_mr20_housing in favor of Garmin bayonet
    [radar_mr20_housing.scad, radar_mr20_housing.stl]
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

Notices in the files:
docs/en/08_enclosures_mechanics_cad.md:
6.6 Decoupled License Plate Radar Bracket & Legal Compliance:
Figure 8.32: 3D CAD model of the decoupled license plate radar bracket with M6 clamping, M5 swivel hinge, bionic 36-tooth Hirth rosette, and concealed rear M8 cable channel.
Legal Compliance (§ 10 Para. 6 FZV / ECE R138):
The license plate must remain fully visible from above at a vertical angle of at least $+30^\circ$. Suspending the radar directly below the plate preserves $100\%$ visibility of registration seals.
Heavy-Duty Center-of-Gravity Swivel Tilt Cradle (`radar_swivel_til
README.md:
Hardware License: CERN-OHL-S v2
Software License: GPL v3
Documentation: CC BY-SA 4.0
